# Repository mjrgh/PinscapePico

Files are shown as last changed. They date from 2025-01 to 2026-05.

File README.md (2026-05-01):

# 

Pinscape Pico is a comprehensive I/O controller for virtual pinball
cabinets, designed for the Raspberry Pi Pico RP2040.  It handles
nearly all of the common input and output functions in a virtual pin
cab: arcade-style pushbuttons and switches, accelerometer-based
nudging, mechanical plunger position sensing, and feedback effect
devices such as lights, shaker motors, fans, and solenoids.  It can be
used on a standalone Pico, and also with a wide range of peripheral
devices that expand the Pico's hardware capabilities: accelerometers,
PWM/LED driver chips, shift registers, GPIO expanders, ADCs, and
clock/calendar chips.  The project includes reference hardware designs for
several expansion boards that implement particular collections of
peripherals selected to meet the needs of most pin cab builders, and
all of the hardware interfaces are documented, so that you can design
your own custom boards if you prefer.

This project is a sequel to the original [Pinscape KL25Z controller](https://github.com/mjrgh/Pinscape_Controller),
but it's all new code, not a port of the KL25Z software.  The Pico is
a more powerful platform than the KL25Z, so I wanted to make a fresh
start to take advantage of the Pico's expanded capabilities.  Pinscape
Pico has all (I'm pretty sure) of the features of the original KL25Z
Pinscape, plus some neat new tricks.  It's a little more "technical"
than the KL25Z system, but also more powerful and flexible.

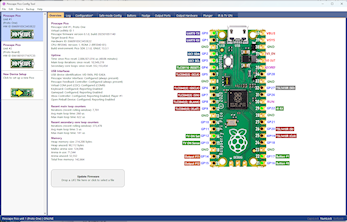
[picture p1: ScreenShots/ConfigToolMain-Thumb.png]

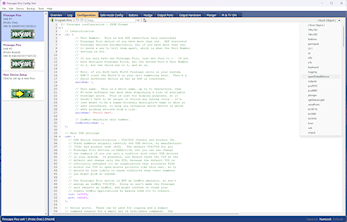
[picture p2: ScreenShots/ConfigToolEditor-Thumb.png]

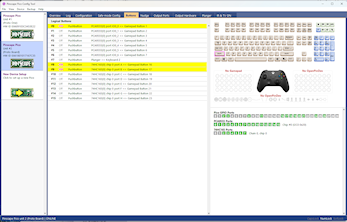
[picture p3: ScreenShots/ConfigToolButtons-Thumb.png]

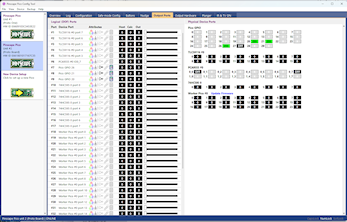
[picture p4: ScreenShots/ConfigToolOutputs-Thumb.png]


## What can you do with it?

Here are some examples of how you can set up a Pinscape Pico system.
There's a more comprehensive list of features a little later in this
article, but it might help to start with some more concrete examples
of what your overall system might look like.

* <b>Button controller:</b> A really simple way to use Pinscape is as
a button encoder, for connecting arcade pushbuttons to a PC.  The
Pico is the only piece of hardware you need for this (other than
the buttons), since you can connect the buttons directly to the Pico's
GPIO ports.  The Pico has a total of 26 external GPIO pins, so you can
connect up to 26 buttons.  Each button can be mapped to the PC as a
keyboard key, a gamepad button, or a variety of other options, and
the Pico responds to button presses within microseconds, for very small
latencies sending input to the PC.  (Pinscape can also handle many
more buttons than just 26 if you need more, but that gets a little
more complicated, because you have to add some external peripheral
chips to create more ports beyond the Pico's 26 built-in GPIO pins.)

* <b>Accelerometer-based nudge device:</b> A slightly more complex
setup adds an accelerometer, to detect when you nudge the cabinet, so
that the pinball simulator can apply the nudge force within the game.
Analog nudging adds a wonderful extra dimension to video pinball that
lets you interact with the game in a much more natural, physical way.
The Pico doesn't have a built-in accelerometer, so this setup
requires adding an external accelerometer.  But that's very easy
to do, thanks to breakout boards available from Adafruit, Sparkfun,
and others.  (A breakout board is a small circuit board with a
specific chip and all of the necessary supporting parts, fully
soldered and assembled, so all you need to do to connect it to a
Pico is run a few wires between the breakout board and the Pico
GPIO pins.)  I recommend the Adafruit MMA8451Q and LIS3DH boards
(MMA8451Q is the better choice in terms of sensor performance).
You can combine nudge input with button inputs, too, although this
will reduce the number of button ports to 24 (because the
accelerometer requires two GPIO ports for its own use).

* <b>Plunger:</b> You can also add a mechanical plunger position
sensor.  Apart from the plunger sensor itself, no other hardware
is needed.  The simplest plunger sensor type is a slide potentiometer,
which connects to the Pico with three wires.  You can combine this
with the accelerometer and button functions as well.

* <b>Feedback device controller:</b> Pinscape can act as a replacement
for the LedWiz and its competitors - devices that control a fixed set
of feedback devices, and do nothing else.  Pinscape can even emulate
the original LedWiz USB interface, if you want it to, which makes it
plug-and-play compatible with old LedWiz-based software.  To control
feedback devices, though, you need to add some custom external
hardware, because the Pico by itself can only control tiny amounts of
power, just enough for a small LED.  So you need "booster" (amplifier)
circuitry to control motors, solenoids, and bigger lights.  Pinscape
is flexible enough to work with a wide range of booster circuits, so
you can roll your own if you want, but you don't have to.  The
Pinscape Pico project includes several "reference" expansion board
designs, which are open-source circuit board layouts that anyone is
free to build on their own, or to customize to fit specific
requirements.

* <b>Comprehensive I/O controller:</b> The reference expansion boards
don't *just* control feedback devices.  They're designed as **all-in-one**
boards that handle just about everything you'd need in a full-featured pin
cab, including accelerometer, plunger, buttons, and feedback devices.
So you can combine the features of a button encoder, nudge device, and
feedback controller into a single Pico running Pinscape.

## Quick setup guide

A pre-built Windows installation is available on the github project page,
under the **Releases** section in the right panel.

The distribution is a ZIP file.  To install, just unpack the ZIP file
into a local directory on your hard disk.  Just about any folder
location will work, except that you should avoid any of the Windows
system folders and the C:\Program Files tree, since those folders
are protected.

Once you unpack the files, you can launch the Pinscape Pico GUI Config
Tool by double-clicking **GUIConfigTool.exe**.  That's designed to be
your main gateway to the system, and it'll display on-screen
instructions for setting up a new Pico with the Pinscape software.

More setup details can be found [below](#SetupDetails).

## Supported Pico versions

All of my development testing was done with a Raspberry Pi Pico RP2040
board.  There are numerous clones of the Pico available from different
vendors, but I haven't tested on any of those, so use those at your
own risk.  I don't mean to imply that other boards *won't* work, only
that I don't know one way or the other, since the only thing I've
actually tested against is the original Pico.  (There is one specific
problem that several people using unspecified clones have reported,
which is that saving configuration data to flash doesn't work on those
devices.  Since I've heard the same thing from a few people, it seems
to be a systematic problem with certain clones, but I don't know
specifically which devices are affected, since the clones are mostly
unbranded.  I don't know the cause of the problem, so if you run into
something like that with a clone, the only solution I can offer is to
switch to a genuine Raspberry Pi device.)

The release package also includes a build for the Raspberry Pi Pico2
RP2350.  The Pico 2 is a next-generation Pico with a new CPU, more
memory, and numerous upgrades to the on-board peripherals.  It looks
just like an original Pico, but it's really a whole new platform, and
it's not directly compatible - it requires a separate build.  Pinscape
support on Pico 2 is still experimental: I haven't tested it on the
Pico 2 beyond the basics, so there are probably some incompatibilities
yet to be found.  But reports so far have been that most features are
working as expected.  Note that there's no particular advantage to
running Pinscape on a Pico 2 over an original Pico, since the software
doesn't currently use any of the Pico 2's new features.

The Pico "W" variations (Pico W and Pico 2W) are **not supported** at
the moment.  The W's have somewhat different internal wiring to accommodate
the addition of the radio modules, and those wiring changes require some
corresponding software changes, which Pinscape doesn't provide.  Some
people have reported that Pinscape *mostly* works on the W; the only
problem reported so far is that the on-board LED doesn't work.  So you
can use a W if you can live with the LED not working, and with any
other problems that might still be lurking.  But I don't see any
reason you'd want to, because Pinscape can't take any advantage of
the W's wireless features.  You're better off using a regular Pico
for Pinscape, and saving the Pico W for an application that actually
uses the WiFi or Bluetooth features.

## Features

* USB keyboard emulation, for button input mapping

* USB gamepad emulation, for button inputs, accelerometer, and plunger

* XBox controller emulation ("XInput"), as an alternative to the HID gamepad
(and the controller's feedback features (LEDs and rumble motors) can be mapped to
output ports via the "computed output" feature)

* [Open Pinball Device](http://mjrnet.org/pinscape/OpenPinballDevice/OpenPinballDeviceHID.htm) support

* All input devices (keyboard, gamepad, XBox, Open Pinball Device) are optional, they can be mixed
and matched in any combination, and and all of their virtual controls (buttons,
joystick axes) can be individually mapped to whichever physical inputs you like
(physical buttons, accelerometer axes, plunger sensor)

* Support for PWM outputs directly through Pico GPIO ports, as well as
multiple external PWM output controller chips (TLC5940, TLC5947, TLC59116,
PCA9685), and even shift-register chips (74HC595)

* Gamma correction option for PWM output ports, with the gamma
calculated at the device's full resolution (e.g., 12-bit gamma scaling for
TLC5940, TLC5947, and PCA9685)

* Configurable "flipper logic" timer protection (in software) for all output ports

* Support for shift register output ports via 74HC595, which can be configured
as digital ON/OFF outputs or as PWM outputs

* Support for digital ON/OFF output ports via PCA9555 GPIO expander chips

* A companion project, "PWMWorker", turns additional Picos into 24-port
I2C PWM controllers, the equivalent of 1&half; TLC59116 or PCA9685
chips, but in the DIY-friendly Pico package, and at the DIY-friendly
Pico price point.  Add more PWM ports to your system, 24
at a time, without any SMD soldering.  
Details: [Data Sheet](http://mjrnet.org/pinscape/PWMWorker/DataSheet/PWMWorkerDataSheet.htm); [Project subtree](PWMWorker).

* Support for button inputs directly through Pico GPIO ports, as well as through
74HC165 shift registers and PCA9555 GPIO expanders

* Extremely low latency on GPIO and 74HC165 input ports (microseconds on the
device side, 1-2 milliseconds end-to-end delivery to the application through USB)

* Ports on PCA9555 chips can be individually assigned as button inputs ports and
feedback device output ports, freely mixing port types on the same chip

* An extensible design for all of the external hardware interfaces, to allow
new chips to be added in the future

* "Logical button" design that allows mapping multiple types of physical inputs to
multiple types of PC inputs and other actions, including keyboard keys, gamepad buttons,
IR remote control code transmissions, and internal actions such as engaging Night Mode
or firing an output port

* Button macros, to carry out a timed series of actions when a button (physical or logical) is pressed

* "Shift buttons", to allow mapping multiple functions to a single physical input; multiple
shift buttons can be defined, to allow for shift "chords" (analogous to PC key combinations like Shift+Ctrl+X)

* Short-press/long-press buttons, to map two functions to one button based on press time

* Native DOF support, via Pinscape Pico device recognition in DOF (present in unified R3++ DOF releases since late 2024)

* "Logical output port" design that allows mapping physical outputs to DOF ports, internal sources,
and "computed" sources that let you combine DOF ports, control multiple things with one DOF port,
control ports based on timed events or internal device events, and all sorts of other things

* Shared DOF output ports, for sharing a small number of physical feedback devices with a
larger set of virtual DOF ports, ideal for setting up a mini-cab with limited space

* Night Mode, to disable designated outputs as a group for quieter play

* Time-of-day features, and support for an external real-time clock (RTC) chip to keep time
while the power is off

* [LedWiz emulation](LedWizEmulationOptions.md), for legacy applications that access the LedWiz directly (rather than through DOF);

* IR remote control receiver/transmitter, with the full universal-learning-remote design from the KL25Z Pinscape

* The "TV ON" feature from the KL25Z Pinscape, with support for the same type of external power-sensing circuit,
and the same support for a TV Relay and IR command activation when a power-on transition occurs

* Plunger sensor support for all of the KL25Z Pinscape sensors, with the same plunger logic features

* Nudging, with support for multiple accelerometer chips (MMA8451Q, LIS3DH, LIS3DSH, MXC6655XA, MC3416),
with an extensible design to allow support for more accelerometer chips to be added in the future

* Nudge Velocity input support for the latest Visual Pinball

* Plunger and accelerometer inputs can be mapped to any suitable gamepad axes, and can also be used
as inputs to logical buttons and logical output ports; for example, you can set up a button that
triggers when the accelerometer X axis exceeds a given threshold, or set up an LED that turns on
when the plunger is pulled

* Plunger Velocity input support for the latest Visual Pinball

* Extremely flexible configuration system, with practically all of the
hardware setup under user control, using the human-friendly JSON text file format

* Detailed error/status logging, viewable on the PC via UART (physical serial port), USB CDC (virtual COM port),
and the Config Tool, for easier troubleshooting

* A simple command console, accessible through UART and USB CDC ports, with access to internal
debugging and troubleshooting commands; mostly a debugging tool for developers, but possibly useful
for troubleshooting problems that don't easily yield to other means

* GUI configuration and testing tool, with detailed visualizations of hardware
and software status for button inputs, feedback device outputs, plunger sensor, and IR features

### Non-features (things Pinscape Pico doesn't do)

Pinscape Pico is billed as a "comprehensive" I/O controller for
virtual pinball cabinets, but there are a few I/O functions that
Pinscape doesn't handle.  In each case, the decision to omit them was
based primarily on the resource limits of the Pico: there would be too
many compromises trying to make a single Pico perform all of its
Pinscape duties *plus* these other tasks.  Fortunately, all of these
functions are already covered by other open-source projects that run
on similarly inexpensive hardware, so leaving them out of Pinscape
shouldn't be an obstacle to including them in a DIY pin cab.

* **No smart light strips:** Pinscape doesn't control smart light
strips - the kind with individually addressable RGB LEDs, such as
WS2812B strips.  The resource limit that makes this impractical to
include in Pinscape is the Pico's relatively small number of GPIO
ports.  For a typical pin cab light strip setup, you'd need four to
eight GPIO ports dedicated to the light strips.  Pinscape needs almost
all of the GPIO ports to itself as it is.

* **No Dot-Matrix Displays (DMDs):** Pinscape also doesn't control the
128x32 dot-matrix display panels found in 1990s pinball machines, and
still popular in virtual pinball cabinets.  The main reason to
dedicate a separate controller to the DMD is that it requires a lot of
USB bandwidth, since the DMD is essentially a small video display.  A
separate device with its own USB port is the simplest way to ensure
plenty of bandwidth for everyone.

## Documentation

The documentation is a little thin so far, since I haven't yet updated
the [Pinscape Build Guide](http://mjrnet.org/pinscape/BuildGuideV2/BuildGuide.php)
to cover the Pico system.  A lot of the general pin cab material in the Build
Guide still applies equally well to Pinscape Pico, since most of it isn't at all
tied to the KL25Z or the original Pinscape software.  But the Build Guide also
has a lot of material that's specifically about how to build and set up the
original Pinscape KL25Z system, and so far I haven't written anything equivalent
for the new Pico software.

Here's what's I do have:

<b>[JSON Configuration Reference](http://mjrnet.org/pinscape/PinscapePico/Help/JSONConfigRef.html):</b>
This has the most comprehensive documentation on the firmware's
workings currently available.  It's in reference format, so it's
not a very good tutorial, but each of the major features has an
introductory section that explains how it works, including wiring
guides for most of the supported peripheral hardware devices.
    
When you're using the configuration editor in the Config Tool, the
editor keeps track of your editing location, and can take you straight
to the reference section on the topic you're currently editing.
At the upper right corner of the editor window, there's a link showing
the current JSON element, which automatically updates to match the
JSON at the text cursor position.  Click the link to open the
reference section for the current JSON element.

<b>[Config Tool help](http://mjrnet.org/pinscape/PinscapePico/Help/ConfigTool.htm):</b>  This documents the Config Tool in detail.
It's built into the Config Tool UI, and is also available online.

<b>[LIS3DH setup guide](Guides/LIS3DH-Setup.md):</b>  A tutorial guide
to setting up a LIS3DH accelerometer with a standalone Pico.  This will
probably be the most common initial setup for people who don't need the
Expansion Boards, so I wrote this guide to help get started.

## LED Status Codes

The Pico has a small green LED on top, which the Pinscape software uses
as a very coarse status indicator.  When everything is running properly,
the LED flashes slowly, about one second on and one second off.  When
the USB connection is interrupted, such as when the host PC is in sleep
mode, the LED shows a very short flash about every two seconds.  If the
LED isn't flashing at all (either stuck on or stuck off), the software
isn't working properly.

<b>Expansion board RGB:</b> If you're using one of the Expansion
Board designs, the board features a full-color RGB LED, which the
software uses to display a slightly more detailed status indication:

* Slow alternating Blue/Green: connected, running properly, plunger sensor calibrated (or no plunger configured)

* Slow alternating Green/Yellow: connected, running properly, plunger sensor not yet calibrated

* Two short yellow flashes every two seconds: waiting for host PC to establish the USB connection

* Two short red flashes every two seconds: USB connection interrupted (cable disconnected or data/protocol error communicating with the PC)

* One short green flash every two seconds: host PC is in sleep mode

* Blue on/off every half second: TV ON countdown in progress after system powered on

* Fast Blue flashes: TV ON feature is transmitting IR commands

* Fast alternating Red/Orange: Safe Mode is in effect

* Slow alternating Green/Dim Green: Factory Reset mode is in effect

* Solid Blue: Plunger calibration is in progress

* Fast Blue flashes: Plunger calibration button is being pressed (keep holding to activate calibration)

* Solid Violet: Nudge noise level calibration is in progress

## More details on installation

### Initial Pico firmware installation

The Pinscape Pico Config Tool guides you through the initial setup process for a new
device.  Just run the program and follow the on-screen instructions under the "New
Device Setup" section.

If you prefer to carry out the steps manually, without the Config Tool involved,
you can also use the standard, native Boot Loader procedure you'd use with any Pico
software:

* Unplug your Pico from USB (and all other power sources)

* Press **and hold** the button on top of the Pico while plugging it in, then release the button

* You should see the Pico appear on your Windows desktop as a virtual thumb drive

* Drag and drop **PinscapePico-pico.uf2** from the Pinscape folder onto the Pico virtual disk
(or use a COPY command in a DOS box)

The Pico should now automatically reboot into the Pinscape software.  If the
software is working properly, the little green LED on top of the Pico will
blink at about 1 Hz, and the device should appear as a Pinscape Pico unit
in the Config Tool.

After the initial install, you can install firmware updates directly
through the Config Tool without all of the manual steps.

### Configuration

This project's configuration setup is rather different from the KL25Z
Pinscape setup.  Instead of a graphical config tool, Pinscape Pico
uses a text file written in the widely-used JSON format.

The JSON file format and contents are documented in the Config Tool
help.  The Config Tool features an integrated text editor (based on
Scintilla) with JSON syntax-aware coloring and indenting, and
quick linking from the current editing location (based on live
syntax scanning) to the relevant documentation.

When you first fire up the GUI Config Tool and go to the Main
Configuration view, the program will offer a choice of initial
template configurations that you can use as a starting point.
The templates contain many examples of common configuration
elements, commented out, that you can un-comment and edit as
needed to add to your own configuration.

Alternatively, you can also send a config file to the Pico using the
command-line Config Tool, from a DOS box:

`ConfigTool --put-config MyConfig.json --reset`

Replace `MyConfig.json` with the actual name of your JSON file.  The
`--put-config` part installs your JSON file on the device.  The new
settings don't go into effect until you reboot the device, which is
why we also added `--reset` at the end.

### Firmware updates

You can update the firmware using the same procedure as the initial
install, by forcing the Pico into Boot Loader mode via the BOOTSEL
button and manually copying the new UF2 file.

But there's also an easier way.  Once Pinscape is installed, the
Config Tool can install firmware updates for you with a couple of
mouse clicks, with no need to physically unplug the Pico or fuss with
the BOOTSEL button.

In the GUI config tool, the main Overview window has controls for
updating the firmware.

To update the firmware from a DOS box, use the command-line config tool:

`ConfigTool --update PinscapePico-pico.uf2`

That automatically places the Pico into Boot Loader mode, copies
the specified UF2 file into its flash, and reboots the Pico to
launch the updated firmware.

## Safe Mode

Pinscape uses the Pico's hardware watchdog module to automatically
detect most software crashes.  The watchdog is essentially a hardware
timer that performs a power-cycle reboot on the Pico if the software
ever stops responding for more than a fraction of a second.  This is
an excellent way to detect software crashes, freezes, and other
problems that make the software stop functioning correctly, and in
most cases, it prevents the Pico from ever getting into a truly
unresponsive state.

When the hardware watchdog detects a crash, it reboots Pinscape into
Safe Mode.  Safe Mode runs the normal Pinscape firmware, but it
bypasses the usual JSON configuration file, and instead uses a
stripped-down configuration with a minimal number of features enabled.
The idea is that most crashes are caused by specific features in the
software, rather than by the core system software, so disabling most
of the optional features will allow the basic core software to run
without problems.

When Safe Mode is active, the Config Tool can connect to the Pico, and
you can inspect and edit the JSON configuration file.  You can also
use Safe Mode to install new firmware, if you're aware of a newer
firmware version that contains a fix for the crash.

If you suspect that the crash that led to Safe Mode activation was due
to a particular feature, you can use Safe Mode to edit the
configuration file and disable the suspect feature.  If you think it
was due to a setting, but you're not sure which one, you can
experiment with disabling features until you find the one responsible.

If you think the crash was purely random or sporadic, you can just
reboot the Pico and try again.  If the Pico keeps going back into Safe
Mode after each reboot, you probably will need to disable something in
the configuration to get back to normal operation.

By default, Safe Mode uses default "factory" settings for everything.
You can optionally create your own Safe Mode configuration file via
the Config Tool, in the Safe Mode Config window.  This works exactly
like the regular JSON configuration; it's just a separate JSON file
that's loaded instead of the regular one when Safe Mode is triggered.
The Safe Mode config file lets you enable specific features even when
in Safe Mode.  Naturally, you should minimize the features you enable
here, since the whole point is to create a minimal configuration that's
less likely to crash specifically because it doesn't enable many features.
I like to configure the ID information here to match the main configuration,
and also enable the UART ports, so that I can access the command console
for troubleshooting even when Safe Mode is active.

## Recovering a bricked Pico

First, you can't actually "brick" a Pico, in the sense of rendering it
permanently unrecoverable due to a software error.  But the Pinscape
software certainly can crash, and it can crash at startup, such that
it won't connect to the Config Tool long enough to let you perform an
update.  So the Pico might *appear* to be bricked.  Even this is
unlikely, because the Pico will automatically detect most crashes
and reboot itself into Safe Mode (see above), giving you access to
basic configuration functions.

In the event that Safe Mode doesn't kick in, it's *still* essentially
impossible to truly brick a Pico, thanks to the Pico's boot loader
being etched into inalterable hardware ROM.  No matter how badly the
software screws up, there's just no physical way that it can break
the ROM.  If the Pinscape software ever makes your Pico appear unresponsive,
you can always restore it to Boot Loader condition as follows:

* Disconnect the Pico from USB (and any other power sources)

* Press **and hold** the BOOTSEL button on top of the Pico while plugging in the USB cable

Holding the BOOTSEL button during a power cycle activates the Pico
boot loader, bypassing any software loaded in flash.  Since it's
impossible to erase the boot loader program itself (as it's stored in
unerasable ROM), and since the BOOTSEL button physically bypasses the
flash during the reset, there's nothing that a firmware program can do
to prevent this assertion of Boot Loader control, even if it were
deliberately trying to.

After you perform the BOOTSEL maneuver, the Pico should appear as a
virtual thumb drive on your Windows desktop.  You can now replace the
flash firmware by dragging the new .UF2 onto the Pico thumb drive.

For most programs, it would be enough at this point to reinstall the
firmware.  However, that's not necessarily good enough with Pinscape,
because Pinscape *also* stores your configuration file in the Pico's
flash memory, in a separate area from the program executable.  You
can fully reset the Pico to factory conditions using the Config
Tool, via the Device menu on the main Overview page, or via the
Boot Loader view, if the device is currently in Boot Loader mode.

## Expansion boards

Pinscape Pico will work on a completely stand-alone Pico, but for
a full virtual pin cab setup, you'll almost certainly want to add
some external peripherals to supplement the Pico's relatively
small complement of GPIO ports, and its lack of an on-board
accelerometer.

As part of the Pinscape Pico project, I've developed a few custom
"expansion boards" purpose-built for virtual pin cabs.  They're
all open-source designs that anyone can build; you can find the
EAGLE layouts in the [ExpansionBoards](ExpansionBoards) folder.

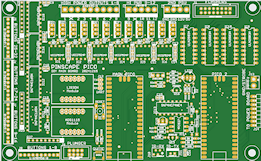
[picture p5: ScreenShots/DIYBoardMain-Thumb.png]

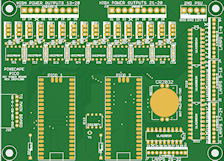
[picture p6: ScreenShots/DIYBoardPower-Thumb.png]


* **DIY-friendly expansion board set:**  A two-board set, designed
  to work together as a unit, providing a complete virtual pin cab
  I/O controller powerful enough for a high-end build with just
  about every toy known.  "DIY-friendly" means that it's designed
  entirely from parts that are easy to source and easy to solder
  by hand - it's meant to be something you can build yourself.

* **"Pro" expansion board:** An all-in-one board with a similar
  set of features to the DIY-friendly set, just with everything
  packed into a single board, thanks to the higher density made possible
  by fine-pitch SMD parts.  I call it the "Pro" board not because
  it's any better than the DIY board, but just because it's not the
  sort of thing most people would *want* to build by hand, thanks
  to the use of small SMD parts.  It's really only practical to assemble
  robotically, and that probably means that it will only be economical
  to produce in moderately large batches, like tens or hundreds or units.
  I expect that this will be an obstacle to DIYers, but one of our
  enterprising community members who's set up for retail sales might
  be able to build them and offer them for sale.  But even so, the
  "pro" isn't for "proprietary" - it's still an open-source design
  that you can build yourself, provided you have the means to work
  with the small SMD parts involved.

* **KL25Z adapter:** An adapter board that makes the Pico mimic
  a KL25Z, for use with the original Pinscape KL25Z expansion boards.
  This is designed for people that already have the KL25Z boards,
  and want to keep using them, but also want to upgrade to the new
  Pico software.  This is designed as a drop-in replacement for the
  KL25Z in your old setup.

But Pinscape Pico isn't limited to *my* expansion board designs.
The software was designed from the ground up to be fully configurable,
and has support for numerous peripheral options.  It doesn't make any
assumptions about which peripheral devices are present.  It'll work
just as well with other people's expansion board designs as with my
board designs.

## How to build the project from source code

[Build Instructions](How-to-build.md)

## Pinscape Pico API for Windows applications

Part of this project is a C++ API for accessing a Pinscape Pico
device from a Windows application.  The API is packaged as a C++
static-link library (.lib) that you can include in any C++ project.
Refer to [WinAPI/README.md](WinAPI/README.md), and the source
files in the WinAPI/ folder.

### USB protocols

The Windows C++ API is built atop a set of documented, structured, and
extensible USB protocols.  You can access the device directly through
its USB protocols in cases where the Windows API isn't suitable, such
as from a Linux host, from another microcontroller, or from a Windows
programming language that can't readily import C++ APIs.  See
[USBProtocol/README.md](USBProtocol/README.md) for details.

## Command Console

The firmware implements a very simplistic command console, which
provides access to some internal debugging and troubleshooting
information.  It was designed for use by the developers, so user
friendliness was not foremost in mind.  However, it might be useful at
times for in-depth troubleshooting, and might be of passing interest
to the curious.

The console must be enabled explicitly, since it requires a serial
connection of some kind, either UART or USB CDC.  Those consume some
resources on the Pico, so they're not enabled by default.  The console
also consumes some additional resources of its own when enabled.  See
the Config Tool help section on the JSON configuration for details on
setting up serial port access and enabling the console.

Once enabled, you can access the console via a terminal program such
as PuTTY.  Connect PuTTY (or another terminal program of your choice)
to the Pico's COM port (real or virtual).  You should be presented
with a command prompt.  Type `help` for a list of commands.  The
console provides simple tab-completion for commands and option flags.

## Background

The original Pinscape software runs on the NXP FRDM-KL25Z, a
microcontroller based on the Arm M0+.  NXP marketed the FRDM-KL25Z as
an "evaluation" board for its MKL25Z CPU, meaning that they hoped
professional engineers would use the board to create quick prototypes
based on the MKL25Z CPU, and then those engineers' employers would buy
thousands of the CPUs to build into the final products that came out
of the prototypes.  So the FRDM-KL25Z was essentially a marketing tool
for CPU chips.  But along the way, they accidentally created a great
microcontroller for virtual pinball.  The board has just about
everything you'd want in a virtual pinball controller: a generous
complement of GPIOs, an excellent MEMS accelerometer on board,
built-in USB, an integrated high-resolution ADC, and on-chip hardware
interfaces for all of the common peripheral interconnects (UART, SPI,
I2C).  And it was quite reasonably priced, at about $15.  The only big
thing it lacked for pin cab use was PWM channels; it only has 10, and a
full pin cab needs upwards of 30.  The KL25Z also can't control
high-power loads directly (solenoids, motors, etc.), but no
microcontroller can; you always need an external MOSFET or relay
circuit for that.

But alas, NXP's last production run of the original KL25Z was around
2018, and most retailers that sold them ran out of inventory around
2021.  This was a huge source of frustration for any pin cab builders
who hoped to use Pinscape in their new builds.  NXP finally produced a
new batch in 2025, but unfortunately, the accelerometer chip was long
out of production by then, and NXP didn't want to redesign the board,
so the new units ship without any accelerometer chips installed.  That
makes them much less interesting for virtual pinball users.  (The Pico
doesn't have an on-board accelerometer either, so this doesn't by
itself put the KL25Z at a disadvantage to the Pico, but it does
eliminate a major advantage the KL25Z had in the past.)

That's what motivated the new project on the Pico.  The Pico is a more
powerful device than the KL25Z, but the big reason I wanted to move to
the Pico is long-term availability.  The Pico is amply available, and
unlike NXP, where the KL25Z was just a sideline to their main business
of selling CPUs, Rasbperry Pi is entirely focused on hobbyist boards
like the Pico.  That's their whole business and primary mission.
Raspberry Pi is actively developing new Pico versions (the Pico 2 came
out in late 2024) has has publicly committed to keeping the Pico in
production for years to come.  What's more, the Pico is even more
affordable than the KL25Z ever was, at only $4 MSRP apiece.

Like the KL25Z, the Pico is based on the Arm M0+ CPU core, but that's
about the only thing that the devices have in common technologically.
Arm's CPUs are designed to be customized by the OEM, so the M0+ from
NXP and the M0+ from Raspberry Pi are quite different, sharing a common
machine code language but not much else.  The Pico's version doesn't use
any of the same on-chip peripherals as the KL25Z.  It does provide many
of the same peripheral *functions* that the KL25Z did, at a conceptual level,
including GPIOs, DMA, ADC, USB, I2C, SPI, and UART, but the concrete
implementations are very different in the details from their
KL25Z counterparts, so code written for one machine needs to be largely
rewritten to run on the other.  The Pico also lacks an accelerometer, which is a
key feature for a pin cab controller.

Because of the differences in capabilities, the Pico requires not only
a whole new software port, but also a whole new external hardware
environment, to fill in the gaps in the Pico's peripherals vs the
KL25Z.  We obviously have to add an accelerometer, but we also have to
compensate for the relatively small number of GPIOs on the Pico relative
to the KL25Z - we can't just wire 20 or 30 button inputs to GPIOs, which
we could get away with on the KL25Z with its 50+ ports.

What the Pico lacks in on-board peripherals, it more than makes up for
in I/O interface support.  The Pico has built-in hardware support for
all of the common bus protocols, plus a novel programmable hardware
subsystem designed to connect to peripherals with I/O interfaces that
are <b>un</b>common, or even unique, with minimal CPU load.  Pinscape
Pico takes much advantage of that special hardware to provide support
for a large number of external peripherals, with extremely flexible
configuration options.  Pinscape offers several different ways to
attach ample sets of button inputs and feedback device outputs, using
only a few GPIO ports; it supports multiple accelerometers, with an
open architecture designed to make it easy to add support for new
types of accelerometers in the future; it supports multiple external
ADCs, to supplement the mediocre on-board ADC; and it supports all of
the original Pinscape KL25Z plunger sensors.

## How Pinscape uses the Pico's flash memory

The standard Pico boards come with 2MB of flash memory built in.  The
flash chip is there primarily for storing the user's firmware program,
and the Pico's designers didn't really make provisions for any other
use.  In particular, they didn't bother putting a "file system" on
the flash; it's just a big unstructured byte array, like an
unformatted disk drive.

It might *look* like the Pico has a FAT file system on the flash,
because the Pico pretends that it's a FAT-formatted thumb drive when
you put the Pico in Boot Loader mode.  But it's a carefully crafted
illusion.  The thumb drive you see isn't actually a window on the
flash memory, but more like a virtual in-memory RAM disk.
Importantly, it can't actually store regular files.  The only thing it
can do is accept a UF2 file, which it parses into a Pico program image
that it installs into the flash memory space.  If you try copying a
regular text file or a Word document or anything else onto the drive,
it won't stick, since the virtual thumb drive's only job is to install
program images from UF2 files.

Even though the flash memory space is so completely raw and
unstructured, the Pico Boot Loader's usage of the space is at least
predictable.  The Boot Loader always installs the program image at the
"bottom" of flash (the lowest memory address), in a contiguous block
equal to the size of the image.  This predictability is what allows
Pinscape to share the flash space with the program image, to store its
own persistent application data.  Pinscape uses a portion of
flash at a safe distance from the bottom section where the program
image goes (all the way at the opposite end, in fact, at the "top" of
the flash space).  Pinscape uses this capability to store your
configuration file and other settings, such as plunger calibration
data.  Since it's not in the part of flash that the boot loader uses,
the configuration data survives firmware updates.

Pinscape imprints its own simple file-system-like layout on this extra
data space, and the command console has some simple tools that let you
view the layout, primarily for development and debugging purposes.
But it's not a real file system by any means; it's just a way for
Pinscape to organize its internal data structures.

## License

Copyright 2024, 2025 Michael J Roberts

Released under a BSD 3-clause license - NO WARRANTY

## Third-party software credits

CRC++, Copyright (c) 2022, Daniel Bahr.  Distributed under a BSD
3-clause license.

M0 Fault Dispatch, by Dmitry.GR \<me@dmitry.gr\>.
Distributed under a free/no-commercial-use license; see firmware/m0FaultDispatch.h
in the source tree for the license text.

Pico C++ SDK, Copyright 2020 by Raspberry Pi (Trading) ltd.
Distributed under a BSD 3-clause license.

Scintlla Edit Control, Copyright 1998-2021 by Neil Hodgson
<neilh@scintilla.org>.  Distributed under a Python-like
license; see Scintilla/License.txt in this source
tree for the full license text.

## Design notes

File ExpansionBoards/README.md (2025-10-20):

# Pinscape Pico Expansion Boards

This folder has EAGLE plans for several circuit board designs that go with
the Pinscape Pico software.  These plans are all open-source designs that
anyone is free to build.

* <b>DIY-Friendly:</b> A comprehensive I/O controller for a virtual pinball
cabinet, with enough button ports and feedback device ports to connect just
about everything in a high-end build.  It uses entirely through-hole parts
that are easy to solder by hand, which is what makes it DIY-friendly.  The
project consists of two boards that are meant to be built and deployed as
a set (since I couldn't fit everything onto a single board, given the amount
of space that the through-hole parts take up).

* <b>Pro:</b> Another comprehensive expansion board, with essentially the
same functionality as the DIY-Friendly board set, but this time using mostly
surface-mount (SMD) parts.  The SMD parts are much smaller than the through-hole
parts used on the DIY board, allowing everything to be packed into a single
board.  The tradeoff is that a lot of the SMD parts used in the design are
difficult to solder by hand, precisely because they're so small.  So this
board is really meant to be assembled by factory equipment.  That's why I
refer to it as the "Pro" board - it's probably only going to be cost-effective
to build if you're going to build at least 50 or 100 units, and if you're
making that many, it's probably because you plan to sell them at a profit.
The designs are open-source, so you're free to do that if you have a retail
shop set up and you're willing to back your sales with warranty and technical
support (since, as they're open source, the designs themselves don't come
with any warranty).

* <b>IR-RX:</b> A small satellite board for the DIY-Friendly or Pro boards
that holds an IR receiver chip, and connects back to the expansion board
with a ribbon cable.  This lets you position an IR receiver anywhere
inside or outside your cabinet, so that it can be in line-of-sight to the
remote controls you want to point at it.

* <b>KL25Z Adapter:</b> This is for people with an existing set of the
original Pinscape KL25Z expansion boards.  The board plugs into the KL25Z
expansion boards where the KL25Z would normally go, letting a Pico take the
place of the KL25Z.  This lets you use your existing expansion boards with
the new Pinscape Pico software, and without having to re-wire your cabinet
for a new expansion board set.  (It doesn't act as a true general-purpose
KL25Z emulator, though, since it's very specifically wired for the original
Pinscape boards.)

* <b>Power Distribution:</b> A simple board designed to help tidy up your
virtual pin cab power supply wiring.  It doesn't do much other than route
power from one connector to another, but the idea is that it makes your
wiring simpler and more structured.  It does have a few active features: it
has a 6.3V regulator for powering #555 lamps (the type commonly used in
arcade pushbuttons); it provides main power switching (through a relay) for
all of the secondary supplies, based on the main PC power on/off status; and
it includes wiring for a coin door safety interlock switch for a
high-voltage (48V) supply, so that the high-voltage power is automatically
cut off whenever you open the coin door to do maintenance work inside the
cabinet.  It also features connectors that match the power connectors on the
DIY-Friendly and Pro expansion boards, again just to make the wiring tidier.
<p>
This board can be used with any I/O controller, not just Pinscape
Pico.  It does include two connectors designed especially to match
the layout of the Pinscape Pico expansion board power inputs, but
other controllers are likely to have similar power input requirements,
so it should be easy to adapt in most cases.
</p>

* <b>Flasher Panel:</b> A board designed to sit behind an RGB LED flasher
panel in a standard-width pin cab, to provide all of the electronics and
wiring to the flashers, including the five high-current (350mA) RGB LEDs.
It uses a 16-wire ribbon cable connector that matches the layout of the
Flasher port on the Pinscape Pico and KL25Z expansion boards, to make the
wiring between the controller and panel very easy and neat.  Like the Power
Distribution board, this one is designed to replace ad hoc wiring to make
your build a little tidier, and it can be used with any I/O controller.

## How to fabricate the boards

See [Fabricating the Expansion Boards](http://mjrnet.org/pinscape/BuildGuideV2/BuildGuide.php?sid=expanFab)
in the [Pinscape Build Guide](http://mjrnet.org/pinscape/BuildGuideV2/BuildGuide.php).
That explains the process in terms of the original KL25Z Pinscape boards, but
it applies equally well to the Pinscape Pico boards - just substitute the EAGLE
files from this repository.

## Bills of Materials (BOMs)

Each circuit board has an accompanying BOM file, in .csv (Comma-Separated
Value) format.  To view these, open them in a spreadsheet program like
Microsoft Excel, Apple Numbers, or Google Sheets.

The reason these are in CSV format rather than plain text is that Mouser and
Digikey will accept them as uploads, to construct a shopping cart without a
lot of manual data entry.  But you should carefully review the results.  For
one thing, the sites aren't always perfect at matching the BOM line items to
their inventory, so check that everything looks plausibly correct before
ordering.  For another, items go out of stock.  Some items might even be out
of production by the time you order, especially if the BOM you're working
from is more than five minutes old, since the manufacturers constantly
change their product lineups.  For out-of-stock or obsolete items, you'll
have to select suitable substitutes.  For generic parts like resistors and
capacitors, substitutes should always be easy to find - just match the Ohms
or "uF" values, and the physical package type and size.  For more complex
parts, such as transistors and IC chips, it can be more difficult to select
substitutes; ask on the forums if you're in doubt, and hopefully someone
with an electronics background can point you in the right direction.

## Copyright and license

The expansion board material is released under the same copyright and
license terms as the rest of the Pinscape Pico project.  Copyright 2025
Michael J Roberts; released under a BSD 3-clause license with NO WARRANTY.

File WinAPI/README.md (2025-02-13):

# Pinscape Pico Windows API

This is a Windows static-link library (.lib) for accessing Pinscape
Pico devices from a Windows application.

The API is organized into two main divisions, which correspond to
the two custom USB interfaces that Pinscape Pico devices expose:

* PinscapeVendorInterface.h defines the API for the device's
  USB Vendor Interface, which provides configuration and control
  functions.  This interface is primarily for use by programs
  like the Config Tool that need to access the device's settings,
  status, and diagnostics.

* FeedbackControllerInterface.h defines the API for the feedback 
  controller interface, which is designed for use by pinball
  simulators and other applications that generate feedback
  effects by operating attached lighting devices, motors,
  solenoids, etc.

Most applications will use one or the other of those interfaces,
according to what they're trying to accomplish.  A tool that performs
configuration functions will generally need the vendor interface, and
simulation software will usually find that the feedback controller
interface has the facilities it needs.

## Documentation and examples

The API documentation, such as it is, is contained in the main
header files listed above.

The StatusLED program (in the StatusLED/ folder off the top-level
project folder) provides a simple example of using the vendor
interface API.

The Config Tool (in the GUIConfigTool/ folder off the top-level
project folder) isn't written as a simplified example, but it
exercises just about all of the vendor interface and feedback
controller API features, so it might at least be useful as a
detailed reference that you can search through for real-world
usage examples of particular API calls.

My fork of the LWCloneU2 project at [https://github.com/mjrgh/lwcloneu2](https://github.com/mjrgh/lwcloneu2)
provides another real-world example of using the feedback controller
API.  See in particular [win32/driver/src/ledwiz.cpp](https://github.com/mjrgh/lwcloneu2/blob/master/win32/driver/src/ledwiz.cpp).

## Underlying USB protocols

The C++ API is a wrapper for the Pinscape Pico's custom USB protocols,
which are documented in the USBProtocol/ folder (under the top-level
project folder).  Everything the C++ API does can also be accomplished
with direct USB operations.  The C++ API just makes things a lot easier
by managing the low-level USB details.

## Windows target SDK version

The API library is set by default to build for the Windows 10 SDK
(PinscapePicoAPI project > Properties > General > Windows SDK Version).

Compiling against the Windows 10 SDK will make the resulting program
work only on Windows 10 and later, of course.  If you need to create
an .exe that will run on older systems, you can change to an earlier
SDK.  The project compiles with the SDK set to 8.1, but I haven't
tested against anything earlier than that.  Note that changing to 8.1
or earlier disables the Pico high-precision clock synchronization
APIs, since they depend upon WinUsb functions added in Windows 10.
The only reason you'd need the clock sync functions is for a program
like Button Latency Tester 2 that measure the relative time between
events on the Pico and the PC.

## How to include in a project

The API library is designed to be linked into a C++ project as a
static-link library (.lib).  A Microsoft Visual Studio project
file (.vcxproj) is provided for building the static library, which
you can then link into your project.

You'll need the library's header files as well as the .lib, so my
recommendation is to include a copy of the whole library project in
your Visual Studio "Solution".  That lets Visual Studio build the
library from source as an automatic step in your overall project
build.  To do this, you can simply make a snapshot of the whole
Pinscape Pico source tree in a subfolder within your project's source
tree.  Or, if you want to minimize the number of files in your
snapshot, you can snapshot just the following two sub-folders (and all
of their contents):

```
PinscapePico/
  USBProtocol/
  WinAPI/
```

If it bothers you to incorporate files from another repository as a
static snapshot (for example, because you don't like the idea of
having to manually update the snapshot to keep up with changes to the
original source tree), git provides several mechanisms for including
live links to other repositories, such as subprojects, submodules,
and subtrees.  It won't matter to the build whether you use a static
snapshot or one of the git reference schemes, as long as you have
a snapshot of the library tree somewhere in your local project tree
when you run the Visual Studio build.

If your project already includes other third-party libraries, add the
PinscapePico folder as a peer of those other third-party library
folders.  Otherwise, you can add it as a subfolder of your main
source folder.

A typical project tree involving multiple third-party libraries might
look something like this:

```
project/
  src/                - contains all of my own project's C++ source files
  include/            - all of my own project's header files
  third-party/        - third-party libraries main folder
    PinscapePico/     - Pinscape Pico third-party library
```

In this case, you'd need to set your C++ compiler's include file path to 
include the third-party/ folder in every #include \<xxx\> search.

Now open your project in Visual Studio, right-click on the main Solution
item in the Solution Explorer panel, and select Add > Existing Project.
Select PinscapePico/WinAPI/PinscapePicoAPI.vcxproj.

Right click the new PinscapePicoAPI project in your Solution Explorer
panel and select Properties.  Static link libraries require a few compiler
options to be set the same way between the library and the main project
that includes it, so check the following items, and change them to match
your main project settings as needed:

* Advanced > Character Set

* C/C++ > Code Generation > Runtime Library

Close the properties dialog when done.

On the main manu, select Project > Project Dependencies.  In the dialog,
open the Projects drop list and select your main project.  Tick the 
PinscapePicoAPI box to specify that your project depends on the
PinscapePicoAPI project as a client.

In each of your project files where you'll call Pinscape Pico API
functions, add a #include for the appropriate API header:

```
#include <PinscapePico/WinAPI/PinscapeVendorInterface.h>
#include <PinscapePico/WinAPI/FeedbackControllerInterface.h>
```

Note that most projects will only use one or the other API division,
so you'll usually only need to include one of these files.

In one of your source files, also add the following #pragma:

```
#pragma comment(lib, "PinscapePicoAPI.lib")
```

That instructs the linker to include the PinscapePicoAPI.lib static
link library file.

In order to make the link work properly, you'll also have to add
the following to your project properties, in the **VC++ Directories**
page, under **General > Library Directories**:

```
$(SolutionDir)$(Platform)\$(Configuration);<existing options>
```

(The `<existing options>` part is meant to represent whatever was
already in that box.  In other words, insert the new material
before whatever's currently there.)

You should now be able to call the Pinscape Pico API functions
from your project source files.  To test it out, try adding this
snippet of code somewhere suitable:

```
std::list<PinscapePico::FeedbackControllerInterface::Desc> picos;
if (SUCCEEDED(PinscapePico::FeedbackControllerInterface::Enumerate(picos)))
   OutputDebugStringA("It worked!\n");
```

Now try building your project to make sure that the compiler and linker
options are set up to find all of the library files properly.  If that
works, you can use the Visual Studio debugger to step through the code above
to make sure that the API call works.  If you have any Pinscape Pico units 
attached to your system, the std::list should come back populated with a 
descriptor object for each connected unit.  You can look at the descriptor 
object properties in the debugger to see its various identifiers.

## License

Copyright 2024, 2025 Michael J Roberts

Released under a BSD 3-clause license - NO WARRANTY

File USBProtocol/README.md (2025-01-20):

# Pinscape Pico - USB Protocols

This folder contains C++ header files that define the Pinscape Pico's
custom USB protocols.  The headers are meant to serve both as
documentation for the wire interfaces, and as a basis for C++
implementations of the host and device sides of the protocol.  They
define structs, types, and constants useful for implementing the
protocols, and are extensively commented with narrative descriptions
of the workings of the protocols.  These serve as the specification
and "source of truth" for how the protocols are meant to work.

The headers are designed to be compatible with Microsoft Visual C++ on
the host and the ARM gcc cross-compiler for the device, so that the
same headers can be used in both sides of the implementation.

## FeedbackControllerProtocol.h

This defines the protocol used for Pinscape Pico's "Feedback
Controller" HID device.  The Feedback Controller is a special-purpose
HID device that lets the host send commands to the device to control
feedback ports (for example, activating lights or motors attached to
the device) and access other device functions useful during simulated
pinball game play.

This interface is designed especially for access from DOF, but it's
open to any other programs that want to access it directly, using the
protocol defined in this file.

The Feedback Controller is implemented as a HID device, which makes it
plug-and-play, with no device driver installation required, since it's
accessible through the built-in HID drivers on Windows and virtually
all other modern operating systems.  HID interfaces also have the
nice property that they can be accessed simultaneously from multiple
host processes, with no need for different programs to coordinate
their access with one another.

## VendorIfcProtocol.h

This is the protocol that Pinscape Pico's private "Vendor Interface"
uses.  On Windows, the vendor interface can be accessed via the
WinUsb device driver.  WinUsb is a built-in component on all Windows
versions from Vista onward, so this is a plug-and-play interface that
doesn't require any user action to install device drivers.  (The
exception is Windows XP, where WinUsb is available, but must be
manually installed.)  On Linux and MacOS, the same USB interface is
accessible via the open-source libusb system.  

The vendor interface is the primary access point for the Pinscape Pico
Config Tools.  It provides access to configuration, control, and
status functions, such as installing a configuration file, starting
plunger calibration, reading diagnostic logging information, and
running diagnostic tests.

## C++ API for client access

On Windows, we provide a separate, high-level C++ API for accessing
both of these interfaces from client programs, under the WinAPI/ folder.

The API library makes it much easier to use the protocol interfaces
than it would be to code directly to the operating system USB APIs.
The API library manages the details of the USB connections, and
exposes most of the functionality available through the protocols in
the form of C++ function calls that correspond to the high-level
operations.  The protocol definition headers defined here are mainly
for use by programs that can't use the C++ API and instead need to
access the protocols directly at the USB level.

Note that some of the functions provided in the C++ API, particularly
those related to device discovery and connection setup, are details of
the operating system's USB interface that are outside of the scope of
the protocol itself.  The header files defined here don't have any
documentation at that level.  So even if you're planning to write a
program based directly on the USB protocols, you might still find it
useful to review the C++ API code for examples of how to use the
Windows USB APIs to discover the devices and interfaces, establish
connections, and transfer data on the connections.  That might be a
useful reference even if you're working on another operating system,
since the basic structure of host-side USB access is similar across
all systems.

## License

Copyright 2024, 2025 Michael J Roberts

Released under a BSD 3-clause license - NO WARRANTY

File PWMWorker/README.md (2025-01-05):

# PWMWorker

This is a sub-project of Pinscape Pico that turns any Pico into a 24-channel
PWM controller with an I2C bus interface.  It's designed to serve as a
substitute for a dedicated PWM controller IC chip like TLC5940, TLC59116,
or PCA9685.

The main reason to use a Pico instead of one of the dedicated chips is
that the Pico is easy to work with in a DIY project, whereas all of
the dedicated PWM chips currently in production are only available in
fine-pitch SMD packages.  A Pico is as easy to solder to a circuit
board as a traditional through-hole chip, and you can even use it in a
completely solderless setup, connecting wires to its standard 0.1" pin
headers.  The Pico has a few secondary advantages over the dedicated
chips as well: it's inexpensive, readily available, and has some
high-level features that go beyond basic PWM output control, such as
integrated high-resolution gamma correction, configurable PWM
frequency over a very wide range (8 Hz to 65535 Hz), and direct
device-side support for Pinscape's "Flipper Logic" timer system (which
protects high-current devices by shutting down ports that the host
leaves stuck on for too long at a time).

Even though PWMWorker is nominally part of the Pinscape Pico project,
it's readily usable with essentially any microcontroller host, running
any software, that has support for a 3.3V I2C bus.  A Pico running
PWMWorker presents itself on the I2C bus the same way any other PWM
controller chip would, with a set of register locations that the host
can write to, to configure the output ports and set their PWM levels.
The register interface is very similar in style to that used by most
of the dedicated PWM controller chips, which was done deliberately
to make it easy to adapt existing microcontroller software that can
talk to any of those other chips to also talk to a PWMWorker.  PWMWorker
doesn't emulate any of those other chips, so it's not a drop-in replacement
for any of them, but its I2C register interface is so similar in design
that it should be light work to adapt an existing TLC59116 or PCA9685
driver to work with this device instead.

## Documentation

Documentation is provided in the form of a "data sheet", in keeping
with the conceit that this is a virtual "chip" in the PWM Controller
category.  The data sheet documents the I2C register interface and
circuit wiring details, and provides several examples of how to
connect output devices.
 
[PWMWorker Data Sheet](http://mjrnet.org/pinscape/PWMWorker/DataSheet/PWMWorkerDataSheet.htm)

## Build and install

PWMWorker is a stand-alone Pico C++ SDK project.  Refer to the main Pinscape Pico
build instructions, and do the same thing you'd do there, but working in this
directory.

The resulting .UF2 file can then be installed onto a Pico in the
standard way, by entering the Pico's Boot Loader mode (by power cycling
or resetting the Pico while holding down the BOOTSEL button on top of
the Pico) and then copying the .UF2 file onto the virtual USB thumb
drive that the Pico presents.

Once installed, the Pico acts like an I2C chip.  The physical I2C bus connection
is through the Pico's GP26 (SDA) and GP27 (SCL).  **No USB connection is required**,
since the Pico communicates with the microcontroller host purely through I2C,
but the USB port can be used to supply the Pico with power if desired.
Alternatively, the Pico can be powered by supplying 5V to the VSYS pin,
with a low-voltage-drop diode to protect against power back-flow when
the USB cable is connected.  See the Data Sheet for details.

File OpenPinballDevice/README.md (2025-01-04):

# Open Pinball Device HID

This repository contains:

* The Open Pinball Device HID specification
* C++ and C# libraries to support writing host-side applications that connect to USB devices implementing the OPD HID interface
* Example projects demonstrating how to use the libraries

## Specification

[OpenPinballDeviceHID.htm](OpenPinballDeviceHID.htm)

The Open Pinball Device HID interface defines a HID interface that
virtual pinball cabinet I/O controllers can implement to provide a
well-defined way to send sensor input to host applications.  It's
particularly designed for use by pinball simulators such as Visual
Pinball.  The interface is documented and published in the hope that
most current and future pinball simulators and pin cab I/O controllers
will adopt it, with the aim of improving compatibility between devices
and simulators and minimizing manual user configuration work.

## Libraries

OpenPinballDeviceLib/ contains a C++ statically linked library for
accessing devices that implement the Open Pinball Device HID
interface.  System-level USB access is handled through a third-party,
open-source library, [hidapi](https://github.com/libusb/hidapi), which
provides portable HID access across many platforms, including Windows,
Linux, and MacOS.  Project files are provided for Microsoft Visual
Studio on Windows.  The code is written in portable C++ with no direct
dependencies on any OS APIs, so it should be readily portable to other
platforms where hidapi is available, but build scripts are currently
only provided for Visual Studio on Windows.

OpenPinballDeviceDotNet/ is a C# version of the library, to provide
the same access to .NET applications.  The Visual Studio solution 
includes a simple C# demo program.  C# libraries can generally be
used easily in other .NET languages, such as VB.NET.

## Sample Application

OpenPinballDeviceViewer/ is a Windows GUI program that shows a list of
Open Pinball Device units currently connected, and displays live input
from a device.  It's designed to serve as the OPD equivalent of the
Windows "Set up USB Devices" control panel (joy.cpl), which lets you
view live input from a joystick or gamepad to check if it's working
properly.  The device viewer application provides a similar display
showing the accelerometer, plunger, and button inputs from an OPD
unit.

## License

Copyright 2024, 2025 Michael J Roberts

Released under a BSD-3-Clause license - NO WARRANTY

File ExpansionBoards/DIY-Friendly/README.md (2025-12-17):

# Pinscape Pico - DIY-Friendly Expansion Board

This is an EAGLE design for a two-board expansion set for the Pinscape
Pico software.  Pinscape Pico is firmware for the Raspberry Pi Pico
that turns a Pico into a highly customizable I/O controller for
virtual pinball cabinets.

## Description

This board set is my second Pinscape Pico expansion board design.  The
first is an All-In-One board that packs everything you need for a
well-equipped pin cab onto one 10x16 cm board.  To achieve that kind
of density, that design uses tiny SMD (surface-mount) parts for just
about everything, some of which are too small even to handle with
tweezers.  It's not something you want to assemble by hand, unless
your other hobby is building Swiss watches from scratch; it's really
only feasible to build in a factory with a pick-and-place machine.
That's only cost-effective if you're going to order at least 50 or 100
units, so I expect that the all-SMD board will only be of interest to
our more entrepreneurially-minded community membe who might be
willing to order up a batch and offer them for retail sale.  That's
why I've taken to referring to that design as the "Pro" expansion
board.

But Pinscape has always been for DIYers.  My mission from the start
has been to make it possible to build high-end pin cabs without
depending on commercial devices, since we're such a niche hobby that
it's hard to get most commercial vendors to take us seriously as
customers.  So I didn't like the idea of only having a "Pro" design; I
also wanted to provide a DIY-friendly design that works with the new
software.  That meant designing another board using only parts that
are easy to solder by hand.

The result is this two-board expansion set.  It outfits the Pico with
a large set of physical input and output connections that let you
connect just about everything you'd find in a top-of-the-line pin cab,
from button inputs to feedback device outputs.  It has two main
design goals:

* It's comprehensive: it provides the extra peripherals required for
all of the Pinscape features (accelerometer, plunger input, button
input, feedback device control, IR remotes, TV ON power sensing), and
has ample button and feedback device ports to wire a fully decked out
pin cab

* It's DIY-friendly: it includes only through-hole parts that can
be easily soldered by hand

A third, lesser-but-still-important priority is to use common parts
that are widely available and are likely to remain in production for
many years.  The original Pinscape KL25Z boards are difficult to build
today because they depend on a few specific parts that are no longer
in production, most especially the KL25Z itself, but also the
TLC5940NT PWM chips.  I tried to avoid those sorts of dependencies as
much as possible in this design.  The biggest unique-part dependency
is the Pico itself, which is widely available and well supported by
Raspberry Pi.

Unlike the original Pinscape KL25Z expansion boards, where you were
encouraged to mix and match the Main, Power, and Chime boards in
different combinations to come up with a bespoke port layout, this
board set is designed as a One-Size-Fits-All solution.  There's no
provision to add a second or third power board, and there aren't any
optional add-on boards comparable to the Chime board.  The goal is
that the two boards have enough general-purpose ports between them
that no one would even want to add a third board - the two boards
should cover just about everything in a full-featured pin cab.

You can, however, use the main board all by itself.  I tried to
arrange things so that almost everything is on the main board, except
for the bulk of the output ports.  And even then, the main board has a
fair number of outputs.  If you use the main board on its own, you
still get the 16 flasher/strobe ports and 12 of the high-current MOSFET
outputs, plus all of the other I/O functions (buttons, accelerometer,
plunger connections, IR remote, TV ON).  The second board just adds 16
more high-current MOSFET outputs and the 32 mid-power lamp outputs,
plus the real-time clock chip, which most people won't especially miss.
If you don't need all of the extra output ports or the RTC, the main
board makes a perfectly good stand-alone controller.

My reason for using a less "modular" design than the old boards is
that I think the modularity ended up being a net negative: it added
flexibility, but at the cost of more complexity.  And I don't think
very many people took advantage of the flexibility - I think
practically everyone built one of the "standard" configurations,
either the Main + Power board combo, or a Main + Power + Chime set.
But everyone still had to go through the process of planning their
setup and then customizing their configuration settings once it was
built.  This time around, I figured that if everyone's going to build
the standard configuration anyway, let's make the standard configuration
so comprehensive that no one would really need other options.  It
simplifies the design, and it simplifies everyone's planning and
setup process.

## Features

* 32 button inputs, using shift register chips for extremely low latency
scans (order of 10 microseconds)

* Accelerometer (LIS3DH), installed via a pre-assembled module
available from Adafruit (no need to hand-solder the tiny SMD chip),
for nudge sensing

* An optional ADC (analog-to-digital converter, ADS1115), installed
via a pre-assembled module available from Adafruit, for high-precision
analog input from a potentiometer-based plunger (improving on the Pico's
mediocre built-in ADC)

* 28 MOSFET outputs for high-current feedback devices, such as motors,
solenoids, and standard LED strips

* 16 flasher/strobe ports for high-current LEDs, up to 1A per port,
for driving the 3W RGB LEDs typically used for flasher panels plus
a strobe LED

* 32 medium-current ports, up to 500mA per port, for driving almost
any sort of lamp (small incandescent or LED bulbs like those used in
lighted pushbuttons, small LEDs, large LEDs), relays and contactors,
and anything else that runs on less than 500mA

* All output ports have full PWM control, with configurable PWM
frequencies up to 65000 Hz

* Plunger input port, pin-compatible with the original Pinscape KL25Z
plunger port; just plug in your existing Pinscape plunger

* IR transmitter and receiver, with the sensor and transmitter on
small separate boards (connected to the main board with cables), so
that can be positioned anywhere in (or outside) the cabinet, to place
them in line-of-sight with the devices they're communicating with

* Power-sensing circuit for the Pinscape TV ON function (to help you
implement seamless one-button startup of the whole pin cab, even when
using TVs that don't remember their power state)

* Real-time clock/calendar chip with battery backup, for time-keeping
across Pico resets, even when the board is unpowered

## Board Design Files

Each board set consists of two sub-boards, titled **Main** and **Power**.
These two boards are designed to work together as a set.

Each sub-board design is contained in a pair of EAGLE files: **.sch** is the schematic,
and **.brd** is the physical board layout file.

The **.sch** file is a schematic, which is a special symbolic language
that electrical engineers use to describe the connections between
components in a circuit.  The symbology is more or less standardized,
so anyone with a basic knowledge of electronics should be able to read
it.  The schematic doesn't have any details on how the parts are laid
out physically, so it can't be used by itself to manufacture a board.
It's primarily for use by humans, to understand how the board works at
the electronic level.

The **.brd** file represents the complete physical layout of the
board.  This implements the same abstract network of connections
contained in the schematic, but it adds full details on the exact
physical placement of each component, and the layout of the copper
traces between components.  The **.brd** file contains everything that
a manufacturer needs to make a physical copy of the board.

### Viewing an EAGLE file

The **.brd** and **.sch** files are EAGLE documents.  EAGLE is a
circuit designer program published by Autodesk, with a free
personal-use version available at https://www.autodesk.com/products/eagle/free-download.
The free version has restrictions on how large a board you can edit,
but it does let you **view** boards of any size, and it also lets
you run the CAM Job Processor, which is how you create Gerber files
for submission to fabricators (see below).

There are also a number of on-line EAGLE file viewers - try searching
for **on-line EAGLE file viewer**.  One of those might be more convenient
if you only want to view the files, since there's nothing to install.

### Gerber Files (what you send to the board fabricator)

Most board fabricators require you to supply them with a special file
format called **Gerber files**.  The exact format for the Gerber files
varies slightly by fabricator, so there's no practical way that we
can include pre-built Gerbers for every vendor out there.  Instead,
we provide the **.brd** files, and leave it up to you to generate
the Gerber files for your chosen fabricator.

Fortunately, the process to convert a **.brd** file to Gerber files is
essentially automatic in EAGLE.  All you need is the Pinscape **.brd** file,
and a separate that your fabricator providers, called the **.cam**
file.  The **.cam** file contains programmed instructions for the
vendor-specific Gerber rules.  EAGLE has a simple procedure you can
follow that combines the **.brd** and **.cam** files to produce the
Gerber files for your specific vendor:

* Go to your chosen PCB fabricator's Web site and find their submission instructions.
Look for the EAGLE section.  That should provide links to the vendor's **.cam** file
for EAGLE.

* Load the Pinscape .BRD file into EAGLE (https://www.autodesk.com/products/eagle/free-download)

* In the EAGLE board viewer window, select **File** &gt; **CAM Processor**

* In the CAM Processor window, select **File** &gt; **Open** &gt; **Job**

* In the file dialog, select the **.cam** file that you downloaded from your PCB vendor

* Click **Process Job**

* You should now find a collection of new files in the folder containing the
BRD file.  These typically use the following extensions (although the exact
ones might vary by vendor): .GBL .GBO .GBP .GBS .GKO .GTL .GTO .GTP .GTS .XLN.
These are the Gerber files.

* You'll have to check your vendor's instructions for the next step,
but in most cases, you simply create a ZIP file containing all of the
Gerber files created above, and upload the ZIP file to the vendor, and
they'll take it from there.

## Parts Lists - "Bill of Materials" (BOM)

In addition to the EAGLE design files (SCH and BRD), each board has a
matching BOM (Bill of Materials) file.  The BOM is provided in CSV
(Comma-Separated Values) format.  BOMs are essentially shopping lists
for the electronic components you need to populate the board.  You can
view CSV files in spreadsheet programs like Microsoft Excel, Apple
Numbers, or Google Sheets.  Mouser and Digikey accept CSV files as
direct uploads to construct shopping carts, so that you don't have to
re-type all of the part numbers.

## BOM Versions

<b>Important:</b> Always match the <b>version of the BOM</b> to the
</b>version of the circuit board</b> you're building.  The specific
components used, and their reference designator assignments ("R3",
"IC7", etc), can change across versions.

github keeps a full history of every file (that's really the whole
point of git), but you have to deliberately go look for an old version
if you need one, because github's default view simply shows you the
latest version of everything.

To see the full version history of a file, find the BOM file in
the github tree, open it, and then click the <b>History</b> button
at the top right of the page.

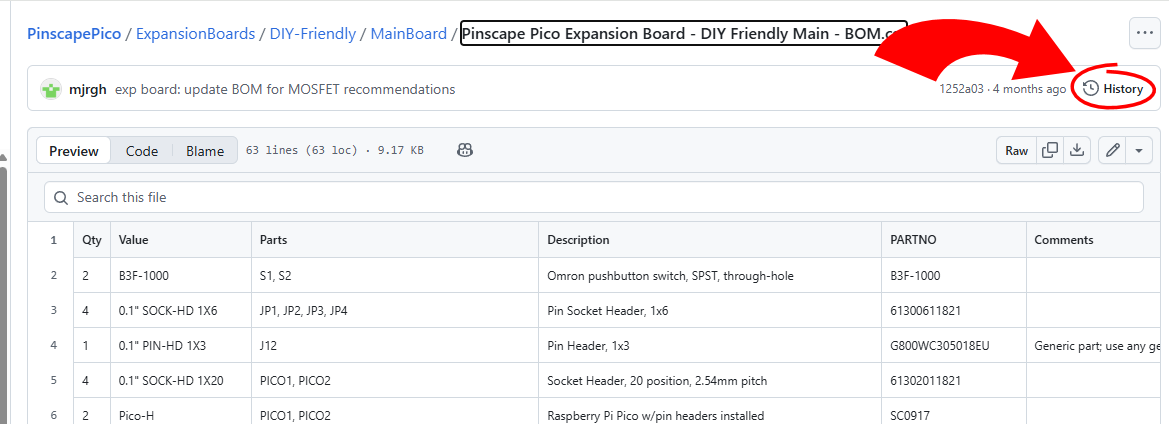
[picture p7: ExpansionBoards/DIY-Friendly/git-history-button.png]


Go down the list and find the version with the date that's closest to
the revision date printed on your physical circuit board.  You should
find the date printed on the top of the board, in the format "REV
20250603".  That's the revision date, formatted as a year, month, and
day - "20250603" means 2025 June 03.  In most cases, the file history
version that's <b>after</b> that date and closest to it will be the
one to use.

For convenience, here are links to BOM versions for a few board
revisions that I know people have manufactured so far.  This isn't
comprehensive, though, so if you have a board version not listed, just
use the procedure above to find the right version.

<ul>
    <li>Rev 20250203
    <ul>
        <li>Commit 6d375de
        <li>Main: https://github.com/mjrgh/PinscapePico/blob/6d375de3afc79e1a0121002b1ce2c9939880554a/ExpansionBoards/DIY-Friendly/MainBoard/Pinscape%20Pico%20Expansion%20Board%20-%20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
        <li>Power: https://github.com/mjrgh/PinscapePico/blob/6d375de3afc79e1a0121002b1ce2c9939880554a/ExpansionBoards/DIY-Friendly/PowerBoard/Pinscape%20Pico%20Expansion%20Board%20-%2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
    </ul>
    <li>Rev 20250603
    <ul>
        <li>Commit 1252a03
        <li>Main: https://github.com/mjrgh/PinscapePico/blob/1252a03060d82a5c3b8f7cad5739bbce4cbe7fbf/ExpansionBoards/DIY-Friendly/MainBoard/Pinscape%20Pico%20Expansion%20Board%20-%20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
        <li>Power: https://github.com/mjrgh/PinscapePico/blob/1252a03060d82a5c3b8f7cad5739bbce4cbe7fbf/ExpansionBoards/DIY-Friendly/PowerBoard/Pinscape%20Pico%20Expansion%20Board%20-%2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
    </ul>
</ul>

If you're ever unsure about a version match, you can verify it by
checking the version of the **.brd** file that's stored under the same
github commit number (the six-digit hexadecimal code listed alongside
each version in the history view).  Each commit represents a **complete snapshot of the entire repository,**
so you can be sure
that all of the files at a given commit number are in sync with each
other.  Once you find the BOM version you think is right, you can look
at the **.brd** file history, find the same commit number in the list,
and then check the REV number on that version by opening the **.brd**
file in an EAGLE viewer.

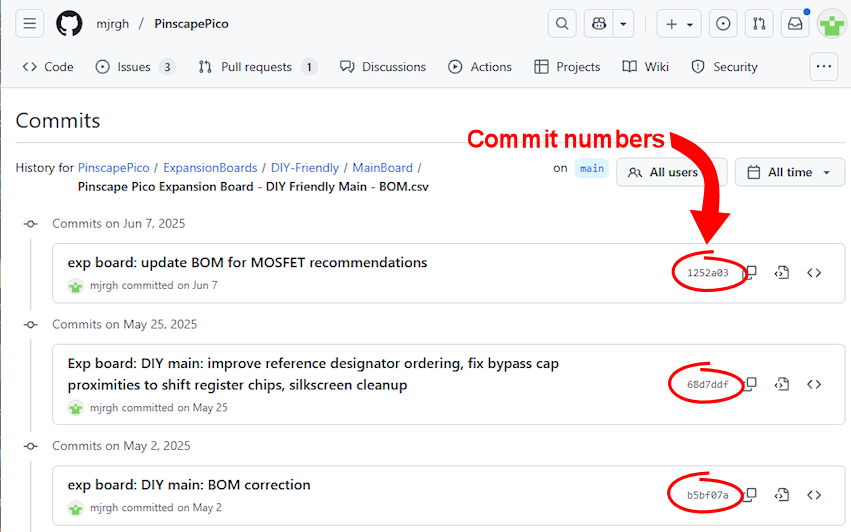
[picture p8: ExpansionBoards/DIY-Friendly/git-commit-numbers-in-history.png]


## Important Notes on the BOM

<b>Gate driver resistors (R1, R2, etc):</b> The BOM specifies three
options for these resistors.  The recommended value is 200 Ohm.  Line
items for 4.7 Ohms and 47 Ohms are also included for reference, with
zero quantity.  The tradeoff in choosing a resistor value is that
lower values yield faster MOSFET switching transitions during PWM
operation, reducing MOSFET heating, but higher values are more
protective of the UCC27524P gate driver chip.  According to the
UCC27524 data sheet, the chip should be compatible with very low gate
resistor values, as low as zero Ohms, but early testing suggested that
there's a risk of overloading the chip when a MOSFET with high gate
capacitance is combined with a small gate resistor.  The recommended
200 Ohms appears to be a good middle ground that yields cool MOSFET
operation without risk of UCC27524 damage, even for high-capacitance
MOSFETs.

<b>IR emitter:</b> Two different part numbers are listed for the IR
emitter: VSLB4940 and TSAL6400.  You only need one or the other, and
they're interchangeable as far as the expansion boards are concerned.
You can use either one without making any changes to the boards.
Both will work equally well, but VSLB4940 is a newer device with
slightly higher luminosity specs, so it will probably work over
slightly longer distances than TSAL6400.  TSAL6400 is a tried-and-true
device that I recommended for the original Pinscape KL25Z expansion
boards, so it will work well too.  Choose based on price and
availability, but other things being equal, I'd go with the slightly
brighter VSLB4940.  In my testing, I got at least 10 feet of range
with that emitter.

<b>MTA-156 and MTA-100 connectors:</b> The BOM includes the pin header
<b>and</b> matching IDC wire housing for each connector.  The wire
housings are IDC type, which is fast and easy to wire - but note that
it requires a <b>specific wire gauge</b> for each housing.  I chose a
mix of 24 AWG and 22 AWG connectors - 24 AWG for low-power wiring like
buttons and lamps, and 22 AWG for the high-power MOSFET outputs.  The
MTA-156 and MTA-100 product lines also include mating connectors for a
range of other wire gauges, so if 22 and 24 AWG aren't right for your
needs, you can substitute the corresponding MTA connectors for your
desired gauge.  The **headers** are independent of wire gauge, so you
don't need to change those - it's the **IDC housings** that go with a
specific gauge.  I chose 22 and 24 because they're perfectly adequate
for the respective jobs, and it's easy to source wire in those sizes.
From a cost perspective, it's better to minimize the number of
different wire types you use so you can buy big spools of a few types,
rather than lots of little spools.

### IR Remote

This board has support for an optional IR remote control transmitter
and receiver.  You can connect either or both as desired.  The IR
transmitter lets you send commands to your TVs and any other devices
that can receive IR signals, which you can use to send them commands
to power on, select inputs or video modes, etc.  The IR receiver lets
Pinscape receive IR remote control codes from just about any IR remote
control you have handy.  You can use IR remote inputs as though they
were physical buttons on the cabinet, to send commands to the PC host.

Both the transmitter and receiver are designed to be separated from
the main board, so that you can place them in convenient locations
where transmitters and receivers can "see" each other properly.  This
lets the signals get in and out even if the main board is buried deep
inside your pinball cabinet.  The off-board devices connect to
the main board through cables, which connect to headers on the main
board (the headers labeled IR-TX, for the transmitter, and IR-RX, for
the receiver).

<b>Transmitter:</b>  The IR transmitter is located off of the main
board, but it doesn't require its own separate circuit board, because
the whole receiver consists of just a single small LED.  You simply
solder wires directly to the LED and run them back to the main
board.  See the [IR-TX](../IR-TX/) folder for help with wiring the IR LED.
After wiring the LED, plug it into the IR-TX header on the main board.

Note that the BOM lists two options for the IR LED: VSLB4940 and
TSAL6400.  You only need one or the other, and they're
interchangeable, so you can pick whichever one is cheaper or more
readily available.  No changes are required to the expansion board.
Other things being equal, I'd go with VSLB4940, because it has
slightly better luminosity specs, which should give it slightly better
range.

<b>Receiver:</b> The receiver requires a small "satellite" circuit
board, because the sensor that does the receiving has a couple of
extra supporting parts that have to be installed alongside it.  See the
[IR-RX](../IR-RX/) folder for the receiver circuit board design.  After building the
board and wiring the cable, plug the cable into the IR-RX header on
the main board.

## Button pin labels

The button input headers on the originally published boards lacked
markings showing exactly which pin corresponds to which button, which
makes it a little puzzling to wire.  You can always refer to the
schematic, but most people don't want to figure out how to use EAGLE
just to see which buttons go where.  I left out the labels originally
because there simply wasn't much room for them, but on the whole it's
probably better to cram in some tiny markings.  For reference, here's
a diagram showing the new button labels - even if your board doesn't
have the markings, it should still match the pin layout shown below.

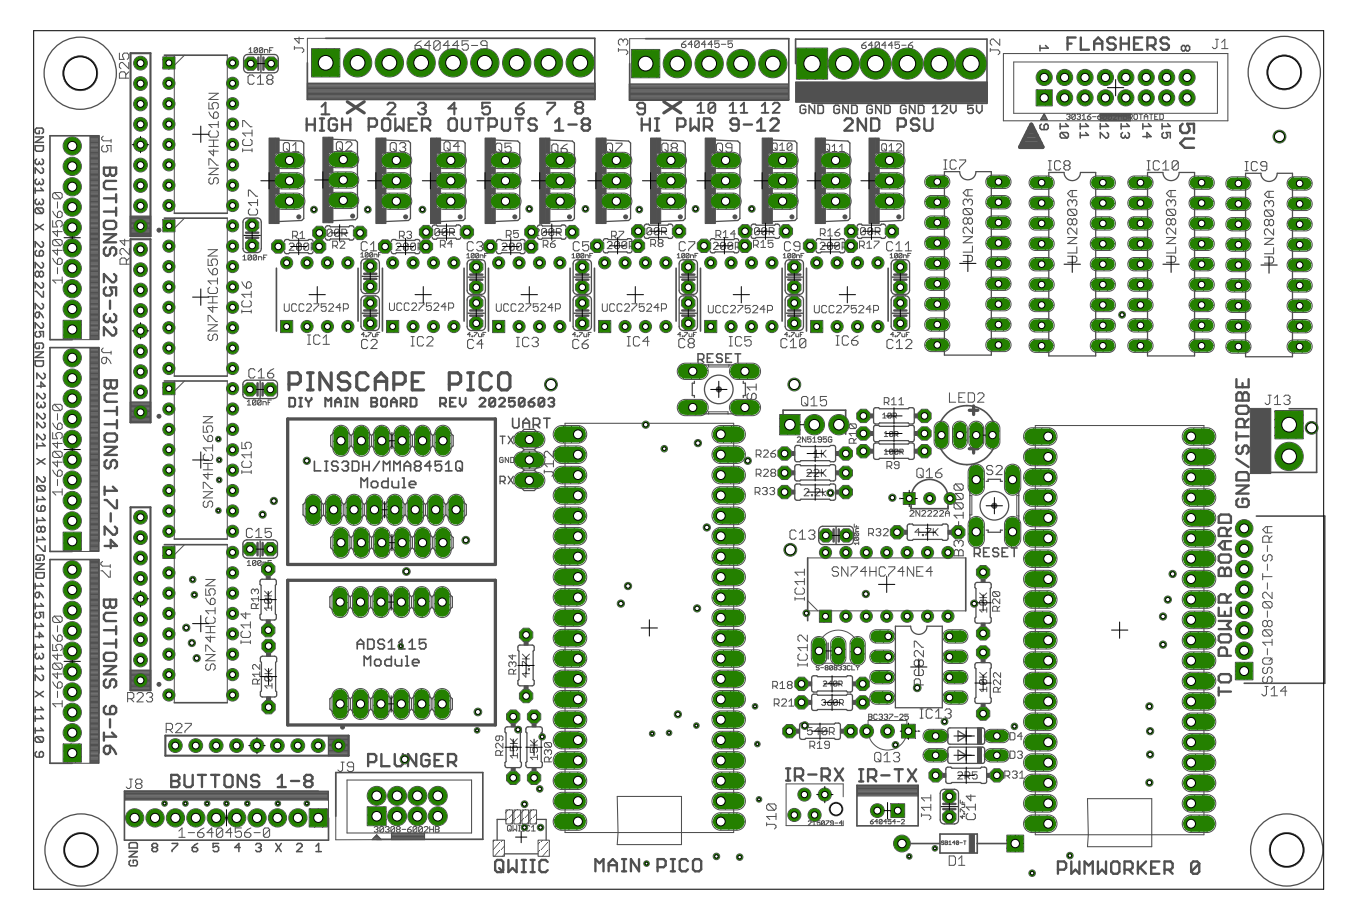
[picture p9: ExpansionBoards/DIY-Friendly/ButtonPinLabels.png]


A few notes on the markings:

* The pins marked GND (the leftmost pin on each header) are the
Ground/Common connection.  For every
switch, wire one terminal to GND, and wire the other terminal to an
individual button port.  The Ground/Common wires can all be connected
together, so it's usually easier (and saves a lot of wire) to run
a single Common/Ground wire from one button to the next in a giant
daisy chain.

* Note that the GND connections on the four button input headers are
all connected together internally, so you can use any GND pin from
any of the headers as the source of the Ground/Common connection to
any buttons.  The only reason that each header has its own separate
GND pin is convenience, so that you have several GND pins to choose
from when setting up your wiring.

* The pins marked "X" are "keying" pins.  They're not connected to
anything on the board.  The idea of a keying pin is that you can
snip off the pin on the header, and insert a "keying plug" in the
corresponding position in the wire housing, to ensure that the plug
can only fit in that one header.  You'll notice that each button
header has its "X" keying pin in a different position.  That's so
that you can't plug the cable intended for J5 into J6, J7, or J8,
because the blocked-up socket where you inserted the keying plug
will only fit into J5, where you snipped off the pin for the
blocked-up keying position.  All of the other headers will still
have a pin in that position, which will block the keying plug and
prevent you from inserting the cable into that header.  It's
intended to make it easier to avoid mistakes when connecting
or re-connecting the wires, by making it obvious when the cable
doesn't match the header you're trying to plug it into.

* The remaining pins (besides the ones marked "GND" and "X") are
the individual button ports.  Each header has 8 button inputs,
numbered in ascending order **from right to left**.  (For one
reason or another, it's a common convention for circuit boards
to number the pins on a header from right to left, even though
that seems backwards to those of us who do most of our ordinary
reading and writing using Western alphabets.)

## Errata in revisions prior to 20250326

The early versions of the board, prior to rev 20250326, had some
design errors that I discovered during practical testing.  In my
eagerness to make the plans available as soon as possible, I published
the board designs when I considered them complete, even before I did
any physical build testing.  So I missed a few details that only
became apparent in the physical build.

To determine if you're using boards affected by these errata, look for
the revision number printed on the top side of the circuit board.
It's a small legend saying something like "Rev 20250326", adjacent to
the legend showing the name of the board.  The revision identifier is
simply the date of the last significant change, as you might have
guessed from the YEAR MONTH DAY format.  If the Rev number printed on
your copy of the board is 20250326 or later, the errors below have
already been fixed, and you can ignore this section.

<b>CR2032 battery insertion/removal:</b> The coin cell battery on the
early boards is a side-entry clip type, where you have to slide the
battery in and out of the holder through an opening in the side.  I
didn't leave enough clearance next to the clip for this maneuver,
though; the Darlington chips IC10 and IC11 are in the way of the path
of the battery.  The battery clip has enough "give" that it's still
possible to coerce the battery in and out by tilting it up over the
top of the Darlington chips that get in the way, but this requires a
bit of brute force, which doesn't feel comfortable when working with
delicate electronics.  This will make it inconvenient to replace the
battery when it eventually runs out of power.  On the plus side, that
should take a few years, since the battery is only powering the clock
chip, which draws very little power.

Workarounds: No workaround is outright necessary, since you can still
get the battery in and out with a little force.  If you're not comfortable
with that, I can suggest a workaround:  don't install the clip, but instead
substitute a self-contained CR2032 battery holder that connects to the board with
a pair of wires, such as [Eagle Plastic Devices 120-0110-GR](https://www.mouser.com/ProductDetail/122-0110-GR).
Similar devices are available on Amazon.  Solder the red wire to one of
positive post pads for BATT1 on the circuit board, and solder the
black wire to BATT1's large round central ground pad.

Fix: In newer versions of the board, the clip battery holder is
replaced with a top-loading type that doesn't require any side
clearance.

<b>DS1307 power supply:</b> The VCC (power supply) pin on the DS1307
chip on the Power Board is incorrectly wired to the secondary PSU 5V
supply.  This should be wired instead to the USB 5V from the main
Pico.  The chip will technically work fine on either 5V supply, but it
should have been wired to the USB power to ensure that it powers up
simultaneously with the main Pico.  Its startup time might be delayed
when connected to the secondary PSU power, since the secondary PSU in
a pin cab is often set up so that it only switches on *after* the main
PC powers up.

The problem this causes is that the main Pico might be unable to
determine the date and time during initial startup from a cold boot,
in cases where the clock chip isn't yet powered up by the time the
Pico is going through its startup processing.  If your Pinscape
configuration depends upon time-of-day features on the Pico side
immediately after startup, those features might not work properly.  As
soon as any PC software connects to the Pico, the Pico will be able to
get the time of day from the PC side, so this will only affect
functionality right after startup, before any PC software gets
involved.

Workaround: If you don't mind doing some surgery on the board, you can
correct this by cutting the trace on the board between DS1307 pin 8
(VCC) and the secondary supply 5V line, and then soldering a jumper
wire from DS1307 pin 8 to any convenient point on the VBUS network,
such as the anode ("+" side) of D1.  You can cut the trace with a
sharp knife, such as an X-Acto knife; the copper trace layer is quite
thin, so you just have to score the board deep enough to break the
copper.  Check your work by testing continuity with a multimeter -
make absolutely sure that there's no continuity between DS1307 pin
8 and the secondary supply 5V.  If the trace is still connected,
it will short-circuit the two 5V power supplies together, which
could do damage.

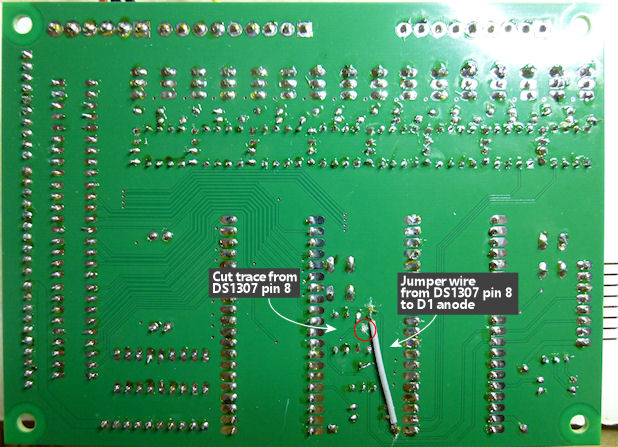
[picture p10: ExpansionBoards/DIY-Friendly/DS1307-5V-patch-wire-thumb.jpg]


Fix: In newer versions of the board, the power supply wiring to
the chip is corrected to connect to the main Pico USB power.

<b>Flasher header:</b>  The "pin 1 arrow" reference point and shroud
notch orientation marked on the silkscreen for the main board
Flashers header J1 are rotated 180 degrees from what they should
be to match the original Pinscape KL25Z expansion boards.  My intention
was to make this header exactly match the KL25Z port, so that you
could move your flasher cable over from the KL25Z boards without
rewiring anything.  I got it half right: the pin layout is the same,
so you can plug in the existing cabling as intended, but the markings
on the board are reversed from how they're marked on the KL25Z board.

Workaround: If you're installing a shrouded header, install it with
the notch facing the **inside** of the board, opposite to the markings
on the board showing the notch on the **outside edge** of the board.
Alternatively, you can use a plain header (without the shroud), which
lets you plug in the cable in either rotational orientation.
When plugging in the cable, orient the plug with the "pin 1" side
(which you might have marked with a red stripe on the cable) facing J2.

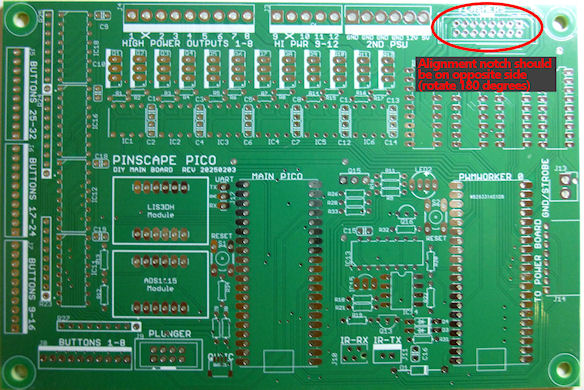
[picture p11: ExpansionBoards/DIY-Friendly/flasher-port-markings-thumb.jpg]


Fix: In newer versions of the board, the silkscreen markings are
rotated to match the KL25Z board markings.

## Design Variants

There are three variants of the basic board design available in the
repository.  The <b>Socketed Pico</b> variant is the official release
version, and the only one that I intend to continue revising.  I
consider the other two to be dead ends, but they might still be
preferable to some people for particular applications, so I'm
keeping them in the repository in case anyone finds them useful.

* <b>Socketed Pico:</b> The Pico is connected to these boards through
20-pin socket headers.  This makes it possible to remove and replace
the Picos without any de-soldering.  The sockets are generic parts
available from multiple manufacturers; one example is Wurth
61302011821, but any generic 0.1" socket header will work.  On Mouser
or Digikey, search the Headers & Wire Housings category for
2.54mm/0.1" pitch, 20 positions, 1 row, female, through-hole.

* <b>SMD Sockets:</b> This is an intermediate design, with the
original direct-soldered Pico layout changed to use Harwin M20-7862042
sockets, which are surface-mounted (SMD) 20-pin sockets.  This design
was meant to be a stopgap until I could finish converting to through-hole
sockets, which are easier to solder to the board and easier to source.

* <b>Soldered Pico:</b> The original version of the board, designed
for the Pico to be directly soldered to the board.  This takes advantage
of the "castellated" edge connectors on the Pico, which make it possible
to solder a Pico directly to another circuit board as though it were an
SMD component.  I started with this approach because it reduces the
total number of parts needed and makes the boards more compact,
but it has the disadvantage that the Pico can't be replaced (if it
ever breaks) without a lot of difficult solder removal.

I think almost everyone building the DIY boards will prefer the
through-hole-sockets version, which is why I chose that as the final
official design.  Installing the Pico in sockets is a big advantage
over soldering it directly to the board, because it lets you easily
remove and replace the Pico if it ever breaks.  The SMD-sockets
version of the board accomplishes that, too, but it violates the
"through-hole parts only" mandate of this board set, plus the
dependency on that unique Harwin part number might make it difficult
to source parts in the future.  The through-hole sockets are generic
commodity parts made by multiple manufacturers, so they should be easy
to source indefinitely.

## How to connect devices

Connecting output devices works essentially the same way as with the
original Pinscape KL25Z expansion boards, so you can refer to
[Pinscape Outputs Setup](http://mjrnet.org/pinscape/BuildGuideV2/BuildGuide.php?sid=psOutputsExp)
in my virtual pinball Build Guide for general wiring instructions,
keeping in mind that these boards look a little different, and that
the software setup procedure is different.  There's also some more specific
advice about the different port types on this board in the subsections
below.

Some additional Build Guide chapters that might be helpful:

* [LED Resistors](http://mjrnet.org/pinscape/BuildGuideV2/BuildGuide.php?sid=ledResistors)
* [Coil Diodes](http://mjrnet.org/pinscape/BuildGuideV2/BuildGuide.php?sid=diodes)
* [Button Lamps](http://mjrnet.org/pinscape/BuildGuideV2/BuildGuide.php?sid=buttonLamps)
* [Flashers and Strobes](http://mjrnet.org/pinscape/BuildGuideV2/BuildGuide.php?sid=flashers)
* [Beacons](http://mjrnet.org/pinscape/BuildGuideV2/BuildGuide.php?sid=beacons)
* [Undercab Light Strips](http://mjrnet.org/pinscape/BuildGuideV2/BuildGuide.php?sid=lightStrips)
* [Contactors for flippers and bumpers](http://mjrnet.org/pinscape/BuildGuideV2/BuildGuide.php?sid=contactors)
* [Replay knockers](http://mjrnet.org/pinscape/BuildGuideV2/BuildGuide.php?sid=knockers)
* [Shaker motor](http://mjrnet.org/pinscape/BuildGuideV2/BuildGuide.php?sid=shakers)
* [Gear motor](http://mjrnet.org/pinscape/BuildGuideV2/BuildGuide.php?sid=gearMotors)
* [Blower fan](http://mjrnet.org/pinscape/BuildGuideV2/BuildGuide.php?sid=blowers)
* [Chimes and bells](http://mjrnet.org/pinscape/BuildGuideV2/BuildGuide.php?sid=chimes)

### Buttons

The board will work with any standard arcade-style pushbutton,
leaf-switch flipper button, microswitch, or just about any other sort
of button with a mechanical "Normally Open" switch.  For a microswitch
with three terminals, connect the Normally Open ("NO") and Common
("C", "GND") terminals, and ignore the third terminal.  Connect one
terminal to a button port on the expansion board, and connect the
other terminal to ground.  You can wire all of the button grounds
together in a daisy chain to save wire.  The order of the terminals on
the buttons doesn't matter.

Each button header includes a ground terminal.  This is purely for
your convenience in finding places to connect the grounds.  All of
the grounds are wired together, so none of them are "special" and
none of them have to be connected to specific buttons.

See <a href="#ButtonPinLabels">Button Pin Labels</a> above for a
diagram of the pin layout of the button headers.  (Newer versions
of the board have these markings directly on the silkscreen, but
older versions didn't.  The diagram might be helpful if you have a
version without the markings.)

### Button lamps

For pushbuttons that have built-in lamps, you should think of the
lamp as a whole separate device from the button.  Wire the button's **switch**
to a Pinscape button port, just like any button without a lamp.
And separately, wire the button's **lamp** to a Pinscape lamp port, as
though it were just a lamp without a button attached.

### Lamps

Connect the positive terminal of the lamp or LED to its positive supply voltage.
(Incandescent lamps aren't polarized, so connect either terminal.  LEDs
have a "+" and "-" side that must be observed.)  Connect the negative
terminal to a lamp port on the board.

For LEDs, you must also connect a current-limiting resistor in series
with the LED.  Some LEDs have the necessary resistor built in.  See
[LED resistors](http://mjrnet.org/pinscape/BuildGuideV2/BuildGuide.php?sid=ledResistors).

Even though the lamp ports are called "lamp ports", they're really
not limited to lamps.  They can can handle any sort of device, as long as its
current draw is below 500mA.  The only reason we call them "lamp ports"
is that lamps are the most common devices in a pin cab that fit within
the 500mA limit, so we expect that these ports will mostly be used
with lighting devices.  But 500mA is enough for many
relays, contactors, and even smallish solenoids.  If you connect anything
mechanical, be sure to use a [flyback diode](http://mjrnet.org/pinscape/BuildGuideV2/BuildGuide.php?sid=diodes).
Diodes aren't needed for LEDs or incandescent bulbs.

Each lamp header includes one pin that's connected to 5V power.  This
is purely for wiring convenience - you can use it as the power source
for lamps and LEDs connect to the same header.  The 5V terminal just
connects straight back to the secondary power supply 5V input to the
board, so there's nothing special about it; it's just there as a
convenience, to give you another place to connect to the 5V supply.
You don't have to use this terminal for any of the lamps, and more
importantly, these ports aren't limited to 5V lamps.  Each lamp can
be connected to whatever power supply voltage it requires, up to 40V.
And you're free to connect devices with different voltage levels to the
same header - it's fine to connect a 12V LED strip alongside a 6.3V
incandescent lamp, and a 24V contactor next to that, all on the same
lamp header.

### Flashers and strobe

The flasher ports are essentially the same as the lamp ports, except
that they have double the current capacity, up to 800mA, to allow
connecting larger LEDs (or to allow connecting two or three LEDs to
each port in parallel).  The flasher port is designed to be pin-compatible
with the flasher port on the original Pinscape KL25Z expansion boards,
using a 16-pin ribbon cable connector.  Other than the connector type,
it works exactly like the lamp ports.

The Strobe port is just a 16th flasher port on a separate connector,
with the same higher 800mA capacity.  Connect it the same way as any
lamp port.

### High-power outputs

Connect the positive terminal of the device to its positive supply
voltage.  Connect the negative terminal to a high-power port on the
expansion board.  Most motors and solenoids aren't polarized, so you
can connect the terminals in either order, but check each device to
make sure.

Motors, solenoids, contactors, relays, and anything else mechanical
require [flyback diodes](http://mjrnet.org/pinscape/BuildGuideV2/BuildGuide.php?sid=diodes).
Lamps and LEDs don't need them.

## Power limits

All of the output ports have limits on how much power they can handle.
The ports are all designed to have ample limits for the typical sorts
of devices used in virtual pinball machines, with the goal that you
shouldn't have to think about it much.  But even so, you should check
the points below to make sure that the devices you plan to connect are
within the limits.

### Combined active current level - main board

The combined current level for all devices on the main board that are
active **at the same time** must not exceed 44A.

This only applies to devices that are activated simultaneously.  The
total load of all devices *connected* can be higher, as long as you
don't attempt to run them all at the same time.

It's difficult to predict how devices will be activated while playing
virtual pinball or other games, so I usually just make some
conservative guesses, such as assuming the the maximum simultaneous
load in practice will be around four or five of the highest-current
devices.

(Rationale: all of the switched feedback device current ultimately
flows through the four ground pins on the 640445-x power supply
connector, so the maximum current shouldn't exceed what those pins can
safely handle.  Too much current can overheat the pins and damage the
circuit board.  That connector type's "absolute maximum" rating is 14A
per pin, so with four pins, that gives us a maximum of 56A.  If we
apply a 20% safety margin, we get 44A.)

### Combined active current level - power board

The power board has the same combined limit as the main board for
devices activated **at the same time**, 44A, for the same reason.

### MOSFET outputs (main board and power board)

Each individual MOSFET output must not exceed 11A, **or** 80% of the
I<sub>D</sub>[Max] for the MOSFET selected, whichever is lower.

In addition, the power supply voltage for each device must be below
the MOSFET's drain-to-source voltage limit.

Refer to the data sheet for your chosen MOSFET to determine the limits,
shown in the **Maximum Ratings** (sometimes **Absolute Maximum**)
section under the symbols <b>I<sub>D</sub></b> (maximum continuous drain
current) and <b>V<sub>DS</sub></b> (maximum drain-to-source voltage).
For most large power MOSFETs in TO220 packages (as required to fit the
board), these values will be at least 10A and 50V, respectively, but
typically more like 20A and 100V.

(Rationale: The current through these ports has to flow through both
the connector pins and the MOSFET, so it can't exceed the safe limit
for either part.  The 640445-x connector is rated for 14A maximum per
pin, or 11A after a 20% safety margin.  The MOSFET limit depends on
which type of MOSFET you use, but for the reference part, it's higher
than pin limit, so the pin's maximum current is the limiting factor.)

### Flasher and strobe outputs (main board)

Each individual flasher output must not exceed 800mA.  This is enough
current to run two typical 3W RGB LED channels in parallel.

In addition, the power supply voltage for the flashers shouldn't
exceed 40V.

(Rationale: the connector is rated for 1A per pin maximum, and the
ULN2803A is rated for 500mA per channel maximum, with each pin connected
to two channels.  This yields 800mA maximum with a 20% safety margin.)

Note: There's some fine print, which you can probably ignore, but here
it is just in case you want the details.  These outputs are driven by
Darlington chips that have a hard limit of 500mA per port (400mA
after 20% safety margin; the current limit per flasher port is double
this because each flasher port is powered by two Darlington ports).
But these chips also have an **aggregate** power limit on total heat
dissipation through the whole chip at any given time, when you take
into account how many ports are activated simultaneously.  This total
power limit can work out to be less then 500mA per port in cases
when most or all of the ports are activated at the same time.
So it's not entirely accurate to say that the per-port flasher limit
is a simple 800mA (after the safety margin).  So why did we say 800mA?
Because we can't give you a simple, single number for the aggregate
limit, the way we can with the hard per-port limit.  The aggregate
limit is a limit on total power dissipation, and it's a function of
several variables that depend upon how you're using the chip in real
time.  If you want the details, refer to the ULN2803A data sheet; the
version of the data sheet from Texas Instruments has the best and most
detailed explanation I've seen on how to calculate the limit.  Each group
of four flashers is connected through one Darlington chip: flashers 1-4
are on one chip, 5-8 are on a second chip, 9-12 are on a third, and
13-16 (16 being the Strobe port) are on a fourth.  The aggregate limit
thus applies (separately) to each of these four groups.  The aggregate
limit only becomes important if you're running many ports from a group
at once, continuously, or at least at high duty cycle.  In real pin cab
situations, this rarely happens, so I'm pretty comfortable in my own
builds ignoring the combined limit and just sticking to the
800mA-per-port rule.

### Lamp outputs (power board)

Each individual lamp output must not exceed 400mA.

In addition, the supply voltage for each lamp shouldn't exceed 40V.

(Rationale: each channel is driven by a single ULN2803A channel, which
is rated at 500mA maximum, or 400mA after a 20% safety margin.)

Note: the comments in the Flasher Outputs section above about the
additional **aggregate** power limits for the Darlington chips
also apply to these ports.

## ADS1115 ADC

This should be installed if, and only if, you're using a potentiometer
as your plunger sensor.

The Pico has its own built-in ADC (analog-to-digital converter), so
you might wonder why there's a slot for another ADC chip.  The reason
is that the Pico's built-in ADC has rather poor resolution and some
known problems with linearity.  A potentiometer-based plunger benefits
from a higher-quality ADC, in that it will yield smoother on-screen
animation tracking the motion of the physical plunger.

The ADS1115 is completely optional, even if you're using a
potentiometer plunger.  You can simply omit it if you don't need it or
want it.  If you're using some other kind of plunger sensor apart from
a potentiometer, the ADS1115 won't even be used for the plunger, so
you shouldn't bother with it.  You can even omit it if you *are* using
a potentiometer plunger, since the Pico's ADC will work for that in a
pinch, but the on-screen animation it produces might be a little
coarse.  If you find it good enough with the Pico ADC, though, you can
save a few dollars by not installing the ADS1115.  And you can always
add in the ADS1115 later, since it's on a separate board that just
plugs in.

## How to install the ADS1115 and LIS3DH modules

There are two easy ways to install these boards:

1. For permanent installation: you'll need four 6-pin, single-row,
standard 0.1" pin headers.  Install these in the matching pads inside
the marked "LIS3DH Module" and "ADS1115 Module" areas on the board, with
the plastic base on the top side of the board, and the short ends of the
pins facing down, through the holes in the pads.  To make sure they're
aligned properly, fit the module board over the top - you can leave
it there while soldering to keep the alignment right.  Solder the pins
from the bottom of the board.  Now complete the job by soldering the
pins to the module board from the top side.

2. To make the modules removable: you'll need four 6-pin, single-row,
standard 0.1" pin headers, **plus** matching through-hole sockets,
in the normal vertical orientation (**not** the bent-over 90&deg; kind).
Install the sockets in the pads on the Pinscape board with the plastic
socket parts on the top side.  Solder the pins to the board on the
bottom side.  Now insert the pin headers into the module boards
on the **bottom* of side of the module board, with the plastic base
on the bottom of the board and the **long** part of the pins facing
down away.  This will let you plug the board into the sockets you
just installed on the Pinscape board, with the module board facing up.
Solder the pin headers to the module boards from the top side.  Now
just plug the module board into the sockets on the Pinscape board.

## Connectors

### Buttons, High-Power Outputs, Lamp Outputs

All of these headers are designed for TE Connectivity's
[MTA 100 and MTA 156](https://www.te.com/en/products/connectors/pcb-connectors/intersection/mta-100-mta-156-connectors.html)
series connectors.  These are all single-row pin headers with
polarizing ramps, and matching wire housings with IDC or crimp-pin
termination.

MTA 100 uses 0.1" pin pitch, for low-current connections (button
inputs, lamp outputs).  MTA 156 uses 0.156" pitch (you can probably
see the naming pattern), for the high-power outputs.

You don't have to use MTA 100/156 specifically, because connectors
in the same size are available from many vendors, and they'll fit
the pads on the circuit boards.  However, the MTA 100/156 series
has some features that I like, so I used them as the reference.

* Ramps:  Plastic tabs on the backs of the board headers that
match cutouts in the wire housing/plug.  These prevent you from
plugging in the connector in the wrong orientation (the tab has to fit
the matching cutout in the housing to plug in properly).  They also
help lock the connector to the board so that it doesn't loosen or fall
out due to mechanical vibration.

* IDC housings:  TE makes matching connectors with IDC termination.
IDC stands for Insulation Displacement Connector, and it means that
you connect a wire to the plug by pushing the wire into a slot that
contains a metal blade that pierces the insulation and grabs onto
the wire.  It's a very quick and easy way to assemble the connectors;
I find it a lot more convenient than the crimp-pin style, which is
the main alternative.  TE also makes crimp-pin housings that match
these connectors for those who prefer that style.

Molex makes equivalent connectors that will fit the slots, also with
polarizing ramps, but Molex's are only available with crimp-pin housings.
There are also generic 0.1" and 0.156" headers that are just plain rows
of pins without the ramp.  Those are a lot cheaper, and they'll work
fine, but I think the ramp is worthwhile because of the locking action
and the protection against reversed connections.

### Plunger Connector and Flasher Outputs

These are two-row, 0.1" pitch headers, designed for use with IDC
ribbon cable connectors.  The footprints on the board are sized to
make space for shrouded headers, which include a plastic shell
around the pin header.  The shroud has a keying slot that matches
a tab on the IDC connector, so that you can only plug in the cable
in the correct orientation.

If you prefer, you can skip the shroud and use ordinary two-row 0.1"
headers.  Those are compatible with the same connectors, but you
won't get the wrong-way insertion protection.

These headers are designed to match the pin layout of the
corresponding connectors on the original KL25Z Pinscape boards, so
that you can move over existing equipment if you want to migrate an
existing KL25Z setup to the new system.  When installing the shrouded
headers, please double-check before soldering that the orientation of
the slot matches your existing connectors!

### QWIIC port

This is an optional connector for external boards using the QWIIC
standard, which is a modular cabling system created by SparkFun that
makes it easy to connect breakout boards to microcontrollers.
SparkFun, Adafruit, and many other hobbyist electronics/robotics
vendors make QWIIC-compatible boards for various chips, so I thought
this would be a handy thing to include to allow for experimentation
and custom add-ons.  This port doesn't have any pre-defined use in
Pinscape Pico, so you can omit the connector if you don't think you'll
use it (and you can always add it later in any case).

There's a similar standard called STEMMA, which Adafruit uses for all
of their boards.  STEMMA boards are compatible with QWIIC hosts, so
yes, you can use Adafruit boards with this port.  The difference
between the two standards is that a STEMMA board has voltage shifters
that let it work with 3.3V and 5V hosts, whereas QWIIC boards only
work with 3.3V hosts.  That makes STEMMA boards compatible with QWIIC
hosts.

## Parts Sourcing Notes

Most of the parts were chosen to be readily available generic parts
that are made by multiple manufacturers, and that have been around for
many years, and are likely to remain in production for years to come.
Hopefully that will make it easy to source parts, even if you're
embarking on this project long after 2025.

In case you do have difficulty sourcing any parts, though, here are
some notes on selecting substitutes.

QWIIC Connector: Optional; only needed if you want
to be able to plug in additional I2C boards that use the QWIIC cabling
system.  This connector is unfortunately only available in an SMD part,
so we had to violate our own "no SMD parts" design rule, but this is
one of the easier SMD parts to solder.  This is a 4-pin JST connector
with 1.0 mm pin pitch, currently part number SM04B-SRSS-TB(LF)(SN).

RGB LED: Most RGB LEDs in this form factor have similar specs, so it
should be easy to find a suitable substitute if necessary.  The LED is
powered from the Pico 3.3V supply, so the Vf (forward voltage) spec on
each channel must not exceed 3.3V.  If you substitute a different
part, you should recalculate the resistor sizes for the series
resistors on the three channels, based on 10mA current per channel.

SB140-T Schottky Diode: This was chosen to match the properties specified
in the [Raspberry Pi Pico Data Sheet](https://datasheets.raspberrypi.com/pico/pico-datasheet.pdf),
under **Powering Pico**.  Any similar device can be substituted:
If (forward current) at least 1A, Vf (forward voltage drop) at 1A
less than 400mV.

2N5195G: PNP switching transistor.  This switches 3.3V power to the
accelerometer and ADC, allowing the Pico to fully reset those devices by
power-cycling them.  Any PNP with gain of at least 50 and maximum
collector current of at least 200mA should work.

2N2222: Small-signal NPN transistor.  Any common small-signal NPN
should work, as this is used only for logic voltage switching.

1N5711: Small-signal Schottky diode.  Any similar Schottky should
work; look for Vf (forward voltage drop) around 500mV or less.

DS1307: A real-time clock/calendar chip with battery backup.  You can
simply omit this chip (as well as the battery and crystal) if you
can't find a substitute or don't need the RTC feature.  This type of
chip is one of those de facto industry standards where many companies
have been making clones of the same design for many years, so you
might actually be able to find a suitable replacement if DS1307 is no
longer available.  The new chip must obviously have the same pin
layout (unless you're willing to modify the board footprint), and it
must have an I2C interface.  It will probably be necessary to add
device driver support for any new chip you select to the Pinscape
firmware, although most of the chips in this category use nearly
identical command sets, so you might find that a new chip just happens
to work with one of the existing Pinscape RTC drivers.

Crystal (ECS-.327-12.5-13X-C): This is the time-keeping crystal
for the DS1307, so you can omit it if you're omitting DS1307.
You can substitute any crystal with 32.768 kHz frequency, 12.5 pF load
capacitance, and equivalent series resistance (ESR) less than 45K Ohms.

ULN2803A: 8-channel Darlington transistor array, with internal
resistors for logic-level drive.  This is a common chip type; any
Darlington array with the same pinout and similar internal resistor
values should work as a substitute.  This chip will drive 500mA per
output channel; if you substitute a chip with a different limit,
just be aware of the change in limit to the flasher and lamp outputs.
The Flasher outputs on the main board are arranged in pairs so that
each output can drive 2X the per-channel Darlington limit, while the
single-channel limit applies to the Lamp outputs on the second board.

PC827: Dual optocoupler.  Any xx827 part with the same pin layout
should work as a substitute.

S-80833CLY: Voltage detector; this detects when the voltage on the
secondary PSU 5V line drops below 3.3V, for the TV ON power sensing
circuit.  This is a common device category, known as Voltage Detectors
and also as Power-On-Reset (POR) chips, but unfortunately the pin layouts
and electrical characteristics vary a lot between devices from different
manufacturers, so it's unlikely that you'll be able to find a drop-in
substitute.  The one easy substitution you can make is that
the S-808xxCLY family has many variations with different threshold
voltages - that's what's encoded in the 'xx' part of the name, as
the voltage times ten, so 33 means 3.3V, 30 means 3.0V, etc.
Any other S-808xxCLY family member with a threshold voltage between
3.0V and 4.0V should work find for this board.  If you can't find any
other S-808xxCLY and have to substitute a different family altogether,
the circuit will work as long as the new part has a PUSH-PULL ACTIVE-LOW
output.  PUSH-PULL means that the device actively drives the output HIGH
when the monitored voltage is on, and ACTIVE-LOW means that the device drives the
output LOW when the monitored voltage falls below the threshold voltage.
The big inconvenience with substituting a different family will probably
be that you'll have to modify the footprint on the board to match a
different pin layout.

SN74HC74NE4: Dual flip-flop with asynchronous preset and reset.  The
74xx74 series is one of those venerable basic logic chips that's been
around for decades, and there are many variations with different
letters mixed into the part name string.  Most chips with a 74xx74
name pattern should be compatible with this board; to evaluate a
substitute, check that the pin layout matches the TI SN74HC74NE4, and
that it's compatible with a 5V supply voltage.

SN74HC165N: 8-bit parallel-load shift register. This is another
long-running series with pin-compatible versions from multiple
manufacturers.  Any 74xx165 alphabet-soup variation should have the
same pin layout, and can probably be substituted in this board as
long as it's compatible with a 3.3V supply.

UCC27524P: Dual low-side MOSFET gate driver with positive logic (HIGH
on the input translates to HIGH on the output).  This is another
common chip type with pin-compatible chips made by several
manufacturers.  This particular chip has two Enable pins (ENA, ENB),
while many variations with the same pin layout show the corresponding
pins as Not Connected (NC).  This board doesn't use the Enable
feature, so a substitute with NC pins in those positions is acceptable.
However, UCC27524P has one important feature that's **not** common in
this type of chip, which is that the inputs (INA, INB) have internal
pull-down resistors that deterministically turn the output off (LOW) when
the input is floating or disconnected.  This is a critical feature in this
design because it guarantees that the outputs will remain off during startup,
when the Pico's GPIO ports (which control the gate driver inputs) are
in high-impedance state.  If you aren't able to find a gate driver
with internal pull-downs, it would be necessary to modify the board design
to add equivalent external pull-downs, by adding a 10K resistor to ground
on each INA/INB line.  I specified UCC27524P because it makes the
extra pull-downs unnecessary, which reduces the part count
and saves space on the board.  The board is already pretty packed,
but it might still be possible to get the extra resistors in there,
either as discrete resistors or as bussed network resistors similar
to the ones used to pull up the button inputs.

4609X-101-103F: 8-resistor network, bussed.  This is a common part
made by many manufacturers.  The size of the resistors isn't very
important, because all they do is pull up an open button circuit to
3.3V; anything from 1K to 100K should work.  "Bussed" means that all
of the resistors are connected internally so that one end of each
resistor is tied to a "common" pin.  Any substitute must have the same
configuration.

MOSFETs: These are the driver transistors for the high-power outputs.
The choice of parts here is very open, because this board is designed
to work with almost any common "power" MOSFET.  The main properties
that you should look for are:

- Pin layout: choose a device in a TO-220 package (that's just the
code name for the form factor, with the black plastic body, three
big metal pins/legs, and a heat fin on the back).  This is a very
common package type for power MOSFETs, and there are probably
thousands of different parts made in this style.  One detail,
though: the pin layout isn't always the same just because it's
in a TO-220 package. Make sure that the part you choose has the
same order of pins as the board uses: when looking at the TO-220
package from the front, the pins, left-to-right, must be ordered
G-D-S (Gate, Drain, Source).

- Id[max] (maximum continuous drain current): Choose a MOSFET with an
Id[max] rating well above the maximum current of the toys you intend
to attach to these outputs.  For virtual pin cabs, the largest toys
tend to be motors and solenoids, which might draw up to 5 or 6 Amps,
so I'd choose a MOSFET with an Id[max] of at least 10A.  That's
actually relatively low by power MOSFET standards - many parts can
easily handle 20A or 30A - so this isn't a very hard requirement
to satisfy.

- Rds[on] (on-state resistance): There's no hard rule here, but since
we're using the device for on/off switching, lower is better.   Look
for something below 25 milli-Ohms.

- Vds[max] (maximum drain-to-source voltage, also known as breakdown
voltage): This also depends on the toys you're using.  Choose a device
with a breakdown voltage well above the highest supply voltage you
intend to use for your feedback devices.  I'd use a 2X margin if possible.
If you're using a 50V pinball knocker coil, use a 100V MOSFET.  It's
fairly easy to find TO-220 MOSFETs with such high voltages.

- Vgs[max] (maximum gate-to-source voltage): The board drives the
MOSFET gates with +12V.  Choose a part with Vgs[max] of at least 20V.
Most power MOSFETs will qualify, but check carefully if you find
one that's labeled as a "logic" MOSFETs.  Those are specially designed
to be switched by lower gate voltages, and might have a Vgs limit
of 10V or below, which isn't suitable for this board.

## Missing features

I like to claim that this board set is a "comprehensive" virtual pinball
I/O controller, but that's not 100% accurate.  There are a few specialized
functions that it lacks, but for good reasons, as explained below.

### No support for smart light strips

The one big virtual pin cab feature that these boards don't support is
"smart" light strips, with individually addressable LEDs, such as
WS2812B strips.  You still need a separate controller for that.
Pinscape Pico itself doesn't have any smart light strip support at
the software level, so it didn't make any sense to include such
a thing on these boards.

### What happened to the "Chime" boards from the old KL25Z set?

The Pinscape KL25Z expansion boards included the option to add Chime
Boards.  The Chime Boards were basically MOSFET Power Board ports, with
the added feature of a **hardware time limiter** on each port that
prevented the port from being activated for more than a couple of
seconds at a time.  The point of the time limiter was to protect
pinball coils and other high-power solenoids from damage in cases
where a software fault on the PC caused the coil to be locked on.
Pinball coils typically can't tolerate continuous activation for
more than a second or two - they'll overheat and melt if you try.

This board set doesn't have any such hardware-protected ports.  To
make up for it, the Pinscape Pico software has equivalent timer
protection that can be configured on a port-by-port basis.  In
addition, the software and hardware both have fail-safe features that
are designed to protect against faults at the Pinscape Pico firmware
level, where the software timers are implemented:

* The Pinscape Pico firmware programs the Pico's hardware "watchdog"
unit to reset the Pico in the event the software ever stops functioning
for more than a few milliseconds.  The watchdog is an independent
hardware unit on the Pico that forces a hard reset if the software
stops sending it messages saying "I'm not dead yet" for more than
a programmed time limit, so it's very good at detecting software
faults and forcing the Pico into a hard reset.

* The expansion board hardware is designed so that all ports turn off
instantly and deterministically when the Pico is in a hardware reset
condition.

These features work together as a backstop against failures in the
Pinscape software that monitors the port time limiters.  As long as
the software is functioning correctly, it should take care of applying
the programmed time limits set by the flipper logic/chime logic
configuration options in the output port setup.  If the software ever
gets stuck in such a way that it can no longer apply the software time
limiters, it will also be unable to send "not dead yet" messages to
the watchdog hardware, so the watchdog will rapidly reset the Pico at
the CPU level.  And once the Pico resets, the physical output port
controllers on the board go into their default power-on condition,
which turns off all of the output ports.

The secondary "PWM Worker" Picos on these boards add yet another layer
of protection, which is that they *also* have their own software
timers that they apply to every port.  The main Pico sends the PWM
Worker Picos its settings for the flipper logic/chime logic timers,
so that the secondary Picos can apply their own time limitation to
the ports.  So even if the main Pico stops working and all of the
other fail-safe measures somehow don't kick in, the ports controlled
by the secondary Picos are still protected by their own independent
timers.

Nothing is quite as perfectly predictable as a dedicated hardware
timer like on the old Chime boards, but I've tried to carefully design
the new system to be as close as possible.  The benefit is that
omitting the hardware timers saves a lot of board space, parts cost,
and assembly work.  The timer circuits required about ten additional
components per output port, which is why I could only fit 8 output
ports on each Chime board.  I think this new design comes very close
to the same level of protection, at lower cost, and with greater
flexibility (in that each port's protection parameters can be
individually configured).

## Design notes

The material below explains some of my design decisions in creating
these boards.  This won't be of any practical interest if you're just
looking to build the boards for your pin cab, but it might be useful
as background information if you're looking to create new boards of
your own, so you can weigh what went into my decisions against your
own priorities.

### Polarized and keyed connectors

All of the connectors use polarized headers and plugs, which are
designed so that you can only insert the plug in the correct
orientation.  In addition, the connectors across the two boards are
"keyed" to make it impossible (or at least difficult) to insert a plug
into the wrong connector.  Each keyed header has a non-connected pin
marked "X" on the silkscreen.  On the pin header, this pin can be
snipped, to create a blank space in the header; then, the
corresponding position can be filled with a keying pin on the plug.
The keying pin fills the socket so that you can't plug it into a
header with a pin at that position.  Since the keying pin is in a
different position for each repeated header, this prevents you from
accidentally plugging a plug into the wrong header - it will only fit
the header with the snipped pin in the matching key-pin position.

Snipping the keying pins and filling the corresponding plug positions
is optional, but if you skip that, the keying protection obviously
doesn't work.  The polarized connectors will still prevent plugging in
a connector backwards, at least.

### I2C pull-ups

The I2C bus lines (SDA, SCL) require pull-up resistors to VCC, from
about 1K ohm minimum, to a maximum that depends on the total
capacitance of all devices on the bus (300ns/C, where C is the sum of
the bus capacitances over all attached devices).  If we assume that
the minimum bus capacitance in practice is about 20pF, the high end of
the resistance range is about 15K ohms.

In an ordinary self-contained circuit board, we'd just figure the
total bus capacitance of the design and set the resistors accordingly.
In this case, though, we have a slight complication, which is that
Adafruit boards come with their own built-in pull-ups, at 10K on each
board.  When both boards are installed, these combine in parallel for
5K effective pull-up resistance on each line.  The big complication is
that we'd like to consider the modules optional, so the user might
install both, one, or neither.  We also want to allow the user to
connect at least a few boards on the QWIIC port, and we should
probably assume that each of those will come with its own 10K
resistors.  So we should choose a pull-up size that will work in any
of these case.  The best bet seems to be to use a weak pull-up
on the board, at the high end of the valid resistance range, which
gives us 15K.  With a basic configuration with both Adafruit modules
installed, this yields a total resistance of 3.75K.  And it allows
installing seven more QWIIC modules with 10K resistance each before
the total falls below the minimum 1K.

### Peripheral device power

The 3.3V power supply to the peripheral devices (ADS1115, LIS3DH) is
provided through the Pico's 3.3V regulator, switched (high-side)
through a PNP transistor.  The PNP switch is controlled by a GPIO line
on the Pico.  On the schematic, this switched 3.3V power rail is
labeled 3V3_PERIPHERAL.

The point of powering the peripherals through a switched connection to
the main Pico 3.3V regulator is to allow the main Pico to power-cycle
all of the peripherals under software control.  This is meant to
improve overall robustness by allowing the Pico software to power
cycle everything during a Pico software reset, to ensure that all of
the external hardware is restored to initial power-on conditions.
It's not unheard of for I2C chips to get into error/fault states that
can only be cleared with a power cycle.  I haven't actually run into
any such problems with any of the chips used on this board, but the
reset capability still seems worth including as a fail-safe, since
manually power cycling the whole board could be quite inconvenient in
a pin cab setup where the board is installed inside the cabinet.

The I2C pull-ups are connected to 3V3_PERIPHERAL rather than the main
Pico 3.3V power.  This is intentional: it's to ensure that we don't
feed power into any of the peripherals through their SDA/SCL pins
while their main supply power from 3V3_PERIPHERAL is at 0V, during one
of our software-controlled power cycles.  Some chips can't tolerate
voltage on logic pins above VDD, so it's safest to turn off the
SDA/SCL pull-ups whenever the peripheral VDD is cut off.

### Pico hard resets

A RESET button is positioned adjacent to each Pico, to force the Pico
to reboot.  This doesn't power-cycle the Pico; it just grounds the RUN
pin, which initiates the equivalent of a power-on reset.

Each auxiliary Pico's RUN pin is connected in parallel to an NPN
switch that grounds RUN (resetting the Pico) when the
/PERIPHERAL_POWER_ENABLE signal is HIGH.  This allows the main Pico to
reset all of the auxiliary Picos under software control, at the same
time that it resets all of its other peripherals via the peripheral
power PNP switch.  This extends the software-controlled peripheral
reset capability to the aux Picos even when they're getting power from
their USB ports.  (It was also undesirable to power them through the
3V3_PERIPHERAL network, since they have relatively high power draw
that might have required a bigger PNP switch, and because their
regulators are more efficient with 5V supplies.)

### Pico AGND connected to GND

The Pico AGND (analog ground) pin is connected directly to the main
ground plane on the board.  The Pico data sheet allows that this is
acceptable "if the ADC is not used or ADC performance is not
critical", but it's conspicuously silent on what you should do instead
if the ADC *is* used and you *do* care about its performance.  The
authors probably felt that it's too large a subject to address
adequately within the confines of the data sheet, and left it to the
reader to do their own research as needed.  I haven't done that
research myself, so I just went with the naive approach of connecting
the AGND pin straight through to the main ground plane.

Which I think will be fine for our purposes.  Pinscape does use the
ADC - for plunger input, if the plunger sensor is one of the types
with an analog output line.  But ADC performance isn't exactly
"critical" for most of these.  The one plunger type where ADC
performance is pretty important is the potentiometer-based plunger,
but for that case, we don't have to use the Pico ADC at all since we
have the superior ADS1115 instead.  That should yield better results
than the Pico's on-board ADC can produce even under ideal conditions.

If any analog engineers are reading this and want to weigh in on a
better AGND wiring plan, I'd be interested in hearing any suggestions.

### Modules for accelerometer and ADC

It's impossible today to buy an in-production accelerometer chip in a
hand-solderable package.  All of the chips currently on the market are
in tiny SMD packages meant to be handled by pick-and-place machines,
not by human hands.  And while there are a few ADC and PWM chips still
made in through-hole packages, the available options are too limiting
for our purposes; all of the good options in those categories are
SMD-only.

My solution, to satisfy the DIY imperative for these boards, was to
use "modules" for these cases.  The design has plug-in slots for
Adafruit breakout boards for an LIS3DH accelerometer and an ADS1115
ADC.  I chose the Adafruit boards because they're reasonably priced,
well designed, and well documented, and Adafruit is a reliable company
that tends to keep their boards in production for many years.

Using breakout boards instead of the raw chips raises the build cost
slightly, but not by much when you consider that the breakout boards
also include all of the supporting components (capacitors and
resistors), and that they eliminate the extra cost you'd incur if you
had to buy the tools and supplies for doing the SMD soldering
yourself.  They also eliminate the risk that the soldering job goes
wrong, which is definitely non-zero with tiny SMD parts.  I think most
people who want to assemble these boards by hand will find the small
added cost well worth it for the savings in time and effort and
uncertainty.

### Shift register button inputs

This board uses 74HC165 shift registers for the button inputs.  The
Pico doesn't have enough native GPIO ports to allow connecting buttons
directly to GPIOs, as the original Pinscape KL25Z expansion boards
did, so we need some additional hardware to let the Pico read more
digital inputs than it has GPIO ports.  The 74HC165 is a convenient
way to do this.  Each 74HC165 has four input ports that the Pico
can read serially through GPIO ports.  What's more, multiple 74HC165
chips can be strung together in a daisy chain, without requiring any
more GPIO ports on the Pico.

There are other chips that can accomplish the same thing, including
"GPIO expander" chips like PCA9555.  What makes 74HC165 particularly
good at the job is that the Pico can read its inputs at extremely high
speeds, clocking in serial bits in the megahertz range.  This allows
the Pico to scan the full set of button ports every 10 to 20 microseconds,
for essentially zero latency sampling on all button inputs.
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

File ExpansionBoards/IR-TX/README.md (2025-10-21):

# IR Transmitter for Pinscape Pico Expansion Boards

As with the IR Receiver function, the expansion boards are designed to
use a "satellite" IR Transmitter, connected to the main expansion board
with a cable, so that you can locate the transmitter some distance
from the main expansion boards.  This lets you position the transmitter
somewhere in line-of-sight to the TV or other devices that you want to
control with it, regardless of where the expansion board itself is
located.

Unlike the IR Receiver, though, the IR Transmitter doesn't have its
own circuit board design.  This is because the transmitter only
requires a single part, an IR LED.  I figured that there wasn't any
point in making everyone go to the trouble and expense of ordering a
separate circuit board that would hold just this one part, given that
it's really just as easy to solder wires directly to the LED.

## Parts

As of this writing, the BOM (the Bill of Materials, or parts list) has
two options for the IR LED: TSAL6400, or VSLB4940.  You'll find these
listed in the BOMs for the DIY-Friendly Main board and the Pro board.
They're not assigned reference designators ("R3", "IC7", etc) because
they don't get soldered directly to the expansion boards - as mentioned above,
they're connected with cables as satellite parts.  You can use either
of the listed parts (TSAL6400, VSLB4940) interchangeably - they'll
both work the same way without making any changes to the expansion
boards.  The VSLB4940 is a newer device with slightly better specs
than the TSAL6400, so that's the one I'd go with, assuming that
price and availability are similar.
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

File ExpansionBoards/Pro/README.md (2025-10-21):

# Pinscape Pico "Pro" Expansion Board

This is a set of EAGLE plans for an all-in-one expansion board for
Pinscape Pico.  It includes all of the I/O ports and on-board
peripherals needed for a high-end virtual pinball cabinet, all in a
single board.

I refer to this as the "Pro" board, because it uses small-pitch SMD
parts that make it difficult to assemble by hand.  It's best suited
for robotic assembly, which probably puts it out of reach for DIY
builds.  Factory assembly of a large board like this is usually only
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

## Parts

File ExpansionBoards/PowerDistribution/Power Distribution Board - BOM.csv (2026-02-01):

Qty | Value | Parts | Description | PARTNO | Comments | ExtDescription
1 | LED 5mm Blue | LED1 | LED, 5mm, blue | C503B-BCN-CV0Z0462 |  | LED, 5mm, blue (LED1)
1 | 0.1uF | C2 | Capacitor, ceramic, 0.1uF, radial, 2.54mm lead pitch | K104K15X7RF5TL2 |  | Capacitor, ceramic, 0.1uF, radial, 2.54mm lead pitch (C2)
1 | 1.1K | R2 | Resistor, 1.1K, axial, 2mm x 4mm | MFR-12FTF52-1K1 |  | Resistor, 1.1K, axial, 2mm x 4mm (R2)
1 | 1uF | C1 | Capacitor, Tantalum, 1uF, radial, 5mm lead pitch | TAP105K035CRS |  | Capacitor, Tantalum, 1uF, radial, 5mm lead pitch (C1)
1 | 2.4K/1W | R1 | Resistor, 2.4K, 1W, axial, 3mm x 9mm | 279-RR02J2K4TB |  | Resistor, 2.4K, 1W, axial, 3mm x 9mm (R1)
1 | MicroFit Hdr 2P | J2 | Molex Micro-Fit+ vertical header, 2 Ckt, black | 538-216571-1002 |  | Molex Micro-Fit+ vertical header, 2 Ckt, black (J2)
1 | MicroFit Plug 2P | PLUG_J2 | Molex Micro-Fit+ wire housing, 2 Ckt, black | 538-215759-1002 |  | Molex Micro-Fit+ wire housing, 2 Ckt, black (PLUG_J2)
1 | MicroFit Hdr 4P | J7 | Molex Micro-Fit+ vertical header, 4 Ckt, black | 538-216571-1004 |  | Molex Micro-Fit+ vertical header, 4 Ckt, black (J7)
1 | MicroFit Plug 4P | PLUG_J7 | Molex Micro-Fit+ wire housing, 4 Ckt, black | 538-215759-1004 |  | Molex Micro-Fit+ wire housing, 4 Ckt, black (PLUG_J7)
1 | MicroFit Hdr 3P | J8 | Molex Micro-Fit+ vertical header, 3 Ckt, black | 538-216571-2003 |  | Molex Micro-Fit+ vertical header, 3 Ckt, black (J8)
1 | MicroFit Plug 3P | PLUG_J8 | Molex Micro-Fit+ wire housing, 3 Ckt, black | 538-215759-1003 |  | Molex Micro-Fit+ wire housing, 3 Ckt, black (PLUG_J8)
1 | MicroFit Hdr 3P | J16 | Molex Micro-Fit+ vertical header, 3 Ckt, red | 538-216571-1023 |  | Molex Micro-Fit+ vertical header, 3 Ckt, red (J16)
1 | MicroFit Plug 3P | PLUG_J16 | Molex Micro-Fit+ wire housing, 3 Ckt, red | 538-215759-1023 |  | Molex Micro-Fit+ wire housing, 3 Ckt, red (PLUG_J16)
1 | MicroFit Hdr 5P | J1 | Molex Micro-Fit+ vertical header, 5 Ckt, black | 538-216571-2005 |  | Molex Micro-Fit+ vertical header, 5 Ckt, black (J1)
1 | MicroFit Plug 5P | PLUG_J1 | Molex Micro-Fit+ wire housing, 5 Ckt, black | 538-215759-1005 |  | Molex Micro-Fit+ wire housing, 5 Ckt, black (PLUG_J1)
1 | MicroFit Hdr 5P | J3 | Molex Micro-Fit+ vertical header, 5 Ckt, red | 538-216571-1025 |  | Molex Micro-Fit+ vertical header, 5 Ckt, red (J3)
1 | MicroFit Plug 5P | PLUG_J3 | Molex Micro-Fit+ wire housing, 5 Ckt, red | 538-215759-1025 |  | Molex Micro-Fit+ wire housing, 5 Ckt, red (PLUG_J3)
1 | MicroFit Hdr 5P | J4 | Molex Micro-Fit+ vertical header, 5 Ckt, blue | 538-216571-1035 |  | Molex Micro-Fit+ vertical header, 5 Ckt, blue (J4)
1 | MicroFit Plug 5P | PLUG_J4 | Molex Micro-Fit+ vertical header, 5 Ckt, blue | 538-215759-1035 |  | Molex Micro-Fit+ vertical header, 5 Ckt, blue (PLUG_J4)
1 | MicroFit Hdr 5P | J5 | Molex Micro-Fit+ vertical header, 5 Ckt, yellow | 538-216571-1045 |  | Molex Micro-Fit+ vertical header, 5 Ckt, yellow (J5)
1 | MicroFit Plug 5P | PLUG_J5 | Molex Micro-Fit+ vertical header, 5 Ckt, yellow | 538-215759-1045 |  | Molex Micro-Fit+ vertical header, 5 Ckt, yellow (PLUG_J5)
35 | MicroFit Crimp Pin |  | Molex Micro-Fit+ crimp pins, tin plating, 24-20 AWG | 206460-0021 | Select according to desired wire gauge | Molex Micro-Fit+ crimp pins, tin plating, 24-20 AWG ()
35 | MicroFit Crimp Pin |  | Molex Micro-Fit+ crimp pins, tin plating, 18 AWG | 206460-0031 | Select according to desired wire gauge | Molex Micro-Fit+ crimp pins, tin plating, 18 AWG ()
1 | Mini-Fit Jr. Hdr 24P | J6 | Molex Mini-Fit Jr. vertical header, 24 Ckt | 44206-0007 |  | Molex Mini-Fit Jr. vertical header, 24 Ckt (J6)
1 | 1N4007 | D1 | Diode, general-purpose rectifier, through-hole DO-41 package | 1N4007 |  | Diode, general-purpose rectifier, through-hole DO-41 package (D1)
2 | 270R | R3, R4 | Resistor, 270 Ohm, axial, 2mm x 4mm | CFR25SJT-26-270R |  | Resistor, 270 Ohm, axial, 2mm x 4mm (R3, R4)
1 | 350211-1 | J9 | Mate-N-Lok PCB header, 4-pos straight (PC ATX floppy disk connector, male) | 571-3502111 |  | Mate-N-Lok PCB header, 4-pos straight (PC ATX floppy disk connector, male) (J9)
1 | 571-6404452 | J13 | MTA-156 pin header, 2 position | 571-6404452 |  | MTA-156 pin header, 2 position (J13)
1 | 571-3-643819-2 | PLUG_J13 | MTA-156 wire housing, IDC, 2 position, 22AWG | 571-3-643819-2 |  | MTA-156 wire housing, IDC, 2 position, 22AWG (PLUG_J13)
1 | 571-6404453 | J15 | MTA-156 pin header, 3 position | 571-6404453 |  | MTA-156 pin header, 3 position (J15)
1 | 571-3-643819-3 | PLUG_J15 | MTA-156 wire housing, IDC, 3 position, 22AWG | 571-3-643819-3 |  | MTA-156 wire housing, IDC, 3 position, 22AWG (PLUG_J15)
1 | 571-640445-5 | J12 | MTA-156 pin header, 5 position | 571-640445-5 |  | MTA-156 pin header, 5 position (J12)
1 | 571-3-643819-5 | PLUG_J12 | MTA-156 wire housing, IDC, 5 position, 22AWG | 571-3-643819-5 |  | MTA-156 wire housing, IDC, 5 position, 22AWG (PLUG_J12)
1 | 571-640445-4 | J14 | MTA-156 pin header, 4 position | 571-640445-4 |  | MTA-156 pin header, 4 position (J14)
1 | 571-3-643819-4 | PLUG_J14 | MTA-156 wire housing, IDC, 4 position, 22AWG | 571-3-643819-4 |  | MTA-156 wire housing, IDC, 4 position, 22AWG (PLUG_J14)
2 | 571-640445-6 | J10, J11 | MTA-156 pin header, 6 position | 571-640445-6 |  | MTA-156 pin header, 6 position (J10, J11)
2 | 571-3-643819-6 | PLUG_J10, PLUG_J11 | MTA-156 wire housing, IDC, 6 position, 22 AWG | 571-3-643819-6 |  | MTA-156 wire housing, IDC, 6 position, 22 AWG (PLUG_J10, PLUG_J11)
1 | 571-640445-8 | J17 | MTA-156 pin header, 8 position | 571-640445-8 |  | MTA-156 pin header, 8 position (J17)
1 | 571-3-643819-8 | PLUG_J17 | MTA-156 wire housing, IDC, 8 position, 22 AWG | 571-3-643819-8 |  | MTA-156 wire housing, IDC, 8 position, 22 AWG (PLUG_J17)
1 | 206832-0601 | J18 | Molex Micro-Fit+ vertical header, 6-position, dual row, black | 206832-0601 |  | Molex Micro-Fit+ vertical header, 6-position, dual row, black (J18)
1 | 206461-0600 | PLUG_J18 | Molex Micro-Fit+ receptacle housing, 6-position, dual-row, black | 206461-0600 |  | Molex Micro-Fit+ receptacle housing, 6-position, dual-row, black (PLUG_J18)
1 | 224246-0620 | J19 | Molex Micro-Fit+ versa color vertical header, 6-position, dual row, red | 224246-0620 |  | Molex Micro-Fit+ versa color vertical header, 6-position, dual row, red (J19)
1 | 206461-0602 | PLUG_J19 | Molex Micro-Fit+ versa color receptacle housing, 6-position, dual row, red | 206461-0602 |  | Molex Micro-Fit+ versa color receptacle housing, 6-position, dual row, red (PLUG_J19)
1 | AHQSS105DM2FA0G | K1 | Relay, 5V coil, 16A switch contacts, contact form A | 523-AHQSS105DM2FA0G |  | Relay, 5V coil, 16A switch contacts, contact form A (K1)
1 | LM338T/NOPB | U3 | Voltage regulator, LM338T/NOPB | LM338T/NOPB |  | Voltage regulator, LM338T/NOPB (U3)
1 | SL22_7R010 | RT1 | Inrush Current Limiter, 22mm, 7 ohms, 10A | 995-SL22-7R010 |  | Inrush Current Limiter, 22mm, 7 ohms, 10A (RT1)
3 | B41231B8828M000 | C3, C4, C5 | Aluminum Electrolytic Capacitor, 8200uf, 63, Snap-in, 10mm lead spacing | B41231B8828M000 |  | Aluminum Electrolytic Capacitor, 8200uf, 63, Snap-in, 10mm lead spacing (C3, C4, C5)
1 | 2N2222A | Q1 | NPN Transistor, TO-92, 40V, 600mA, 2N2222A | 637-2N2222A |  | NPN Transistor, TO-92, 40V, 600mA, 2N2222A (Q1)
1 | IRF9530 | Q2 | MOSFET, P-Channel, TO-220, 100V, 14A, IRF9530 | 942-IRF9530NPBF |  | MOSFET, P-Channel, TO-220, 100V, 14A, IRF9530 (Q2)
1 | 470R | R5 | Resistor, 470 Ohm, axial, 2mm x 4mm | CFR25SJT-52-470R |  | Resistor, 470 Ohm, axial, 2mm x 4mm (R5)
1 | 8.2K 1W | R6 | Resistor, 8.2K, 1/4W, axial, 2mm x 7mm | CFR-25JT-52-8K2 |  | Resistor, 8.2K, 1/4W, axial, 2mm x 7mm (R6)
1 | 2.2K | R7 | Resistor, 2.2K, axial, 2mm x 4mm | CFR25SJT-26-2K2 |  | Resistor, 2.2K, axial, 2mm x 4mm (R7)
1 | LTV-817 | OK1 | Transistor Output Optocoupler | LTV-817-A |  | Transistor Output Optocoupler (OK1)
1 | LED 5mm Red | LED2 | LED, 5mm, red | C503B-RAN-CZ0C0AA2 |  | LED, 5mm, red (LED2)
1 | 150R | R8 | Resistor, 150 Ohm, axial, 2mm x 7mm | MFR-25FTF52-150R |  | Resistor, 150 Ohm, axial, 2mm x 7mm (R8)
1 | LED 5mm Yellow | LED3 | LED, 5mm, yellow | 151034YS03000 |  | LED, 5mm, yellow (LED3)
1 | 510R3 1/4W | R9 | Resistor, 510 Ohm, 1/4W, axial, 2mm x 7mm | MFR-25FRF52-510R |  | Resistor, 510 Ohm, 1/4W, axial, 2mm x 7mm (R9)
1 | LED 5mm Green | LED4 | LED, 5mm, green | LTL-4234 |  | LED, 5mm, green (LED4)
1 | 1.1K 1/2W | R10 | Resistor, 1.1K, 1/2W, axial, 2mm x 7mm | MF0207FTE52-1K1 |  | Resistor, 1.1K, 1/2W, axial, 2mm x 7mm (R10)
1 | LED 5mm Orange | LED5 | LED, 5mm, orange | WP7113ED |  | LED, 5mm, orange (LED5)
1 | 220R | R11 | Resistor, 220 Ohm, axial, 2mm x 7mm3 | MFR50SFTE52-220R |  | Resistor, 220 Ohm, axial, 2mm x 7mm3 (R11)

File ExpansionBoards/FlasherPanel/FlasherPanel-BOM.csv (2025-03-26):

Qty | Value | Parts | Description | PARTNO | Notes | ExtDescription
1 | 0.1" PIN-HD 2X8 | J1 | Shrouded pin header 0.1" 2x8 | 737-BHR-16-VUA |  | Shrouded pin header 0.1" 2x8 (J1)
1 | 0.1" IDC 2X8 | PLUG_J1 | IDC housing, 0.1", 2x8 | 737-FCS-16-SG |  | IDC housing, 0.1", 2x8 (PLUG_J1)
5 | RGB-LED | U1, U2, U3, U4, U5 | LED, RGB, 350 mA, 6070 case, 6 pin, Xinglight | XL-HD6070RGBC-A46L-BD | Substitutes: Amazon ASIN B0CXF5YTQ7, B01DBZIW8W | LED, RGB, 350 mA, 6070 case, 6 pin, Xinglight (U1, U2, U3, U4, U5)
5 | 5.6Ohm/1W | R1, R4, R7, R10, R13 | Resistor, 5.6 Ohm, 1W, SMD 2512 | 603-AC2512FK-075R6L |  | Resistor, 5.6 Ohm, 1W, SMD 2512 (R1, R4, R7, R10, R13)
5 | 5.1Ohm/1W | R2, R5, R8, R11, R14 | Resistor, 5.1 Ohm, 1W, SMD 2512 | 603-RC2512FK-075R1L |  | Resistor, 5.1 Ohm, 1W, SMD 2512 (R2, R5, R8, R11, R14)
5 | 9.1Ohm/1W | R3, R6, R9, R12, R15 | Resistor, 9.1 Ohm, 2W, SMD 2512 | CRM2512-JW-9R1ELF |  | Resistor, 9.1 Ohm, 2W, SMD 2512 (R3, R6, R9, R12, R15)

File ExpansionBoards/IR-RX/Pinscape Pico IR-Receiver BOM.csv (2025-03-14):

Qty | Value | Parts | Description | PARTNO | Comments | ExtDescription
1 | 150nF | C1 | Capacitor, ceramic, 150nF, radial, 2.5mm lead pitch | K154K20X7RF53H5 |  | Capacitor, ceramic, 150nF, radial, 2.5mm lead pitch (C1)
1 | 220R | R1 | Resistor, 220 Ohm, axial, 2mm 4 xmm | MFR25SFTF52-220R |  | Resistor, 220 Ohm, axial, 2mm 4 xmm (R1)
1 | TSOP38438 | U1 | IR receiver/demodulator, Vishay TSOP38438 | TSOP38438 |  | IR receiver/demodulator, Vishay TSOP38438 (U1)
1 | MICROMATCH-4PIN | J1 | Connector, Micro-MaTch female-on-board, 4 pin, top entry | 215079-4 |  | Connector, Micro-MaTch female-on-board, 4 pin, top entry (J1)
1 | MICROMATCH-4PIN | PLUG_J1 | Plug for J1, Micro-MaTch male-on-wire, 4 pin, IDC | 215083-4 |  | Plug for J1, Micro-MaTch male-on-wire, 4 pin, IDC (PLUG_J1)

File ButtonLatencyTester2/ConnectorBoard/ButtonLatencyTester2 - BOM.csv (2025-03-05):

Qty | Value | Parts | Description | MOUSER_PART_NUMBER | ExtDescription
4 | 130R | R1, R2, R3, R4 | Resistor, 130 Ohm, axial, 2mm x 4mm | MF0204FTE52-130R | Resistor, 130 Ohm, axial, 2mm x 4mm (R1, R2, R3, R4)
4 | 1725672 | J1, J2, J3, J4 | Phoenix Contact PCB terminal block, 4 way, 26-20 AWG, 2.54mm pitch | 651-1725672 | Phoenix Contact PCB terminal block, 4 way, 26-20 AWG, 2.54mm pitch (J1, J2, J3, J4)
1 | 61302011821 | J5 | Socket Header, 20 position, 2.54mm pitch | 710-61302011821 | Socket Header, 20 position, 2.54mm pitch (J5)
8 | PC817 | OK1, OK2, OK3, OK4, OK5, OK6, OK7, OK8 | Optocoupler PC817 / LTV-817, DIP | PC817X2NSZ9F | Optocoupler PC817 / LTV-817, DIP (OK1, OK2, OK3, OK4, OK5, OK6, OK7, OK8)

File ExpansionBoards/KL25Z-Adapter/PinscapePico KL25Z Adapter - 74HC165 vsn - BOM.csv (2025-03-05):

Qty | Value | Parts | Description | PARTNO | Comments | ExtDescription
1 | Pico-H | RASPBERRY_PI_PICO | Raspberry Pi Pico w/pin headers installed | SC0917 |  | Raspberry Pi Pico w/pin headers installed (RASPBERRY_PI_PICO)
2 | 0.1" SOCK-HD 1X20 | RASPBERRY_PI_PICO | Socket Header, 20 position, 2.54mm pitch | 61302011821 |  | Socket Header, 20 position, 2.54mm pitch (RASPBERRY_PI_PICO)
6 | 0.1uF | C1, C2, C3, C4, C5, C6 | Capacitor, 0.1uF, ceramic, SMD 1206 | 1206B104K500CT |  | Capacitor, 0.1uF, ceramic, SMD 1206 (C1, C2, C3, C4, C5, C6)
1 | 30R | R1 | Resistor, 30 Ohm, SMD 1206 | CR1206-FX-30R0ELF |  | Resistor, 30 Ohm, SMD 1206 (R1)
1 | 39R | R2 | Resistor, 39 Ohm, SMD 1206 | CR1206-FX-39R0ELF |  | Resistor, 39 Ohm, SMD 1206 (R2)
1 | 130R | R3 | Resistor, 130 Ohm, SMD 1206 | CR1206-FX-1300ELF |  | Resistor, 130 Ohm, SMD 1206 (R3)
2 | 10K | R4, R5 | Resistor, 10K, SMD 1206 | CR1206-JW-103ELF |  | Resistor, 10K, SMD 1206 (R4, R5)
2 | 4k | R6, R7 | Resistor, 4K, SMD 1206 | RN73R2BTTD4001B25 |  | Resistor, 4K, SMD 1206 (R6, R7)
1 | ADS1115IDGSR | IC5 | 16-Bit 860SPS 4-Ch Delta-Sigma ADC With PGA, Oscillator, Vref, Comparator, and I2C | 595-ADS1115IDGSR |  | 16-Bit 860SPS 4-Ch Delta-Sigma ADC With PGA, Oscillator, Vref, Comparator, and I2C (IC5)
6 | 10K 4POS | RN1, RN2, RN3, RN4, RN6, RN8 | Chip Resistor Array 4 Single Resistor, 10K, SMD 0603 x 4 | WA06X103JTL | Substitute: 742C083103JP | Chip Resistor Array 4 Single Resistor, 10K, SMD 0603 x 4 (RN1, RN2, RN3, RN4, RN6, RN8)
1 | RGB-LED-CA | LED1 | RGB LED, 5mA, common anode, SMD 3528 package | 150141M173100 |  | RGB LED, 5mA, common anode, SMD 3528 package (LED1)
1 | 0.1" SOCK-HD 2x6 | FRDM1 | Socket header, 0.1" pitch, 2x6 position | 61301221821 | FRDM-KL25Z header socket | Socket header, 0.1" pitch, 2x6 position (FRDM1)
2 | 0.1" SOCK-HD 2x8 | FRDM1 | Socket header, 0.1" pitch, 2x8 position | 61301621821 | FRDM-KL25Z header socket | Socket header, 0.1" pitch, 2x8 position (FRDM1)
1 | 0.1" SOCK-HD 2x10 | FRDM1 | Socket header, 0.1" pitch, 2x10 position | 61302021821 | FRDM-KL25Z header socket | Socket header, 0.1" pitch, 2x10 position (FRDM1)
1 | LIS3DHTR | IC4 | Accelerometer 3-Axis 2g/16g 1.8V LGA16 STMicroelectronics LIS3DHTR Accelerometer IC, 3-axis, I2C, SPI 1.71 3.6 V, 16-Pin LGA | 511-LIS3DHTR |  | Accelerometer 3-Axis 2g/16g 1.8V LGA16 STMicroelectronics LIS3DHTR Accelerometer IC, 3-axis, I2C, SPI 1.71 3.6 V, 16-Pin LGA (IC4)
1 | PCA9555APW,118 | IC6 | NXP - PCA9555APW,118 - I/O EXPANDER, 16BIT, 400KHZ, TSSOP-24 | 771-PCA9555APW118 |  | NXP - PCA9555APW,118 - I/O EXPANDER, 16BIT, 400KHZ, TSSOP-24 (IC6)
3 | SN74HC165DR | IC1, IC2, IC3 | 8-Bit Parallel-Load Shift Registers | 595-SN74HC165DR |  | 8-Bit Parallel-Load Shift Registers (IC1, IC2, IC3)
1 | TS-1187A-B-A-B | SW1 | Pushbutton switch, SPST, SMD | TS18-5-25-SL-260-SMT-TR |  | Pushbutton switch, SPST, SMD (SW1)

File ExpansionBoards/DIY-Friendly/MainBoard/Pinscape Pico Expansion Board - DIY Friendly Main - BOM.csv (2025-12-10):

Qty | Value | Parts | Description | PARTNO | Comments | ExtDescription
2 | B3F-1000 | S1, S2 | Omron pushbutton switch, SPST, through-hole | B3F-1000 |  | Omron pushbutton switch, SPST, through-hole (S1, S2)
4 | 0.1" SOCK-HD 1X6 | JP1, JP2, JP3, JP4 | Pin Socket Header, 1x6 | 61300611821 |  | Pin Socket Header, 1x6 (JP1, JP2, JP3, JP4)
1 | 0.1" PIN-HD 1X3 | J12 | Pin Header, 1x3 | G800WC305018EU | Generic part; use any generic 0.1" pin strip, 3-position or breakaway/cut-to-length type | Pin Header, 1x3 (J12)
4 | 0.1" SOCK-HD 1X20 | PICO1, PICO2 | Socket Header, 20 position, 2.54mm pitch | 61302011821 |  | Socket Header, 20 position, 2.54mm pitch (PICO1, PICO2)
2 | Pico-H | PICO1, PICO2 | Raspberry Pi Pico w/pin headers installed | SC0917 |  | Raspberry Pi Pico w/pin headers installed (PICO1, PICO2)
4 | MTA100-10PIN | J5, J6, J7, J8 | 10 way MTA100 straight friction lock header | 1-640456-0 |  | 10 way MTA100 straight friction lock header (J5, J6, J7, J8)
4 | MTA100-10PIN-24AWG | PLUG_J5, PLUG_J6, PLUG_J7, PLUG_J8 | Plug for J5 J6 J7 J8, 10p IDC housing 24 AWG | 4-644563-0 |  | Plug for J5 J6 J7 J8, 10p IDC housing 24 AWG (PLUG_J5, PLUG_J6, PLUG_J7, PLUG_J8)
1 | 100R | R9 | Resistor, 100 Ohm, axial, 2mm 4 xmm | MFR-12FTE52-100R |  | Resistor, 100 Ohm, axial, 2mm 4 xmm (R9)
11 | 100nF | C1, C3, C5, C7, C9, C11, C13, C15, C16, C17, C18 | Capacitor, ceramic, 0.1uF, radial, 2.5mm lead pitch | K104K15X7RF5TL2 |  | Capacitor, ceramic, 0.1uF, radial, 2.5mm lead pitch (C1, C3, C5, C7, C9, C11, C13, C15, C16, C17, C18)
4 | 10K | R12, R13, R20, R22 | Resistor, 10K, axial, 2mm x 4mm | MFR-12FRF52-10K |  | Resistor, 10K, axial, 2mm x 4mm (R12, R13, R20, R22)
2 | 10R | R10, R11 | Resistor, 10 Ohm, axial, 2mm 4 xmm | MFR25SFTE52-10R |  | Resistor, 10 Ohm, axial, 2mm 4 xmm (R10, R11)
2 | 15K | R29, R30 | Resistor, 15K, axial, 2mm x 4mm | MFR25SFRF52-15K |  | Resistor, 15K, axial, 2mm x 4mm (R29, R30)
1 | 1K | R26 | Resistor, 1K, axial, 2mm x 4mm | MF0204FTE52-1K |  | Resistor, 1K, axial, 2mm x 4mm (R26)
2 | 1N4148 | D3, D4 | Diode, 1N4148, axial | 1N4148-T50A |  | Diode, 1N4148, axial (D3, D4)
1 | 2.2k | R33 | Resistor, 2.2K, axial, 2mm x 4mm | MF0204FTE52-2K2 |  | Resistor, 2.2K, axial, 2mm x 4mm (R33)
1 | MICROMATCH-4PIN | J10 | Connector, Micro-MaTch female-on-board, 4 pin, top entry | 215079-4 |  | Connector, Micro-MaTch female-on-board, 4 pin, top entry (J10)
1 | MICROMATCH-4PIN | PLUG_J10 | Plug for J10, Micro-MaTch male-on-wire, 4 pin, IDC | 215083-4 |  | Plug for J10, Micro-MaTch male-on-wire, 4 pin, IDC (PLUG_J10)
1 | 22K | R28 | Resistor, 22K, axial, 2mm 4 xmm | MFR-12FTF52-22K |  | Resistor, 22K, axial, 2mm 4 xmm (R28)
1 | 240R | R18 | Resistor, 240 Ohm, axial, 2mm 4 4mm | MFR25SFTF52-240R |  | Resistor, 240 Ohm, axial, 2mm 4 4mm (R18)
1 | 2N2222A | Q16 | NPN transistor, 2N2222A, TO-92, 40V, 600mA | 637-2N2222A |  | NPN transistor, 2N2222A, TO-92, 40V, 600mA (Q16)
1 | 2N5195G | Q15 | PNP transistor, 2N5195G, TO-225-3, 80V, 4A | 2N5195G |  | PNP transistor, 2N5195G, TO-225-3, 80V, 4A (Q15)
1 | 2R5 | R31 | Resistor, 2.5 Ohm, 1%, axial, 2mm x 4mm | MFR-25FTE52-2R49 |  | Resistor, 2.5 Ohm, 1%, axial, 2mm x 4mm (R31)
1 | 0.1" PIN-HD 2X4 | J9 | Shrouded pin header 0.1" 2x4 | BHR-08-VUA |  | Shrouded pin header 0.1" 2x4 (J9)
1 | 0.1" IDC 2X4 | PLUG_J9 | IDC housing, 0.1", 2x4 | FCS-16-SG |  | IDC housing, 0.1", 2x4 (PLUG_J9)
1 | 0.1" PIN-HD 2X8 | J1 | Shrouded pin header 0.1" 2x8 | BHR-16-VUA |  | Shrouded pin header 0.1" 2x8 (J1)
1 | 0.1" IDC 2X8 | PLUG_J1 | IDC housing, 0.1", 2x8 | FCS-08-SG |  | IDC housing, 0.1", 2x8 (PLUG_J1)
1 | 360R | R21 | Resistor, 360 Ohm, axial, 2mm x 4mm | MFR-12FTF52-360R |  | Resistor, 360 Ohm, axial, 2mm x 4mm (R21)
2 | 4.7K | R32, R34 | Resistor, 4.7K, axial, 2mm x 4mm | MFR25SFRF52-4K7 |  | Resistor, 4.7K, axial, 2mm x 4mm (R32, R34)
7 | 4.7uF | C2, C4, C6, C8, C10, C12, C14 | Capacitor, ceramic, 4.7uF, radial, 2.5mm lead pitch | FG14X7R1E475KRT06 |  | Capacitor, ceramic, 4.7uF, radial, 2.5mm lead pitch (C2, C4, C6, C8, C10, C12, C14)
4 | 10K X 8 | R23, R24, R25, R27 | Resistor network, bussed, 10K, 9 pin, through-hole 0.1" pitch | 4609X-101-103LF |  | Resistor network, bussed, 10K, 9 pin, through-hole 0.1" pitch (R23, R24, R25, R27)
12 | 200R | R1, R2, R3, R4, R5, R6, R7, R8, R14, R15, R16, R17 | Resistor, 200 Ohm, axial, 2 mm x 4mm | MFR25SFRF52-200R | MOSFET gate driver resistor; gate drive current limit 60mA | Resistor, 200 Ohm, axial, 2 mm x 4mm (R1, R2, R3, R4, R5, R6, R7, R8, R14, R15, R16, R17)
0 | 4R7 | R1, R2, R3, R4, R5, R6, R7, R8, R14, R15, R16, R17 | Resistor, 4.7 Ohm, axial, 2 mm x 4mm | MF0204FTE52-4R7 | Alternate gate driver resistor; current limit 255mA, faster MOSFET switching, UCC27524 overload risk with high-capacitance MOSFET | Resistor, 4.7 Ohm, axial, 2 mm x 4mm (R1, R2, R3, R4, R5, R6, R7, R8, R14, R15, R16, R17)
0 | 47R | R1, R2, R3, R4, R5, R6, R7, R8, R14, R15, R16, R17 | Resistor, 47 Ohm, axial, 2 mm x 4mm | MFR25SFRF52-47R | Alternate gate driver resistor; current limit 2.5A, fastest MOSFET switching, UCC27524 overload risk with high-capacitance MOSFET | Resistor, 47 Ohm, axial, 2 mm x 4mm (R1, R2, R3, R4, R5, R6, R7, R8, R14, R15, R16, R17)
1 | RGB-LED-CA | LED2 | RGB LED, Through Hole 5mm, 4 leads, common anode | 521-8559F |  | RGB LED, Through Hole 5mm, 4 leads, common anode (LED2)
1 | 540R | R19 | Resistor, 540 Ohm, axial, 2 mm x 4mm | CFR-12JT-52-540R |  | Resistor, 540 Ohm, axial, 2 mm x 4mm (R19)
1 | MTA156-2PIN | J13 | MTA156 friction lock header, 3.96mm pitch, 2 position | 640445-2 |  | MTA156 friction lock header, 3.96mm pitch, 2 position (J13)
1 | MTA156-2PIN-22AWG | PLUG_J13 | MTA156 IDC housing, 2 pin, 22 AWG | 3-643819-2 |  | MTA156 IDC housing, 2 pin, 22 AWG (PLUG_J13)
1 | MTA156-5PIN | J3 | MTA156 friction lock header, 3.96mm pitch, 5 position | 640445-5 |  | MTA156 friction lock header, 3.96mm pitch, 5 position (J3)
1 | MTA156-5PIN-22AWG | PLUG_J3 | MTA156 IDC housing, 5 pin, 22 AWG | 3-643819-5 |  | MTA156 IDC housing, 5 pin, 22 AWG (PLUG_J3)
1 | MTA156-6PIN | J2 | MTA156 friction lock header, 3.96mm pitch, 6 position | 640445-6 |  | MTA156 friction lock header, 3.96mm pitch, 6 position (J2)
1 | MTA156-6PIN-22AWG | PLUG_J2 | MTA156 IDC housing, 6 pin, 22 AWG | 3-643819-6 |  | MTA156 IDC housing, 6 pin, 22 AWG (PLUG_J2)
1 | MTA156-9PIN | J4 | MTA156 friction lock header, 3.96mm pitch, 9 position | 640445-9 |  | MTA156 friction lock header, 3.96mm pitch, 9 position (J4)
1 | MTA156-9PIN-22AWG | PLUG_J4 | MTA156 IDC housing, 9 pin, 22 AWG | 3-640428-9 |  | MTA156 IDC housing, 9 pin, 22 AWG (PLUG_J4)
1 | MTA100-2PIN | J11 | MTA100 friction lock header, 2.54mm pitch, 2 position | 640454-2 |  | MTA100 friction lock header, 2.54mm pitch, 2 position (J11)
1 | MTA100-2PIN-24AWG | PLUG_J11 | MTA100 housing, 2 pin, 24 AWG | 3-643814-2 |  | MTA100 housing, 2 pin, 24 AWG (PLUG_J11)
1 | BC337-25 | Q13 | NPN transistor, BC337-25, TO-92, 45V, 800mA | BC337-25 |  | NPN transistor, BC337-25, TO-92, 45V, 800mA (Q13)
12 | IPP180N10N3GXKSA1 | Q1, Q2, Q3, Q4, Q5, Q6, Q7, Q8, Q9, Q10, Q11, Q12 | Power MOSFET, TO-220-3 (G-D-S pin ordering) | IPP180N10N3GXKSA1 | N-channel, TO-220-3, G-D-S pin ordering, min +/-20V V[gs][max]; example substitutes: FDPF08N10A, IRF540N | Power MOSFET, TO-220-3 (G-D-S pin ordering) (Q1, Q2, Q3, Q4, Q5, Q6, Q7, Q8, Q9, Q10, Q11, Q12)
1 | PC827 | IC13 | Sharp 2-channel optocoupler LTV-827 | LTV-827 |  | Sharp 2-channel optocoupler LTV-827 (IC13)
1 | JST-SR/SZ-4PIN | QWIIC1 | JST SR/SZ 4-position side entry header, SMD | SM04B-SRSS-TB(LF)(SN) | Old part number: SM04B-SRSS-TB(LF)(SN)(P) | JST SR/SZ 4-position side entry header, SMD (QWIIC1)
1 | S-80834CLY-B2-U | IC12 | Voltage detector, TO-92-3, active low CMOS out, 3.4V | S-80834CLY-B2-U | Substitute any S-808xxCLY-x2-U with 3.0 to 4.0 threshold voltage ('xx' in product code) | Voltage detector, TO-92-3, active low CMOS out, 3.4V (IC12)
1 | SB140-T | D1 | Schottky Diodes & Rectifiers 1.0A 40V, SB140-T, through-hole | SB140-T |  | Schottky Diodes & Rectifiers 1.0A 40V, SB140-T, through-hole (D1)
4 | SN74HC165N | IC14, IC15, IC16, IC17 | SN74HC165N 8-bit input shift register, through-hole | SN74HC165N |  | SN74HC165N 8-bit input shift register, through-hole (IC14, IC15, IC16, IC17)
1 | SN74HC74N | IC11 | SN74HC74NE4 dual flip-flop, through-hole | SN74HC74N | SN74HC74NE4 is equivalent | SN74HC74NE4 dual flip-flop, through-hole (IC11)
1 | 0.1" SOCK-HD 1X8 | J14 | Socket header, 8 position, 0.1" pitch, right-angle | SSQ-108-02-T-S-RA |  | Socket header, 8 position, 0.1" pitch, right-angle (J14)
6 | UCC27524P | IC1, IC2, IC3, IC4, IC5, IC6 | Dual 5A High-Speed Low-Side Power MOSFET Driver | UCC27524P |  | Dual 5A High-Speed Low-Side Power MOSFET Driver (IC1, IC2, IC3, IC4, IC5, IC6)
4 | ULN2803A | IC7, IC8, IC9, IC10 | Darlington NPN transistor array, 500mA/ch | ULN2803A |  | Darlington NPN transistor array, 500mA/ch (IC7, IC8, IC9, IC10)
1 | ADS1115 |  | Adafruit ADS1115 STEMMA module | 485-1085 |  | Adafruit ADS1115 STEMMA module ()
1 | LIS3DH |  | Adafruit LIS3DH STEMMA module | 485-2809 |  | Adafruit LIS3DH STEMMA module ()
1 | VSLB4940 |  | Vishay IR emitter, 940nm, T-1, VSLB4940 | VSLB4940 | IR emitter LED, connects to J11 for off-board placement | Vishay IR emitter, 940nm, T-1, VSLB4940 ()
0 | TSAL6400 |  | Vishay IR emitter, 940nm, T-1.75, TSAL6400 | TSAL6400 | IR emitter LED, connects to J11 for off-board placement (alternate, if VSLB4940 isn't available) | Vishay IR emitter, 940nm, T-1.75, TSAL6400 ()
1 | 641994-1 |  | MTA-100 keying plugs, 10-pack | 641994-1 | Optional, for connector keying, to prevent inserting a plug into the wrong header; part number shown is for a package of 10 plugs | MTA-100 keying plugs, 10-pack ()
1 | 641623-1 |  | MTA-156 keying plugs, 10-pack | 641623-1 | Optional, for connector keying, to prevent inserting a plug into the wrong header; part number shown is for a package of 10 plugs | MTA-156 keying plugs, 10-pack ()

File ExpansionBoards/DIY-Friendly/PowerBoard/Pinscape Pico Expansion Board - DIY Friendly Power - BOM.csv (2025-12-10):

Qty | Value | Parts | Description | PARTNO | Comments | ExtDescription
2 | B3F-1000 | S1, S2 | Omron pushbutton switch, SPST, through-hole | B3F-1000 |  | Omron pushbutton switch, SPST, through-hole (S1, S2)
1 | 0.1" PIN-HD 1X8-90 | J8 | Pin header, 0.1" pitch, 1x8, right angle | 10129379-908001BLF |  | Pin header, 0.1" pitch, 1x8, right angle (J8)
4 | 0.1" SOCK-HD 1X20 | PICO1, PICO2 | Socket Header, 20 position, 2.54mm pitch | 61302011821 |  | Socket Header, 20 position, 2.54mm pitch (PICO1, PICO2)
2 | Pico-H | PICO1, PICO2 | Raspberry Pi Pico w/pin headers installed | SC0917 |  | Raspberry Pi Pico w/pin headers installed (PICO1, PICO2)
4 | MTA100-10PIN | J4, J5, J6, J7 | MTA100 friction lock header, 2.54mm pitch, 10 position | 1-640456-0 |  | MTA100 friction lock header, 2.54mm pitch, 10 position (J4, J5, J6, J7)
4 | MTA100-10PIN-24AWG | PLUG_J4, PLUG_J4, PLUG_J6, PLUG_J7 | MTA100 housing, 10 pin, 24 AWG | 4-643814-0 |  | MTA100 housing, 10 pin, 24 AWG (PLUG_J4, PLUG_J4, PLUG_J6, PLUG_J7)
8 | 100nF | C1, C3, C5, C7, C9, C11, C13, C15 | Capacitor, ceramic, 100nF, radial, 2.5mm lead pitch | K104K15X7RF5TL2 |  | Capacitor, ceramic, 100nF, radial, 2.5mm lead pitch (C1, C3, C5, C7, C9, C11, C13, C15)
2 | 2.2k | R13, R33 | Resistor, 2.2K, axial, 2mm x 4mm | MFR25SFTE26-2K2 |  | Resistor, 2.2K, axial, 2mm x 4mm (R13, R33)
2 | 2N2222A | Q17, Q18 | NPN transistor, TO-92, 40V, 600mA | 2N2222A |  | NPN transistor, TO-92, 40V, 600mA (Q17, Q18)
2 | 4.7K | R18, R32 | Resistor, 4.7K, axial, 2mm x 4mm | MFR25SFRF52-4K7 |  | Resistor, 4.7K, axial, 2mm x 4mm (R18, R32)
8 | 4.7uF | C2, C4, C6, C8, C10, C12, C14, C16 | Capacitor, ceramic, 4.7uF, radial, 2.5mm lead pitch | FG14X7R1E475KRT06 |  | Capacitor, ceramic, 4.7uF, radial, 2.5mm lead pitch (C2, C4, C6, C8, C10, C12, C14, C16)
16 | 200R | R1, R2, R3, R4, R5, R6, R7, R8, R9, R10, R11, R12, R14, R15, R16, R17 | Resistor, 200 Ohm, axial, 2 mm x 4mm | MFR25SFRF52-200R | MOSFET gate driver resistor; gate drive current limit 60mA | Resistor, 200 Ohm, axial, 2 mm x 4mm (R1, R2, R3, R4, R5, R6, R7, R8, R9, R10, R11, R12, R14, R15, R16, R17)
0 | 47R | R1, R2, R3, R4, R5, R6, R7, R8, R9, R10, R11, R12, R14, R15, R16, R17 | Resistor, 47 Ohm, axial, 2 mm x 4mm | MFR25SFRF52-47R | Alternate gate driver resistor; current limit 255mA, faster MOSFET switching, UCC27524 overload risk with high-capacitance MOSFET | Resistor, 47 Ohm, axial, 2 mm x 4mm (R1, R2, R3, R4, R5, R6, R7, R8, R9, R10, R11, R12, R14, R15, R16, R17)
0 | 4R7 | R1, R2, R3, R4, R5, R6, R7, R8, R9, R10, R11, R12, R14, R15, R16, R17 | Resistor, 4.7 Ohm, axial, 2 mm x 4mm | MF0204FTE52-4R7 | Alternate gate driver resistor; current limit 2.5A, fastest MOSFET switching, UCC27524 overload risk with high-capacitance MOSFET | Resistor, 4.7 Ohm, axial, 2 mm x 4mm (R1, R2, R3, R4, R5, R6, R7, R8, R9, R10, R11, R12, R14, R15, R16, R17)
1 | MTA156-6PIN | J3 | Header,MTA156,6 way friction lock header,3.96mm pitch | 640445-6 |  | Header,MTA156,6 way friction lock header,3.96mm pitch (J3)
1 | MTA156-6PIN-22AWG | PLUG_J3 | MTA156 IDC housing, 6 pin, 22 AWG | 3-643819-6 |  | MTA156 IDC housing, 6 pin, 22 AWG (PLUG_J3)
2 | MTA156-9PIN | J1, J2 | Header,MTA156,straight,3.96mm,9way | 640445-9 |  | Header,MTA156,straight,3.96mm,9way (J1, J2)
2 | MTA156-9PIN-24AWG | PLUG_J1, PLUG_J2 | MTA156 IDC housing, 9 pin, 24 AWG | 3-640429-9 |  | MTA156 IDC housing, 9 pin, 24 AWG (PLUG_J1, PLUG_J2)
1 | BH-123A-1 | BATT1 | Adam Tech coin cell battery holder, 20mm, PC Pin | BH-123A-1 | Updated board design (Rev 20250312) | Adam Tech coin cell battery holder, 20mm, PC Pin (BATT1)
0 | BAT-HLD-001-THM | BATT1 | Coin cell battery holder, 20mm, clip type, through-hole | BAT-HLD-001-THM | Original board design (before rev 20250312) | Coin cell battery holder, 20mm, clip type, through-hole (BATT1)
1 | DS1307 | IC13 | Real-time clock IC, DS1307, 8-Pin PDIP | DS1307 |  | Real-time clock IC, DS1307, 8-Pin PDIP (IC13)
1 | 32.768kHz/12.5pF/35K | Y1 | Crystal, 32.768 kHZ, 12.5 PF, ESR 35K, through hole radial 2.8mm pitch | ECS-.327-12.5-13XC |  | Crystal, 32.768 kHZ, 12.5 PF, ESR 35K, through hole radial 2.8mm pitch (Y1)
16 | IPP180N10N3GXKSA1 | Q1, Q2, Q3, Q4, Q5, Q6, Q7, Q8, Q9, Q10, Q11, Q12, Q13, Q14, Q15, Q16 | Power MOSFET, TO-220-3 (G-D-S pin ordering) | IPP180N10N3GXKSA1 | N-channel, TO-220-3, G-D-S pin ordering, min +/-20V V[gs][max]; example substitutes: FDPF08N10A, IRF540N | Power MOSFET, TO-220-3 (G-D-S pin ordering) (Q1, Q2, Q3, Q4, Q5, Q6, Q7, Q8, Q9, Q10, Q11, Q12, Q13, Q14, Q15, Q16)
2 | SB140-T | D1, D2 | Schottky Diodes & Rectifiers 1.0A 40V, SB140-T, through-hole | SB140-T |  | Schottky Diodes & Rectifiers 1.0A 40V, SB140-T, through-hole (D1, D2)
8 | UCC27524P | IC1, IC2, IC3, IC4, IC5, IC6, IC7, IC8 | Dual 5A High-Speed Low-Side Power MOSFET Driver | UCC27524P |  | Dual 5A High-Speed Low-Side Power MOSFET Driver (IC1, IC2, IC3, IC4, IC5, IC6, IC7, IC8)
4 | ULN2803A | IC9, IC10, IC11, IC12 | Darlington NPN transistor array, 500mA/ch | ULN2803A |  | Darlington NPN transistor array, 500mA/ch (IC9, IC10, IC11, IC12)

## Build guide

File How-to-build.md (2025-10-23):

# Building the project from source

If you wish to build the project from source, clone the github
repository to your PC.  (You can also download a snapshot of the
github code as a ZIP file and unpack it into a local directory on your
PC.)  The firmware and Windows tools use completely separate build
systems; see below for instructions for each.

## Pico SDK setup

Building the firmware requires the Pico C++ SDK from Raspberry Pi.
For the project's initial development phase, I was using SDK 1.5.1;
shortly before the first release, I migrated to the latest SDK version
at the time, 2.1.0.  In October 2025, for the version 1.0.0 release,
I migrated the release build to SDK 2.2.0.

The full project will currently build against any of those SDK
versions (1.5.1, 2.1.0, or 2.2.0).  Since I'm currently using 2.2.0
for my official release builds, I recommend using that, so that your
environment matches mine - that tends to save a lot of time if you
need to contact me with any questions about the build.

### How to install SDK 2.2.0

For people who want to do command-line builds on Windows (which is how
I build the project), I created a ready-to-install snapshot of my Pico
SDK 2.2.0 build environment for Windows x64, complete with pre-built
binaries of all of the required gcc toolchain and SDK SDK build tools
executables:

* Download it from https://github.com/mjrgh/pico-sdk-2.2.0

* In that repo, open README.MD file, and follow the instructions under **How to Install**

The Pico SDK is also available for Linux and Mac.  Refer to the official
Raspberry Pi SDK release for those platforms.

### How to install SDK 2.1.0

Raspberry Pi moved to a Visual Studio Code (VS Code) extension for the 2.1.0 SDK,
replacing the Windows command-line build environment used in 1.5.1.
In principle, that should be just as easy to set up, but it still
seems to be a work in progress, so much so that I can't get it to
install on my machine.  In addition, the official 2.1.0 library has a
couple of serious errors, one that will cause an obvious compiler
error when you try to build, and a second, more insidious regression
that will make the USB connection unstable when you deploy the
firmware.

To address the install glitches and library errors, I've create my
own unofficial release bundle of the 2.1.0 SDK for x64 Windows.  My
version is for command-line builds, same as the official 1.5.1 SDK,
and comes with pre-built Windows x64 binaries for all of the required
tools, and **corrected** versions of the library files.  To install:

* Download it from https://github.com/mjrgh/pico-sdk-2.1.0

* Follow the instructions in the README.MD file under **How To Install**

For the download, you can either `git clone` it or download it as a ZIP file.

This is just a snapshot of my own copy of the 2.1.0 SDK, and it's for
x64 Windows only.  If you want to build on Linux or MacOS, go directly
to the Raspberry Pi site and follow their instructions.  However,
<b>you'll still need my corrected library files,</b> because the official
ones contain the errors I mentioned.  You should set up the official
SDK environment per Raspberry Pi's instructions, then replace the
pico-sdk/ subtree with my corrected version from https://github.com/mjrgh/pico-sdk-2.1.0.

### How to install SDK 1.5.1

If you want to go with the tried-and-true 1.5.1, that's easy.
Raspberry Pi provides an official one-click Windows installer, at
https://github.com/raspberrypi/pico-setup-windows/.  Download
and run the installer, and follow the on-screen prompts.

### NMAKE

For any version of the SDK on Windows, you'll also need to install
Microsoft's NMAKE build tool.  That's not included in any of the
pre-built snapshots (mine or the official Raspberry Pi releases)
because it's proprietary Microsoft software.  The easiest way to get
NMAKE is to install Visual Studio, which you'll need to do anyway,
since you'll need it to build the Windows portion of the Pinscape
project (the Config Tool and related software).  The free Community
Edition of Visual Studio is available at https://visualstudio.microsoft.com/vs/community/.

### Pico SDK documentation 

For tons of documentation about how to use the Pico SDK, see
[Getting started with Raspberry Pi Pico](https://datasheets.raspberrypi.com/pico/getting-started-with-pico.pdf).
That has instructions for setting up the build environment on other
platforms (Linux, MacOS) if you prefer to work on one of those.
But you won't need to read all of that if you just want to build the
Pinscape firmware, as the instructions below should cover it.

## Building the main Pinscape Pico firmware program

The steps below assume that you've already set up the SDK tools
on Windows as explained above, and assumes that you're using the
command-line build process (as opposed to VS Code or some other IDE).
These steps are only required for the **first build** on a new machine.

* Open a Windows Terminal window (i.e., a CMD prompt/DOS box)

* Set the working directory (`CD`) to your PinscapePico\firmware folder

* Type `c:\pico-sdk-2.1.0\pico-env.cmd` (replacing the path with the actual
location where you installed the Pico SDK files, if it's different)

* `del CMakeCache.txt` and `rmdir /s CMakeFiles` (only needed if those exist from previous builds)

* Type `cmake -S . -G "NMake Makefiles"` (**exactly** as shown, including capitalization and quotes)

* Type `nmake`

That should produce a long series of progress messages from the compiler, hopefully
all bearing good news (no warnings or errors), and ultimately finishing with:

`[100%] Built target PinscapePico`

You should now see a file in the working folder called `PinscapePico.uf2`.  That's
the compiled firmware program, ready for installation onto your Pico.  Install
it on the Pico using the standard procedure for all Pico firmware installs:

* Unplug the Pico from USB (and all other power sources)

* Press **and hold** the button on top of the Pico while plugging in the Pico's USB cable, then release the button

* Copy the UF2 file onto the Pico's Boot Loader virtual thumb drive

If you're already installed Pinscape on the Pico in question, you can
alternatively install the UF2 file through the GUI Config Tool, via
the Update Firmware button on the Device Overview page.  That lets
you skip the BOOTSEL/USB cable maneuvering.

### Re-building

The lengthy procedure above is only required for the first build on a
new machine, to generate the build scripts.  After you go through
those steps once, you can repeat the build simply by typing `nmake`.
That will recompile all source files modified since the last build,
and generate a new .uf2 file.

NMAKE automatically detects which source files are affected by edits
made since the last build, and selectively rebuilds only the affected
parts of the program, so rebuilds tend to be much faster than the
first build.

## Building the PWM Worker firmware

There's a separate firmware program, called PWMWorker, in another folder
(of that name) alongside `firmware`.  This program is designed for use with
the DIY-friendly expansion boards, which use auxiliary Picos to perform the
job of controlling PWM outputs, which we might otherwise do with a dedicated
PWM chip like a TLC59116 if any such chips were available in a DIY-friendly
package.  But all of the PWM chips on the market today are fine-pitch SMD
chips that are difficult to solder by hand, so we use Picos instead.  To
make the auxiliary Picos act like PWM controller chips, we install this
special firmware.

You can build this firmware using the same procedure outlined above
for the main Pinscape firmware.

## Building the Windows programs (GUI Config Tool, Command Line Config Tool, API libraries)

All of the Windows programs can be built through a single Visual Studio "solution" (.sln)
file.  The process is fully automatic once you load the .sln into Visual Studio.

* Install Visual Studio 2022 or later.  Community Edition is free;
download it from the official Microsoft site at https://visualstudio.microsoft.com/vs/community/.

* Launch Visual Studio

* Click **Open a project or solution**

* In the file selector, navigate  to your PinscapePico folder, and select **PinscapePico.sln**

* Select **Build** > **Build Solution** on the main menu

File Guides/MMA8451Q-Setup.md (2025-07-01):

# MMA8451Q Setup Guide

This is a quick guide to setting up an MMA8451Q accelerometer with a
standalone Pico.  MMA8451Q is the accelerometer chip that was
built into the venerable FRDM-KL25Z microcontroller board, which
was the platform that the original Pinscape Controller software
ran on.

MMA8451Q is no longer in production, but you can still buy them as of
this writing (mid 2025), because Adafruit still has an inventory of
their MMA8451Q breakout boards in stock.  The MMA8451Q is the best
current option for Pinscape Pico accelerometers in terms of
measurement accuracy, so if you're thinking about building a nudge
device into your pin cab, you should go out and buy the Adafruit
board now, while they're still available.

If you're using a newer version of my DIY Expansion Board design, you
won't need to go through the extra steps here, because the DIY board
has a slot pre-wired for the Adafruit MMA8451Q breakout board.  Just
build the expansion board, and plug the Adafruit board into the
special slot.  Note that the slot is specifically designed for the **Adafruit**
MMA8451Q breakout board, so you must use that specific product.  Generic
MMA8451Q boards from Amazon or eBay or AliExpress probably won't have
the same pin layout and so won't work.

If you're reading this material some years after I wrote, and you find
that the MMA8451Q is no longer available, the next best device to look for is
probably LIS3DH, which is (as of 2025) in production and widely available.
See [LIS3DH Setup](LIS3DH-Setup.md).

## Pico pin-out diagram

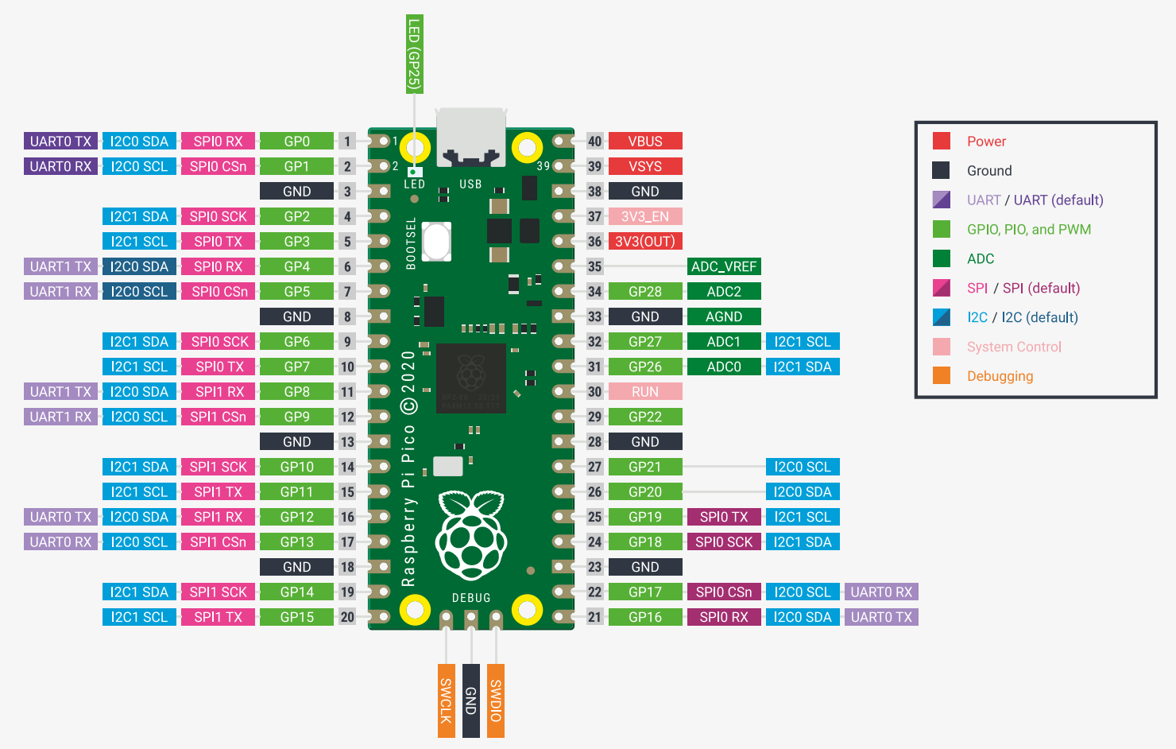
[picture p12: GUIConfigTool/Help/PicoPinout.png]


## Adafruit MMA8451Q board diagram

If you're using an MMA8451Q board from some other vendor, it might not
have exactly the same pin layout, but all of the same pins should still
be there, possibly in a different order and with different labels.  There's
no way I can show you a diagram of every other board that might be out
there, so I'll have to leave it up to you to make the translation from
the Adafruit layout shown above.

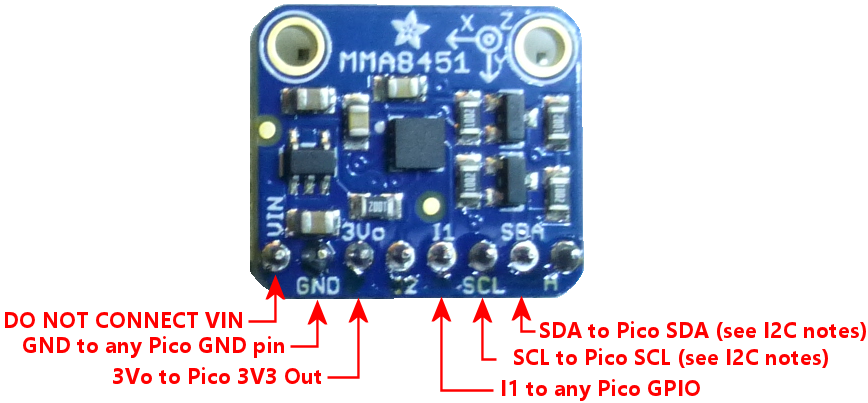
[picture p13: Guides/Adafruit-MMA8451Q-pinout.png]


## Wiring the chip

All MMA8451Q breakout boards should have the following external pins, which
should be connected as follows:

* 5V input, labeled **5V** on the Adafruit board.  **DO NOT CONNECT this pin.**
The Pico is a 3.3V platform, so you **must not** connect this pin when using the chip with a Pico.
(Non-Adafruit boards might not have a 5V input.)

* 3.3V power input, labeled **3VO** on the Adafruit board (it might be **3.3V** or **3V3** on other boards).
Connect to the Pico 3.3V power output pin (3V3 OUT, pin 36).

* GND (ground).  Connect to any GND pin on the Pico.

* SCL.  See the I2C connection notes below.

* SDA.  See the I2C connection notes below.

* Interrupt 1, labeled **I1** on the Adafruit board (it might be **INT1** on other boards)
Connect to any free GPIO pin on the Pico.  You can optionally leave this disconnected, but
it improves overall Pico software performance if you connect it.

* SA0 (labeled **A** on the Adafruit board).  Connect to GND to select I2C address
0x1C.  Connect to 3.3V (same as VIN) or simply leave unconnected to select address 0x1D.

Some boards have other pins as well, and in most cases, you can leave these disconnected.
But if your board came with instructions or a wiring diagram, pay attention to what they
say instead of my one-size-fits-all advice here.

### Sample breadboard wiring

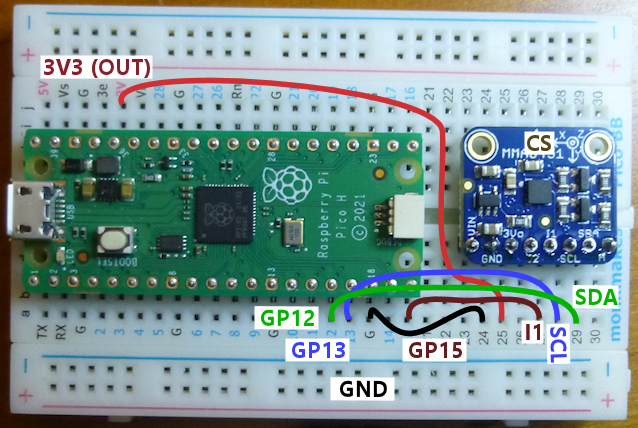
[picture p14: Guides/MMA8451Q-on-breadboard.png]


### I2C connections

This chip communicates with the Pico via a bus protocol known as I2C.  This requires two
connections to the Pico, labeled **SDA** and **SCL** on the chip.

I2C on the Pico only works on **certain combinations of GPIO pins**.  In particular, the SDA and SCL
pins that you choose must be paired to the same I2C unit on the Pico.  The Pico has two
I2C units, called I2C0 and I2C1.  The pins you choose for SDA and SCL must come from
the **same unit**.  So if you pick an I2C0 SDA pin, you must also choose an I2C0 SCL pin.
Likewise, an I2C1 SDA pin must be paired with an I2C1 SCL pin.

How can you tell which pin goes with which I2C unit?  Just look at a Pico pin-out diagram.
Each pin is labeled with a legend like **I2C0 SDA** or **I2C1 SCL**.  Just pick a pair of
pins, SDA and SCL, that are attached to the same I2Cx unit.

For example, GP0 and GP1 are attached to I2C0 SDA and I2C0 SCL respectively, so you can
use these as your I2C pins.

Once you choose, just wire the SDA pin from the MMA8451Q board to the chosen SDA GPIO pin
the Pico, and likewise, wire SCL from the MMA8451Q to the chosen SCL GPIO on the Pico.

## Pinscape configuration setup

There are two sections in the JSON configuration that you have to set up to use
this chip: `i2c0` or `i2c1`, and `mma8451q`.

The first section configures the I2C unit.  An I2C bus can have
several devices attached, so Pinscape separates the I2C configuration
from the device configuration - you need a whole section in the config
just for the I2C unit setup.  The same I2C section can then be shared
by multiple devices, if you have more than one I2C device connected to
the same bus.

The I2C section looks like this:

```
i2c0: {
   sda: 0,          // the GPIO port number where you connected the chip's SDA pin
   scl: 1,          // GPIO port connected to the chip's SCL pin
   speed: 400000,   // bus speed - most chips operate at 400000
   pullup: true,    // enable the Pico's internal pull-up resistors on SDA and SCL
},
```

The "0" in `i2c0` is the unit number, which must match the pins you selected in
the wiring.  If you used pins that are labeled as I2C1 pins in the Pico diagram,
change this to `i2c1` instead.

If your MMA8451Q board has its own pull-up resistors built-in, which many of these boards do,
you can omit the `pullup: true` part.  But it doesn't usually do any harm to include it
one way or the other.  An I2C bus *always* requires pull-up resistors on those lines, so
most boards include them, but some leave it up to you to provide them to give you more
flexibility in choosing the resistor size (which matters more when you have several
devices attached to the bus).

The second section sets up the MMA8451Q unit itself.

```
mma8451q: {
   i2c: 0,        // which I2C unit you're using - 0 if you connected the device to I2C0 pins, 1 for I2C1 pins
   addr: 0x1D,    // the chip's I2C address - 0x1C if you connected "A" (SA0) to GND, 0x1D if you connected it to 3V3 OUT or left it unconnected
   interrupt: 22, // the GPIO port number where you connected the INTERRUPT (INT or INT1) pin - OMIT IF NOT CONNECTED
   gRange: 2,     // the "g" range to select - 2 selects +/- 2g, which is the most sensitive setting, and usually the best for virtual pinball
},
```

## Nudge setup

The JSON configuration has one more section required to set up nudging: the "nudge device".
This is a Pinscape Pico abstraction that processes the accelerometer input and turns it
into "nudge" data for the pinball simulator programs.  It has its own settings, which
go under the `nudge` section in the configuration.

```
nudge: {
   x: "+X",        // map the chip's physical X axis to Pinscape's X axis (left/right)
   y: "+Y",        // map the chip's physical Y axis to Pinscape's Y axis (front-to-back)
   z: "+Z",        // map the chip's physical Z axis to Pinscape's Z axis (vertical up/down)
},
```

The axis mapping lets you compensate for the orientation of the MMA8451Q chip in the cabinet.
If you look very closely at the Adafruit board, it has a very small arrow with a "Y" printed
on top, showing the direction of the physical chip's Y axis relative to the carrier board.
In the virtual pinball world, the "X" axis represents left/right motion across the width
of the cabinet, and the "Y" axis represents the front-to-back motion along the length
of the cabinet.  Pinscape also has a "Z" axis, which represents the vertical up/down
direction.  The vertical axis isn't used in most virtual pinball programs, but it's a
feature of most of the accelerometer chips, so Pinscape takes it into account just in
case a future simulator ever makes use of it.

You can start with the mappings shown above, but you can map any physical chip axis
to any abstract nudge device axis.  And if an axis is backwards in the pinball simulation,
you can fix that by changing "+X" to "-X", for example.

## Gamepad setup

Believe it or not, we're still not quite done with the JSON setup.  We now have the
physical chip's data input handled, and the logical "nudge device" inputs mapped, but
we still have to tell Pinscape how to send the nudge data to the PC.

The standard way to do this in almost all current pinball simulators is via a
virtual gamepad (also known as a joystick).  Almost all of the simulators are able
to accept nudge input on the X and Y gamepad axes.  So, we have to first **enable**
the gamepad, so that Pinscape presents the PC with an imaginary gamepad device,
and then we have to **map the gamepad axes** to the nudge device.

```
gamepad: {
   enable: true,       // enable the simulated gamepad device on the USB interface
   x: "nudge.x",       // map the gamepad's X axis to the nudge device's X axis
   y: "nudge.y",       // map the gamepad's Y axis to the nudge device's Y axis
   z: "plunger.z",     // if you also have a plunger, this maps the Z axis to report the plunger position
},
```

### Sample JSON file

Here's a complete but very stripped-down configuration file showing the
settings described above.  The GPIO ports are set to match the breadboard
wiring shown earlier.

```
{
   i2c0: {
      sda: 12,
      scl: 13,
      speed: 400000,
   },

   mma8451q: {
      i2c: 0,
      addr: 0x1D,
      interrupt: 15,
      gRange: 2,  
   },
  
   nudge: {
      source: "mma8451q",
      x: "+X",
      y: "+Y",
      z: "+Z",  
   },
      
   gamepad: {
      enable: true,
      x: "nudge.x",
      y: "nudge.y",
   },
}
```

## Testing

The first step to testing the setup is to look at the Nudge window in the Pinscape
Config Tool.  Launch the config tool, click on the device in the list on the left,
and then click on the Nudge tab to bring up the Nudge Tester window.

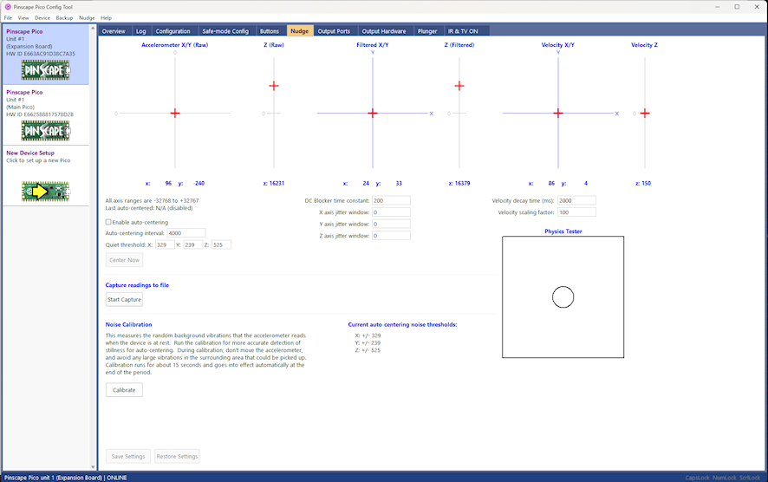
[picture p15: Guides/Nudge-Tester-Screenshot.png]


The simple test to perform here is to observe the **Accelerometer X/Y
(Raw)** graph, and make sure the red crosshairs moves when you nudge
the MMA8451Q board.  When you apply side-to-side accelerations to the
board, you should see the crosshairs move left and right.  When you
apply front/back accelerations to the board, you should see the
crosshairs move up and down.

If the crosshairs are moving, but in the wrong directions, you just
need to adjust the axis mappings in the `nudge` section in the configuration.

### Gamepad input testing

A second test you can perform is to run the Windows gamepad viewer
control panel.  Press Windows+R to bring up the Run box, type **JOY.CPL**,
and press Enter.  This will bring up a list of gamepad devices; find
the Pinscape Pico entry, and double-click it.

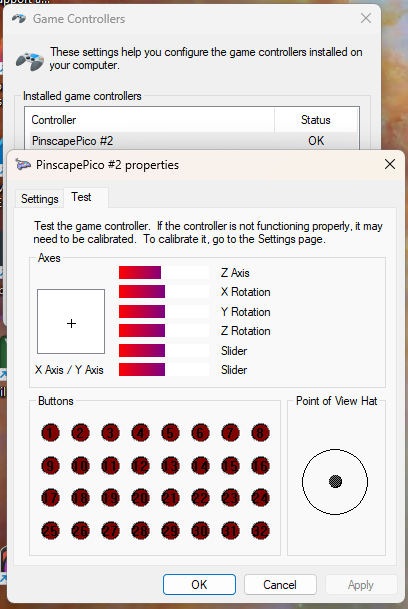
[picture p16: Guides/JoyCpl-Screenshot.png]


You can now repeat the physical "nudge" tests, this time observing
the **X Axis / Y Axis** crosshairs in the joystick viewer.  You should
see the crosshairs move side-to-side when you move the MMA8451Q board
side-to-side, and up/down when you move the MMA8451Q board front-to-back.

Again, if the directions are wrong, you can fix it easily by changing
the axis mappings in the `nudge` settings in the configuration.

### DO NOT USE WINDOWS CALIBRATION

There's a super important warning I have to give you here: **NEVER EVER EVER**
click the "Calibrate" button in the Windows joystick viewer.  If you do that, it
will make the nudge behave erratically in the pinball simulators.  Joystick
calibration is only designed for **real joysticks**, and it wreaks havoc with
our fake nudge joysticks, making their readings all screwy in the pinball games.

#### "Oops, what if I already clicked Calibrate?"

If you accidentally clicked the Calibrate button at some point (or suspect you
might have), you can easily undo it.  Go back to JOY.CPL, click the Settings
tab, and then click **Reset to default**.  That deletes the calibration data
collected when you clicked the Calibrate button.

## Cabinet installation

The MMA8451Q board should be installed flat on the floor of your cabinet, square
with the cabinet walls.  The rotation doesn't matter, since you can always remap
the axis assignments to match the orientation, but it's important to have the
sides of the board parallel to the walls of the cabinet, so that one MMA8451Q
horizontal axis is aligned with the side-to-side motion of the cabinet, and
the other is aligned with front-to-back motion.  If you install the board
at an angle, front-to-back and side-to-side motion will both be mixed into
the readings on both MMA8451Q horizontal axes, which will make the nudge response
muddy at best.

The board should be attached securely to the cabinet floor, so that the device
moves in lock step with the cabinet.  The whole point is to track the motion
of the cabinet itself, so the accelerometer has to essentially be part of the
cabinet.  Make that so by attaching it firmly to the cabinet floor.  You can
just screw the board down directly, or you can install it on standoffs.

As for positioning within the cabinet, the best place is somewhere towards the
front of the cabinet, roughly centered side-to-side.  If you have a coin box,
directly behind the coin box is a good place.  Exact placement really isn't
critical, but installing the device towards the front of the cabinet is best,
because the side-to-side nudges you apply during the game will have the biggest
effect on the front part of the cabinet.

## Visual Pinball setup

In Visual Pinball, nudge input is mapped in the **Keys, Nudge and DOF** dialog.
In the menu, select **Preferences** > **Configure Keys, Nudge and DOF...**

For standard joystick mappings, select:

* X Axis (L/R) = X Axis, X-Gain = 1000
* Y Axis (U/D) = Y Axis, Y-Gain = 1000
* Dead Zone = 0%
* Enable Analog Nudge = Checked
* Normal Board Mounting Orientation = Checked

You'll have to experiment with the X-Gain and Y-Gain settings to get the proper
nudge strength.  The Gain settings are arbitrary scaling factors that control
how strong the effect on the simulation is, and there really isn't a one-size-fits-all
setting.  VP provides a Nudge Test Table that you can use to judge the effect, so
you should find that (it should come with your VP installation) and run it to
dial in settings that you like.

This is another place where you can adjust for orientation differences.  When
you run the Nudge Test Table, you can make sure that the motion is as expected,
and rotate or reverse axes in the VP mappings if things go the wrong direction.

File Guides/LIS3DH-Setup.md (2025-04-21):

# LIS3DH Setup Guide

This is a quick guide to setting up a LIS3DH accelerometer with a standalone
Pico.

If you're using one of my reference Expansion Board designs, the LIS3DH is
essentially built into the board, so you won't need to go through the extra
steps here - just build the expansion board, and plug the Adafruit LIS3DH
breakout board into the special slot for it on the board.

Pinscape Pico has support for several accelerometer chips, so LIS3DH
isn't your only option, but it's probably the easiest and best choice
at the moment.  LIS3DH is really popular among robotics hobbyists,
which creates enough demand that companies like Adafruit and Sparkfun
sell the chip on little "breakout" boards that are easy for hobbyists
to work with.  That's important for an accelerometer chip, because all
of the accelerometers currently in production come in extremely tiny
surface-mount packages that are quite challenging to solder by hand.
The breakout boards solve that problem by providing the chip on a
pre-soldered carrier board with 0.1" pin headers that you can easily
connect to a microcontroller like a Pico.

LIS3DH breakout boards are available from several sources, including
Adafruit, Sparkfun, and no-name sellers on Amazon and eBay.  I use the
one from Adafruit, but any of the others should work equally well.
They're all equivalent as far as the Pinscape software is concerned,
because they all have the same IC chip at their core, the LIS3DH.

Note that there's an older variation on the LIS3DH called the LIS3DSH
(that's just one letter difference, hidden in the middle of the
name - the added **S**).  LIS3DH and LIS3DSH are different chips
with different software interfaces, so you can't use them
interchangeably.  However, Pinscape Pico has support for both, so
you can use either one - you just have to be sure to tell the software
which type you're using when you set up the configuration. Otherwise,
setting up the two chips is identical, so you can use this guide with
either type, as long as you set the correct type when you get to the
JSON configuration steps.

## Pico pin-out diagram



## Adafruit LIS3DH board diagram

You don't have to use the Adafruit board specifically, but there's no way I
can show you diagrams of every single LIS3DH board out there, so I'll use
this as the reference point.  The other LIS3DH boards might have different
labels for some of the pins, but they should have all of the same actual
pins - hopefully it won't be too hard to figure out the correspondences for
any pins with different labels.

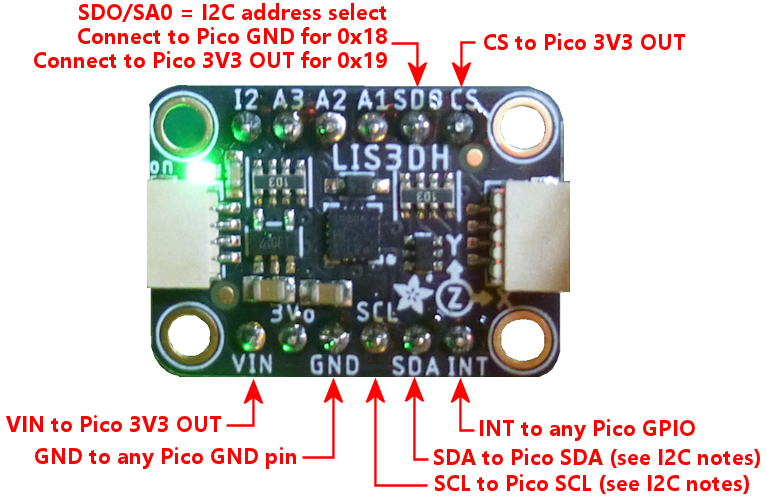
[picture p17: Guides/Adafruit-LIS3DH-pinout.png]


## Wiring the chip

All LIS3DH breakout boards should have the following external pins, which
should be connected as follows:

* 3.3V power input, labeled **VIN** on the Adafruit board (it might be **3.3V** or **3V3** on other boards).
Connect to the Pico 3.3V power output pin (3V3 OUT, pin 36).

* GND (ground).  Connect to any GND pin on the Pico.

* SCL.  See the I2C connection notes below.

* SDA.  See the I2C connection notes below.

* Interrupt, labeled **INT** on the Adafruit board (it might be **INT1** on other boards)
Connect to any free GPIO pin on the Pico.  You can optionally leave this disconnected, but
it improves overall Pico software performance if you connect it.

* CS.  Connect to 3.3V (same as VIN).

* SDO/SA0 (labeled **SDO** on the Adafruit board).  Connect to GND to select I2C address
0x18, or 3.3V (same as VIN) to select address 0x19.

Note that some boards also have a POWER OUT pin.  This is true of the Adafruit
board (the pin labeled **3Vo**).  You can leave this disconnected.

Some boards have other pins as well, and in most cases, you can leave these disconnected.
But if your board came with instructions or a wiring diagram, pay attention to what they
say instead of my one-size-fits-all advice here.

### Sample breadboard wiring

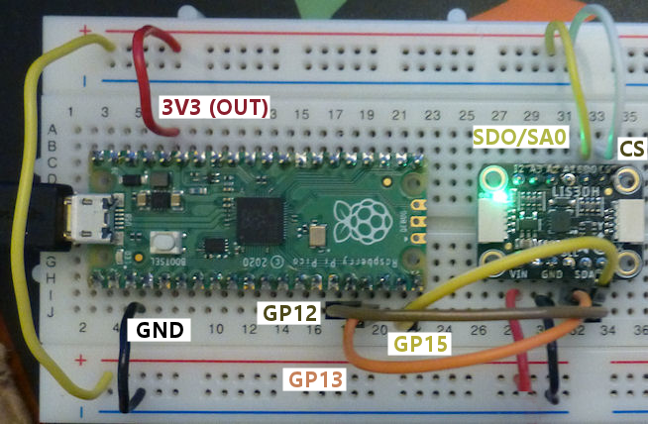
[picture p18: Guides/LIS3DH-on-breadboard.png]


### I2C connections

This chip communicates with the Pico via a bus protocol known as I2C.  This requires two
connections to the Pico, labeled **SDA** and **SCL** on the chip.

I2C on the Pico only works on **certain combinations of GPIO pins**.  In particular, the SDA and SCL
pins that you choose must be paired to the same I2C unit on the Pico.  The Pico has two
I2C units, called I2C0 and I2C1.  The pins you choose for SDA and SCL must come from
the **same unit**.  So if you pick an I2C0 SDA pin, you must also choose an I2C0 SCL pin.
Likewise, an I2C1 SDA pin must be paired with an I2C1 SCL pin.

How can you tell which pin goes with which I2C unit?  Just look at a Pico pin-out diagram.
Each pin is labeled with a legend like **I2C0 SDA** or **I2C1 SCL**.  Just pick a pair of
pins, SDA and SCL, that are attached to the same I2Cx unit.

For example, GP0 and GP1 are attached to I2C0 SDA and I2C0 SCL respectively, so you can
use these as your I2C pins.

Once you choose, just wire the SDA pin from the LIS3DH board to the chosen SDA GPIO pin
the Pico, and likewise, wire SCL from the LIS3DH to the chosen SCL GPIO on the Pico.

## Pinscape configuration setup

There are two sections in the JSON configuration that you have to set up to use
this chip: `i2c0` or `i2c1`, and `lis3dh`.

The first section configures the I2C unit.  An I2C bus can have
several devices attached, so Pinscape separates the I2C configuration
from the device configuration - you need a whole section in the config
just for the I2C unit setup.  The same I2C section can then be shared
by multiple devices, if you have more than one I2C device connected to
the same bus.

The I2C section looks like this:

```
i2c0: {
   sda: 0,          // the GPIO port number where you connected the chip's SDA pin
   scl: 1,          // GPIO port connected to the chip's SCL pin
   speed: 400000,   // bus speed - most chips operate at 400000
   pullup: true,    // enable the Pico's internal pull-up resistors on SDA and SCL
},
```

The "0" in `i2c0` is the unit number, which must match the pins you selected in
the wiring.  If you used pins that are labeled as I2C1 pins in the Pico diagram,
change this to `i2c1` instead.

If your LIS3DH board has its own pull-up resistors built-in, which many of these boards do,
you can omit the `pullup: true` part.  But it doesn't usually do any harm to include it
one way or the other.  An I2C bus *always* requires pull-up resistors on those lines, so
most boards include them, but some leave it up to you to provide them to give you more
flexibility in choosing the resistor size (which matters more when you have several
devices attached to the bus).

The second section sets up the LIS3DH unit itself.

```
lis3dh: {
   i2c: 0,        // which I2C unit you're using - 0 if you connected the device to I2C0 pins, 1 for I2C1 pins
   addr: 0x18,    // the chip's I2C address - 0x18 if you connected SDO/SA0 to GND, 0x19 if you connected it to 3V3 OUT
   interrupt: 22, // the GPIO port number where you connected the INTERRUPT (INT or INT1) pin - OMIT IF NOT CONNECTED
   gRange: 2,     // the "g" range to select - 2 selects +/- 2g, which is the most sensitive setting, and usually the best for virtual pinball
},
```

## Nudge setup

The JSON configuration has one more section required to set up nudging: the "nudge device".
This is a Pinscape Pico abstraction that processes the accelerometer input and turns it
into "nudge" data for the pinball simulator programs.  It has its own settings, which
go under the `nudge` section in the configuration.

```
nudge: {
   x: "+X",        // map the chip's physical X axis to Pinscape's X axis (left/right)
   y: "+Y",        // map the chip's physical Y axis to Pinscape's Y axis (front-to-back)
   z: "+Z",        // map the chip's physical Z axis to Pinscape's Z axis (vertical up/down)
},
```

The axis mapping lets you compensate for the orientation of the LIS3DH chip in the cabinet.
If you look very closely at the Adafruit board, it has a very small arrow with a "Y" printed
on top, showing the direction of the physical chip's Y axis relative to the carrier board.
In the virtual pinball world, the "X" axis represents left/right motion across the width
of the cabinet, and the "Y" axis represents the front-to-back motion along the length
of the cabinet.  Pinscape also has a "Z" axis, which represents the vertical up/down
direction.  The vertical axis isn't used in most virtual pinball programs, but it's a
feature of most of the accelerometer chips, so Pinscape takes it into account just in
case a future simulator ever makes use of it.

You can start with the mappings shown above, but you can map any physical chip axis
to any abstract nudge device axis.  And if an axis is backwards in the pinball simulation,
you can fix that by changing "+X" to "-X", for example.

## Gamepad setup

Believe it or not, we're still not quite done with the JSON setup.  We now have the
physical chip's data input handled, and the logical "nudge device" inputs mapped, but
we still have to tell Pinscape how to send the nudge data to the PC.

The standard way to do this in almost all current pinball simulators is via a
virtual gamepad (also known as a joystick).  Almost all of the simulators are able
to accept nudge input on the X and Y gamepad axes.  So, we have to first **enable**
the gamepad, so that Pinscape presents the PC with an imaginary gamepad device,
and then we have to **map the gamepad axes** to the nudge device.

```
gamepad: {
   enable: true,       // enable the simulated gamepad device on the USB interface
   x: "nudge.x",       // map the gamepad's X axis to the nudge device's X axis
   y: "nudge.y",       // map the gamepad's Y axis to the nudge device's Y axis
   z: "plunger.z",     // if you also have a plunger, this maps the Z axis to report the plunger position
},
```

### Sample JSON file

Here's a complete but very stripped-down configuration file showing the
settings described above.  The GPIO ports are set to match the breadboard
wiring shown earlier.

```
{
   i2c0: {
      sda: 12,
      scl: 13,
      speed: 400000,
   },

   lis3dh: {
      i2c: 0,
      addr: 0x19,
      interrupt: 15,
      gRange: 2,  
   },
  
   nudge: {
      source: "lis3dh",
      x: "+X",
      y: "+Y",
      z: "+Z",  
   },
      
   gamepad: {
      enable: true,
      x: "nudge.x",
      y: "nudge.y",
   },
}
```

## Testing

The first step to testing the setup is to look at the Nudge window in the Pinscape
Config Tool.  Launch the config tool, click on the device in the list on the left,
and then click on the Nudge tab to bring up the Nudge Tester window.



The simple test to perform here is to observe the **Accelerometer X/Y
(Raw)** graph, and make sure the red crosshairs moves when you nudge
the LIS3DH board.  When you apply side-to-side accelerations to the
board, you should see the crosshairs move left and right.  When you
apply front/back accelerations to the board, you should see the
crosshairs move up and down.

If the crosshairs are moving, but in the wrong directions, you just
need to adjust the axis mappings in the `nudge` section in the configuration.

### Gamepad input testing

A second test you can perform is to run the Windows gamepad viewer
control panel.  Press Windows+R to bring up the Run box, type **JOY.CPL**,
and press Enter.  This will bring up a list of gamepad devices; find
the Pinscape Pico entry, and double-click it.



You can now repeat the physical "nudge" tests, this time observing
the **X Axis / Y Axis** crosshairs in the joystick viewer.  You should
see the crosshairs move side-to-side when you move the LIS3DH board
side-to-side, and up/down when you move the LIS3DH board front-to-back.

Again, if the directions are wrong, you can fix it easily by changing
the axis mappings in the `nudge` settings in the configuration.

### DO NOT USE WINDOWS CALIBRATION

There's a super important warning I have to give you here: **NEVER EVER EVER**
click the "Calibrate" button in the Windows joystick viewer.  If you do that, it
will make the nudge behave erratically in the pinball simulators.  Joystick
calibration is only designed for **real joysticks**, and it wreaks havoc with
our fake nudge joysticks, making their readings all screwy in the pinball games.

#### "Oops, what if I already clicked Calibrate?"

If you accidentally clicked the Calibrate button at some point (or suspect you
might have), you can easily undo it.  Go back to JOY.CPL, click the Settings
tab, and then click **Reset to default**.  That deletes the calibration data
collected when you clicked the Calibrate button.

## Cabinet installation

The LIS3DH board should be installed flat on the floor of your cabinet, square
with the cabinet walls.  The rotation doesn't matter, since you can always remap
the axis assignments to match the orientation, but it's important to have the
sides of the board parallel to the walls of the cabinet, so that one LIS3DH
horizontal axis is aligned with the side-to-side motion of the cabinet, and
the other is aligned with front-to-back motion.  If you install the board
at an angle, front-to-back and side-to-side motion will both be mixed into
the readings on both LIS3DH horizontal axes, which will make the nudge response
muddy at best.

The board should be attached securely to the cabinet floor, so that the device
moves in lock step with the cabinet.  The whole point is to track the motion
of the cabinet itself, so the accelerometer has to essentially be part of the
cabinet.  Make that so by attaching it firmly to the cabinet floor.  You can
just screw the board down directly, or you can install it on standoffs.

As for positioning within the cabinet, the best place is somewhere towards the
front of the cabinet, roughly centered side-to-side.  If you have a coin box,
directly behind the coin box is a good place.  Exact placement really isn't
critical, but installing the device towards the front of the cabinet is best,
because the side-to-side nudges you apply during the game will have the biggest
effect on the front part of the cabinet.

## Visual Pinball setup

In Visual Pinball, nudge input is mapped in the **Keys, Nudge and DOF** dialog.
In the menu, select **Preferences** > **Configure Keys, Nudge and DOF...**

For standard joystick mappings, select:

* X Axis (L/R) = X Axis, X-Gain = 1000
* Y Axis (U/D) = Y Axis, Y-Gain = 1000
* Dead Zone = 0%
* Enable Analog Nudge = Checked
* Normal Board Mounting Orientation = Checked

You'll have to experiment with the X-Gain and Y-Gain settings to get the proper
nudge strength.  The Gain settings are arbitrary scaling factors that control
how strong the effect on the simulation is, and there really isn't a one-size-fits-all
setting.  VP provides a Nudge Test Table that you can use to judge the effect, so
you should find that (it should come with your VP installation) and run it to
dial in settings that you like.

This is another place where you can adjust for orientation differences.  When
you run the Nudge Test Table, you can make sure that the motion is as expected,
and rotate or reverse axes in the VP mappings if things go the wrong direction.

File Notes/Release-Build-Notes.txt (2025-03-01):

Release build procedure
-----------------------

- Update the main version number in PinscapeVersion.h (in the root project folder)

- Run the build script in the root project folder - builds all binaries and
  creates the ZIP files:

   build-and-release.bat --version vX.Y.Z

- Tag the release

   git tag vX.Y.Z
   git push --tags

- Create the release on github.com

   - Follow the github.com workflow to create a new release from the new tag
   - Fill in the description text
   - Upload files:
      - Upload releases/PinscapePico-vX.Y.Z-YYYYMMDD.zip
      - Upload releases/ButtonLatencyTester2-vX.Y.Z-YYYYMMDD.zip
   - Upload GUIConfigTool/Help/JSONConfigRef.html to mjrnet.org/pinscape/PinscapePico/Help

Manual build procedure
----------------------

- Build PinscapePico/Firmware

   cd Firmware
   ..\..\update-cmake
   mk clean
   mk

- Build PinscapePico/PWMWorker

   cd PWMWorker
   ..\..\update-cmake
   mk clean
   mk

- Build ButtonLatencyTester2/Firwmare

   cd ButtonLatencyTester2\Firmware
  ..\..\..\update-cmake
  mk clean
  mk

- Build Windows programs

   Launch Visual Studio, open PinscapePico.sln
   Select Release/x64 configuration
   Build > Clean Solution
   Build > Build Solution

- Build a zip bundle

   build-release-zip vX.Y.Z

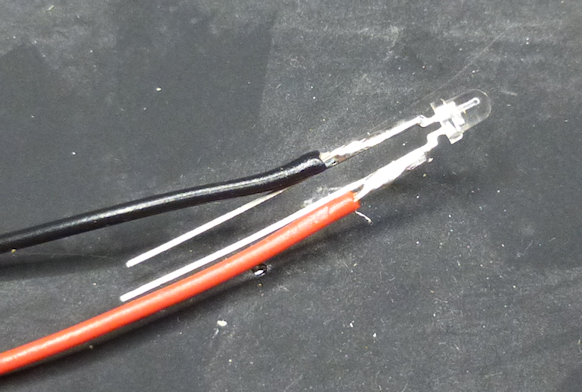
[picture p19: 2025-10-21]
ExpansionBoards/IR-TX/IRTX-assembly-2.png

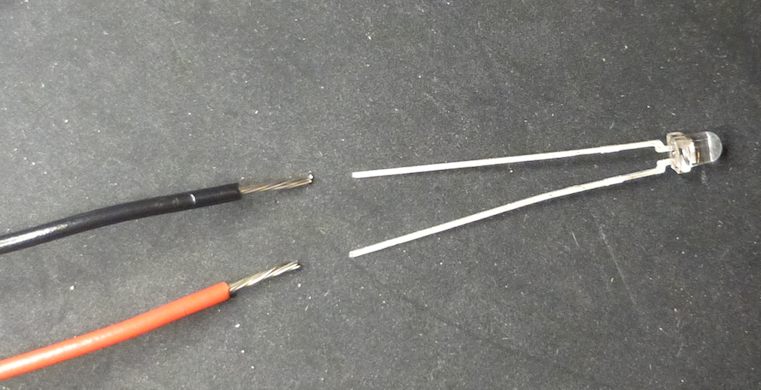
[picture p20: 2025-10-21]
ExpansionBoards/IR-TX/IRTX-assembly-1.png

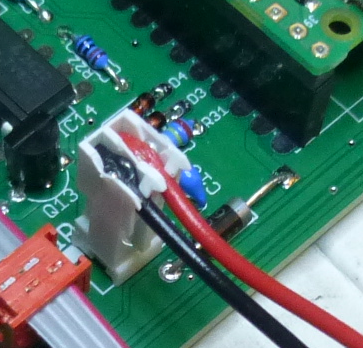
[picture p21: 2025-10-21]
ExpansionBoards/IR-TX/IRTX-assembly-4.png

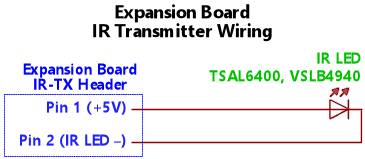
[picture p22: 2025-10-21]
ExpansionBoards/IR-TX/IRTX-expan-wiring.png

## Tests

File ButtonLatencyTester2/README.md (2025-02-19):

# Button Latency Tester II

This is a Pinscape Pico sub-project that turns a Raspberry Pi Pico into
a piece of test equipment for measuring button input latency on **another**
device.  The other device, which we'll refer to as the "subject" device
because it's the subject of the measurements, can be **any type of device**,
Pico or otherwise, that takes physical button inputs and turns them into
some kind of input to a Windows PC.  The subject device could be:

* Another Pico running the Pico Pinscape firmware

* Another Pico running some <i>non-</i>Pinscape firmware, such as Dude's Cab Controller or RickH's Little Bang controller

* A KL25Z running the original Pinscape firmware

* A proprietary key encoder, such as an Ultimarc I-PAC or a Zero Delay encoder

* A USB or PS/2-port keyboard

* A serial-port joystick

The last two (a physical keyboard or joystick) are less practical than
the others, because the testing setup requires physical access to the
switch wiring in the subject device, thus you'd have to do some
invasive surgery if you wanted to test a real keyboard or joystick.
It's much easier to work with button encoder devices that are designed
from the ground up to be connected to external button switches.  But I
wanted to make the point that you *could*, at least in principle, use
BLT-II to measure just about anything with buttons that sends input to
a PC.

This project is nominally part of Pinscape Pico, but you can also use
it as a standalone measurement tool for other types of devices.  You
don't need to install the main Pinscape firmware onto any devices to
use it.  You only need to install the much simpler Button Latency
Tester II firmware, which doesn't require any configuration.

## API selection

The Windows host program can read input through four different Windows
APIs:

* Raw Input

* DirectInput 8

* XInput (Microsoft's special API for XBox controller devices)

* [Open Pinball Device](http://mjrnet.org/pinscape/OpenPinballDevice/OpenPinballDeviceHID.htm)

When you map a physical button on the subject device to XInput or Open
Pinball Device buttons, the host program automatically uses those
respective APIs, because they go hand-in-hand with the sources.

For keyboard and gamepad button inputs, you get your pick of Raw Input or
DirectInput.  Raw Input is the default, because it's much faster than
DirectInput, and also because it's the "modern" API that Microsoft
recommends.  Microsoft deprecated DirectInput many years ago (way back in
the Windows 7 timeframe), because Microsoft likes to invent new APIs every
few years that do exactly the same thing as the old APIs they replace.  But
in this case, they had the right idea, because DirectInput is objectively
horrible, as you will see when you run tests with this program.  DirectInput's
median latency for joystick and keyboard events is about 5x greater than Raw
Input's when reading exactly the same devices, and at its worst, DirectInput
reaches the human-perceptible latency range of around 30ms.

To select DirectInput, add `--api directinput` to the command line when
running the host program.

### Initial findings about the APIs

My own ad hoc testing indicates that applications should use Raw Input
and Open Pinball Device whenever possible.  With Pinscape Pico devices
(which are designed to yield the minimum possible HID-level latency),
Raw Input and Open Pinball Device provide a median latency slightly under 2ms,
with excellent consistency (standard deviation in the 0.3ms range, and
maximum latencies around 3ms).  That's nearly as fast as HID can deliver
input directly at the hardware level, which means that Raw Input is adding
practically no overhead of its own, as Microsoft claims.

DirectInput 8 is by far the worst API, with median latency around 9ms,
and extremely wide variation, up to 30ms latency for some inputs.
Much to my surprise, XInput is almost as bad as DirectInput, with
median latency around 8ms and maximum latency around 25ms.  I would
have expected XInput to use the same low-level approach as Raw Input,
given that XInput is all about gaming, but empirically this doesn't
seem to be the case.

All of my testing was on Windows 11, so it's quite possible that the
numbers will vary somewhat on other versions, although I expect that
the hierarchy will be the same everywhere.  Note that my API
comparisons are very apples-to-apples, since they used the same
physical source for all of the input types, just with different
logical mappings for the buttons.

## Firmware installation

Install the Button Latency Tester II firmware using the standard Pico
boot loader procedure:

* Unplug the Pico from USB and all power sources

* Press **and hold** the BOOTSEL button (the small white button on top of
the Pico, labeled BOOTSEL)

* While still holding BOOTSEL, plug in the USB cable

* Release the BOOTSEL button

* The Pico should now appear on the Windows desktop as a virtual
USB thumb drive

* Copy ButtonLatencyTester2.uf2 onto the virtual thumb drive
representing the Pico

* The Pico will automatically reboot and start running the firmware

* From a Windows command prompt, run `ButtonLatencyTester2 --list` to
verify that the device appears in the list of recognized devices

* No configuration is required on the device side, and no device
drivers are required on the Windows side

## Companion Circuit Board

The project includes a [circuit board design](ConnectorBoard) that
implements the test bench setup described below on a small board that
you can plug a Pico into.  The circuit board includes inputs for four
buttons, and uses screw terminals for all external connections, to
make it easy to temporarily patch into an existing pin cab's button
encoder wiring.  The circuitry needed is also easy to set up on a
breadboard, so the PCB isn't a must.  But it might be worthwhile to
build if you plan to use it for more than one or two ad hoc test runs.

## Recommended Test Bench Setup - description

A crucial step in accurately measuring button latency is to capture
the exact moment when you press the button.  The whole point of the
exercise is to measure the time between the button press and the
arrival of the corresponding input event on the PC, so we need to know
the time of each of those endpoints, as precisely as possible.

To measure the time of the button press, we set up the button so that
it's physically connected to **both** the subject device and the
BLT-II Pico.  This ensures that the BLT-II Pico sees the physical
button press at exactly the same time as the subject device, giving us
an accurate reading on the beginning endpoint of the time interval
we're trying to measure.

The best way to connect a single button to both devices without any
risk of electrical interference between the two devices is to use an
optocoupler to isolate the button from each device.  In the
reference setup, the button is wired to **two** optocouplers: one
for the subject device, one for the BLT-II Pico.  When you press the
button, it activates both optocouplers simultaneously.  This sends the
button press signal to the subject device and the BLT-II Pico at the
same moment.  The subject device uses the input to initiate its input
event to the host, and the BLT-II Pico uses the signal to record the
time of the physical button press.

An optocoupler's transistor (Collector/Emitter) side acts roughly like
an ordinary switch, so in most encoder setups, it can physically take
the place of an ordinary pushbutton switch in a button input port's
wiring.  This works as long as the subject device's button input ports
are voltage-sensitive and high-impedance (very low current).  This is
true of the Pico, and also holds for most other microcontrollers.

## Recommended Test Bench Setup - how to

You'll need the following parts:

* A Raspberry Pi Pico, with the Button Latency Tester II firmware installed
(see above)

* The Subject Device (the device whose button latency you wish to measure),
with its firmware installed and configured for the scenario you wish to test

* A Windows PC, with the ButtonLatencyTester2.exe host program installed

* Two (2) PC817 optocouplers, or any equivalent optocouplers

* One 130 Ohm resistor

* One pushbutton

<b>IMPORTANT:</b> The diagram below assumes that the subject device uses **active-low**
button inputs.  This means that the subject device registers the button as ON when the
button terminal is connected to GND (ground), and registers the button as OFF when
the terminal is left floating (not connected to anything external).  For an active-low
controller, the **normal** wiring plan you'd use, in the absence of the test setup, is
as follows:

* Connect one terminal of the button to a button port on the subject device

* Connect the other terminal of the button to GND (ground)

If the subject device **doesn't** follow this wiring plan, you'll have to adjust
the test setup accordingly.  In *most* cases, the PC817 optocoupler in the test setup
simply takes the place of the button switch in the subject device's normal wiring
plan, but this isn't always possible.  This works as long as the device's button
input ports are voltage-sensitive and high-impedance (low current), which is true
for most microcontrollers.  If your subject device doesn't use active-low wiring, or
you're not sure that an optocoupler is a valid substitution for a physical switch for
its button wiring, check with the device's manufacturer or designer.  (Please also
let me know about it, so that I can list the specific cases people have come across
that don't fit the basic "active low" pattern.)

<b>REGARDLESS</b> of the subject device's wiring configuration, the BLT-II Pico portion
is **always** connected as shown in the diagram.  That's another reason to use the
optocoupler isolation setup: it makes the Pico wiring a constant, no matter how
the subject device is wired.

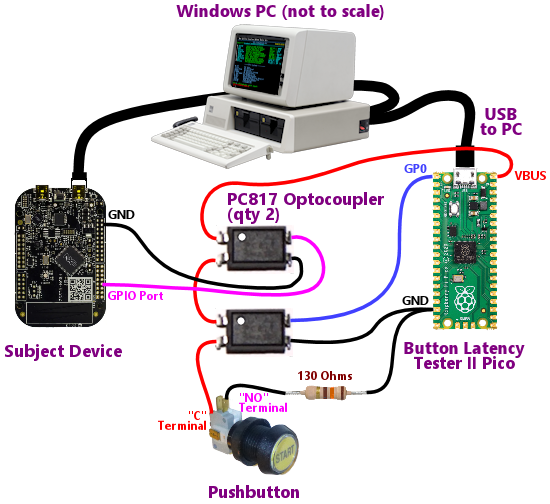
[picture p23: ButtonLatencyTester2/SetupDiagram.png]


Wire the devices as shown in the diagram:

* Connect the first optocoupler pin 1 (LED +) to the Pico's VBUS port

* Connect the first optocoupler's pin2 (LED -) to the second optocoupler's pin1 (LED +)

* Connect the second optocoupler's pin2 (LED -) to the common ("C") terminal of the pushbutton switch

* Connect the Normally Open ("NO") terminal of the pushbutton to the 130 Ohm resistor

* Connect the other end of the resistor to any available GND (Ground) port on the Pico

* Connect the first optocoupler's pins 3 and 4 (Collector and Emitter) to the
button input GPIO port and GND terminals, respectively, on the Subject Device

* Connect the second optocoupler's pins 3 and 4 to GP0 and GND on the BLT-II Pico

You can test multiple buttons by wiring them just like the first
button, choosing a new GPIO port on the BLT-II Pico for each
additional button.  You'll need another full set of components (two
optocouplers and a resistor) for each additional button.  All 26 of
the Pico's GPIO ports are available as button inputs.  Note that you
can connect any GPIO set of ports you wish - there's no need to start
at GP0.  Our choice of GP0 as the first port in the diagram is
arbitrary.

## Run the program

Once your test bench is set up as shown, run the ButtonLatencyTester2.exe program
on the Windows PC host.  On the command line, you must specify the button
configuration, mapping the following elements:

* Windows event input button name

* BLT-II Pico GPIO port number

* BLT-II Pico device ID (only required if you have more than one BLT-II Pico connected)

The full structure of the button mapping looks like this:

<tt><i>button-name</i><b>:</b><i>gpio-number</i></tt>

For example, if the button is mapped on the subject device to generate
virtual "Escape" key presses on the keyboard, and the Pico connection
is to GP0, you'd enter a command line like this:

`esc:0`

If the button on the subject is mapped to joystick button #3, and it's
connected to GPIO 12 on the BLT-II Pico:

`js3:12`

For a full list of accepted button names, run the program with the `--buttons` option.

### Raw Input vs DirectInput

The Windows host program gives you the option to measure keyboard
and joystick/gamepad input through two APIs: Raw Input and DirectInput.
This is purely a choice on the Windows side, and has nothing at all to
do with the subject device, which only thinks in terms of keyboard
or joystick/gamepad input at the USB level.  If the device provides
keyboard input, you can use Raw Input or DirectInput interchangeably.

Raw Input is always selected by default.  To use DirectInput instead,
specify `--api directinput` on the command line.

The reason that the host program offers both options is that *applications*
can use either API.  Choosing the same API that your target application
uses will most accurately re-create the conditions in effect during
real sessions with the application, for accurate measurement of the
latency that you'll see in practice using that application.

The choice of APIs is also meant to be useful to application
developers to compare the latency impact of different API choices.

## End-to-end latency measurement

Other people have devised ways to measure latency in gaming devices,
so this isn't exactly a new science.  But Button Latency Tester II
brings something to the table that I think is unique among testing
methods: **end-to-end** testing.  That means that the tool measures
the latency across the complete input path, from the moment of the
physical switch contact that signifies the button press, to the moment
where the application receives the corresponding Windows input event.

Most other latency measuring methods read USB input directly from the
subject device.  That's good for comparing *relative* latencies
between devices, but it doesn't tell you the true latency, taking into
account the transit through the Windows software layers.  This is
important because Windows has a very complex input processing model
with many redundant APIs.  The overall latency is not only a function
of the latency as far as the physical input port to the PC, but also
of the class of input event (keyboard, joystick, XInput, Open Pinball
Device) *and* the specific API that the application uses to read its
input.  BLT-II lets you see the full picture, measuring the full time
from physical button press to final application input ingestion point.
This lets you optimize not just the choice of device, but also which
type of input it's sending and which APIs the application uses to
process the input.

Another capability that I think is unique is that BLT-II can be used
to measure latency with <b>non</b>-USB devices, such as devices that
connect to an RS-232 serial port input or a PS/2 keyboard.  The BLT-II
Pico doesn't have to connect directly to the subject device, so it
doesn't matter how the subject device connects to the PC.  Everything
is mediated through the host PC.  As long as an **application** can
receive input from the subject device, we're in business; it doesn't
matter what physical path through which physical ports the input took
along the way.

## Instrumenting an application

One more interesting thing you can do with BLT-II is use it to
instrument an application, to see what latencies look like in that
specific application.

BLT-II comes with its own Windows host application that's designed to
measure the input latency all the way through the Windows input API
layers.  That's an excellent basis for comparing latencies among
devices *and* among different Windows APIs, but it doesn't tell you
how any given application will experience latency.  Applications add
their own input processing layers that can add latency beyond the
point of event ingestion from the Windows APIs.

For example, if an application uses a polling model to read input, and
it only polls for input once per video refresh cycle, its mean latency
will be at least half of the video refresh cycle time, which is about
8 ms for a 60 Hz display, and its worst-case latency will be at least
one full refresh cycle, 16 ms.  In can be difficult to understand
these effects purely from analysis of an application's architecture or
inspection of its source code, because any "real" application is a
complex system, and it can exhibit behaviors that arise from
interactions among its parts that aren't obvious on inspection.  The
best way to truly understand these effects is to measure them.

BLT-II includes a C++ "library" module that's relatively easy to embed
in a C++ application.  (It could also be worked into a .Net application,
but that would take a little more work, since the interfaces for
importing native code aren't the friendliest part of .Net.  It might
be easier to "port" the library module to C#, which would let you
use it directly in any .Net language.)

The only bit of "design" work that you'll have to do to add BLT-II
instrumentation to an existing program is to decide how you're going
to map input events to BLT-II GPIO ports.  The BLT-II host program is
a bad example, because it's trying to achieve maximum generality, by
allowing the user to map essentially any type of HID input, through
multiple APIs.  That's why it has that horrendous command-line syntax
where you have to specify the API, button name, and GPIO port for
every input you want to monitor.  You *could* add the same sort of
thing in an existing program, but I don't recommend it.  Instead, I'd
recommend using a simple "fixed" mapping, where you **pre-define** the
inputs you want to monitor and how they're assigned to BLT-II Pico
GPIO ports.  You then leave it up to the user to wire the BLT-II Pico
to the ports as you specify.  This means that the user doesn't have to
provide any new configuration input to your program, and your program
doesn't have to parse any new input.

For a pinball program, for example, you could decide that you only
care about testing latency for the flipper button inputs, and that
these must be wired on the BLT-II to ports GP0 and GP1, respectively,
for the left and right flipper buttons.  You instruct the user to wire
things so that the flipper buttons are connected to the BLT-II Pico on
GP0 and GP1.  There's nothing extra the user has to specify when
running your program, and no extra code in your program to parse new
configuration files or command line options.

Once you've decided on an input mapping strategy, the rest is pretty
straightforward.  The BLT-II add-in module is self-contained, and
you only have to add a few function calls to your program to make
it work.  Here's the procedure:

* Add the files `BLTVendorInterface.h` and `BLTVendorInterface.cpp` to your project

* In your program's startup code, call `ButtonLatencyTester2::VendorInterface::EnumerateDevices()`
to get a list of "descriptors" that represent the connected BLT-II Picos.  If you want to keep
things simple, you can assume that only BLT-II Pico is ever attached at once, and fail with an error if
the list is empty or has more than one entry.

* Open live connections to the BLT-II device or devices, by calling `Open()` on the descriptors
returned from `EnumerateDevices()`.  This hands you back a "device interface" object that represents
a live USB connection to the Pico.  This is what you use to communicate with the Pico later on
to notify it when you receive input events that it's monitoring.

* At the point in your application where you read input events from the Windows API, mark the
microsecond-clock time of each event by calling `ButtonLatencyTester2::VendorInterface::GetMicrosecondTime()`.
You should record this time for each event as soon as possible after calling the input API, since
this defines the "receive" end of the latency calculation.  If your application has its own
input processing layers that must be traversed before the application will be able to interpret
and respond to the event, you should take the time reading **after** traversing those layers,
since what you're really trying to measure here is how quickly the application can **react**
to an event.  For example, if you have a low-level routine that reads input from a Windows
API, but it then places the event in an internal queue that will be processed on another
thread, you should take the time measurement when the other thread receives the event.
The time that the event spends sitting in the queue contributes to the user's perception
of the latency, so it should be included in the time calculation.

* Once you have the timestamp, inspect the input event to see if it corresponds to one
of the events you're monitoring with the BLT-II.  If it does, call `HostInputEvent()` on
the device interface object you got back from the device descriptor `Open()` call earlier.
This call closes the loop on the event.

After a session, you can use a terminal program (e.g., PuTTY) to
connect to the Pico's virtual USB COM port to view the statistics
gathered during the session.  It's also possible to retrieve the
statistics within your program, but you probably won't want to bother
with that, since whatever program you're instrumenting probably
doesn't have a natural place in its user interface to display a screen
full of statistics.  It's probably not worth adding one, either, when
you can just use the built-in analysis tools in the BLT-II firmware.
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

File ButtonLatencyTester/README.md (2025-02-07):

# Button Latency Tester

This Pinscape Pico sub-project is a Windows program that
measures the latency of button presses on the Pico.  It's not part of
the official distribution, since I only developed it for my own
testing purposes: hence it's not documented, and it only covers the
narrow use cases I wanted to test.  But the source is here in case
anyone wants to attempt running their own tests with it, or wants to
use it as a starting point for similar tooling.

This program has been largely superseded by **Button Latency Tester
II**, which you can find in its own subfolder under the main project
folder.  BLT-II has many improvements on this one, including the
ability to measure latency to any sort of device (Pinscape or
otherwise, Pico or otherwise), and better precision at making the
measurements.  The BLT-II project has its own Pico firmware component
that turns a spare Pico into a testing tool, plus a Windows host
program works in conjunction with a BLT-II Pico to perform the tests.

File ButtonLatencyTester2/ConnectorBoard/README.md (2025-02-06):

# Button Latency Tester II Connector Board

This is an EAGLE design for a simple connector board for the Button
Latency Tester II software.  It implements the sample circuit plan
shown in the project page for connecting buttons to the BLT-II Pico
and the subject device (the button encoder device you're testing for
latency timing), using optocouplers for simultaneous triggering on
both devices.  The board provides wiring for up to four physical
buttons.

Each button has a four-pin connector, designed to accommodate a
Phoenix Contact MPT 0,5 screw terminal (MPT 0,5/4-2,54, part number 1725672).
I chose screw terminals because they're the easiest type of connector
to wire for temporary connections (fitting this board's mission as
a testing tool).  Plus, many of popular key/button encoder boards use
these same screw terminals, or something very much like them, so this
should make it easy to move your existing wiring over from an encoder
that's already installed in a pin cab (and then just as easily move
it back when you're done with the testing).

## Connection diagram

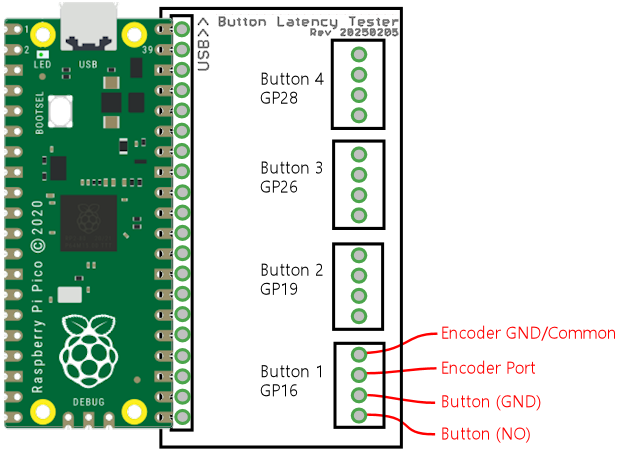
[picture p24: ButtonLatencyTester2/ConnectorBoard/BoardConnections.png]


## Pico installation

The Pico should be installed face-up as shown in the diagram.  The
board is designed to hold a 20-pin, 0.1" socket connector, such as
Wurth 61302011821.  (But it doesn't require that exact part - that's
a generic part with equivalents from other manufacturers.  You just
need a 20-position, 1-row, 0.1" pitch, female, through-hole header,
which you can find under the Headers & Wire Housings category at
Mouser or Digikey.)

Install a mating set of 0.1" pin headers on the **bottom** of the
Pico, so that you can install the Pico in the sockets face-up as
shown.  Installing pins on the bottom of the Pico is what most
people usually do anyway, for use in a breadboard.

Be sure that the Pico is installed in the correction orientation, with
the USB port at the "top" of the board as shown.  To save space on the
board (for lower cost), only one row of Pico pins connects to the
board.  The other row can just be left unconnected.

## Button wiring

Each button terminal has four pins:

* <b>Button (NO):</b> Connect the Normally Open (NO) terminal of the physical button

* <b>Button (GND):</b> Connect the Common (C or CMN) terminal of the physical button

* <b>Encoder Port:</b> Connect this to the button's input port on the subject device

* <b>Encoder GND/Common:</b> Connect this to the subject device's Common or Ground/GND terminal

You should only connect a normal mechanical switch, such as a
microswitch or a flipper button leaf switch, to a button terminal.
Standard Suzo-Happ arcade pushbuttons use microswitches, so they're
fine.  The only kind of "buttons" commonly found in a pin cab that
don't fit this description are the electronic 12V pulse switches
found in some fancy multi-currency coin acceptors - don't connect
those.  (But I doubt anyone is too interested in measuring latency
for coin acceptor switches anyway.)

The order of the terminals on button switch connections doesn't
matter, unless you're planning to daisy-chain the Ground/Common
connection on the buttons.  In that case, connect the daisy-chained
side to the "Button (GND)" terminals on the board.  All of the "Button
(GND)" terminals are wired together internally on the board, all
connecting to the Pico ground, so if your buttons also have their
grounds all connected together in a daisy chain, it's not necessary to
separately connect each button's ground wire to the board.  You just
have to connect any one of the button ground wires to any one "Button
(GND)" terminal on the board, and the others will all be connected
automatically through the daisy chain.  You can leave the rest of the
"Button (GND)" terminals unconnected.

When configuring the Windows-side button latency tester program, refer
to the diagram for the Pico GPIO port assignments corresponding to the
buttons.

## Encoder compatibility

This tester board is specifically designed to work with the wiring
conventions that almost all of the commercial and open-source button
encoder boards use: one button terminal connects to a common Ground
port on the encoder, the other connects to an button input port that's
"pulled up" to a positive logic voltage, usually 3.3V or 5V.  Pressing
the button closes the circuit by grounding the input port, which the
encoder reads as "button pressed".

Practically every button encoder I've encountered works that way, but
if you're not sure yours does, you should test it before connecting it
to this board.  This board will only work properly with encoders that
work as described, and it might be damaged by other arrangements.  To
test that your board works this way, try measuring the voltage between
the encoder's "common" or "ground" terminal and a free input port
that's not connected to anything.  It should read about 3.3V to 5V on
a voltmeter, with the positive voltage on the free button port and the
negative side on the common/ground port.  If that matches what you see
with a voltmeter, it should be safe to use the encoder with this
board.

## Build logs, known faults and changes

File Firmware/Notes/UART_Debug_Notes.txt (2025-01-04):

To debug USB connection issues at startup, the best approach is to
attach the Pico to a host COM port via a UART adapter.  UART to USB
adapters are available from Amazon and other sources.  You'll need a
terminal program like PuTTY to connect to the virtual COM port.

SOFTWARE SETUP

In tusb_config.h, uncomment the following two lines to enable full
logging in the Tinyusb library:

//#define CFG_TUSB_DEBUG 2
//#define CFG_TUSB_DEBUG_PRINTF tusbLogPrintf

HARDWARE SETUP

Plug the UART-to-USB adapter into the PC.  The UART should have three
or four wires, usually color coded as:

TX = Green
RX = White
GND = Black
5V = Red (not present on all adapters, DO NOT CONNECT TO PICO if present)

Check your device's documentation to ensure it uses the standard color scheme.

Connect TX, RX, GND to the Pico as follows:

RX (White) -> pin 1 = GP0 
TX (Green) -> pin 2 = GP1
GND (Black) -> pin 3

Pin 1 is the pin at "northwest" (top left) if you hold the Pico with
the USB connector face up and facing north.

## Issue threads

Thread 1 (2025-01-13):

Can you create a Github Discussions sections for Q&A

michaelkay, 2025-01-13:
This project is amazing. I started to implement PinScape using an Arduino but this is a much more complete implementation. Well done. Would you mind creating a Discussions section for Q&A? I have some specific questions about supporting additional accelerometers.

Thanks

mjrgh, 2025-01-14:
Great idea - done.

michaelkay, 2025-01-14:
Perfect. Thanks

Closed 2025-01-14.

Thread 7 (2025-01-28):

[bug] Pico Worker[0] not booting into Bootloader mode when attached to board (Mainboard DIY-friendly)

Rappelbox, 2025-01-28:
As the title already describes, I am not possible to force the pico (Worker[0] on DIY-friendly mainbaord) into bootloader mode by pressing the bootsel button when attaching the usb cable.
Thankfully i flashed the firmware before i soldered it to the board. For this reason i know it is functional as it is detected by the GUI.
The other 2 worker picos on the power board can be programmed without issues.

mjrgh, 2025-01-28:
Wow, I'm glad it worked out that you were able to program it before the bug kicked in.

Do you have any idea what the underlying cause is?  Is it that the aux Pico is getting powered from the main Pico, so it's not in RESET at the time you're plugging it in?  If that's it, can you get it into Boot Loader mode by this sequence?:

- Press and hold BOOTSEL on the Worker Pico
- Press and release the RESET button on the main board
- Release BOOTSEL

The RESET button SHOULD do a hard reset (via the RUN pin) on all four Picos, so that was intended to be the way to get any of the Picos into Boot Loader mode if you couldn't do it via software commands.  Once the firmware is loaded onto any of them, you can get them into Boot Loader mode by software command (assuming the software is working properly), but I'd definitely like to be sure you can do a hard Boot Loader reset on any of them as a failsafe against software failures.

mjrgh, 2025-01-28:
By the way, if the RESET button doesn't work, you should hopefully still be able to get any of the Worker Picos into hard reset by manually jumpering the RUN pin to ground.  But I don't want anyone to have to do that - I want to make sure the RESET button works as intended, so if that's not doing it we should definitely track down what's going wrong.

Rappelbox, 2025-01-29:
interesting find for the worker[0]:
bootsel + usb[0]  = no bootloader mode possible
usb[0] + bootsel + RESET button = no bootloader possible
usb[Main] + bootsel + usb[worker] = no bootloader possible, Worker is still powered by main, so this is as expected.
usb[all] + bootsel + RESET button = success!

This only applies to worker[0], worker[1,2] can be programmed if bootsel + usb[1,2] is plugged directly and main is unplugged

mjrgh, 2025-01-29:
Thanks for trying the various combinations.

Tell me if you disagree, but it looks to me like everything is working as expected.  Just to make sure we agree on the parameters, let's spell out how BOOTSEL works: BOOTSEL determines what the Pico does **during a power-on reset**, selecting between normal flash startup (BOOTSEL not pressed) and boot loader ROM startup (BOOTSEL pressed).  BOOTSEL has essentially no effect **except** when a power-on reset is in progress.  There are two ways to trigger a power-on reset cycle: (a) power-cycle the Pico; (b) ground the RUN pin. Crucially - this is where the various test cases you've been doing come in - unplugging and plugging the USB cable **doesn't** initiate a power-on reset by itself.  Cycling the USB cable is often listed as shorthand method for getting into BOOTSEL mode, but whenever I mention this, I always try to be careful to qualify it by saying "unplug the USB cable **and all other power sources**", because it's not the USB cable that gets you into BOOTSEL mode, it's the power cycle.  If the Pico is powered by some source other than the USB cable, cycling the USB cable doesn't interrupt system power, therefore doesn't initiate a power-on reset, and therefore can't enter boot loader mode, no matter what's going on with the BOOTSEL button at the time.  By design, the auxiliary (Worker) Picos on these boards are powered from the primary Pico's USB connection, so as long as the primary Pico is plugged into power, the aux Picos are also powered, so their USB connections can come and go without triggering resets.  So the only way to get one of these to reset is via the Reset button, which is wired to ground the RUN pin on each Pico.

Does that make sense?  Are there any cases you've observed that don't agree with this, where something needs to be fixed on the board?

Rappelbox, 2025-01-29:
I agree with you completely on all terms.

I tried those combinations exactly how i described them, maybe i did not explain detailed enough.
As a startup routine exactly and ONLY the mentioned parts are powered, meaning that in case 1 the worker[0] should boot into bootloader mode as there are no other power sources be it pico[main] or secondary power.

mjrgh, 2025-01-29:
Okay, so you're saying there is one case here where we do have an anomaly?  Namely **bootsel + usb[0]**?  I.e., nothing is connected to USB, you press and hold BOOTSEL, plug in Worker 0 USB, release BOOTSEL, it doesn't enter boot loader mode.  Very strange if so... I can't think of anything the board could be doing that's preventing boot loader mode in this case.  I mean, I don't even know how I could deliberately contrive to prevent boot loader mode in that case, since BOOTSEL is so hard-wired internally to the Pico itself.  It seems like the only way that it wouldn't go into boot loader mode is if a POR isn't occurring, and I don't know how you prevent a POR when power is first applied, so this seems to suggest that the Pico is getting power from somewhere.  I don't think there's nearly enough capacitance on the board to be powering it from capacitors.  I'll have to think about it, but I sure don't see any explanation off-hand.

Rappelbox, 2025-01-29:
Correct, for case 1 and 2 bootloader mode is not possible.
I don't know the exact reason. I'll inspect the board tomorrow to check if there is a hardware fault somewhere or a short.

mjrgh, 2025-01-29:
It would definitely be good to figure out what's going on.  Maybe check with a voltmeter when everything is unplugged to see if there's somehow a voltage at the VSYS on the Worker 0 Pico (which is connected to the cathode on D1).

I guess the only other possibility is that the BOOTSEL button signal is getting lost in this case, but I can't see how that's even possible, since that's completely internal to the Pico - it's not exposed on any external pins.  Even if something were shorted externally, it still shouldn't be able to touch the BOOTSEL wiring.

mjrgh, 2025-01-29:
One other possibility comes to mind: maybe the problem is that the Worker Pico isn't powering up at all from its USB cable.  So it's not that it isn't going into boot loader mode, but rather that it's just not in ANY mode, because it's not working on USB power.

I think we could test for this case as follows: unplug all cables from the board.  Plug in just the Worker Pico USB, **without** pressing BOOTSEL, to let it boot normally under USB power. Check the on-board Pico LED to see if it's blinking briefly every couple of seconds - that's the PWMWorker firmware diagnostic display for "standby mode" before it starts getting I2C instructions from the main Pico.  If the light is blinking, the Pico has power and the PWMWorker firmware is running.  If the light isn't blinking, I think the whole problem is that the Pico just isn't powering up from the USB cable at all, so it can't enter boot loader mode OR normal mode since it's simply not powered.

Rappelbox, 2025-01-29:
Good catch!
I just did a quick test before bedtime. Worker[0] doesn't boot at all when powered alone through usb. Reason needs to be determined.

mjrgh, 2025-01-29:
Great, that should narrow it down a lot.  Makes much more sense than a mysterious power source or something blocking the BOOTSEL wiring.

It seems like the main possibilities are (1) the USB port or USB cable aren't providing power, (2) the main board wiring is shorting the USB power supply to ground so that the Pico isn't getting power, or (3) the RUN pin is being pulled low when main power is off.

(1) should be easy enough to check by swapping cables and ports with the one you've been using for the main USB in, since that one seems to be working reliably.

(2) is probably worth checking with a voltmeter - test the Pico's 3V3 pin to see if it's at 3.3V when the USB is plugged in.  If it's not, there's probably something going on with the VSYS wiring.  I just double-checked the Powering Pico section in the Pico Datasheet to see if I screwed up the VSYS power input in the design, but it looks right as far as I can see.  So I guess you should check if D1 to make sure it's not installed backwards - if it were, I think it would be shunting VSYS to ground when no power is applied at the primary Pico VBUS, which would prevent the aux Pico from getting power.   The stripe side should be pointing towards the square pad, which is the USB-cable side of the board.
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
Rappelbox, 2025-01-30:
Removing R32 did the trick.

Before testing your suggestions i redid my tests and noticed that not only worker[0] can't be forced into bootloader mode, but instead none of the worker picos can be programmed.
In my initial programming i did it without the mainboard being attached so it worked back then.
USB cable was good as it was the same that i used as connection to the PC.

Conclusion: remove R32 from the layout

mjrgh, 2025-01-30:
Great, glad we have an explanation.  I'll delete the resistor from the layout.

mjrgh, 2025-01-31:
Some additional follow-up:  I just checked in a new rev of the boards that reworks the Reset scheme a bit.  The errant pull-up resistor in the old design was there because the RP2040 data sheet recommends an external pull-up on the RUN pin, to reduce the chances of electrical noise on the pin triggering a reset.  I haven't ever noticed that happening with my testing Picos (which don't have external pull-ups), but it seems like a good idea to follow their recommendations.  The problem with the old board was that I was pulling up all of the SEDONARY Pico RUN pins to the PRIMARY Pico's 3V3, which is fine as long as they're all powered, but triggered this bug when the primary Pico was unpowered (hence its 3V3 was at GND, driving the secondary Pico's RUN pin low and forcing it into reset).  So the new design adds back the pull-ups, but it gives each Pico its own isolated pull-up to its own 3V3.  That should accomplish the data sheet recommendation of providing a strong external pull-up, but still work properly regardless of the power status of the other Picos.

The initial simple solution of just removing the problem resistor works because the RP2040 has an internal pull-up on RUN, so you don't absolutely need an external one.  The data sheet wants you to add an external one because the internal one is weak, and they're worried that it's too weak to overcome 100% of noise on the pad.  If it's such a worry, I have to wonder why they didn't just make it strong enough to satisfy themselves, but here we are.  I think I got a little lucky that the design has exactly three aux Picos, because if there were four, I think the bug would manifest again even without the external pull-up.  The original design has all of the RUN pins on the three secondary Picos wired together in parallel, which means that the internal pull-ups are going to form a voltage divider when some of the Picos are powered and some aren't.  If we have two powered and one unpowered, the voltage divider puts the RUN pin at 1.1V, which is just a little above the 3.3V logic-low cutoff level of around 0.7V - not a big margin of safety, but probably enough for reliable operation when you're updating firmware.  It's NOT a problem in normal operation when all of the Picos are powered, since they're all going to be pulling to 3.3V.  But it still made me want to rethink the RESET network.  The simplest thing seemed to be to give each Pico a separate hard Reset switch and a separate NPN switch for the /PERIPHERAL_POWER_ENABLE control, since that isolates the RUN pins and lets each one have its own pull-up to its own 3V3 supply.

Closed 2025-01-30.

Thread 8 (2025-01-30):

Wrong SetPWMWorkerAddr output response

Rappelbox, 2025-01-30:
SetPWMWorkerAddr always responds with:
"Successfully updated device I2C address on D:\ to 0x10" no matter what address is passed.
Also happens when invalid address is passed.

Worker[1,2] not getting detected at 0x31 and 0x32 in log

mjrgh, 2025-01-30:
[SetPWMWorkerAddr-patch.zip](https://github.com/user-attachments/files/18606945/SetPWMWorkerAddr-patch.zip)

D'oh! I somehow deleted a key word in the line that parses the address, in such a way that the code still compiled (but got the address all wrong).   Should be fixed now - patch attached.

Rappelbox, 2025-01-30:
thanks! it works with the new file now as intended.

Important: defender detects a trojan, imo a false positive

mjrgh, 2025-01-31:
> Important: defender detects a trojan, imo a false positive

I assume so - there are no third-party libraries involved, just the Microsoft C++ native libraries.  According to the Web, this is a common false positive with .exe's built with the Microsoft compiler.  If you want to be sure, you can build the program yourself - it shouldn't require the Pico SDK, just Visual Studio with C++, and shouldn't have any outside dependencies outside of the git repos.

Closed 2025-01-30.

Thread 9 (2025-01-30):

ads1115 not being detected/configured

Rappelbox, 2025-01-30:
log: 2025/01/30 21:52:26 Error:   Plunger: no plunger sensor is available; at least one sensor type must be configured

this is the config for plunger and ads1115 sensor:

```
 plunger: {
         source: "ads1115",  // source sensor type; can be omitted if only one plunger sensor is configured
         autoZero: true,          // enable auto-zeroing; only applies to quadrature sensors, ignored otherwise
         autoZeroTime: 5000,      // time in milliseconds for auto-zeroing; plunger must be stationary this long to auto-zero
         powerLaw: 2,             // power-law exponent in brightness-to-distance calculation, only for VCNL4010
	// cannel: 0,
    },

    ads1115: {
        i2c: 1,                 // I2C bus 1
        addr: 0x48,             // I2C address, set on the chip via pin inputs, 0x48 to 0x4B
        ready: 11,              // READY pin GPIO
        channel: "AIN0/AIN3",   // plunger input = differential signal AIN0-AIN3
        voltageRange: 2.048,    // voltage range +/- 2.048V from the +1.65V AIN3 reference
    },
```

mjrgh, 2025-01-30:
Are you seeing any errors about the ADS1115 configuration?

Rappelbox, 2025-01-30:
No, this is the only error that shows up in the log but also no further information about the ads1115 being initialized so something like that.

mjrgh, 2025-01-30:
Hmm... hopefully that just means there aren't any errors, but let's make sure that it actually IS getting configured.  Make sure "config" is included in the logging.filter:

```
logging: {
    filter: "debug error warning info config",
}
```

With that, you should see some success messages for the ADS1115 in the startup reports.

If you have a CDC or UART serial port configured, you can also open a PuTTY window on the device and see if the ads1115 command is enabled - `ads1115 -s` should show the configuration and sampling statistics.

Rappelbox, 2025-01-30:
I noticed the configuration is different in the starter.json config file, maybe the difference calculation -2/2v and and configuration is not incorporated in the firmware? Just a guess.

mjrgh, 2025-01-30:
The firmware lets you tell it how the inputs are physically configured, either single-ended or differential.  Starter.json is just one possibility, showing the simpler single-ended setup.  The expansion board has a voltage splitter going to AIN3 that provides a 1.65V reference voltage, so that you can configure it with the AIN0/AIN3 differential setup and use the smaller amplifier setting - you basically get an extra bit of resolution by doing that, by cutting the voltage range from +/- 4V (relative to 0V GND reference) to +/- 2V (relative to the 1.65V reference on AIN3).  So the way you've got it in the snippet above is the right way for the expansion board.

Rappelbox, 2025-01-31:
putty result:
```
> ads1115 -s
ads1115: no such command (type 'help' for a list of available commands)
```

typing help doens't show any sign of ads1115 sensor

```
Command summary:

   74hc165           74HC165 input shift register chip diagnostics
   devtest           special development testing functions
   flash             display the byte contents of flash pages
   fsck              show flash data storage area status
   gamepad           HID gamepad emulation options
   help              list all commands, or show a command's usage details ("help <command>")
   hidstats          show HID status and statistics
   i2c0              I2C bus interface test functions
   i2c1              I2C bus interface test functions
   kb                HID keyboard emulation options
   lis3dh            show LIS3DH accelerometer status
   logger            set and view logger options
   loopstats         show main loop timing statistics
   ls                list files in the flash data storage area
   mem               show memory usage statistics
   nudge             Nudge device information
   out               set output port levels (simulate DOF commands)
   pindev            Open Pinball Controller HID device options
   reboot            hardware-reset the Pico
   rm                delete files from the flash storage area
   statusled         Status LED testing functions
   tvon              test TV ON functions
   version           show firmware and hardware information
   worker            Worker Pico control options
   xinput            XBox controller emulation options
```
looks to me like the ads1115 sensor is not being initialized by any routine so it can be configured but never gets called

Rappelbox, 2025-01-31:
bus scan on i2c1 shows that the address is correct

```
> i2c1 --bus-scan
Starting bus scan on I2C1
2025/01/31 11:30:44 Info:    I2C1 bus scan: found device at 0x18
2025/01/31 11:30:44 Info:    I2C1 bus scan: found device at 0x30
2025/01/31 11:30:44 Info:    I2C1 bus scan: found device at 0x31
2025/01/31 11:30:44 Info:    I2C1 bus scan: found device at 0x32
2025/01/31 11:30:44 Info:    I2C1 bus scan: found device at 0x48
2025/01/31 11:30:45 Info:    I2C1 bus scan completed

> i2c1 -s
Current device: 0
State:          Ready

Device 0: DS1307, addr 0x68
  TX/RX started: 1
  TX completed:  113
  RX completed:  0
  TX timed out:  0
  TX aborted:    1

Device 1: WorkerPico, addr 0x30
  TX/RX started: 1
  TX completed:  1
  RX completed:  0
  TX timed out:  0
  TX aborted:    0

Device 2: WorkerPico, addr 0x31
  TX/RX started: 1
  TX completed:  1
  RX completed:  0
  TX timed out:  0
  TX aborted:    0

Device 3: WorkerPico, addr 0x32
  TX/RX started: 1
  TX completed:  1
  RX completed:  0
  TX timed out:  0
  TX aborted:    0

Device 4: LIS3DH, addr 0x18
  TX/RX started: 66924
  TX completed:  0
  RX completed:  66924
  TX timed out:  0
  TX aborted:    0
>

```

mjrgh, 2025-01-31:
Yeah, it looks like the device is responding to I2C pings, so if you're not seeing any mention of it whatsoever in the log, I'd say the ads1115 config section just isn't getting scanned.

Did you run an error check in the config editor?  My first guess would be that there's just some JSON problem where the ads1115 block isn't in the right place or something, given that there are no errors.  If the ads1115 configurator were seeing the JSON section at all, it should acknowledge that in the log - and given that the device isn't getting configured, there should be logged error messages explaining why.  The complete absence of any sign of ads1115 in the log suggests that the section isn't getting scanned at all.  If you don't have any luck spotting the problem, post the full file and I'll see if I can spot it.

Rappelbox, 2025-01-31:
For testing purpose I used your original file and made only 2 changes:

1. corrected address for lis3dh to "0x18" instead of "0x4c"
2. removed commentation for plunger and ads1115

```
// Pinscape Pico - sample configuration for the Pinscape Pico DIY-Friendly Expansion Board
// Copyright 2024, 2025 Michael J Roberts / BSD-3-Clause license / NO WARRANTY
//
// This is an example of the typical hardware configuration for the
// Pinscape Pico DIY-Friendly Expansion Board.  This reflects the fixed
// wiring between the Pico and the peripherals built into the board.

{
    // Unit identification
    id:
    {
        // Every configuration should have a unit number, to identify the
        // device to DOF.  Assign unit #1 to the first Pinscape Pico in your
        // system, 2 to the second, and so on.  (Don't count KL25Z Pinscape
        // units here.  DOF treats the KL25Z and Pico versions as separate
        // devices, so the Picos get their own numbering starting at 1.)
        // The numbering should always start at 1 and go up sequentially
        // from there, because it'll make things easier to set up with DOF.
        unitNum: 1,

        // The unit name is just for display purposes, to help you tell
        // your Pinscape Pico units apart if you have more than one.  The
        // name will be displayed when the Config Tool or other tools list
        // the available devices on-screen.  The name can be whatever you
        // want, but it's best to keep it fairly short, since it's used to
        // label small UI elements, such as buttons.
        unitName: "Expansion Board",

        // Emulated LedWiz ID.  This is for use by an LedWiz API emulator
        // on the PC host, which provides a virtual LedWiz interface for
        // legacy LedWiz-aware applications that can't access the Pinscape
        // Pico through either DOF or the Pinscape native interfaces.  An
        // LedWiz emulator on the PC can make the Pico appear as an LedWiz
        // to such older applications, allowing those apps to program
        // feedback effects through the Pinscape output ports.  This sets
        // the LedWiz ID, 1 to 16, for the virtual LedWiz.  An LedWiz unit
        // only has 32 ports, so if the Pico is configured with more than
        // 32 logical outputs, the LedWiz emulator will create multiple
        // virtual LedWiz units, one for each group of 32 Pico ports.
        // The additional units will be numbered sequentially starting
        // with the ID assigned here.
        //
        // Note that the Pico doesn't directly emulate the LedWiz USB
        // protocol.  Instead, the emulation is done on the host side.
        // On Windows, this is implemented through an open-source
        // replacement for the LEDWIZ.DLL that comes with the genuine
        // LedWiz.  The replacement DLL is available here:
        //
        //   http://mjrnet.org/pinscape/dll-updates.html#LedWiz.dll
        //
        // If you also have a real LedWiz device in your system, or any
        // other device that emulates an LedWiz, you can change this
        // setting as needed to avoid conflicts with the other devices.
        // Each LedWiz in your system (real or emulated) must be given
        // a unique unit number.  Most real LedWiz units are hard-coded
        // to use unit #1, so you can avoid conflicts with those by
        // changing the Pinscape Pico to use unit #2.  If you don't
        // have any conflicting devices, though, it's better to leave
        // this at the default setting of unit #1, because some of the
        // older LedWiz-aware software doesn't know how to access any
        // units except #1.
        //
        // To disable LedWiz emulation entirely for this Pico, set
        // ledWizUnitNum to 0.
        //
        ledWizUnitNum: 1,
    },

    // USB settings, setting the USB device identifiers that Windows
    // uses to identify the device.  The only reason to change these
    // from the defaults is that you have another unrelated device in
    // your system that's using the same numbers.  That should never
    // happen, because the default VID/PID were carefully chosen and
    // registered to avoid conflicts with other devices that follow the
    // USB registration rules.  But some devices don't follow the rules,
    // so conflicts are possible.
    //
    // usb: {
    //   vid: 0xFAFA,
    //   pid: 0xEAEB,
    // },
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

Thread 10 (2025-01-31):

Very first I2C communication fails

michaelkay, 2025-01-31:
I have set up different Pico configurations and I2C interfaces. I have found that the first I2C transaction always fails with a PICO_ERROR_GENERIC. It doesn't affect the steady state run but initialization can show false error messages. Test setup: LIS3DH setup as the only I2C device (nudge device). Buttons and LED definitions don't matter. Log will show
_Error:   LIS3DH device initialization failed; interrupt GP18, dynamic range +/- 2g_

I tested and confirmed by adding the following to LIS3DH.cpp around line 165.

		Log(LOG_DEBUG, "LIS3DH: Read WHO_AM_I (reg 0x0F)=0x%02x 0x%02x\n",
			i2c_write_timeout_us(i2c, i2cAddr, buf, _countof(buf), true, 4000),
			i2c_read_timeout_us(i2c, i2cAddr, &whoAmI, 1, false, 1000));

This may be a SDK error. I am using the 2.1SDK setup from the PinScape documentation. The other accelerometers don't seem to be affected because there is a read loop in the init routines that can get past this error case. But, this may affect other I2C startup routines from the other interface devices.

Also it may be the cause of
[https://github.com/mjrgh/PinscapePico/issues/9](https://github.com/mjrgh/PinscapePico/issues/9)

Rappelbox, 2025-01-31:
What i2c-address did you use?
I have the lis3dh working here in combination with the diy-expansion boards.

mjrgh, 2025-01-31:
I haven't seen any I2C-related problems in the 2.1 SDK, so I doubt that's it, especially if other I2C devices are working for you.  So I'd probably take the error at face value and assume that the hardware isn't responding.

If you've enabled the CDC or UART terminal, you can open a terminal session and do a full scan of what's on the bus via `i2c0 --bus-scan` (or `i2c1` as needed).  That should tell you if you've got the wrong address or the device just isn't responding at all.

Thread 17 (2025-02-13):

Invalid attribute in PCA9555 config section

jueank, 2025-02-13:
The ConfigTemplate file 'PinscapePico KL25Z Adapter - 74HC165 vsn.json' contains initialOut in the pca9555 section. This is marked as an error when trying to save to the Pico. Not usre if this is really an issue. I'm using the current configTemplate with the GUIConfigTool from v0.12 release.

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

mjrgh, 2025-02-13:
Looks like it's missing from the doc/schema file.  I'll add it.  (You can just ignore the error message from the editor in the meantime - the software will parse it correctly, or hopefully will anyway!)

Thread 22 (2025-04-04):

Request: Gamepad Hat Support

richt314, 2025-04-04:
I have a (somewhat unique, admittedly) application that would benefit from having a d-pad / POV Hat handled by the virtual gamepad device rather than cursor keys in the keyboard emulation, generic gamepad buttons, or d-pad in xinput.  Any thoughts about adding Hat support?

I could probably hack at the source to implement this as a one-off for myself, but figured I'd check and see if there were any plans or interest in bringing it to the wider audience.

mjrgh, 2025-04-04:
I could add that to the base gamepad object pretty easily.  I'd want to think about it a little first to make sure there wouldn't be a downside, but off-hand I can't see any obvious problem with it.  I think the ideal would be to make the gamepad usage list itself configurable, rather than using the current fixed layout, but there are some definite downsides to that, mostly that some of the PC-side software (like DirectInput) is coded to assume that a given device always has the same HID report layout (a safe assumption for a physical gamepad where the button layout is fixed in its physical form).

You'd just want a hat control that's essentially a set of four additional on/off buttons, I assume?  )As opposed to another set of analog X/Y axes.)

richt314, 2025-04-05:
Yes, I'm looking for a digital hat, four directional on/off buttons.

I'm using my Pinscape Pico with an embedded Linux machine, which can only see the first 16 buttons of the HID gamepad (plus the analog axes). These are mapped to gamepad buttons (shoulder buttons, start, select, A/B/X/Y, etc) by the Linux input driver. So by tweaking the Pinscape Pico configuration, I can tweak my buttons to match the gamepad buttons I want, but I can't map anything to directional controls since the Input driver is looking for an HID hat control which doesn't exist.

If Pinscape Pico had a hat control, I wouldn't need to go out of my way to remap extra gamepad "buttons" to directional controls, leaving all the mapping on the Pinscape side, and I would avoid spending four of the 16 buttons the system could see on my cabinet's d-pad.

mjrgh, 2025-04-05:
I took a quick look at the HID usage tables, and they're pretty vague about how hat switches are supposed to be mapped.  Actually, they're COMPLETELY vague; they just assign Hat Switch a usage code (Generic Desktop Page, usage 0x39) and apparently leave it up to applications to define it.

A little more web searching says that the common practice is to map the hat switch to a field with 9 values, so a 4-bit field with logical min/max 0/8 or 1/9, with the integer values representing the compass points counterclockwise, starting at north, with the minimum value being neutral.  So with a logical range 0..8, it would be 0=neutral, 1=N, 2=NW, 3=W, 4=SW, 5=S, 6=SE, 7=E, 8=NE.

To map this to four physical button inputs on the Pinscape side, the gamepad layer would take the four button states and generate the corresponding compass point value.  Note that this means that you don't actually have four buttons per se in the final HID input to the PC, since almost half of the 16 possible button states can't be represented in the 9-state HID input.  For example, pressing the N and S button simultaneously can't be represented as a value state.

This would all be pretty straightforward to implement, but given how specific your use case is, AND given that none of the Windows pinball programs even know what a hat switch is, I'm thinking that I should probably let you implement a custom test run first, if you're up for that, to make sure that this proposed mapping actually works for you.  It sounds from your description that what you really want is a set of four additional buttons, and the hat switch doesn't really accomplish that fully, given the limitation that it can't represent all 16 states of four orthogonal buttons.  So I'm a little hesitant to implement it because I'm worried that you'll try it out and find that it doesn't do what you wanted after all - if it doesn't, I think it'll end up being dead code, since I don't think anyone on Windows will have any use for it either given the limitations of the PC pinball programs.

richt314, 2025-04-05:
I see what you mean, the implementation of a hat switch in the HID descriptor from four directional buttons is interesting:
https://pit.uriba.org/uriba/road-to-fcc-part-ii-hid-shenanigans-a-tale-of-a-hat-switch/

A four-way (or 8 way with two buttons at once) directional pad (where pressing opposing up/down or left/right switches at the same time is physically impossible) is exactly what I'm trying to accomplish, for reasons of navigating menus and other normal d-pad tasks. So I see that I would have to map a set of four gpio inputs to a 0-7 range (plus 8 for the no-input case), assuming that page is correct.

I'm happy to try to hack something together. I can almost guarantee it won't be pretty, but maybe enough of a proof-of-concept to show that it's useful.

mjrgh, 2025-04-05:
Yeah, that looks like yet another set of conventions - this one is 0-7 with 8 as the Null.  I'm curious how flexible the host-side drivers are about interpreting all of these different conventions.

I think I can put together an initial rough implementation pretty quickly.  That should give you a framework to start with, and you can modify it as needed to get it working with your host.  I suspect your host is going to be less flexible than Windows about the report format, but I should be able to at least verify that it works with the Windows joystick clients, so hopefully it won't need more than some small adjustments.

richt314, 2025-04-05:
If you're willing to do that, that would be great. I can play around with a couple different configurations to see how Windows and this particular embedded Linux system respond to them. I can try out the gamepads and joysticks that I have with hat controls as well, try to figure out what the prevailing convention is among them and how the different operating systems respond.

I appreciate all the help and insight. This started with just interfacing an analog plunger (where my cabinet used to have a digital button instead). Out of curiosity I tried running a flipper button through my Pico as well, and noticed that I could squeeze out 1-2 frames of latency (at 60 Hz) compared to the original interface. Now I'm trying to get everything switched over. Not that I need super fast latency on a d-pad, but it would be nice to have everything unified on a single controller.

mjrgh, 2025-04-05:
I put together a test version for you to try - it's on branch [hat-switch](/mjrgh/PinscapePico/tree/hat-switch).  I figured I'd provide it in source form so you could tinker with the details of the HID mapping if that turns out to be necessary.  That's in firmware/gamepad.cpp, search for "hat" to find the affected code sections.  I did a little quick test with the Windows joy.cpl tester, and it seems good there, but we'll have to see if your Linux setup accepts it.

I'm glad to hear you've had good results with respect to latency so far.  I tried to make sure button latencies were as low as possible, but it's always good to find out it's working in the real world as well!

richt314, 2025-04-06:
Great, thank you!  I'll give it a try when I have a chance and will let you know how it goes.

richt314, 2025-04-08:
Still a little testing to do, but after I got the project to build, the hat switch is showing in Windows and Linux!

Only one big issue with functionality, the rotation "around the axis" was inverted in both the Windows "Game Controllers" dialog and in the embedded Linux system (essentially, left and right were swapped).  I did a little more looking, and the sources I see online seem to suggest a clockwise rotation from "North".  So I inverted the mapping in the firmware source, and all seems to be well.

In Gamepad.cpp, starting at line 305:
`        static const uint8_t hatSwitchMap[] {
            // HID    Angle  Dir   R L D U   Hex
            0,     // NULL   NULL  0 0 0 0   0x00
            1,     // 0      N     0 0 0 1   0x01
            5,     // 180    S     0 0 1 0   0x02
            0,     // NULL   NULL  0 0 1 1   0x03
            7,     // 90     W     0 1 0 0   0x04
            8,     // 45     NW    0 1 0 1   0x05
            6,     // 135    SW    0 1 1 0   0x06
            0,     // NULL   NULL  0 1 1 1   0x07
            3,     // 270    E     1 0 0 0   0x08
            2,     // 315    NE    1 0 0 1   0x09
            4,     // 225    SE    1 0 1 0   0x0A
            0,     // NULL   NULL  1 0 1 1   0x0B
            0,     // NULL   NULL  1 1 0 0   0x0C
            0,     // NULL   NULL  1 1 0 1   0x0D
            0,     // NULL   NULL  1 1 1 0   0x0E
            0,     // NULL   NULL  1 1 1 1   0x0F
        };`

Interesting that it seemed to be working when you tested - did you test "left" and "right" directions?  I am fairly certain this isn't a case of me mapping my buttons backwards, the correct buttons were showing in the "Buttons" tab of the config tool.

Other than that, the GUIConfigTool complains about the hatSwitch property in the config (though ignoring the error works fine).

A few notes about the build process, not sure if these are expected issues or not, but they tripped me up when following the "How-to-build" document:

- I used your pico-sdk-2.1.0.  I had to edit PICO_INSTALL_PATH in version.ini to match where I had unzipped the SDK before pico-env.cmd would work.  Took me a bit to figure out since it wasn't in "How-to-build", but I guess if I had looked in README.md of the SDK I would have figured that out sooner.
- I had to copy "pick_sdk_import.cmake" from pico-sdk to the Firmware folder before cmake would work.  I see a recommended procedure elsewhere of creating a symlink to the file within the SDK.
- Visual Studio kept failing to build the rest of the project, particularly GUIConfigTool.  It came down to ConfigDocParser failing to create GUIConfigTool\Generated\ConfigSchema.h.  After some playing, I figured out that I had to create the (empty) "Generated" folder first, then the build process worked fine.

Like I said, I'll do some more playing around, but initial indications are this seems to be a worthwhile feature to me, and working well.  I'll let you know how it works out for my use case as I have more time to play around.

mjrgh, 2025-04-08:
Glad to hear it's (mostly) working so far!

> (essentially, left and right were swapped)

I just double-checked it, and it is indeed reversed on my system as well.  I must have just seen what I was looking for, that the left and right buttons were activating the horizontal axis, and ignored that they were backwards.  I'm glad you found that Windows and Linux were consistent on how the coordinate system is interpreted.

Thanks for the notes on the build hurdles - I'll fix/document those...

> I had to edit PICO_INSTALL_PATH

Yeah, that's mentioned in the README.md in the SDK download itself.  I'll add a note to How-to-build that there are some extra steps required, with a pointer there.

> I had to copy "pick_sdk_import.cmake" from pico-sdk to the Firmware folder

I guess I did that so long ago that I forgot it was a required step.  I think I'll just add that to the source tree since it seems like Raspberry Pi intends for it to be used that way.

> I figured out that I had to create the (empty) "Generated" folder

I'll add that to the source tree as well.

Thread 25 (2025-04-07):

Key Chords in new Version

StifflersM0M, 2025-04-07:
Hi!

I just tried the new Key CHords instead of a Macro, but it seems it is not working.
i added

> 	 {
             source: { type: "gpio", gp: 13 },        	  // button is wired to GPIO port GP13
             action: { type: "key", key: "Ctrl+X" },
         },

But within the buttons view the GPIO is marked as "none". Also when pushing the button the key are not displayed.
I tried to cut a text in Notepad, but does not worked.

mjrgh, 2025-04-07:
What does the log say about it?

StifflersM0M, 2025-04-07:
Sorry. After looking into the log, i saw, that i was still on the old firmware. I just copied the FIles into my folder and forgot to flash the Firmware onto the board.

Thanks!

Closed 2025-04-07.

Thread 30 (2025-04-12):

Nudge section: vertical scrollbar missing

winxi01, 2025-04-12:
At my 1920 x 1080 display I've to hide the taskbar to be able to hit the "Calibrate" button in the Nudge section of the Config Tool (v0.1.11). A vertical scrollbar in the Nudge section would solve this.

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

mjrgh, 2025-04-21:
Good point - added in v0.1.12.

Closed 2025-05-03.

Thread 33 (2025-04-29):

Minor typo in the DIY-friendly Main Board BOM

winxi01, 2025-04-29:
In row 27, column "Parts",
`PLUG_J9`
should be
`PLUG_J1`
and in column "ExtDescription",
`IDC housing, 0.1", 2x8 (PLUG_J9)`
should be
`IDC housing, 0.1", 2x8 (PLUG_J1)`.

mjrgh, 2025-05-02:
Thanks for catching that!  Should be fixed now.

Closed 2025-05-03.

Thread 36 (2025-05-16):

Error opening file "config.json" for reading: CRC failure (stored 2144df1c, computed a67fc7e9)

mkotek, 2025-05-16:
Given the situation with new KL25Z Rev. I being useless, I have tried to switch to Pico. The only thing I had on hand is RPi [RP2040-Zero (Pico clone)](https://pl.aliexpress.com/item/1005003823256706.html), which was recognized fine and firmware upload has been successful. When trying to update the configuration, it seems to run fine, but then the log file shows error: Error opening file "config.json" for reading: CRC failure (stored 2144df1c, computed a67fc7e9) and the configuration is not stored.
I have tried to use the command line tool and all seems to go fine, yet the moment I try to reload the configuration using GUI, the error shows again.

First of all, is Zero even supported? If so, why am I getting file system corrupted information?

mjrgh, 2025-05-16:
I haven't tried it on that clone.  The AliExpress page you linked to isn't working, so I can't tell if you have a genuine clone or a clone of a clone (Waveshare seems to claim credit as the "original" RP2040-Zero clone, with their warning about counterfeits of their clones).  From the CRC error, it sounds like the flash-erase-write that the firmware has to do to store the config data isn't working properly, either not storing anything or storing garbled data.  If you want to do some debugging, you can connect a PuTTY terminal to the Pinscape command console (see **Serial Ports** in the JSON config reference), and take a look at what's in flash.  Use **ls** to get the file list; that'll tell you the starting location (StrmAddr) for the config file (config.json).  Than you can use **flash _addr_** to display portions of the data stored there.  The config file is stored contiguously starting at the stream address, so you can look through it to see if it looks the data is stored at all, and if so, if it looks corrupted.  **ls** will also check the CRC and report on validity.

mkotek, 2025-05-16:
Thank you for the immediate response. How do I define the virtual COM port? I have this in the definition:
        usb: {
            logging: true,       // enable logging on this port
            console: {
                enable: true,    // enable the interactive command line on this port
                bufSize: 2048,   // buffer size for console output
            },
        },
    },

mjrgh, 2025-05-16:
> How do I define the virtual COM port?

See **Serial Ports** in the doc.

mjrgh, 2025-05-16:
I should add: if the JSON isn't getting stored, you probably won't be able to get the serial port working, since the firmware won't be able to load the JSON that isn't getting stored.  I don't think you'll be able to use that board if that's the case - either it's a broken specimen, or that particular clone is just incompatible after all.

mkotek, 2025-05-16:
The latter might be the case, the AliExpress link should work (it works for me, but it was just an example, not the actual seller I got the board from).

mjrgh, 2025-05-16:
If you want to get really into debugging it, you can create a custom firmware build that enables the serial ports without a config file. You'll have to install the Pico SDK and build environment and build the firmware from source, but that shouldn't be too difficult if you use my build environment setup guide (see **How-to-build.md** on the main github page).  With a custom build, you can set the "factory" settings to anything you like by populating the **factoryConfig[]** string defined at the top of **Config::Load()** in firmware/config.cpp.  Just put in the same serialPort section that you'd normally put in the JSON file to enable the ports.

mjrgh, 2025-05-16:
One more data point you can look at is the boot log. When you boot the device, the first couple of lines in the log should have info on the flash chip detected, including ID and size. Do you see anything there?

mkotek, 2025-05-16:
Do you mean this:
Info:    Flash JEDEC ID: Mfg ID 68, Dev ID 10, Capacity ID 15

mjrgh, 2025-05-16:
Exactly - that's part of it, at least. There might also be an "SFDP basic parameters table" line, if the flash chip provides that (it's a quasi industry standard that some but not all chips implement).  At any rate, capacity ID 15 is the code for 2MB (1 << 0x15), so that much at least is fine. The manufacturer/device ID indicate that it's a different chip from the one that Raspberry Pi uses, so maybe that's the issue. But that shouldn't be a problem in principle, since the flash chip obviously has to be compatible enough that the boot ROM can successfully transfer firmware into it.  The Pinscape software invokes the same ROM code to transfer config data, so at that level it seems like it ought to be working.  I think the you'll probably have to get the console working so you can look at the flash contents if you want to investigate further.

mkotek, 2025-05-16:
Not sure it is worth continuing. I just had to try having useless KL25Z now. I am going to get the supported Pico to continue the tests and possibly an old working KL25Z to finish my cab, but thank you for the support.

mjrgh, 2025-05-16:
Yeah, I agree - I'm curious what the problem is, since it might be something simple to fix once diagnosed, but it'll be a lot less work to just get a regular Pico, and hopefully that'll just work well out of the box for you.

mkotek, 2025-05-17:
Is there any difference between getting Pico with micro USB port or USB C?

pt., 16 maj 2025, 20:11 użytkownik mjrgh ***@***.***> napisał:

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

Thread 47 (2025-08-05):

Pinscape PICO DIY Main/Power odd output results

BrainstormStudios, 2025-08-05:
HI all. I have built many projects in my time as well as arcade repair. I opted to do the DIY Friendly board set Main and Power. I did 2 sets and have sunk a good bit into them so I REALLY want to make this work. With my main board alone, I have good button input and results using the configuration template that appeared to be for this boards. For reference these are from the 20250203 revision. All appears to be good from the assembly standpoint but looking for some direction to getting the output side working as intended in case I may have missed something. What would cause some outputs to trigger when testing via the config tool and the rest no response. Note on each set of boards that were built, each pair has a different set of outputs that work and don't work. Any guidance is welcome as I REALLY want to make this work before saying it's a bad design and moving to a resiny made finished product. I design boards and write software so I understand things can go wrong on these types of projects.

BrainstormStudios, 2025-08-05:
I have made a new post. Thanks for the advisement. Haven't used GitHub for support before.

mjrgh, 2025-08-05:
Great, thanks.

Closed 2025-08-05.

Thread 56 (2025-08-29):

Support for MMA845X

Bandicoot37, 2025-08-29:
Hello
First Thanks a lot for this PinscapePico
My KLZ25 dead after my PSU burnt ^^
I've build a setup with a veroboard and all I need for me ( Plunger , IRremote and Nudge ) work like a charm , so many thanks ;)
But for nudge  i've make a mistake when i bought my accelerometer , i've bought a MMA845X insteed of MMA8451Q
Do you think in future you'll add this or not?

mjrgh, 2025-08-29:
From what I can tell, there's no such thing as a "MMA845X" chip as such; it's just a generic term for the MMA854* family of chips (the "X" means "wildcard").  Do you know the specific version of the chip you have?  There might be markings on the chip that you can use to figure out which it is.  The Pinscape code is specifically for the MMA8541Q, but it might work on the other chips in the series, since the manufacturers often reuse the same register in related chips.  So you might give it a try and see if you can it working as is.  If that doesn't work, see if you can identify the specific chip you have and see if there's a data sheet available.  We can see what kind of changes would be required.  If the differences are minor enough it might be something I could add.

Bandicoot37, 2025-08-29:
yes mine is MMA8542

Bandicoot37, 2025-08-29:
OK go it work ^^
i use @shermand100  config and change
 mma8451q: {
        i2c: 0,
        addr: 0x1D,
	interrupt: 3,
        gRange: 2,
     },
to
 mma8451q: {
        i2c: 0,
        addr: 0x1C,
	interrupt: 3,
        gRange: 2,
     },

^^

So just change addr: 0x1D to 0x1C and now it's working , thanks

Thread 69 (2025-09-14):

output stops working with pulseMode feature

winxi01, 2025-09-14:
Hi, I'm now setting up the contactor outputs using sharegroups and I would like to make use of the pulseMode feature for the flipper outputs. It works quite well and it seems to be possible to replicate the on- and off-clonks quite well by adjusting tOn and tOff accordingly.
However, it happens that the output doesn't work anymore after the flipper buttons are pressed in quick succession. The ouput then stays on and the Pico has to be resetted to make it work again.
I could reproduce this with two simple outputs:
```
{
   device: { type: "workerPico", unit: 0, port: 22 },
   shareGroup: "test",
   noisy: true,
   name: "cbr",
},
{
   device: { type: "shareGroup", group: "test", pulseMode: {tOn: 30, tOff: 22, }, },
   name: "test",
},
```

mjrgh, 2025-09-14:
I gave it a quick try, and I couldn't trigger the problem, so there must be something more to it.  Are you able to reproduce it without DOF Involved, just firing the ports from the config tool?  How about if you change the physical output to a GPIO instead of a Worker Pico?  And how fast exactly is "quick succession"?

winxi01, 2025-09-14:
> Are you able to reproduce it without DOF Involved, just firing the ports from the config tool?

Couldn't reproduce it with the config tool. It's difficult to test with the config tool, because with the sliders it's not possible to go directly from 0 to 255 and I don't know how Pinscape handles the values in between with shared groups and when pulseMode is active. For this and other test scenarios it would be helpful to have an additional button in the config tool for each output which allows to toggle the corresponding output between 0 and 255.

However, I defined a button as source and with this I was able to reproduce it without DOF being involved. For the test, I had three ouputs defined:
```
outputs: [
   // Output #1
   {
      device: { type: "workerPico", unit: 0, port: 10 },
      shareGroup: "cbl",
   },

   // Output #2
   {
      device: { type: "workerPico", unit: 0, port: 9 },
      source: "port('Flipper Left')"
   },

   // Output #3
   {
      device: { type: "shareGroup", group: "cbl", pulseMode: {tOn: 30, tOff: 22, }, },
      name: "Flipper Left",
      source: "button('left flipper', 255, 0)",
   },
],
```
I've done a [short video](https://drive.google.com/file/d/17wXj5n2q0RT6F2hSSglZCrvhjZkbFzeb/view?usp=drive_link) where you can see the results of the test. In the DOF Config Tool, I've assigned just `P:003` to "Flipper Left". The yellow lamp on the left is wired to `device: { type: "workerPico", unit: 0, port: 9 }` (`Output #2`) and shows directly the value of `Output #3` and the green lamp is wired to `device: { type: "workerPico", unit: 0, port: 10 }` (`Output #1`) and shows the pulses processed by `pulseMode`. The triggered button is the button with name `'left flipper'`.
In the end, it can be seen that `Output #1` (green lamp) continues to stay on.

> How about if you change the physical output to a GPIO instead of a Worker Pico?

That's a good hint. However, in my device with the DIY-friendly main board, all devices and LEDs are driven by the Worker Pico. This means, that I've to re-wire things. Will be able to test this in the nex days.

> And how fast exactly is "quick succession"?

Unfortunately, I'm not sure how to measure and quantify this. But maybe you get an idea with the video above.

> Also, when it stops working, are there any other symptoms? For example, does the whole Pico crash and become unresponsive, or is just the one port that stops working?

The Pico is still working and responsive, just the one port stops working (can also be seen in the video).

winxi01, 2025-09-15:
Did a bit more testing and I think I found a reliable way to reproduce:

- The output window tester shows the port being stuck.
- It can also be reproduced with a regular gpio (monitored in the config tool, as you suggested).
- The port seems to get stuck when an on-puls is triggered before an off-puls has been finished. For testing this, you can set `pulseMode.tOff` to a high value, e.g. 1000. This way, I could reproduce it even with the slider in the config tool.

mjrgh, 2025-09-16:
Reproduced, and I think I found the problem and fixed it.  Test build attached.  Try it out when you get a chance and let me know if this fixes it for you.

[PulseSharedOutputFix.zip](https://github.com/user-attachments/files/22372904/PulseSharedOutputFix.zip)

winxi01, 2025-09-17:
> Try it out when you get a chance and let me know if this fixes it for you.

It works as expected now, couldn't reproduce a port being stuck with the patched version. Thank you very much for the quick fix!

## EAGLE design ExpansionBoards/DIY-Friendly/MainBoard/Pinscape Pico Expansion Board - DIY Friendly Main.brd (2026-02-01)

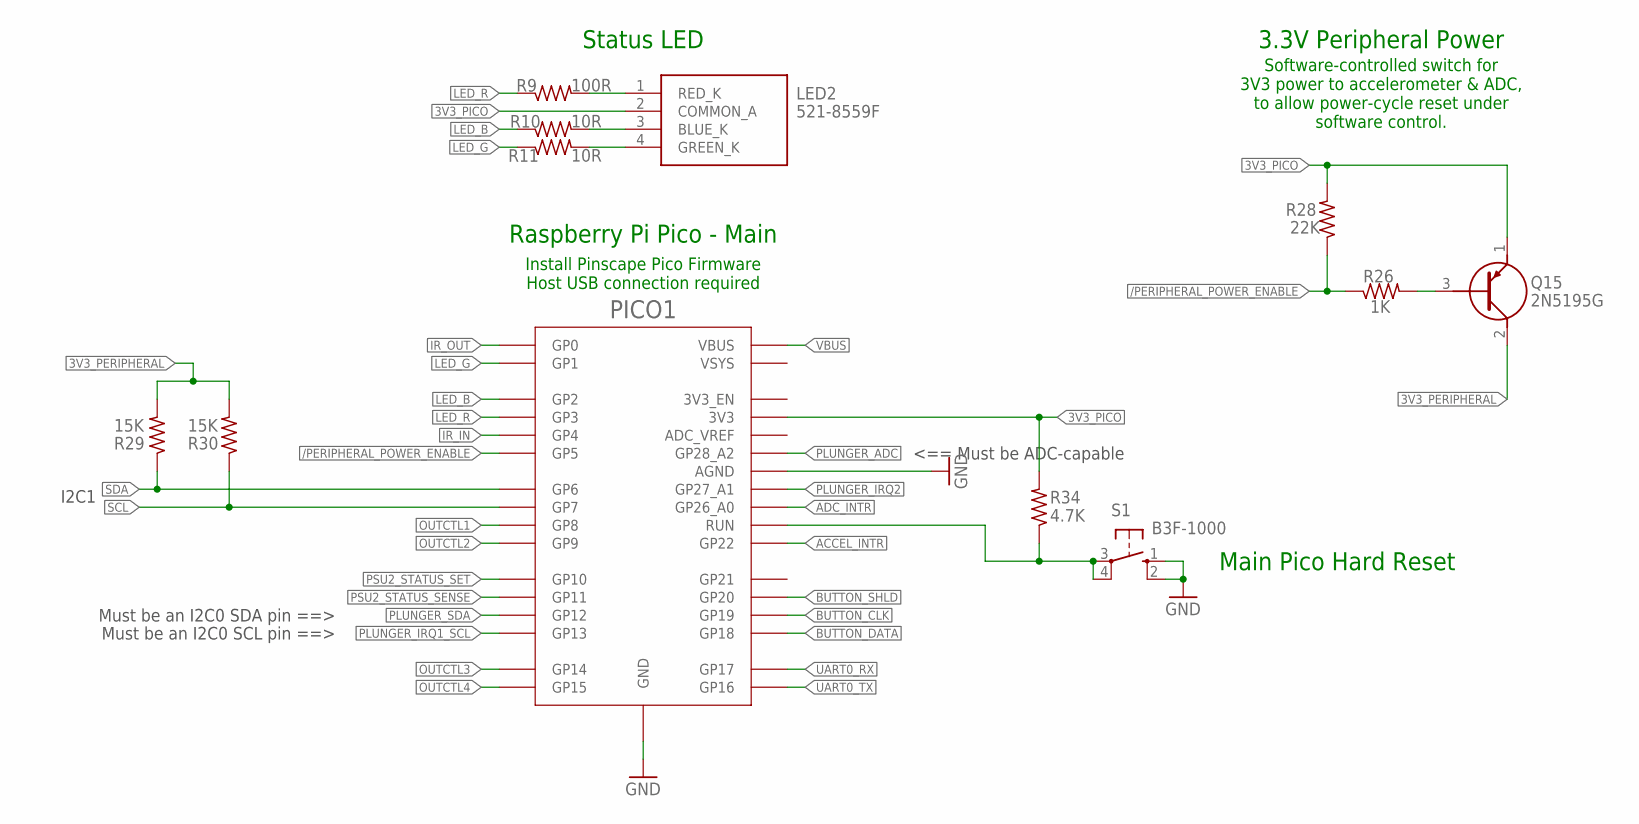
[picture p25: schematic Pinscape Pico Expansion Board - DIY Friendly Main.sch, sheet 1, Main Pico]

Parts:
LED2: 521-8559F; 5218559F
PICO1: RPI_PICO_NO_DEBUG; RPI_PICO_TH_NO_DEBUG
Q15: 2N5195G; TO229P300X760X1364-3P
R9: 100R; 0204/7; PARTNO MFR-12FTE52-100R
R10, R11: 10R; 0204/7; PARTNO MFR25SFTE52-10R
R26: 1K; 0204/7; PARTNO MF0204FTE52-1K
R28: 22K; 0204/7; PARTNO 660-MFS1/4DCT52R47R0
R29, R30: 15K; 0204/7; PARTNO MFR25SFRF52-15K
R34: 4.7K; 0204/7; PARTNO 660-MFS1/4DCT52R47R0
S1: B3F-1000; B3F-10XX

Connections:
3V3_PERIPHERAL: Q15.2 (C), R29.2, R30.2; also elsewhere on the board
3V3_PICO: LED2.2 (COMMON_A), PICO1.3V3, Q15.1 (E), R28.2, R34.2; also elsewhere on the board
/PERIPHERAL_POWER_ENABLE: PICO1.GP5, R26.1, R28.1; also elsewhere on the board
ACCEL_INTR: PICO1.GP22; also elsewhere on the board
ADC_INTR: PICO1.GP26_A0; also elsewhere on the board
BUTTON_CLK: PICO1.GP19; also elsewhere on the board
BUTTON_DATA: PICO1.GP18; also elsewhere on the board
BUTTON_SHLD: PICO1.GP20; also elsewhere on the board
GND: PICO1.AGND, PICO1.GND@1 (GND), PICO1.GND@2 (GND), PICO1.GND@3 (GND), PICO1.GND@4 (GND), PICO1.GND@6 (GND), PICO1.GND@7 (GND), PICO1.GND@8 (GND), S1.1 (S), S1.2 (S1); also elsewhere on the board
IR_IN: PICO1.GP4; also elsewhere on the board
IR_OUT: PICO1.GP0; also elsewhere on the board
LED_B: PICO1.GP2, R10.1
LED_G: PICO1.GP1, R11.1
LED_R: PICO1.GP3, R9.1
unnamed: LED2.1 (RED_K), R9.2
unnamed: Q15.3 (B), R26.2
unnamed: PICO1.RUN, R34.1, S1.3, S1.4 (P1)
unnamed: LED2.3 (BLUE_K), R10.2
unnamed: LED2.4 (GREEN_K), R11.2
OUTCTL1: PICO1.GP8; also elsewhere on the board
OUTCTL2: PICO1.GP9; also elsewhere on the board
OUTCTL3: PICO1.GP14; also elsewhere on the board
OUTCTL4: PICO1.GP15; also elsewhere on the board
PLUNGER_ADC: PICO1.GP28_A2; also elsewhere on the board
PLUNGER_IRQ1_SCL: PICO1.GP13; also elsewhere on the board
PLUNGER_IRQ2: PICO1.GP27_A1; also elsewhere on the board
PLUNGER_SDA: PICO1.GP12; also elsewhere on the board
PSU2_STATUS_SENSE: PICO1.GP11; also elsewhere on the board
PSU2_STATUS_SET: PICO1.GP10; also elsewhere on the board
SCL: PICO1.GP7, R30.1; also elsewhere on the board
SDA: PICO1.GP6, R29.1; also elsewhere on the board
UART0_RX: PICO1.GP17; also elsewhere on the board
UART0_TX: PICO1.GP16; also elsewhere on the board
VBUS: PICO1.VBUS; also elsewhere on the board

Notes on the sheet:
Raspberry Pi Pico - Main
Must be an I2C0 SCL pin ==>
<== Must be ADC-capable
Must be an I2C0 SDA pin ==>
Main Pico Hard Reset
Status LED
3.3V Peripheral Power
Install Pinscape Pico Firmware Host USB connection required
I2C1
Software-controlled switch for 3V3 power to accelerometer & ADC, to allow power-cycle reset under software control.

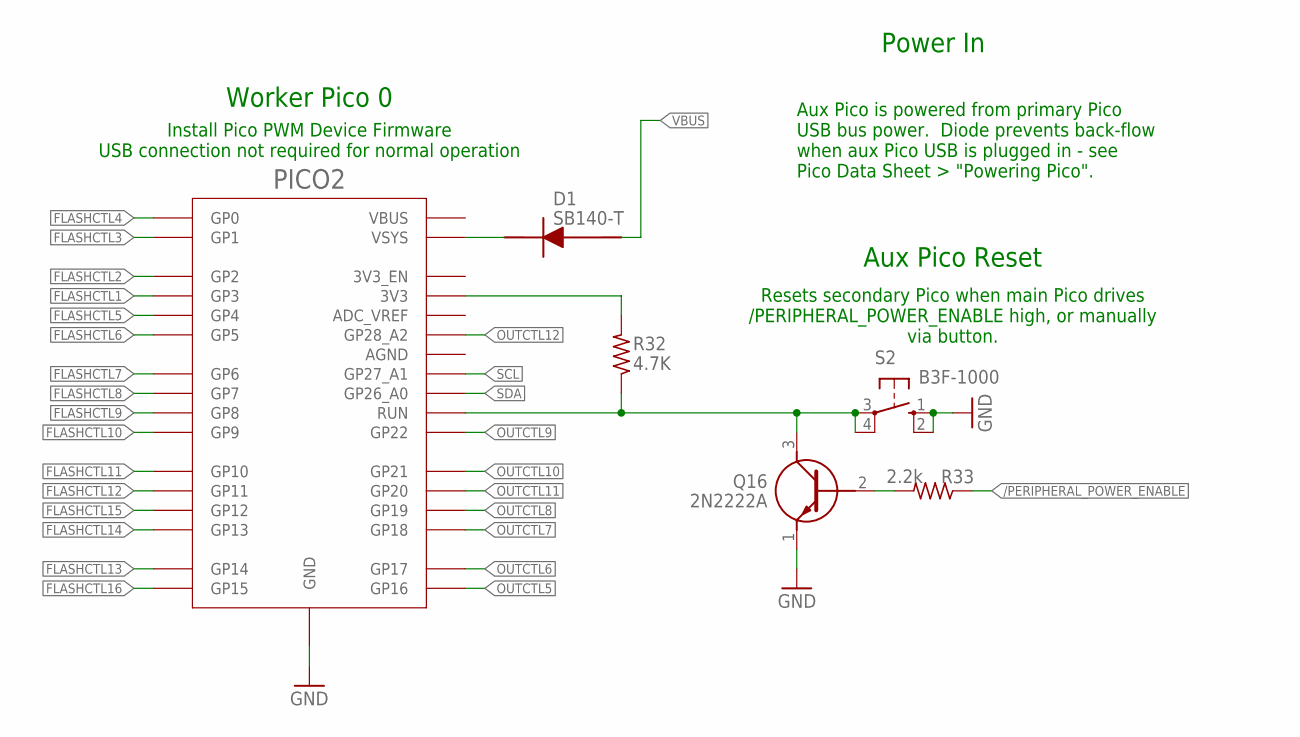
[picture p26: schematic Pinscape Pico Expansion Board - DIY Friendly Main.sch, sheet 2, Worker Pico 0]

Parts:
D1: SB140-T; DIOAD1408W86L464D236
PICO2: RPI_PICO_NO_DEBUG; RPI_PICO_TH_NO_DEBUG
Q16: 2N2222A
R32: 4.7K; 0204/7; PARTNO 660-MFS1/4DCT52R47R0
R33: 2.2k; 0204/7; PARTNO 660-MFS1/4DCT52R47R0
S2: B3F-1000; B3F-10XX

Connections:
/PERIPHERAL_POWER_ENABLE: R33.1; also elsewhere on the board
FLASHCTL1: PICO2.GP3; also elsewhere on the board
FLASHCTL2: PICO2.GP2; also elsewhere on the board
FLASHCTL3: PICO2.GP1; also elsewhere on the board
FLASHCTL4: PICO2.GP0; also elsewhere on the board
FLASHCTL5: PICO2.GP4; also elsewhere on the board
FLASHCTL6: PICO2.GP5; also elsewhere on the board
FLASHCTL7: PICO2.GP6; also elsewhere on the board
FLASHCTL8: PICO2.GP7; also elsewhere on the board
FLASHCTL9: PICO2.GP8; also elsewhere on the board
FLASHCTL10: PICO2.GP9; also elsewhere on the board
FLASHCTL11: PICO2.GP10; also elsewhere on the board
FLASHCTL12: PICO2.GP11; also elsewhere on the board
FLASHCTL13: PICO2.GP14; also elsewhere on the board
FLASHCTL14: PICO2.GP13; also elsewhere on the board
FLASHCTL15: PICO2.GP12; also elsewhere on the board
FLASHCTL16: PICO2.GP15; also elsewhere on the board
GND: PICO2.GND@1 (GND), PICO2.GND@2 (GND), PICO2.GND@3 (GND), PICO2.GND@4 (GND), PICO2.GND@6 (GND), PICO2.GND@7 (GND), PICO2.GND@8 (GND), Q16.1 (E), S2.1 (S), S2.2 (S1); also elsewhere on the board
unnamed: D1.1 (K), PICO2.VSYS
unnamed: Q16.2 (B), R33.2
unnamed: PICO2.3V3, R32.2
unnamed: PICO2.RUN, Q16.3 (C), R32.1, S2.3, S2.4 (P1)
OUTCTL5: PICO2.GP16; also elsewhere on the board
OUTCTL6: PICO2.GP17; also elsewhere on the board
OUTCTL7: PICO2.GP18; also elsewhere on the board
OUTCTL8: PICO2.GP19; also elsewhere on the board
OUTCTL9: PICO2.GP22; also elsewhere on the board
OUTCTL10: PICO2.GP21; also elsewhere on the board
OUTCTL11: PICO2.GP20; also elsewhere on the board
OUTCTL12: PICO2.GP28_A2; also elsewhere on the board
SCL: PICO2.GP27_A1; also elsewhere on the board
SDA: PICO2.GP26_A0; also elsewhere on the board
VBUS: D1.2 (A); also elsewhere on the board

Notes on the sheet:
Install Pico PWM Device Firmware USB connection not required for normal operation
Worker Pico 0
Aux Pico Reset
Resets secondary Pico when main Pico drives /PERIPHERAL_POWER_ENABLE high, or manually via button.
Aux Pico is powered from primary Pico USB bus power. Diode prevents back-flow when aux Pico USB is plugged in - see Pico Data Sheet > "Powering Pico".
Power In

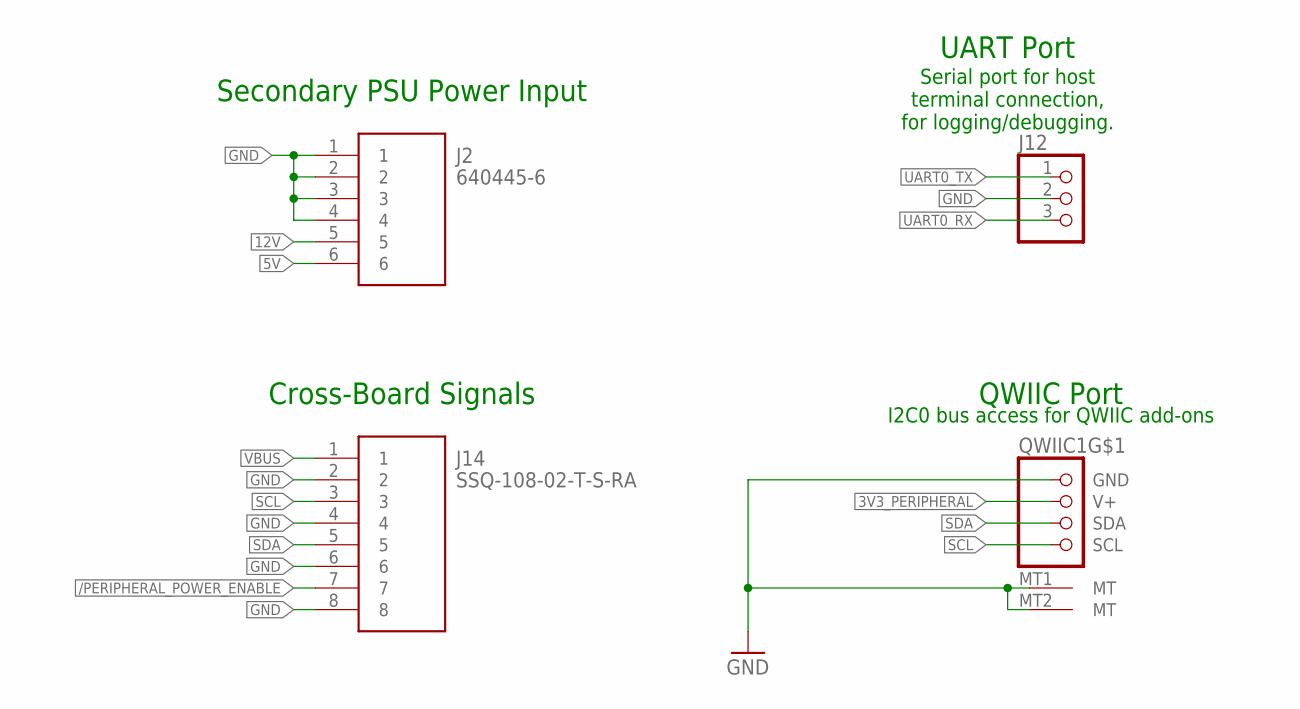
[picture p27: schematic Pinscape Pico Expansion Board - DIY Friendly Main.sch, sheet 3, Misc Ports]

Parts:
J2: 640445-6; SHDR6W183P0X396_1X6_2377X762X1
J12: PINHD-1X3; 1X03
J14: SSQ-108-02-T-S-RA; RHDRRA8W64P254_1X8_2083X851X24
QWIIC1: QWIIC; JST_SH4

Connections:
3V3_PERIPHERAL: QWIIC1.2 (V+); also elsewhere on the board
5V: J2.6; also elsewhere on the board
12V: J2.5; also elsewhere on the board
/PERIPHERAL_POWER_ENABLE: J14.7; also elsewhere on the board
GND: J2.1, J2.2, J2.3, J2.4, J12.2, J14.2, J14.4, J14.6, J14.8, QWIIC1.1 (GND), QWIIC1.MT1 (MT), QWIIC1.MT2 (MT); also elsewhere on the board
SCL: J14.3, QWIIC1.4 (SCL); also elsewhere on the board
SDA: J14.5, QWIIC1.3 (SDA); also elsewhere on the board
UART0_RX: J12.3; also elsewhere on the board
UART0_TX: J12.1; also elsewhere on the board
VBUS: J14.1; also elsewhere on the board

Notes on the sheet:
UART Port
Serial port for host terminal connection, for logging/debugging.
Secondary PSU Power Input
Cross-Board Signals
QWIIC Port
I2C0 bus access for QWIIC add-ons

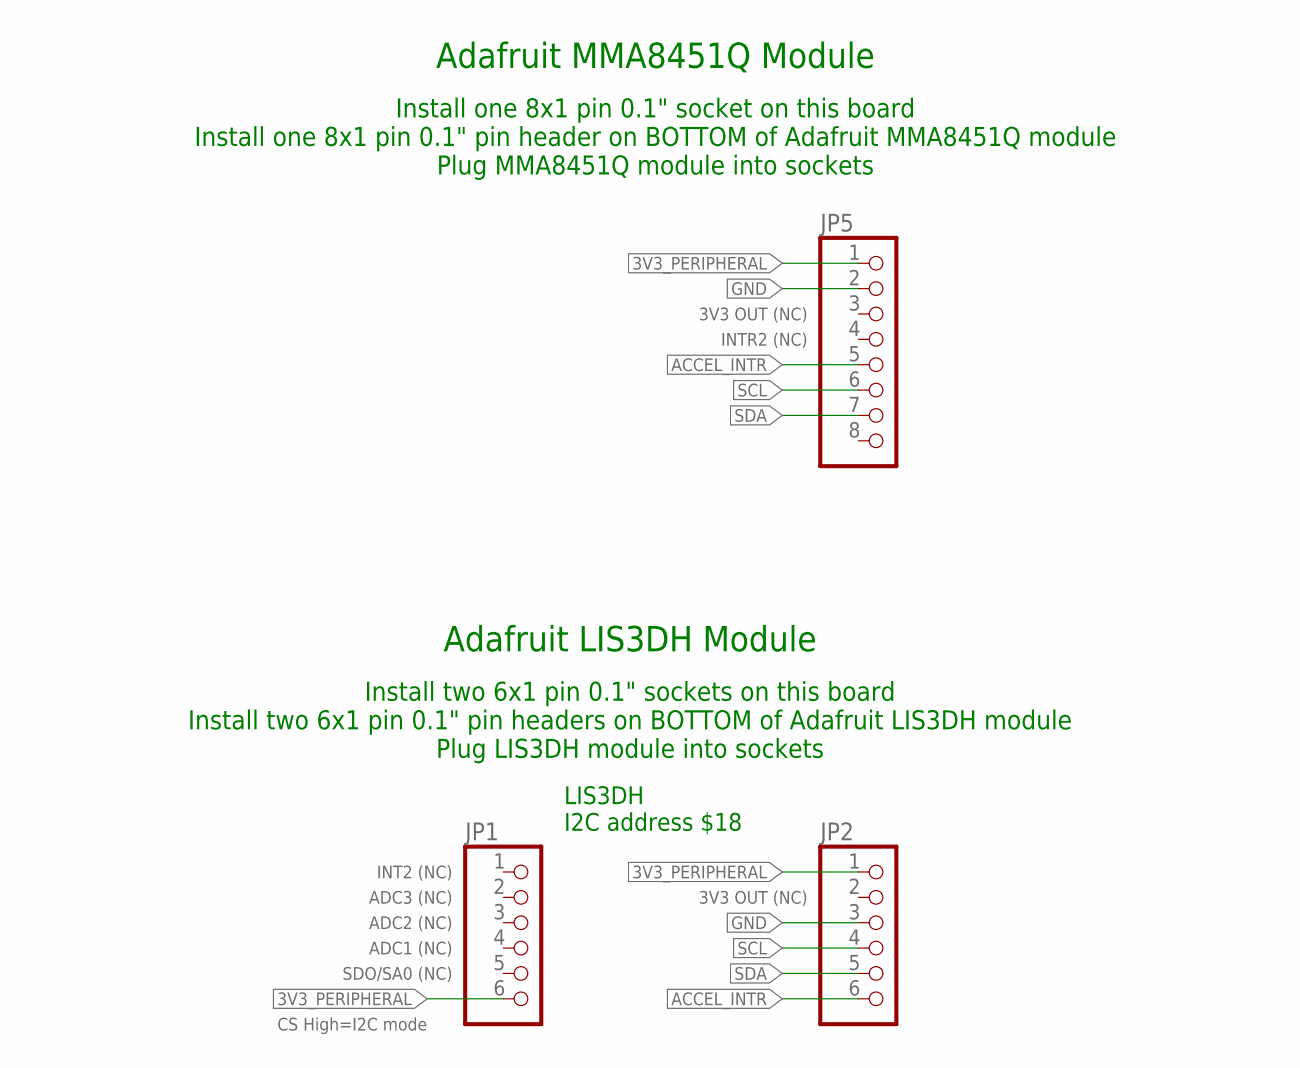
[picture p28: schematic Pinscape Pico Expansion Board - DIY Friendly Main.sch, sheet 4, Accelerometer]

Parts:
JP1, JP2: PINHD-1X6; 1X06
JP5: PINHD-1X8; 1X08

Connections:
3V3_PERIPHERAL: JP1.6, JP2.1, JP5.1; also elsewhere on the board
ACCEL_INTR: JP2.6, JP5.5; also elsewhere on the board
GND: JP2.3, JP5.2; also elsewhere on the board
SCL: JP2.4, JP5.6; also elsewhere on the board
SDA: JP2.5, JP5.7; also elsewhere on the board

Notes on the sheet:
Adafruit LIS3DH Module
Install two 6x1 pin 0.1" sockets on this board Install two 6x1 pin 0.1" pin headers on BOTTOM of Adafruit LIS3DH module Plug LIS3DH module into sockets
INT2 (NC)
ADC3 (NC)
ADC2 (NC)
ADC1 (NC)
SDO/SA0 (NC)
3V3 OUT (NC)
LIS3DH I2C address $18
CS High=I2C mode
Adafruit MMA8451Q Module
Install one 8x1 pin 0.1" socket on this board Install one 8x1 pin 0.1" pin header on BOTTOM of Adafruit MMA8451Q module Plug MMA8451Q module into sockets
INTR2 (NC)

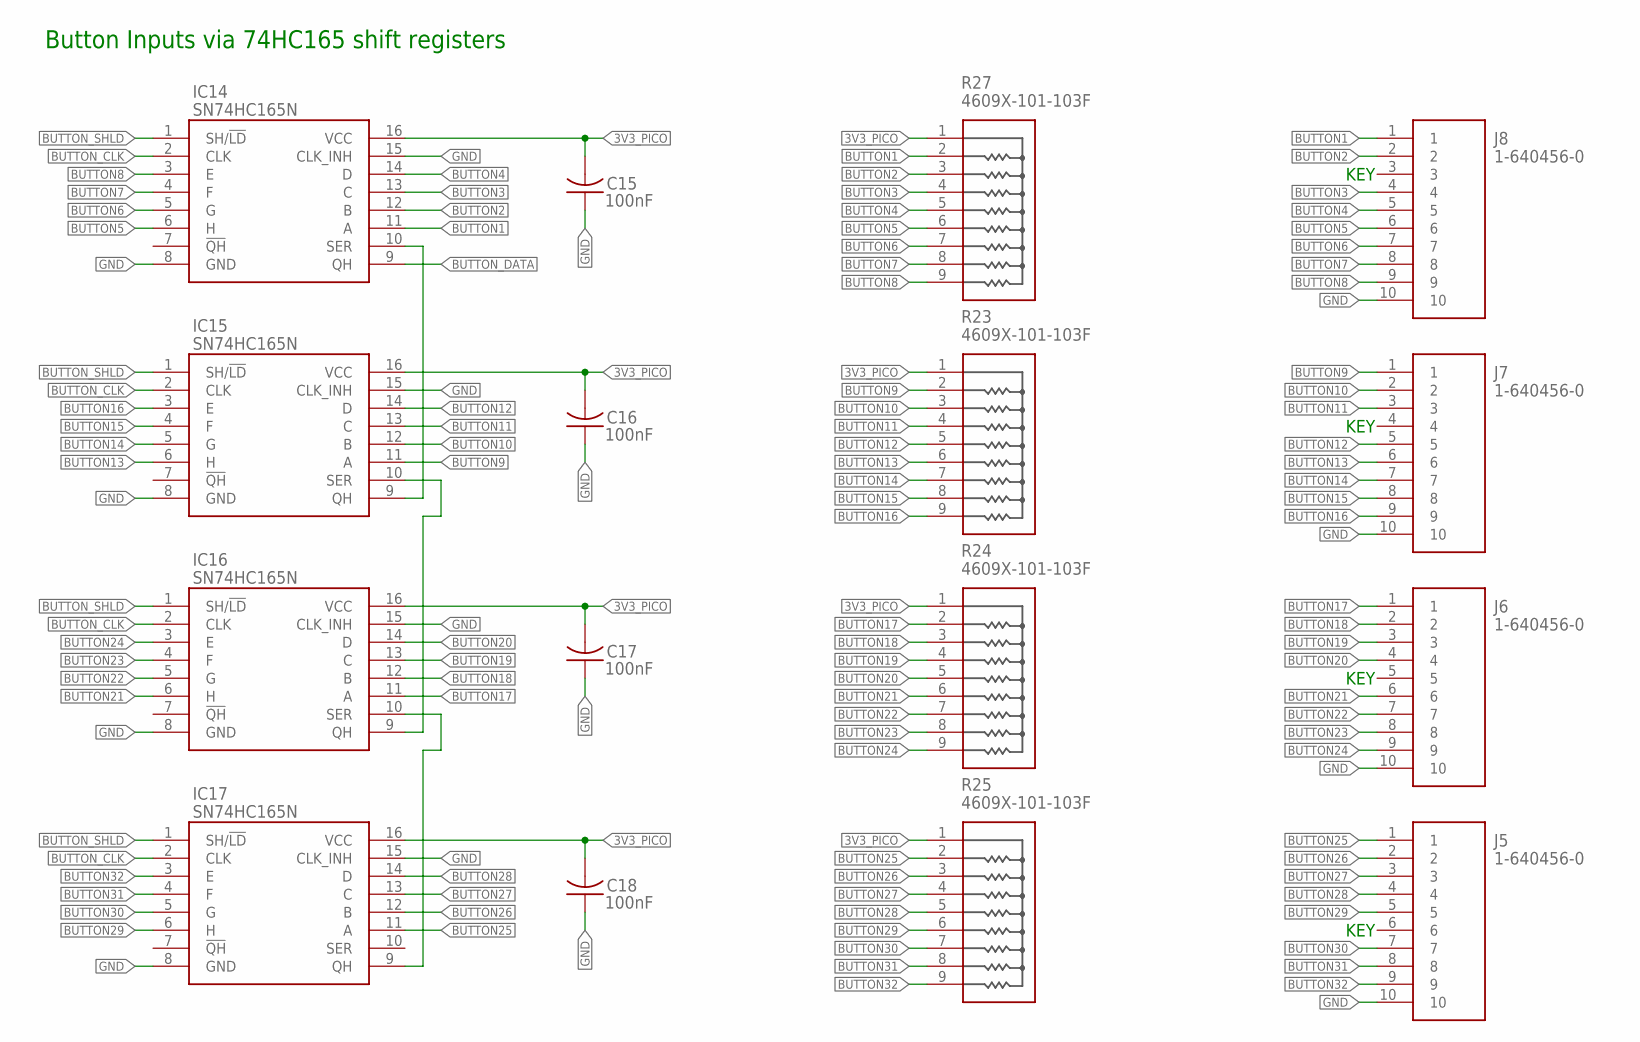
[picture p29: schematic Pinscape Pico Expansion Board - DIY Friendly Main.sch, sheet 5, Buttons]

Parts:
C15, C16, C17, C18: 100nF; C025-024X044; PARTNO K104K15X7RF5TL2
IC14, IC15, IC16, IC17: SN74HC165N; DIP794W53P254L1930H508Q16N
J5, J6, J7, J8: 1-640456-0; SHDR10W66P0X254_1X10_2540X572X
R23, R24, R25, R27: 4609X-101-103F; 4609X

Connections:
3V3_PICO: C15.2, C16.2, C17.2, C18.2, IC14.16 (VCC), IC15.16 (VCC), IC16.16 (VCC), IC17.16 (VCC), R23.1, R24.1, R25.1, R27.1; also elsewhere on the board
BUTTON1: IC14.11 (A), J8.1, R27.2
BUTTON2: IC14.12 (B), J8.2, R27.3
BUTTON3: IC14.13 (C), J8.4, R27.4
BUTTON4: IC14.14 (D), J8.5, R27.5
BUTTON5: IC14.6 (H), J8.6, R27.6
BUTTON6: IC14.5 (G), J8.7, R27.7
BUTTON7: IC14.4 (F), J8.8, R27.8
BUTTON8: IC14.3 (E), J8.9, R27.9
BUTTON9: IC15.11 (A), J7.1, R23.2
BUTTON10: IC15.12 (B), J7.2, R23.3
BUTTON11: IC15.13 (C), J7.3, R23.4
BUTTON12: IC15.14 (D), J7.5, R23.5
BUTTON13: IC15.6 (H), J7.6, R23.6
BUTTON14: IC15.5 (G), J7.7, R23.7
BUTTON15: IC15.4 (F), J7.8, R23.8
BUTTON16: IC15.3 (E), J7.9, R23.9
BUTTON17: IC16.11 (A), J6.1, R24.2
BUTTON18: IC16.12 (B), J6.2, R24.3
BUTTON19: IC16.13 (C), J6.3, R24.4
BUTTON20: IC16.14 (D), J6.4, R24.5
BUTTON21: IC16.6 (H), J6.6, R24.6
BUTTON22: IC16.5 (G), J6.7, R24.7
BUTTON23: IC16.4 (F), J6.8, R24.8
BUTTON24: IC16.3 (E), J6.9, R24.9
BUTTON25: IC17.11 (A), J5.1, R25.2
BUTTON26: IC17.12 (B), J5.2, R25.3
BUTTON27: IC17.13 (C), J5.3, R25.4
BUTTON28: IC17.14 (D), J5.4, R25.5
BUTTON29: IC17.6 (H), J5.5, R25.6
BUTTON30: IC17.5 (G), J5.7, R25.7
BUTTON31: IC17.4 (F), J5.8, R25.8
BUTTON32: IC17.3 (E), J5.9, R25.9
BUTTON_CLK: IC14.2 (CLK), IC15.2 (CLK), IC16.2 (CLK), IC17.2 (CLK); also elsewhere on the board
BUTTON_DATA: IC14.9 (QH); also elsewhere on the board
BUTTON_SHLD: IC14.1 (SH/!LD), IC15.1 (SH/!LD), IC16.1 (SH/!LD), IC17.1 (SH/!LD); also elsewhere on the board
GND: C15.1, C16.1, C17.1, C18.1, IC14.8 (GND), IC14.15 (CLK_INH), IC15.8 (GND), IC15.15 (CLK_INH), IC16.8 (GND), IC16.15 (CLK_INH), IC17.8 (GND), IC17.15 (CLK_INH), J5.10, J6.10, J7.10, J8.10; also elsewhere on the board
unnamed: IC14.10 (SER), IC15.9 (QH)
unnamed: IC15.10 (SER), IC16.9 (QH)
unnamed: IC16.10 (SER), IC17.9 (QH)

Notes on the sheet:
KEY
Button Inputs via 74HC165 shift registers

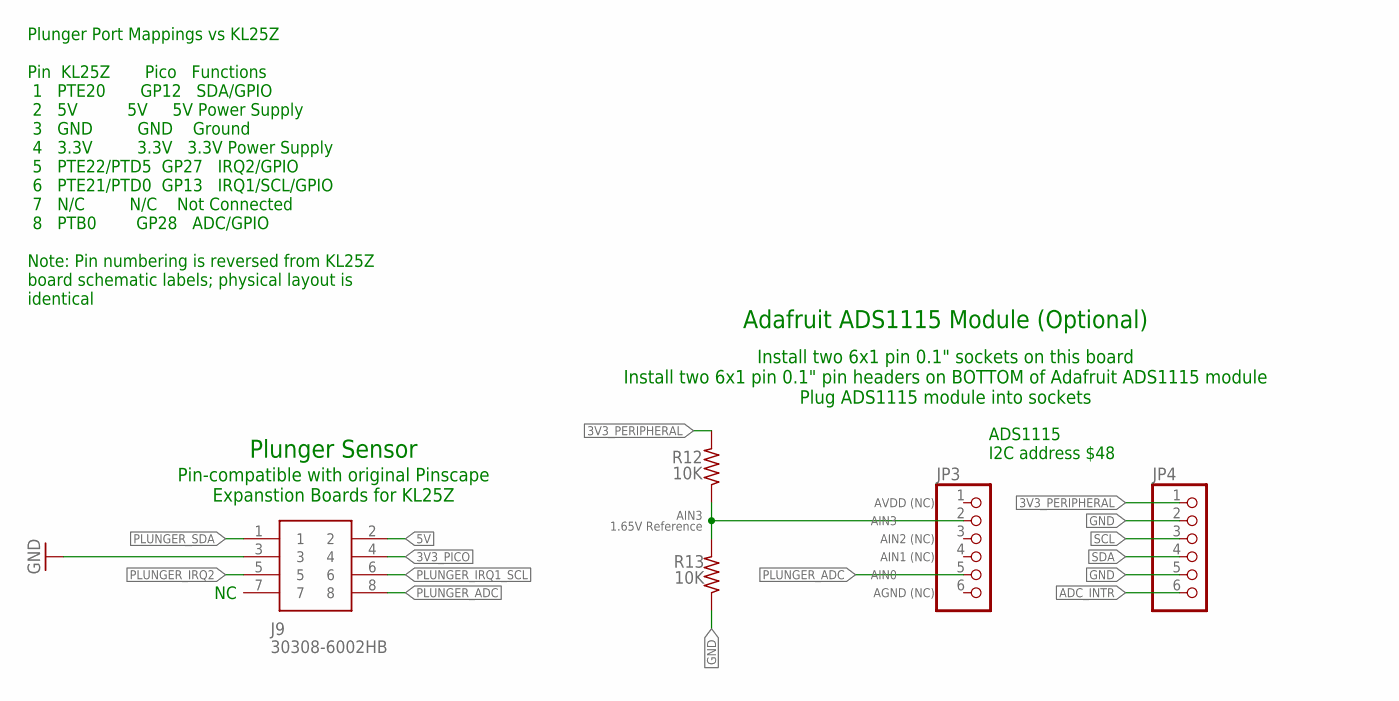
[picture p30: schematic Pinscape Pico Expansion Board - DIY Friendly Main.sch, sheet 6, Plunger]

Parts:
J9: 30308-6002HB; SHDR8W69P254_2X4_1780X878X955P
JP3, JP4: PINHD-1X6; 1X06
R12, R13: 10K; 0204/7; PARTNO mfr-12frrf52-10k

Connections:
3V3_PERIPHERAL: JP4.1, R12.2; also elsewhere on the board
3V3_PICO: J9.4; also elsewhere on the board
5V: J9.2; also elsewhere on the board
ADC_INTR: JP4.6; also elsewhere on the board
GND: J9.3, JP4.2, JP4.5, R13.1; also elsewhere on the board
unnamed: JP3.2, R12.1, R13.2
PLUNGER_ADC: J9.8, JP3.5; also elsewhere on the board
PLUNGER_IRQ1_SCL: J9.6; also elsewhere on the board
PLUNGER_IRQ2: J9.5; also elsewhere on the board
PLUNGER_SDA: J9.1; also elsewhere on the board
SCL: JP4.3; also elsewhere on the board
SDA: JP4.4; also elsewhere on the board

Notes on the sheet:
Plunger Sensor
Adafruit ADS1115 Module (Optional)
Install two 6x1 pin 0.1" sockets on this board Install two 6x1 pin 0.1" pin headers on BOTTOM of Adafruit ADS1115 module Plug ADS1115 module into sockets
AVDD (NC)
AGND (NC)
AIN3 1.65V Reference
AIN2 (NC)
AIN1 (NC)
Pin-compatible with original Pinscape Expanstion Boards for KL25Z
ADS1115 I2C address $48
Plunger Port Mappings vs KL25Z Pin KL25Z Pico Functions 1 PTE20 GP12 SDA/GPIO 2 5V 5V 5V Power Supply 3 GND GND Ground 4 3.3V 3.3V 3.3V Power Supply 5 PTE22/PTD5 GP27 IRQ2/GPIO 6 PTE21/PTD0 GP13 IRQ1/SCL/GPIO 7 N/C N/C Not Connected 8 PTB0 GP28 ADC/GPIO Note: Pin numbering is reversed from KL25Z bo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
AIN0
AIN3

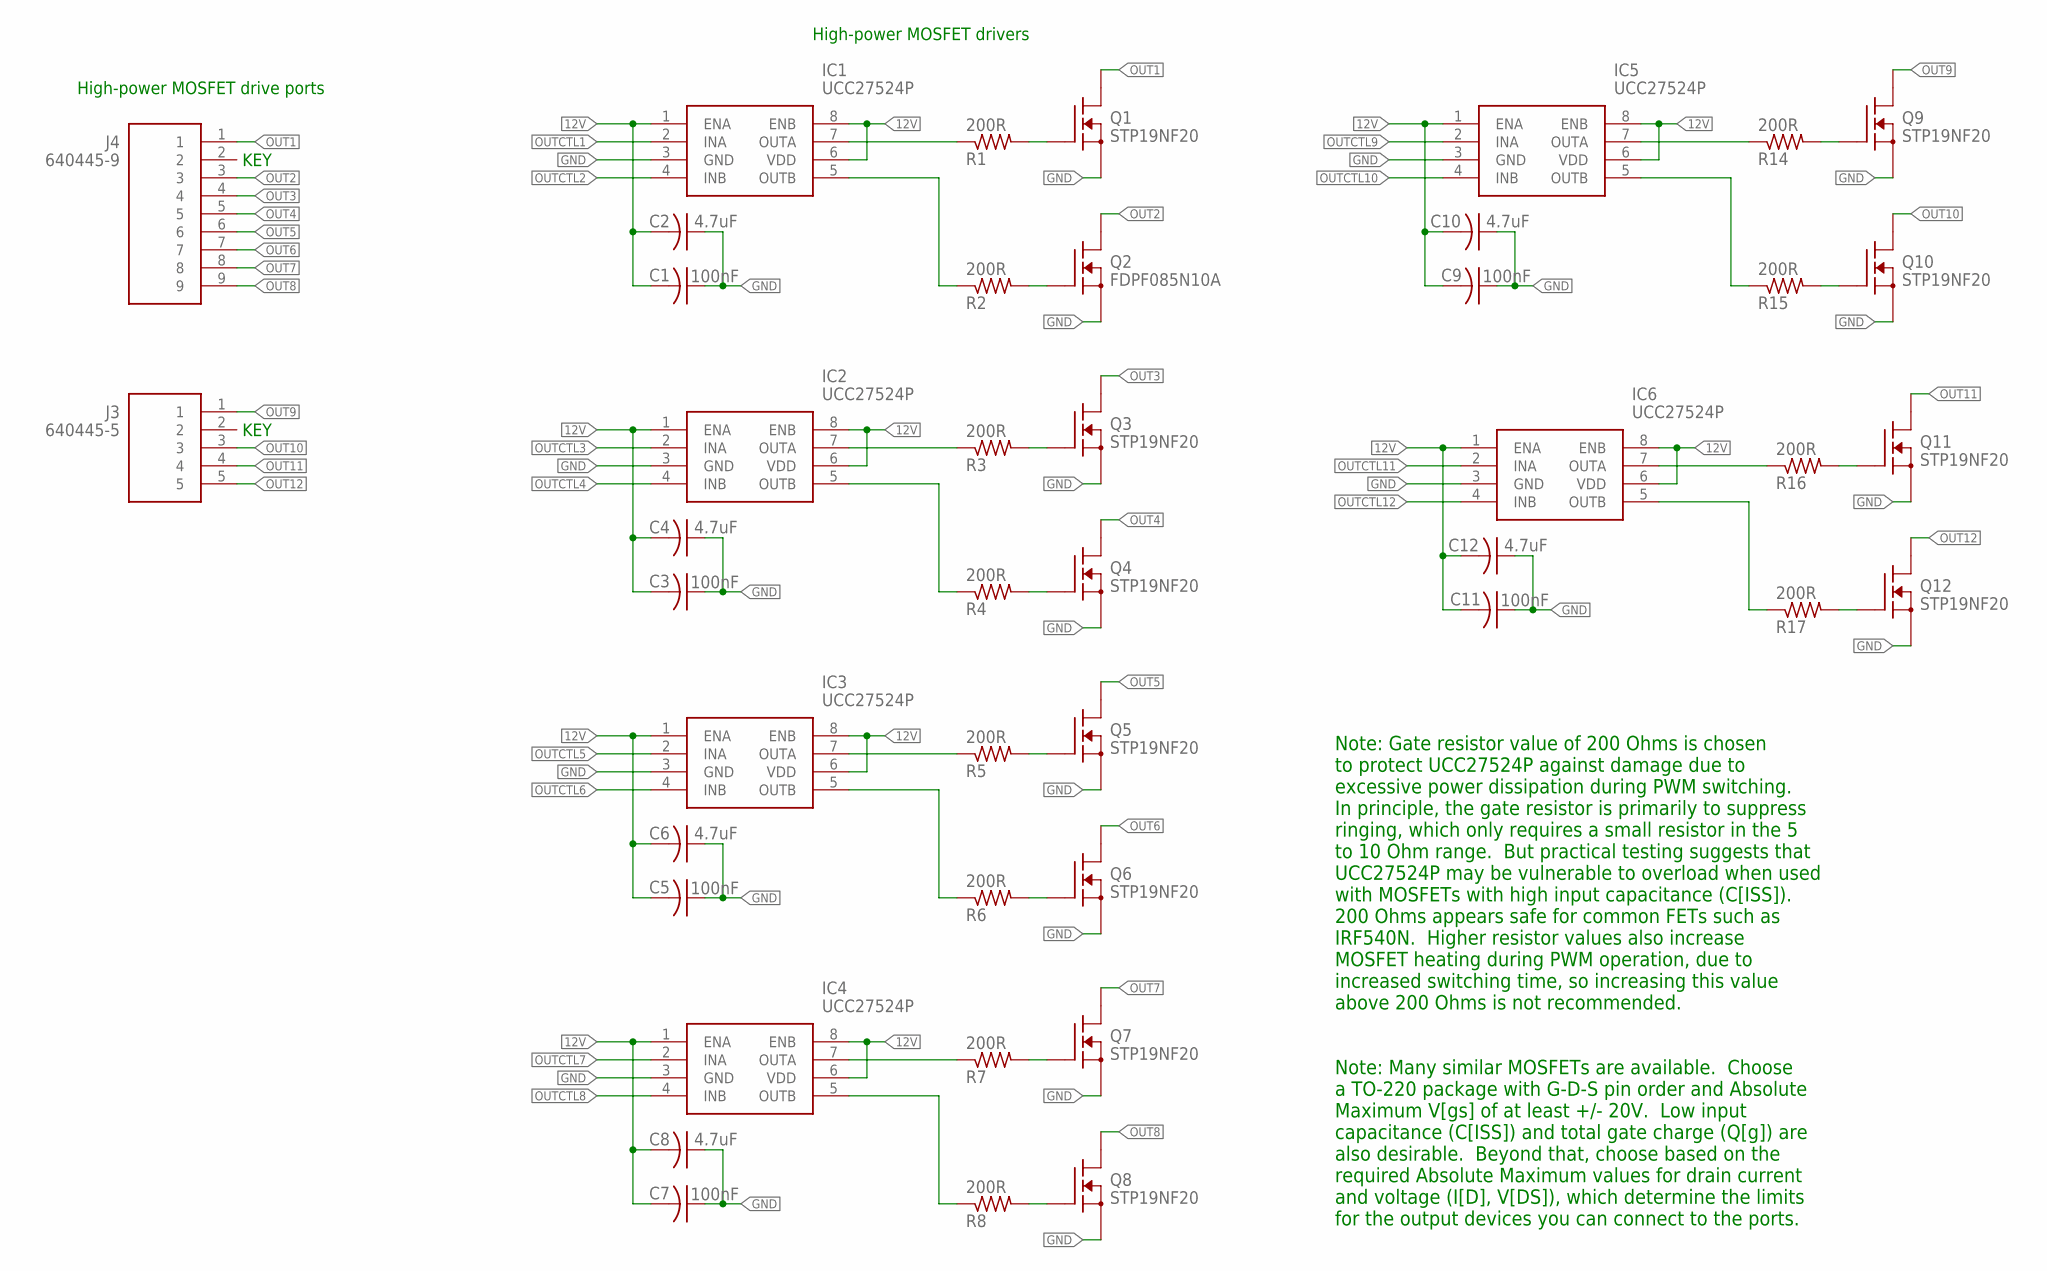
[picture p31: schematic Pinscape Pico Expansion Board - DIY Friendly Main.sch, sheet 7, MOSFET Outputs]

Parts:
C1, C3, C5, C7, C9, C11: 100nF; C025-024X044; PARTNO K104K15X7RF5TL2
C2, C4, C6, C8, C10, C12: 4.7uF; C025-024X044; PARTNO 810-FG14X5R1H475KRT0
IC1, IC2, IC3, IC4, IC5, IC6: UCC27524P; DIP794W53P254L959H508Q8N
J3: 640445-5; HDRV5W117P0X396_1X5_1981X762X1
J4: 640445-9; SHDR9W117P0X396_1X9_3566X762X1
Q1, Q3, Q4, Q5, Q6, Q7, Q8, Q9, Q10, Q11, Q12: STP19NF20; TO220BV; PARTNO FDPF085N10A
Q2: FDPF085N10A; TO220BV; PARTNO FDPF085N10A
R1, R2, R3, R4, R5, R6, R7, R8, R14, R15, R16, R17: 200R; 0204/5; PARTNO 660-MFS1/4DCT52R47R0

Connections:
12V: C1.2, C2.2, C3.2, C4.2, C5.2, C6.2, C7.2, C8.2, C9.2, C10.2, C11.2, C12.2, IC1.1 (ENA), IC1.6 (VDD), IC1.8 (ENB), IC2.1 (ENA), IC2.6 (VDD), IC2.8 (ENB), IC3.1 (ENA), IC3.6 (VDD), IC3.8 (ENB), IC4.1 (ENA), IC4.6 (VDD), IC4.8 (ENB), IC5.1 (ENA), IC5.6 (VDD), IC5.8 (ENB), IC6.1 (ENA), IC6.6 (VDD), IC6.8 (ENB); also elsewhere on the board
GND: C1.1, C2.1, C3.1, C4.1, C5.1, C6.1, C7.1, C8.1, C9.1, C10.1, C11.1, C12.1, IC1.3 (GND), IC2.3 (GND), IC3.3 (GND), IC4.3 (GND), IC5.3 (GND), IC6.3 (GND), Q1.3 (S), Q2.3 (S), Q3.3 (S), Q4.3 (S), Q5.3 (S), Q6.3 (S), Q7.3 (S), Q8.3 (S), Q9.3 (S), Q10.3 (S), Q11.3 (S), Q12.3 (S); also elsewhere on the board
unnamed: IC1.7 (OUTA), R1.1
unnamed: IC1.5 (OUTB), R2.1
unnamed: Q1.1 (G), R1.2
unnamed: Q2.1 (G), R2.2
unnamed: IC2.7 (OUTA), R3.1
unnamed: IC2.5 (OUTB), R4.1
unnamed: Q3.1 (G), R3.2
unnamed: Q4.1 (G), R4.2
unnamed: IC3.7 (OUTA), R5.1
unnamed: IC3.5 (OUTB), R6.1
unnamed: Q5.1 (G), R5.2
unnamed: Q6.1 (G), R6.2
unnamed: IC4.7 (OUTA), R7.1
unnamed: IC4.5 (OUTB), R8.1
unnamed: Q7.1 (G), R7.2
unnamed: Q8.1 (G), R8.2
unnamed: IC5.7 (OUTA), R14.1
unnamed: IC5.5 (OUTB), R15.1
unnamed: Q9.1 (G), R14.2
unnamed: Q10.1 (G), R15.2
unnamed: IC6.7 (OUTA), R16.1
unnamed: IC6.5 (OUTB), R17.1
unnamed: Q11.1 (G), R16.2
unnamed: Q12.1 (G), R17.2
OUT1: J4.1, Q1.2 (D)
OUT2: J4.3, Q2.2 (D)
OUT3: J4.4, Q3.2 (D)
OUT4: J4.5, Q4.2 (D)
OUT5: J4.6, Q5.2 (D)
OUT6: J4.7, Q6.2 (D)
OUT7: J4.8, Q7.2 (D)
OUT8: J4.9, Q8.2 (D)
OUT9: J3.1, Q9.2 (D)
OUT10: J3.3, Q10.2 (D)
OUT11: J3.4, Q11.2 (D)
OUT12: J3.5, Q12.2 (D)
OUTCTL1: IC1.2 (INA); also elsewhere on the board
OUTCTL2: IC1.4 (INB); also elsewhere on the board
OUTCTL3: IC2.2 (INA); also elsewhere on the board
OUTCTL4: IC2.4 (INB); also elsewhere on the board
OUTCTL5: IC3.2 (INA); also elsewhere on the board
OUTCTL6: IC3.4 (INB); also elsewhere on the board
OUTCTL7: IC4.2 (INA); also elsewhere on the board
OUTCTL8: IC4.4 (INB); also elsewhere on the board
OUTCTL9: IC5.2 (INA); also elsewhere on the board
OUTCTL10: IC5.4 (INB); also elsewhere on the board
OUTCTL11: IC6.2 (INA); also elsewhere on the board
OUTCTL12: IC6.4 (INB); also elsewhere on the board

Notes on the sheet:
High-power MOSFET drive ports
KEY
High-power MOSFET drivers
Note: Gate resistor value of 200 Ohms is chosen to protect UCC27524P against damage due to excessive power dissipation during PWM switching. In principle, the gate resistor is primarily to suppress ringing, which only requires a small resistor in the 5 to 10 Ohm range. But practical testing suggest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
Note: Many similar MOSFETs are available. Choose a TO-220 package with G-D-S pin order and Absolute Maximum V[gs] of at least +/- 20V. Low input capacitance (C[ISS]) and total gate charge (Q[g]) are also desirable. Beyond that, choose based on the required Absolute Maximum values for drain current 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

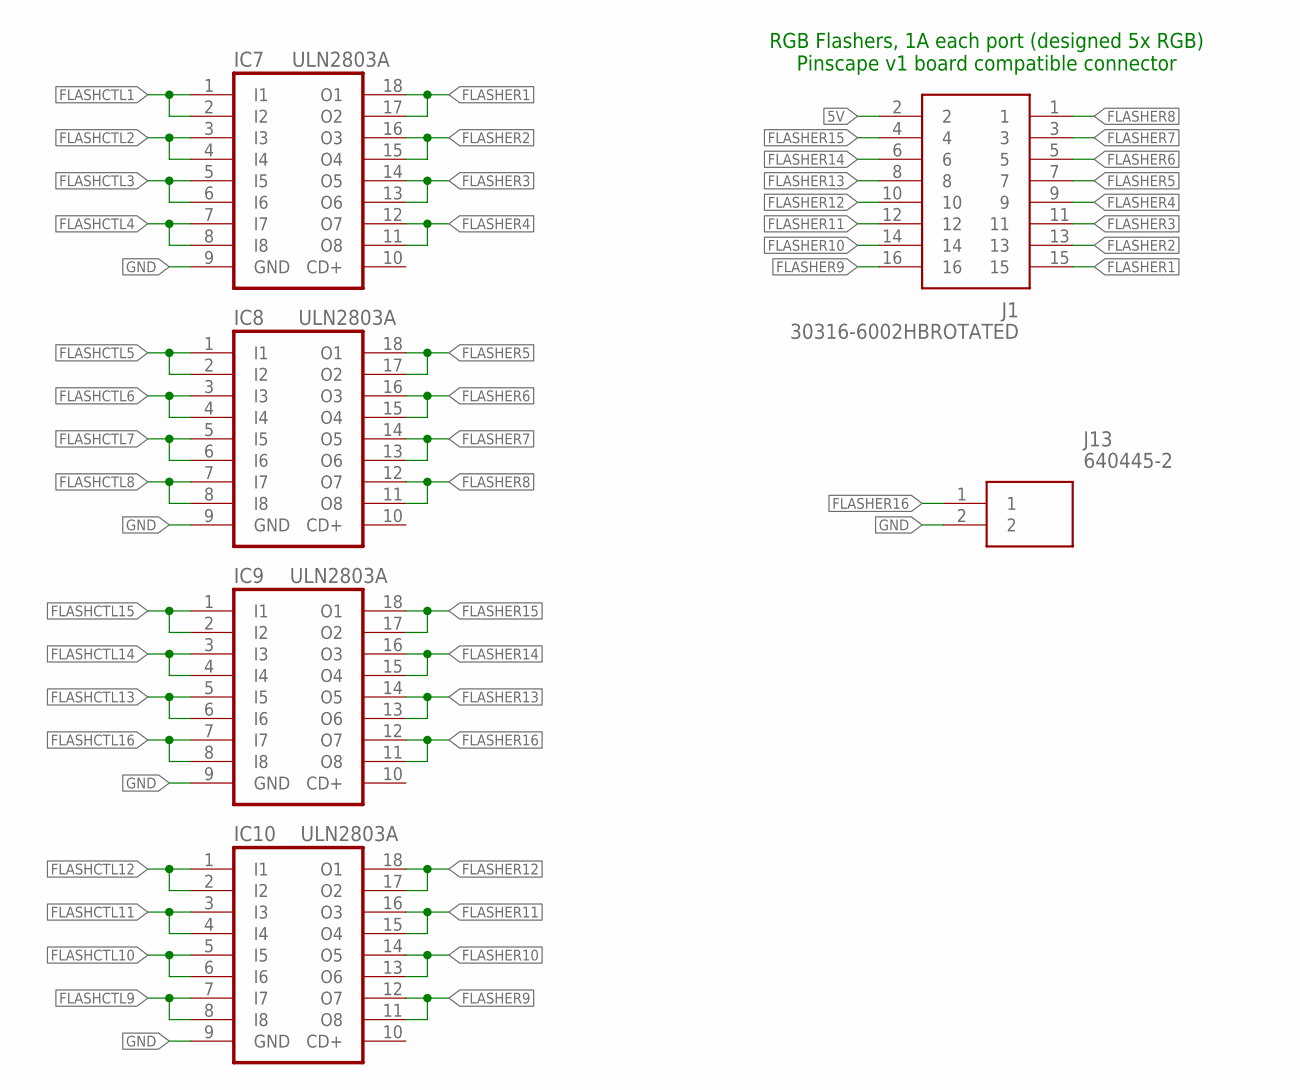
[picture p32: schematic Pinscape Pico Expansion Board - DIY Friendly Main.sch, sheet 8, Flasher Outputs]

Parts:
IC7, IC8, IC9, IC10: ULN2803A; DIL18
J1: 30316-6002HBROTATED; 3M-30316-6002HB-ROTATED
J13: 640445-2; SHDR2W117P0X396_1X2_792X762X11

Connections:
5V: J1.2; also elsewhere on the board
FLASHCTL1: IC7.1 (I1), IC7.2 (I2); also elsewhere on the board
FLASHCTL2: IC7.3 (I3), IC7.4 (I4); also elsewhere on the board
FLASHCTL3: IC7.5 (I5), IC7.6 (I6); also elsewhere on the board
FLASHCTL4: IC7.7 (I7), IC7.8 (I8); also elsewhere on the board
FLASHCTL5: IC8.1 (I1), IC8.2 (I2); also elsewhere on the board
FLASHCTL6: IC8.3 (I3), IC8.4 (I4); also elsewhere on the board
FLASHCTL7: IC8.5 (I5), IC8.6 (I6); also elsewhere on the board
FLASHCTL8: IC8.7 (I7), IC8.8 (I8); also elsewhere on the board
FLASHCTL9: IC10.7 (I7), IC10.8 (I8); also elsewhere on the board
FLASHCTL10: IC10.5 (I5), IC10.6 (I6); also elsewhere on the board
FLASHCTL11: IC10.3 (I3), IC10.4 (I4); also elsewhere on the board
FLASHCTL12: IC10.1 (I1), IC10.2 (I2); also elsewhere on the board
FLASHCTL13: IC9.5 (I5), IC9.6 (I6); also elsewhere on the board
FLASHCTL14: IC9.3 (I3), IC9.4 (I4); also elsewhere on the board
FLASHCTL15: IC9.1 (I1), IC9.2 (I2); also elsewhere on the board
FLASHCTL16: IC9.7 (I7), IC9.8 (I8); also elsewhere on the board
FLASHER1: IC7.17 (O2), IC7.18 (O1), J1.15
FLASHER2: IC7.15 (O4), IC7.16 (O3), J1.13
FLASHER3: IC7.13 (O6), IC7.14 (O5), J1.11
FLASHER4: IC7.11 (O8), IC7.12 (O7), J1.9
FLASHER5: IC8.17 (O2), IC8.18 (O1), J1.7
FLASHER6: IC8.15 (O4), IC8.16 (O3), J1.5
FLASHER7: IC8.13 (O6), IC8.14 (O5), J1.3
FLASHER8: IC8.11 (O8), IC8.12 (O7), J1.1
FLASHER9: IC10.11 (O8), IC10.12 (O7), J1.16
FLASHER10: IC10.13 (O6), IC10.14 (O5), J1.14
FLASHER11: IC10.15 (O4), IC10.16 (O3), J1.12
FLASHER12: IC10.17 (O2), IC10.18 (O1), J1.10
FLASHER13: IC9.13 (O6), IC9.14 (O5), J1.8
FLASHER14: IC9.15 (O4), IC9.16 (O3), J1.6
FLASHER15: IC9.17 (O2), IC9.18 (O1), J1.4
FLASHER16: IC9.11 (O8), IC9.12 (O7), J13.1
GND: IC7.9 (GND), IC8.9 (GND), IC9.9 (GND), IC10.9 (GND), J13.2; also elsewhere on the board

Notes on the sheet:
RGB Flashers, 1A each port (designed 5x RGB) Pinscape v1 board compatible connector

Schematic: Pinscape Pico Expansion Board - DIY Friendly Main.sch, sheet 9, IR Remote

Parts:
C14: 4.7uF; C025-024X044; PARTNO 810-FG14X5R1H475KRT0
D3, D4: 1N4148; DO35-7
J10: 215079-4; 2150794
J11: 640454-2; HDRV2W66P0X254_1X2_762X572X100
Q13: BC337-25; BC33725
R19: 540R; 0204/7; PARTNO 660-MFS1/4DCT52R47R0
R31: 2R5; 0204/7; PARTNO 660-MFS1/4DCT52R47R0

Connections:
3V3_PICO: J10.1; also elsewhere on the board
5V: C14.1, J11.1; also elsewhere on the board
$N377: D3.A, Q13.2 (B), R19.2
GND: C14.2, D4.C, J10.2, J10.4, R31.1; also elsewhere on the board
IR_IN: J10.3; also elsewhere on the board
IR_LED_CATHODE: J11.2, Q13.1 (C)
IR_OUT: R19.1; also elsewhere on the board
unnamed: D3.C, D4.A
unnamed: Q13.3 (E), R31.2

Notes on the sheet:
IR REMOTE CONTROL TRANSMITTER Use with VSLB4940, TSAL6400, or a similar IR LED with a peak wavelength around 940nm. Set the current-sense resistor according to the desired forward current on the IR LED. Set to 200 mA for VSLB4940 or TSAL6400; for others, use a current between the "continuous" and "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
IR REMOTE RECEIVER CONNECTOR This header allows connecting an IR receiver (TSOP38438) on a separate circuit board, connected to the main board with a 4-conductor ribbon cable. The board should include the VCC supply filter circuit (220R + 150nF) shown in the data sheet.
===> IRED Cathode (-)
===> IRED Anode (+)
Note: TE Connectivity Micro-Match 215079-4 base pairs with 215083-4 on-cable IDC connector.
CURRENT-SENSE RESISTOR Resistor sets current to I(LED) = 0.5V/R R=2.5 ohms -> 200mA current
NPN substitutes: choose any medium-power NPN with Hfe around 100
IR EMITTER / IR RECEIVER The emitter and receiver are designed to be installed remotely to allow placing them in suitable line-of-sight locations.

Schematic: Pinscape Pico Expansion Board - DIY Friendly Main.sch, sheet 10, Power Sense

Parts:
C13: 100nF; C025-024X044; PARTNO K104K15X7RF5TL2
IC11: SN74HC74NE4; DIP794W53P254L1930H508Q14N
IC12: S-80833CLY; TO-92_(TO-226)
IC13: PC827; DIL08
R18: 240R; 0204/7; PARTNO 660-MFS1/4DCT52R47R0
R20, R22: 10K; 0204/7; PARTNO mfr-12frrf52-10k
R21: 360R; 0204/7; PARTNO 660-MFS1/4DCT52R47R0

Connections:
3V3_PICO: IC13.6 (COL); also elsewhere on the board
5V: C13.1, IC11.2 (1D), IC11.4 (1!PRE), IC11.14 (VCC), IC12.2 (VDD), IC13.8 (COL); also elsewhere on the board
GND: C13.2, IC11.7 (GND), IC12.3 (GND), R18.1, R20.2, R21.1, R22.1; also elsewhere on the board
unnamed: IC11.3 (1CLK), IC13.7 (EMIT), R20.1
unnamed: IC13.2 (C), R18.2
unnamed: IC11.1 (!1CLR), IC12.1 (OUT)
unnamed: IC13.4 (C), R21.2
unnamed: IC11.5 (1Q), IC13.3 (A)
PSU2_STATUS_SENSE: IC13.5 (EMIT), R22.2; also elsewhere on the board
PSU2_STATUS_SET: IC13.1 (A); also elsewhere on the board

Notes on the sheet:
PSU2 Power Sensing This circuit monitors the status of a secondary power supply (PSU2) that's hard-switched on and off with the overall pinball cabinet power. The status circuit maintains its own memory of the power state, independently of the Pico's power state, which satisfies two important condi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
POR part selection: The POR is triggered by the voltage on the 5V supply crossing a threshold voltage, so we must choose a POR whose threshold voltage slightly below the MINIMUM voltage that the 5V supply maintains when powered on and operating stably. Nominally, this would be 4.75V for an ATX supp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
Note: RESET signal must be ACTIVE LOW

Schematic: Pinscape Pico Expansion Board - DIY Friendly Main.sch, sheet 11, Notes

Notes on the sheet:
I2C Address Map (7-bit notation) $18 LIS3DH (Accelerometer) $30 Pico PWM Helper (main board) $31 Pico PWM Helper #1 (power board) $32 Pico PWM Helper #2 (power board) $48 ADS1115 (ADC) $68 DS1307 (RTC clock/calendar chip) [On Power board]
Copyright and License Info Pinscape Pico DIY Friendly Expansion Board Copyright 2024, 2025 Michael J Roberts BSD 3-clause license

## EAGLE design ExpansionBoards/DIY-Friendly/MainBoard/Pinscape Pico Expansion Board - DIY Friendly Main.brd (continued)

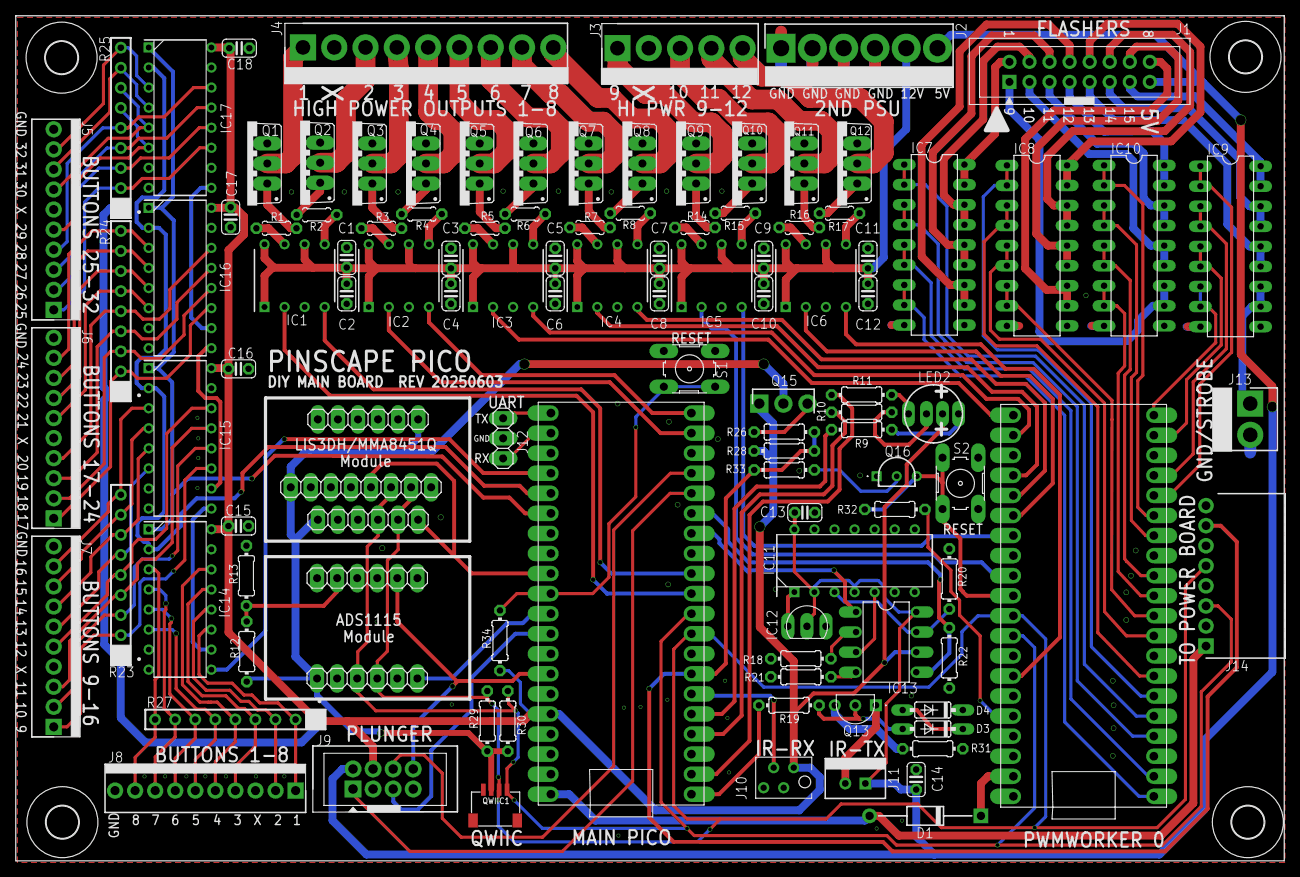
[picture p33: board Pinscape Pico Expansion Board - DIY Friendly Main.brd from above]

Board: 2 copper layers, 160.6 x 107.0 mm, 116 parts (0 on the bottom side), 161 nets.

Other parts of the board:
U$1, U$2, U$3, U$4: 4,1

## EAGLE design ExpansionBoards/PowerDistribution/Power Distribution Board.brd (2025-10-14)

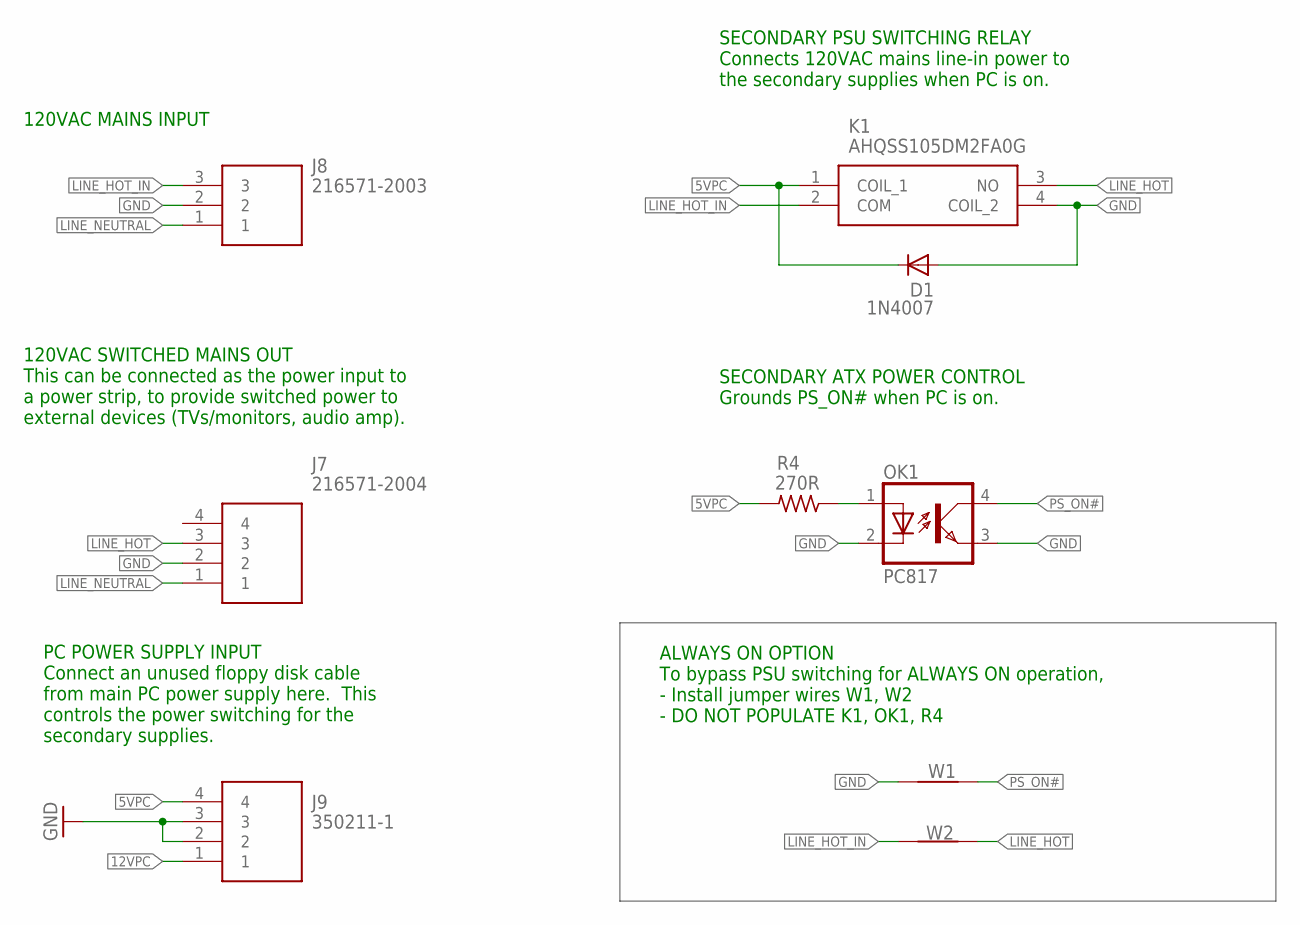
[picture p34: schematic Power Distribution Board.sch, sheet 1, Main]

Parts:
D1: 1N4007; DO41-10
J7: 216571-2004; 216571-YY04_1
J8: 216571-2003; 216571-YY03_1
J9: 350211-1; 3502111
K1: AHQSS105DM2FA0G
OK1: PC817; DIL04
R4: 270R; 0204/7
W1, W2: JUMPER-WIRE

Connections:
5VPC: D1.C, J9.4, K1.1 (COIL_1), R4.2
12VPC: J9.1
GND: D1.A, J7.2, J8.2, J9.2, J9.3, K1.4 (COIL_2), OK1.2 (C), OK1.3 (EMIT), W1.P$1; also elsewhere on the board
LINE_HOT: J7.3, K1.3 (NO), W2.P$2; also elsewhere on the board
LINE_HOT_IN: J8.3, K1.2 (COM), W2.P$1
LINE_NEUTRAL: J7.1, J8.1; also elsewhere on the board
unnamed: OK1.1 (A), R4.1
PS_ON#: OK1.4 (COL), W1.P$2; also elsewhere on the board

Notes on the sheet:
PC POWER SUPPLY INPUT Connect an unused floppy disk cable from main PC power supply here. This controls the power switching for the secondary supplies.
SECONDARY PSU SWITCHING RELAY Connects 120VAC mains line-in power to the secondary supplies when PC is on.
120VAC MAINS INPUT
SECONDARY ATX POWER CONTROL Grounds PS_ON# when PC is on.
120VAC SWITCHED MAINS OUT This can be connected as the power input to a power strip, to provide switched power to external devices (TVs/monitors, audio amp).
ALWAYS ON OPTION To bypass PSU switching for ALWAYS ON operation, - Install jumper wires W1, W2 - DO NOT POPULATE K1, OK1, R4

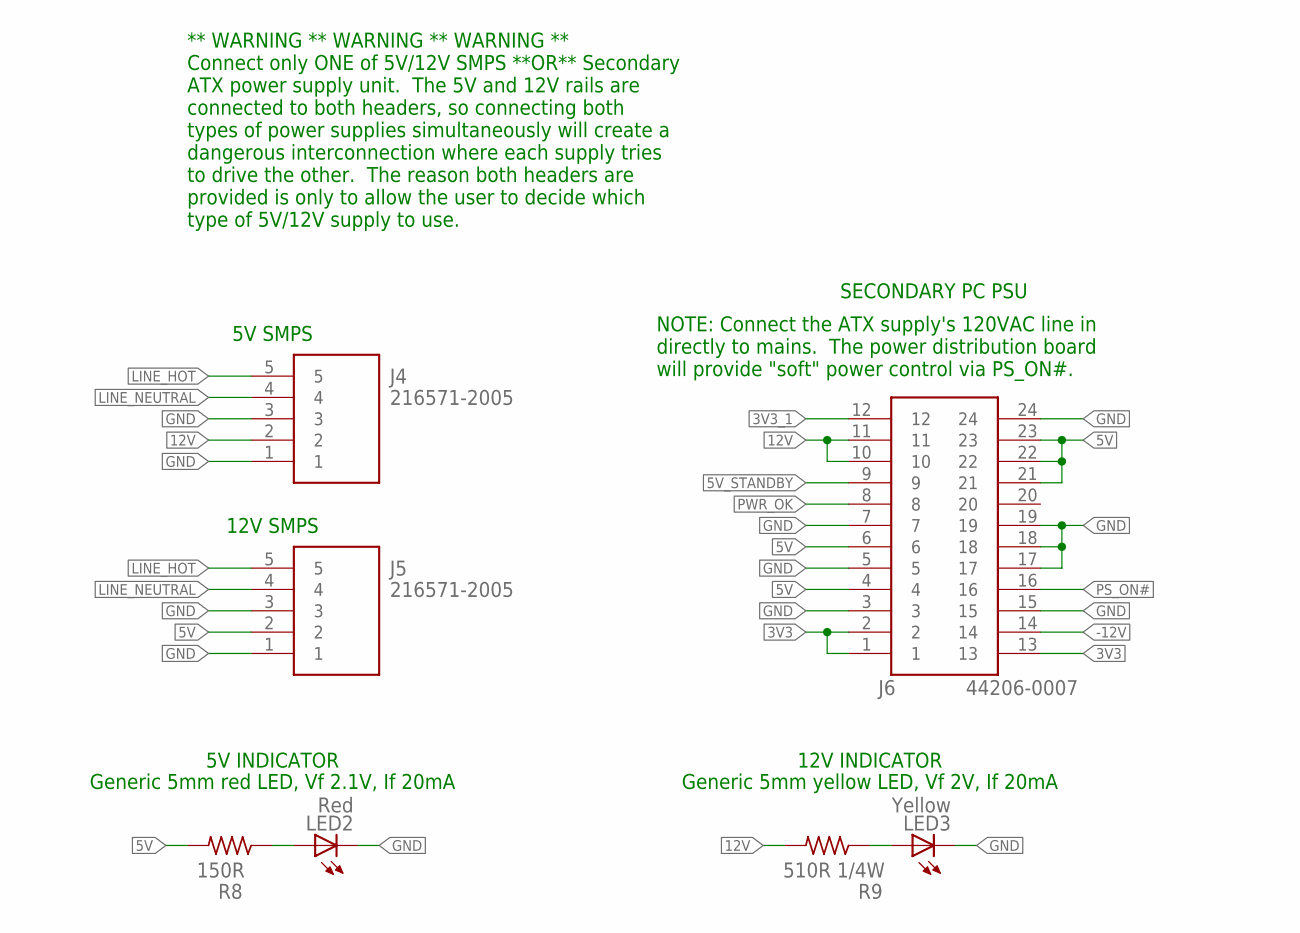
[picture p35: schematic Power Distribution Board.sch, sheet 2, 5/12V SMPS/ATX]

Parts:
J4, J5: 216571-2005; 216571-YY05_1
J6: 44206-0007; 44206-0007_1
LED2: Red; LED5MM
LED3: Yellow; LED5MM
R8: 150R; 0309/12
R9: 510R 1/4W; 0309/12

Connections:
3V3: J6.1, J6.2, J6.13
3V3_1: J6.12
5V: J5.2, J6.4, J6.6, J6.21, J6.22, J6.23, R8.2; also elsewhere on the board
5V_STANDBY: J6.9
12V: J4.2, J6.10, J6.11, R9.2; also elsewhere on the board
-12V: J6.14
GND: J4.1, J4.3, J5.1, J5.3, J6.3, J6.5, J6.7, J6.15, J6.17, J6.18, J6.19, J6.24, LED2.K (C), LED3.K (C); also elsewhere on the board
LINE_HOT: J4.5, J5.5; also elsewhere on the board
LINE_NEUTRAL: J4.4, J5.4; also elsewhere on the board
unnamed: LED2.A, R8.1
unnamed: LED3.A, R9.1
PS_ON#: J6.16; also elsewhere on the board
PWR_OK: J6.8

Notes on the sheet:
SECONDARY PC PSU
** WARNING ** WARNING ** WARNING ** Connect only ONE of 5V/12V SMPS **OR** Secondary ATX power supply unit. The 5V and 12V rails are connected to both headers, so connecting both types of power supplies simultaneously will create a dangerous interconnection where each supply tries to drive the othe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
NOTE: Connect the ATX supply's 120VAC line in directly to mains. The power distribution board will provide "soft" power control via PS_ON#.
5V INDICATOR
12V INDICATOR
Generic 5mm red LED, Vf 2.1V, If 20mA
Generic 5mm yellow LED, Vf 2V, If 20mA
5V SMPS
12V SMPS

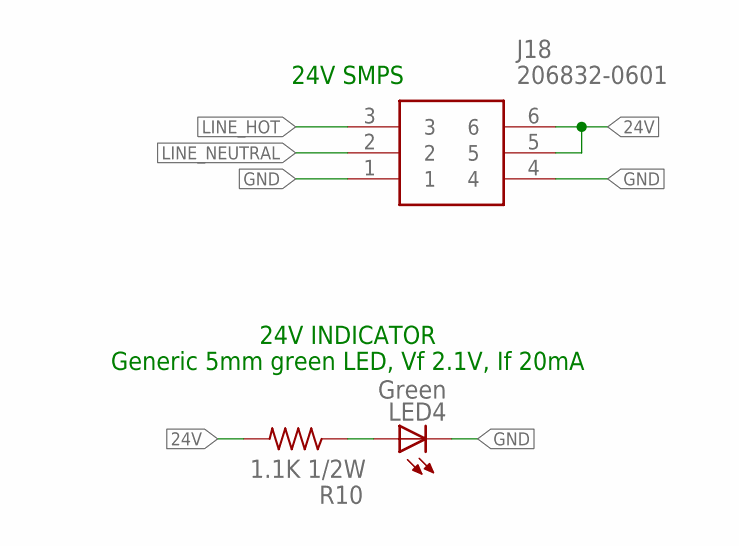
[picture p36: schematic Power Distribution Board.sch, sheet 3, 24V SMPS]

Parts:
J18: 206832-0601; 2068320601
LED4: Green; LED5MM
R10: 1.1K 1/2W; 0309/12

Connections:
24V: J18.5, J18.6, R10.2; also elsewhere on the board
GND: J18.1, J18.4, LED4.K (C); also elsewhere on the board
LINE_HOT: J18.3; also elsewhere on the board
LINE_NEUTRAL: J18.2; also elsewhere on the board
unnamed: LED4.A, R10.1

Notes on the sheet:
24V SMPS
24V INDICATOR
Generic 5mm green LED, Vf 2.1V, If 20mA


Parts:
C3, C4, C5: SLPX682M080H7P3; CAPPRD1000W100D3550H4200
J2: 216571-2002; 216571-YY02_1
J19: 206832-0601; 2068320601
LED1: Blue; LED5MM
Q1: 2N2222A
Q2: IRF9530; TO220BV
R1: 2.4K 1W; 0309/12
R5: 470R; 0204/7
R6: 8.2K; 0207/10
R7: 2.2K; 0207/10
RT1: SL22_7R010; SL227R010

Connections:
5V: J2.1; also elsewhere on the board
48V: C3.1 (+), C4.1 (+), C5.1 (+), R1.2, RT1.2; also elsewhere on the board
GND: C3.2 (-), C4.2 (-), C5.2 (-), J19.1, J19.4, LED1.K (C), Q1.1 (E); also elsewhere on the board
LINE_HOT: J19.3; also elsewhere on the board
LINE_NEUTRAL: J19.2; also elsewhere on the board
unnamed: J19.5, J19.6, Q2.S, R7.1
unnamed: Q2.D, RT1.1
unnamed: LED1.A, R1.1
unnamed: Q2.G, R6.1, R7.2
unnamed: Q1.3 (C), R6.2
unnamed: Q1.2 (B), R5.1
unnamed: J2.2, R5.2

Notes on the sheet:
48V SMPS
COIN DOOR INTERLOCK 5V control signal to coin door switch activates 2N2222 when switch is closed, which in turn activates P-MOSFET to control 48VDC power.
Power reserve for 48V supply, for fast response time and brownout mitigation for high-current coils
Inrush limiter (NTC varistor) 7 ohm, >7A steady state
Generic 5mm Blue LED Vf approx 3.2V, If 20mA Serves as indicator, and drains caps when power is off.
+48V DC


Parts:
J10, J11: 640445-6; SHDR6W183P0X396_1X6_2377X762X1
J12: 640445-5; HDRV5W117P0X396_1X5_1981X762X1
J13: 640445-2; SHDR2W117P0X396_1X2_792X762X11
J14: 640445-4; SHDR4W117P0X396_1X4_1585X762X1
J15: 640445-3; HDRV3W140P0X396_1X3_1189X762X1
J16: 216571-2003; 216571-YY03_1
J17: 640445-8; SHDR8W117P0X396_1X8_3170X762X1

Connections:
5V: J10.6, J11.6, J12.1, J12.2, J12.3, J12.4, J12.5; also elsewhere on the board
6V3: J13.1, J13.2; also elsewhere on the board
12V: J10.5, J11.5, J14.1, J14.2, J14.3, J14.4; also elsewhere on the board
24V: J15.1, J15.2, J15.3; also elsewhere on the board
48V: J16.1, J16.2, J16.3; also elsewhere on the board
GND: J10.1, J10.2, J10.3, J10.4, J11.1, J11.2, J11.3, J11.4, J17.1, J17.2, J17.3, J17.4, J17.5, J17.6, J17.7, J17.8; also elsewhere on the board

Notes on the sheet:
GROUND
48V To pinball coils
POWER OUTPUTS
Note: 48V uses a female header to protect against accidental shorts to the headers pins when the mating connector is unplugged.
To Pinscape Pico Main Board Secondary PSU Power Input
6.3VDC (Button Lamps)
24VDC (Contactors)
12VDC (Motors, LED strips, coils)
5VDC (LEDs)
To Pinscape Pico Power Board Secondary PSU Power Input


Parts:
C1: 1uF; B45181B
C2: 0.1uF; C025-030X050
LED5: Orange; LED5MM
R2: 1.1K; 0204/7
R3: 270R; 0204/7
R11: 220R; 0309/12
U3: LM338T/NOPB; T03B_TEX

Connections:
6V3: C1.+, R3.2, R11.2, U3.2 (OUT); also elsewhere on the board
12V: C2.1, U3.3 (IN); also elsewhere on the board
GND: C1.-, C2.2, LED5.K (C), R2.1; also elsewhere on the board
unnamed: LED5.A, R11.1
unnamed: R2.2, R3.1, U3.1 (ADJ)

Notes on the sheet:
6.3V Lamp Power Supply
This section provides a regulated 6.3VDC power supply, which is the voltage used by the small light bulbs (such as type #44 and #555) used in most pinball machine pushbuttons and coin door slots. Incandescent and LED replacement bulbs of these types are both designed to run on 6.3V. They'll also ru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
Tantalum
6.3V INDICATOR
Generic 5mm orange LED, Vf 2V, If 20mA


Board: 2 copper layers, 160.0 x 79.2 mm, 51 parts (0 on the bottom side), 25 nets.

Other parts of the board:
U$1, U$2, U$3, U$4: 4,1

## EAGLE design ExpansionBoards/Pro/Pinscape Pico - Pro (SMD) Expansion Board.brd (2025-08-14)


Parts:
C38, C39: 1uF X7R; C1206
IC33: TLV75733PDBVR; SOT95P280X145-5N
J1: 640445-6; SHDR6W183P0X396_1X6_2377X762X1
J17: PINHD-1X3; 1X03
J19: PINHD-1X6; 1X06
LED1: EC3528ARGB
LED2: LT_Q39G-Q1OO-25-1; LEDC1608X40N
PICO1: PICO; RPI_PICO_TH_NO_DEBUG
R36, R37, R47: 100R; R0402
R38: 300R; R0402
R40, R41: 3.9K; R0603
SW1: TS-1187A-B-A-B

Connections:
3V3_PERIPHERAL: C39.1, IC33.5 (OUT), J19.5, LED2.2 (A), R40.2, R41.2; also elsewhere on the board
3V3_PERIPHERAL_ENABLE: IC33.3 (EN), PICO1.GP7
3V3_PICO: LED1.1, PICO1.3V3; also elsewhere on the board
5V: J1.6; also elsewhere on the board
12V: J1.5; also elsewhere on the board
/MOTORCTL1: PICO1.GP8; also elsewhere on the board
/MOTORCTL2: PICO1.GP9; also elsewhere on the board
/MOTORCTL3: PICO1.GP14; also elsewhere on the board
/MOTORCTL4: PICO1.GP15; also elsewhere on the board
ACCEL_INTR: PICO1.GP18; also elsewhere on the board
ADC_INTR: PICO1.GP12; also elsewhere on the board
BUTTON_CLK: PICO1.GP21; also elsewhere on the board
BUTTON_DATA: PICO1.GP26_A0; also elsewhere on the board
BUTTON_SHLD: PICO1.GP22; also elsewhere on the board
GND: C38.2, C39.2, IC33.2 (GND), J1.1, J1.2, J1.3, J1.4, J17.2, J19.6, PICO1.AGND, PICO1.GND@1 (GND), PICO1.GND@2 (GND), PICO1.GND@3 (GND), PICO1.GND@4 (GND), PICO1.GND@6 (GND), PICO1.GND@7 (GND), PICO1.GND@8 (GND), R47.1, SW1.C, SW1.D; also elsewhere on the board
IR_IN: PICO1.GP6; also elsewhere on the board
IR_OUT: PICO1.GP0; also elsewhere on the board
JOYSTICK_BUTTON: J19.1, PICO1.GP27_A1
JOYSTICK_X: J19.3; also elsewhere on the board
JOYSTICK_Y: J19.2; also elsewhere on the board
LED_B: PICO1.GP3, R36.1
LED_G: PICO1.GP2, R37.1
LED_R: PICO1.GP1, R38.1
unnamed: LED1.3, R38.2
unnamed: LED1.2, R36.2
unnamed: LED1.4, R37.2
unnamed: PICO1.RUN, SW1.A, SW1.B
unnamed: LED2.1 (K), R47.2
PLUNGER_ADC: PICO1.GP28_A2; also elsewhere on the board
PLUNGER_IRQ1_SCL: PICO1.GP11; also elsewhere on the board
PLUNGER_IRQ2: PICO1.GP13; also elsewhere on the board
PLUNGER_SDA: PICO1.GP10; also elsewhere on the board
PSU2_STATUS_SENSE: PICO1.GP19; also elsewhere on the board
PSU2_STATUS_SET: PICO1.GP20; also elsewhere on the board
SCL: PICO1.GP5, R40.1; also elsewhere on the board
SDA: PICO1.GP4, R41.1; also elsewhere on the board
UART0_RX: J17.3, PICO1.GP17
UART0_TX: J17.1, PICO1.GP16
VBUS: C38.1, IC33.1 (IN), PICO1.VBUS

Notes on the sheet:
Secondary Power Supply Input
I2C0 Bus Pull-ups
Status LED
Raspberry Pi Pico
Use castellated pad version of Pico. Solder Pico directly to main board.
Must be an I2C1 SCL pin ==>
<== Must be an ADC pin (GPxx_Ax)
Must be an I2C1 SDA pin ==>
Pico Hard Reset
UART Port
Serial port for host terminal connection, for logging/debugging.
Joystick Port
Access to extra outboard ADC inputs.
KEY
Peripheral Power
Sourced from VBUS, regulated to 3.3V. Pico has ENABLE control through GPIO to allow hard reset of peripherals under software control
(Peripheral Power indicator)


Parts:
C35: 0.1uF; C0402
IC28: LIS3DHTR

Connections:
3V3_PERIPHERAL: C35.1, IC28.1 (VDDIO), IC28.8 (CS), IC28.14 (VDD); also elsewhere on the board
ACCEL_INTR: IC28.11 (INT1); also elsewhere on the board
GND: C35.2, IC28.5 (GND_1), IC28.7 (SDO/SA0), IC28.10 (RES), IC28.12 (GND_2), IC28.13 (ADC3), IC28.15 (ADC2), IC28.16 (ADC1); also elsewhere on the board
SCL: IC28.4 (SCL/SPC); also elsewhere on the board
SDA: IC28.6 (SDA/SDI/SDO); also elsewhere on the board

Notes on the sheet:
Accelerometer - LIS3DH I2C Address 0x18 (001 1000)
SDO/SA0 sets I2C address: GND = 0x18, VDD = 0x19
CS = VDD -> I2C mode
Also pin-compatible with LIS3DSH (address 0x1E, 001 1110)


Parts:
C42, C43, C44, C45: 0.1uF; C0402
IC24, IC25, IC26, IC27: SN74HC165PWR; SOP65P640X120-16N
J9, J10, J11, J12: 1-640456-0; SHDR10W66P0X254_1X10_2540X572X
R51, R52, R53, R54, R55, R56, R57, R58, R59, R60, R61, R62, R63, R64, R65, R66, R67, R68, R69, R70, R71, R72, R73, R74, R75, R76, R77, R78, R79, R80, R81, R82: 10k; R0402

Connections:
3V3_PICO: C42.1, C43.1, C44.1, C45.1, IC24.16 (VCC), IC25.16 (VCC), IC26.16 (VCC), IC27.16 (VCC), R51.1, R52.1, R53.1, R54.1, R55.1, R56.1, R57.1, R58.1, R59.1, R60.1, R61.1, R62.1, R63.1, R64.1, R65.1, R66.1, R67.1, R68.1, R69.1, R70.1, R71.1, R72.1, R73.1, R74.1, R75.1, R76.1, R77.1, R78.1, R79.1, R80.1, R81.1, R82.1; also elsewhere on the board
BUTTON1: IC24.14 (D), J9.1, R74.2
BUTTON2: IC24.13 (C), J9.2, R73.2
BUTTON3: IC24.12 (B), J9.4, R72.2
BUTTON4: IC24.11 (A), J9.5, R71.2
BUTTON5: IC24.6 (H), J9.6, R70.2
BUTTON6: IC24.5 (G), J9.7, R69.2
BUTTON7: IC24.4 (F), J9.8, R68.2
BUTTON8: IC24.3 (E), J9.9, R67.2
BUTTON9: IC25.14 (D), J10.1, R66.2
BUTTON10: IC25.13 (C), J10.2, R65.2
BUTTON11: IC25.12 (B), J10.3, R64.2
BUTTON12: IC25.11 (A), J10.5, R63.2
BUTTON13: IC25.3 (E), J10.6, R62.2
BUTTON14: IC25.4 (F), J10.7, R61.2
BUTTON15: IC25.5 (G), J10.8, R60.2
BUTTON16: IC25.6 (H), J10.9, R59.2
BUTTON17: IC26.14 (D), J11.1, R58.2
BUTTON18: IC26.13 (C), J11.2, R57.2
BUTTON19: IC26.12 (B), J11.3, R56.2
BUTTON20: IC26.11 (A), J11.4, R55.2
BUTTON21: IC26.3 (E), J11.6, R54.2
BUTTON22: IC26.4 (F), J11.7, R53.2
BUTTON23: IC26.5 (G), J11.8, R52.2
BUTTON24: IC26.6 (H), J11.9, R51.2
BUTTON25: IC27.11 (A), J12.1, R82.2
BUTTON26: IC27.12 (B), J12.2, R81.2
BUTTON27: IC27.13 (C), J12.3, R80.2
BUTTON28: IC27.14 (D), J12.4, R79.2
BUTTON29: IC27.6 (H), J12.5, R78.2
BUTTON30: IC27.5 (G), J12.7, R77.2
BUTTON31: IC27.4 (F), J12.8, R76.2
BUTTON32: IC27.3 (E), J12.9, R75.2
BUTTON_CLK: IC24.2 (CLK), IC25.2 (CLK), IC26.2 (CLK), IC27.2 (CLK); also elsewhere on the board
BUTTON_DATA: IC24.9 (QH); also elsewhere on the board
BUTTON_SHLD: IC24.1 (SH/!LD), IC25.1 (SH/!LD), IC26.1 (SH/!LD), IC27.1 (SH/!LD); also elsewhere on the board
GND: C42.2, C43.2, C44.2, C45.2, IC24.8 (GND), IC24.15 (CLK_INH), IC25.8 (GND), IC25.15 (CLK_INH), IC26.8 (GND), IC26.15 (CLK_INH), IC27.8 (GND), IC27.15 (CLK_INH), J9.10, J10.10, J11.10, J12.10; also elsewhere on the board
unnamed: IC25.10 (SER), IC26.9 (QH)
unnamed: IC24.10 (SER), IC25.9 (QH)
unnamed: IC26.10 (SER), IC27.9 (QH)

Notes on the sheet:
Buttons are independent grounded inputs Not pressed = open, pressed = GND
KEY
Button Port Pull-ups


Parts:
C1, C3: 0.1uF; C0402
C2, C4: 4.7uF; C1206
IC1, IC2: UCC27523D; SOIC127P600X175-8N
J13: 640445-5; HDRV5W117P0X396_1X5_1981X762X1
Q1, Q2: BUK7K89-100EX; BUK7K89100EX
R1, R2, R3, R4: 4R7; R0603

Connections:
12V: C1.1, C2.1, C3.1, C4.1, IC1.1 (ENA), IC1.6 (VDD), IC1.8 (ENB), IC2.1 (ENA), IC2.6 (VDD), IC2.8 (ENB); also elsewhere on the board
/MOTORCTL1: IC1.2 (INA); also elsewhere on the board
/MOTORCTL2: IC1.4 (INB); also elsewhere on the board
/MOTORCTL3: IC2.2 (INA); also elsewhere on the board
/MOTORCTL4: IC2.4 (INB); also elsewhere on the board
GND: C1.2, C2.2, C3.2, C4.2, IC1.3 (GND), IC2.3 (GND), Q1.1 (S1), Q1.3 (S2), Q2.1 (S1), Q2.3 (S2); also elsewhere on the board
MOTOR1: J13.1, Q1.7 (D1_1), Q1.8 (D1_2), Q1.9 (D1_3)
MOTOR2: J13.3, Q1.5 (D2_1), Q1.6 (D2_2), Q1.10 (D2_3)
MOTOR3: J13.4, Q2.7 (D1_1), Q2.8 (D1_2), Q2.9 (D1_3)
MOTOR4: J13.5, Q2.5 (D2_1), Q2.6 (D2_2), Q2.10 (D2_3)
unnamed: IC1.5 (OUTB), R2.2
unnamed: IC2.5 (OUTB), R4.2
unnamed: IC2.7 (OUTA), R3.2
unnamed: IC1.7 (OUTA), R1.2
unnamed: Q1.2 (G1), R1.1
unnamed: Q1.4 (G2), R2.1
unnamed: Q2.2 (G1), R3.1
unnamed: Q2.4 (G2), R4.1

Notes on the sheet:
Decoupling/power reserve for 12V gate driver supply
Motor Outputs - High power MOSFET drive from GPIO PWM x4 These outputs are equivalent to the main set of high-power MOSFET outputs, EXCEPT that they're controlled directly by Pico GPIO PWM channels. This allows the PWM frequency to be controlled by the software, which can be helpful with motors (an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
Note: possible UCC27623 substitutions in case of supply issues: NCP81071A.
Motor Outputs
KEY

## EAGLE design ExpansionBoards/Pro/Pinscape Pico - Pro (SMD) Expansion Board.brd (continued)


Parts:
C5, C7, C9, C11, C13, C15, C17, C19, C21, C23, C25, C27: 0.1uF; C0402
C6, C8, C10, C12, C14, C16, C18, C20, C22, C24, C26, C28: 4.7uF; C1206
C29, C30: 1uF; C0402
IC3, IC4, IC5, IC6, IC7, IC8, IC9, IC10, IC11, IC12, IC13, IC14: UCC27523D; SOIC127P600X175-8N
IC15, IC16: TLC59116FIRHBR; QFN50P500X500X100-33N
J14, J15, J16: 640445-9; SHDR9W117P0X396_1X9_3566X762X1
Q3, Q4, Q5, Q6, Q7, Q8, Q9, Q10, Q11, Q12, Q13, Q14: BUK7K89-100EX; BUK7K89100EX
R5, R6, R7, R8, R9, R10, R11, R12, R13, R14, R15, R16, R17, R18, R19, R20, R21, R22, R23, R24, R25, R26, R27, R28: 200R; R0603
R39, R42: 10K; R0402

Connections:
3V3_PERIPHERAL: C29.1, C30.1, IC15.27 (VCC), IC16.27 (VCC), IC16.31 (A0), R39.2, R42.2; also elsewhere on the board
12V: C5.1, C6.1, C7.1, C8.1, C9.1, C10.1, C11.1, C12.1, C13.1, C14.1, C15.1, C16.1, C17.1, C18.1, C19.1, C20.1, C21.1, C22.1, C23.1, C24.1, C25.1, C26.1, C27.1, C28.1, IC3.1 (ENA), IC3.6 (VDD), IC3.8 (ENB), IC4.1 (ENA), IC4.6 (VDD), IC4.8 (ENB), IC5.1 (ENA), IC5.6 (VDD), IC5.8 (ENB), IC6.1 (ENA), IC6.6 (VDD), IC6.8 (ENB), IC7.1 (ENA), IC7.6 (VDD), IC7.8 (ENB), IC8.1 (ENA), IC8.6 (VDD), IC8.8 (ENB), IC9.1 (ENA), IC9.6 (VDD), IC9.8 (ENB), IC10.1 (ENA), IC10.6 (VDD), IC10.8 (ENB), IC11.1 (ENA), IC11.6 (VDD), IC11.8 (ENB), IC12.1 (ENA), IC12.6 (VDD), IC12.8 (ENB), IC13.1 (ENA), IC13.6 (VDD), IC13.8 (ENB), IC14.1 (ENA), IC14.6 (VDD), IC14.8 (ENB); also elsewhere on the board
/OUTCTL1: IC3.2 (INA), IC15.22 (!OUT15)
/OUTCTL2: IC3.4 (INB), IC15.21 (!OUT14)
/OUTCTL3: IC4.2 (INA), IC15.20 (!OUT13)
/OUTCTL4: IC4.4 (INB), IC15.19 (!OUT12)
/OUTCTL5: IC5.2 (INA), IC15.17 (!OUT11)
/OUTCTL6: IC5.4 (INB), IC15.16 (!OUT10)
/OUTCTL7: IC6.2 (INA), IC15.15 (!OUT9)
/OUTCTL8: IC6.4 (INB), IC15.14 (!OUT8)
/OUTCTL9: IC7.2 (INA), IC15.11 (!OUT7)
/OUTCTL10: IC7.4 (INB), IC15.10 (!OUT6)
/OUTCTL11: IC8.2 (INA), IC15.9 (!OUT5)
/OUTCTL12: IC8.4 (INB), IC15.8 (!OUT4)
/OUTCTL13: IC9.2 (INA), IC15.6 (!OUT3)
/OUTCTL14: IC9.4 (INB), IC15.5 (!OUT2)
/OUTCTL15: IC10.2 (INA), IC15.4 (!OUT1)
/OUTCTL16: IC10.4 (INB), IC15.3 (!OUT0)
/OUTCTL17: IC11.2 (INA), IC16.22 (!OUT15)
/OUTCTL18: IC11.4 (INB), IC16.21 (!OUT14)
/OUTCTL19: IC12.2 (INA), IC16.20 (!OUT13)
/OUTCTL20: IC12.4 (INB), IC16.19 (!OUT12)
/OUTCTL21: IC13.2 (INA), IC16.17 (!OUT11)
/OUTCTL22: IC13.4 (INB), IC16.16 (!OUT10)
/OUTCTL23: IC14.2 (INA), IC16.15 (!OUT9)
/OUTCTL24: IC14.4 (INB), IC16.14 (!OUT8)
/OUTCTL25: IC16.3 (!OUT0); also elsewhere on the board
/OUTCTL26: IC16.4 (!OUT1); also elsewhere on the board
/OUTCTL27: IC16.5 (!OUT2); also elsewhere on the board
/OUTCTL28: IC16.6 (!OUT3); also elsewhere on the board
/OUTCTL29: IC16.8 (!OUT4); also elsewhere on the board
/OUTCTL30: IC16.9 (!OUT5); also elsewhere on the board
/OUTCTL31: IC16.10 (!OUT6); also elsewhere on the board
/OUTCTL32: IC16.11 (!OUT7); also elsewhere on the board
GND: C5.2, C6.2, C7.2, C8.2, C9.2, C10.2, C11.2, C12.2, C13.2, C14.2, C15.2, C16.2, C17.2, C18.2, C19.2, C20.2, C21.2, C22.2, C23.2, C24.2, C25.2, C26.2, C27.2, C28.2, C29.2, C30.2, IC3.3 (GND), IC4.3 (GND), IC5.3 (GND), IC6.3 (GND), IC7.3 (GND), IC8.3 (GND), IC9.3 (GND), IC10.3 (GND), IC11.3 (GND), IC12.3 (GND), IC13.3 (GND), IC14.3 (GND), IC15.1 (A2), IC15.2 (A3), IC15.7 (GND_1), IC15.18 (GND_2), IC15.23 (GND_3), IC15.31 (A0), IC15.32 (A1), IC15.33 (EP), IC16.1 (A2), IC16.2 (A3), IC16.7 (GND_1), IC16.18 (GND_2), IC16.23 (GND_3), IC16.32 (A1), IC16.33 (EP), Q3.1 (S1), Q3.3 (S2), Q4.1 (S1), Q4.3 (S2), Q5.1 (S1), Q5.3 (S2), Q6.1 (S1), Q6.3 (S2), Q7.1 (S1), Q7.3 (S2), Q8.1 (S1), Q8.3 (S2), Q9.1 (S1), Q9.3 (S2), Q10.1 (S1), Q10.3 (S2), Q11.1 (S1), Q11.3 (S2), Q12.1 (S1), Q12.3 (S2), Q13.1 (S1), Q13.3 (S2), Q14.1 (S1), Q14.3 (S2); also elsewhere on the board
unnamed: IC15.24 (!RESET), R39.1
unnamed: IC3.5 (OUTB), R6.2
unnamed: IC4.7 (OUTA), R7.2
unnamed: IC7.7 (OUTA), R13.2
unnamed: IC5.5 (OUTB), R10.2
unnamed: IC6.7 (OUTA), R11.2
unnamed: IC6.5 (OUTB), R12.2
unnamed: IC9.7 (OUTA), R17.2
unnamed: IC8.7 (OUTA), R15.2
unnamed: IC8.5 (OUTB), R16.2
unnamed: IC9.5 (OUTB), R18.2
unnamed: IC10.7 (OUTA), R19.2
unnamed: IC10.5 (OUTB), R20.2
unnamed: IC12.7 (OUTA), R23.2
unnamed: IC11.7 (OUTA), R21.2
unnamed: IC11.5 (OUTB), R22.2
unnamed: IC14.7 (OUTA), R27.2
unnamed: IC12.5 (OUTB), R24.2
unnamed: IC13.5 (OUTB), R26.2
unnamed: IC13.7 (OUTA), R25.2
unnamed: IC14.5 (OUTB), R28.2
unnamed: Q11.2 (G1), R21.1
unnamed: IC5.7 (OUTA), R9.2
unnamed: IC7.5 (OUTB), R14.2
unnamed: Q11.4 (G2), R22.1
unnamed: IC4.5 (OUTB), R8.2
unnamed: IC3.7 (OUTA), R5.2
unnamed: Q12.2 (G1), R23.1
unnamed: Q12.4 (G2), R24.1
unnamed: Q13.2 (G1), R25.1
unnamed: Q13.4 (G2), R26.1
unnamed: Q14.2 (G1), R27.1
unnamed: Q14.4 (G2), R28.1
unnamed: Q7.2 (G1), R13.1
unnamed: Q7.4 (G2), R14.1
unnamed: Q8.2 (G1), R15.1
unnamed: Q10.4 (G2), R20.1
unnamed: Q10.2 (G1), R19.1
unnamed: Q9.4 (G2), R18.1
unnamed: Q9.2 (G1), R17.1
unnamed: Q8.4 (G2), R16.1
unnamed: Q6.4 (G2), R12.1
unnamed: Q6.2 (G1), R11.1
unnamed: Q5.4 (G2), R10.1
unnamed: Q5.2 (G1), R9.1
unnamed: Q4.4 (G2), R8.1
unnamed: Q4.2 (G1), R7.1
unnamed: Q3.4 (G2), R6.1
unnamed: Q3.2 (G1), R5.1
unnamed: IC16.24 (!RESET), R42.1
OUT1: J14.1, Q3.7 (D1_1), Q3.8 (D1_2), Q3.9 (D1_3)
OUT2: J14.3, Q3.5 (D2_1), Q3.6 (D2_2), Q3.10 (D2_3)
OUT3: J14.4, Q4.7 (D1_1), Q4.8 (D1_2), Q4.9 (D1_3)
OUT4: J14.5, Q4.5 (D2_1), Q4.6 (D2_2), Q4.10 (D2_3)
OUT5: J14.6, Q5.7 (D1_1), Q5.8 (D1_2), Q5.9 (D1_3)
OUT6: J14.7, Q5.5 (D2_1), Q5.6 (D2_2), Q5.10 (D2_3)
OUT7: J14.8, Q6.7 (D1_1), Q6.8 (D1_2), Q6.9 (D1_3)
OUT8: J14.9, Q6.5 (D2_1), Q6.6 (D2_2), Q6.10 (D2_3)
OUT9: J15.1, Q7.7 (D1_1), Q7.8 (D1_2), Q7.9 (D1_3)
OUT10: J15.2, Q7.5 (D2_1), Q7.6 (D2_2), Q7.10 (D2_3)
OUT11: J15.4, Q8.7 (D1_1), Q8.8 (D1_2), Q8.9 (D1_3)
OUT12: J15.5, Q8.5 (D2_1), Q8.6 (D2_2), Q8.10 (D2_3)
OUT13: J15.6, Q9.7 (D1_1), Q9.8 (D1_2), Q9.9 (D1_3)
OUT14: J15.7, Q9.5 (D2_1), Q9.6 (D2_2), Q9.10 (D2_3)
OUT15: J15.8, Q10.7 (D1_1), Q10.8 (D1_2), Q10.9 (D1_3)
OUT16: J15.9, Q10.5 (D2_1), Q10.6 (D2_2), Q10.10 (D2_3)
OUT17: J16.1, Q11.7 (D1_1), Q11.8 (D1_2), Q11.9 (D1_3)
OUT18: J16.2, Q11.5 (D2_1), Q11.6 (D2_2), Q11.10 (D2_3)
OUT19: J16.3, Q12.7 (D1_1), Q12.8 (D1_2), Q12.9 (D1_3)
OUT20: J16.5, Q12.5 (D2_1), Q12.6 (D2_2), Q12.10 (D2_3)
OUT21: J16.6, Q13.7 (D1_1), Q13.8 (D1_2), Q13.9 (D1_3)
OUT22: J16.7, Q13.5 (D2_1), Q13.6 (D2_2), Q13.10 (D2_3)
OUT23: J16.8, Q14.7 (D1_1), Q14.8 (D1_2), Q14.9 (D1_3)
OUT24: J16.9, Q14.5 (D2_1), Q14.6 (D2_2), Q14.10 (D2_3)
SCL: IC15.25 (SCL), IC16.25 (SCL); also elsewhere on the board
SDA: IC15.26 (SDA), IC16.26 (SDA); also elsewhere on the board

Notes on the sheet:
High power MOSFET drive from TLC59116F PWM x24 Current limit is LOWER OF connector limit (TE MTA = 7A per pin) OR MOSFET drain current limit (BUK7K89-100EX = 100V/13A)
Decoupling/power reserve for 12V gate driver supply
Bus Address 1100000x ($60)
Bus Address 1100001x ($61)
PWM control for MOSFET ports 1-16
PWM control for MOSFET ports 17-24 plus flasher ports 1-8
Note: possible UCC27623 substitutions in case of supply issues: NCP81071A. Substitute must have inverting inputs with internal pull-up resistors (so that open-drain inputs translate to OFF output).
High-power MOSFET drive ports
KEY
Note: Gate resistor value of 200 Ohms is chosen to protect UCC27523D against damage due to excessive power dissipation during PWM switching. In principle, the gate resistor is primarily to suppress ringing, which only requires a small resistor in the 5 to 10 Ohm range. But practical testing suggest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


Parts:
C31: 1uF; C0402
IC17: TLC59116FIRHBR; QFN50P500X500X100-33N
IC19, IC20, IC21, IC22, IC23: ULN2803CDWR; SOIC127P1030X265-20N
J2: 30316-6002HB; 3M-30316-6002HB
J3: 1-640456-0; SHDR10W66P0X254_1X10_2540X572X
Q15, Q16, Q17, Q18, Q19, Q20, Q21, Q22, Q23, Q24, Q25, Q26: UMA5NTR; SOT65P210X100-5N
R43: 10K; R0402

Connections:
3V3_PERIPHERAL: C31.1, IC17.27 (VCC), IC17.32 (A1), R43.2; also elsewhere on the board
5V: J2.2, Q15.2 (E), Q16.2 (E), Q17.2 (E), Q18.2 (E), Q19.2 (E), Q20.2 (E), Q21.2 (E), Q22.2 (E), Q23.2 (E), Q24.2 (E), Q25.2 (E), Q26.2 (E); also elsewhere on the board
/OUTCTL25: Q18.3 (B2); also elsewhere on the board
/OUTCTL26: Q18.1 (B1); also elsewhere on the board
/OUTCTL27: Q17.3 (B2); also elsewhere on the board
/OUTCTL28: Q17.1 (B1); also elsewhere on the board
/OUTCTL29: Q16.3 (B2); also elsewhere on the board
/OUTCTL30: Q16.1 (B1); also elsewhere on the board
/OUTCTL31: Q15.3 (B2); also elsewhere on the board
/OUTCTL32: Q15.1 (B1); also elsewhere on the board
/OUTCTL33: IC17.14 (!OUT8), Q22.3 (B2)
/OUTCTL34: IC17.15 (!OUT9), Q22.1 (B1)
/OUTCTL35: IC17.16 (!OUT10), Q21.3 (B2)
/OUTCTL36: IC17.17 (!OUT11), Q21.1 (B1)
/OUTCTL37: IC17.19 (!OUT12), Q20.3 (B2)
/OUTCTL38: IC17.20 (!OUT13), Q20.1 (B1)
/OUTCTL39: IC17.21 (!OUT14), Q19.3 (B2)
/OUTCTL40: IC17.22 (!OUT15), Q19.1 (B1)
/OUTCTL41: IC17.3 (!OUT0), Q26.3 (B2)
/OUTCTL42: IC17.4 (!OUT1), Q26.1 (B1)
/OUTCTL43: IC17.5 (!OUT2), Q25.3 (B2)
/OUTCTL44: IC17.6 (!OUT3), Q25.1 (B1)
/OUTCTL45: IC17.8 (!OUT4), Q24.3 (B2)
/OUTCTL46: IC17.9 (!OUT5), Q24.1 (B1)
/OUTCTL47: IC17.10 (!OUT6), Q23.3 (B2)
/OUTCTL48: IC17.11 (!OUT7), Q23.1 (B1)
FLASHER1: IC19.19 (2C), IC19.20 (1C), J2.15
FLASHER2: IC19.17 (4C), IC19.18 (3C), J2.13
FLASHER3: IC19.15 (6C), IC19.16 (5C), J2.11
FLASHER4: IC19.13 (8C), IC19.14 (7C), J2.9
FLASHER5: IC20.19 (2C), IC20.20 (1C), J2.7
FLASHER6: IC20.17 (4C), IC20.18 (3C), J2.5
FLASHER7: IC20.15 (6C), IC20.16 (5C), J2.3
FLASHER8: IC20.13 (8C), IC20.14 (7C), J2.1
FLASHER9: IC21.19 (2C), IC21.20 (1C), J2.16
FLASHER10: IC21.17 (4C), IC21.18 (3C), J2.14
FLASHER11: IC21.15 (6C), IC21.16 (5C), J2.12
FLASHER12: IC21.13 (8C), IC21.14 (7C), J2.10
FLASHER13: IC22.19 (2C), IC22.20 (1C), J2.8
FLASHER14: IC22.17 (4C), IC22.18 (3C), J2.6
FLASHER15: IC22.15 (6C), IC22.16 (5C), J2.4
FLASHER16: IC22.13 (8C), IC22.14 (7C), J3.1
GND: C31.2, IC17.1 (A2), IC17.2 (A3), IC17.7 (GND_1), IC17.18 (GND_2), IC17.23 (GND_3), IC17.31 (A0), IC17.33 (EP), IC19.9 (GND), IC20.9 (GND), IC21.9 (GND), IC22.9 (GND), IC23.9 (GND); also elsewhere on the board
LAMP1: IC23.20 (1C), J3.3
LAMP2: IC23.19 (2C), J3.4
LAMP3: IC23.18 (3C), J3.5
LAMP4: IC23.17 (4C), J3.6
LAMP5: IC23.16 (5C), J3.7
LAMP6: IC23.15 (6C), J3.8
LAMP7: IC23.14 (7C), J3.9
LAMP8: IC23.13 (8C), J3.10
unnamed: IC17.24 (!RESET), R43.1
OUTCTL25: IC20.7 (7B), IC20.8 (8B), Q18.4 (C2)
OUTCTL26: IC20.5 (5B), IC20.6 (6B), Q18.5 (C1)
OUTCTL27: IC20.3 (3B), IC20.4 (4B), Q17.4 (C2)
OUTCTL28: IC20.1 (1B), IC20.2 (2B), Q17.5 (C1)
OUTCTL29: IC19.7 (7B), IC19.8 (8B), Q16.4 (C2)
OUTCTL30: IC19.5 (5B), IC19.6 (6B), Q16.5 (C1)
OUTCTL31: IC19.3 (3B), IC19.4 (4B), Q15.4 (C2)
OUTCTL32: IC19.1 (1B), IC19.2 (2B), Q15.5 (C1)
OUTCTL33: IC22.7 (7B), IC22.8 (8B), Q22.4 (C2)
OUTCTL34: IC22.5 (5B), IC22.6 (6B), Q22.5 (C1)
OUTCTL35: IC22.3 (3B), IC22.4 (4B), Q21.4 (C2)
OUTCTL36: IC22.1 (1B), IC22.2 (2B), Q21.5 (C1)
OUTCTL37: IC21.7 (7B), IC21.8 (8B), Q20.4 (C2)
OUTCTL38: IC21.5 (5B), IC21.6 (6B), Q20.5 (C1)
OUTCTL39: IC21.3 (3B), IC21.4 (4B), Q19.4 (C2)
OUTCTL40: IC21.1 (1B), IC21.2 (2B), Q19.5 (C1)
OUTCTL41: IC23.8 (8B), Q26.4 (C2)
OUTCTL42: IC23.7 (7B), Q26.5 (C1)
OUTCTL43: IC23.6 (6B), Q25.4 (C2)
OUTCTL44: IC23.5 (5B), Q25.5 (C1)
OUTCTL45: IC23.4 (4B), Q24.4 (C2)
OUTCTL46: IC23.3 (3B), Q24.5 (C1)
OUTCTL47: IC23.2 (2B), Q23.4 (C2)
OUTCTL48: IC23.1 (1B), Q23.5 (C1)
SCL: IC17.25 (SCL); also elsewhere on the board
SDA: IC17.26 (SDA); also elsewhere on the board

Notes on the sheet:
1A Flasher + Strobe LED Drivers Use 2 Darlingtons in parallel per output for 1A capacity
500mA Lamp Drivers
RGB Flashers, 1A each port (designed 5x RGB) Pinscape v1 board compatible connector
Lamp/Misc, 500mA each port Pin 1 = 1A capable
Pin 1 can sink up to 1A Pins 2-9 can sink up to 500mA
Bus Address 1100010x ($62)
Note: RN2706,LF can be substituted for UMA5NTR; or any similar pre-biased PNP pair with a series base resistor around 1K to 4.7K; if possible, the device should also include a pull-up resistor between emitter and base with resistance at least 10x the base resistor's.
PWM control for flashers and lamps
KEY


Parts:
C32: 1uF; C0402
IC18: TLC59116FIRHBR; QFN50P500X500X100-33N
J4, J5: 640456-9; SHDR9W66P0X254_1X9_2286X572X10
R44: 10K; R0402

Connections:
3V3_PERIPHERAL: C32.1, IC18.27 (VCC), IC18.31 (A0), IC18.32 (A1), R44.2; also elsewhere on the board
GND: C32.2, IC18.1 (A2), IC18.2 (A3), IC18.7 (GND_1), IC18.18 (GND_2), IC18.23 (GND_3), IC18.33 (EP); also elsewhere on the board
LED1: IC18.22 (!OUT15), J4.1
LED2: IC18.21 (!OUT14), J4.2
LED3: IC18.20 (!OUT13), J4.4
LED4: IC18.19 (!OUT12), J4.5
LED5: IC18.17 (!OUT11), J4.6
LED6: IC18.16 (!OUT10), J4.7
LED7: IC18.15 (!OUT9), J4.8
LED8: IC18.14 (!OUT8), J4.9
LED9: IC18.11 (!OUT7), J5.1
LED10: IC18.10 (!OUT6), J5.3
LED11: IC18.9 (!OUT5), J5.4
LED12: IC18.8 (!OUT4), J5.5
LED13: IC18.6 (!OUT3), J5.6
LED14: IC18.5 (!OUT2), J5.7
LED15: IC18.4 (!OUT1), J5.8
LED16: IC18.3 (!OUT0), J5.9
unnamed: IC18.24 (!RESET), R44.1
SCL: IC18.25 (SCL); also elsewhere on the board
SDA: IC18.26 (SDA); also elsewhere on the board

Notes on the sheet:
Small LEDs, 120mA/17V max each port
Small LED Drivers Direct drive through TLC59116F Each port is an open-drain current sink, 120mA/17V max
Bus Address 1100011x ($63)
KEY


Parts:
C37: 0.1uF; C0402
IC32: ADS1115IDGSR; SOP50P490X110-10N
J8: 30308-6002HB; SHDR8W69P254_2X4_1780X878X955P
R29, R45: 10K; R0603

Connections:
3V3_PERIPHERAL: C37.1, IC32.8 (VDD), J8.4, R45.1; also elsewhere on the board
5V: J8.2; also elsewhere on the board
ADC_INTR: IC32.2 (ALERT/RDY); also elsewhere on the board
GND: C37.2, IC32.1 (ADDR), IC32.3 (GND), J8.3, R29.1; also elsewhere on the board
JOYSTICK_X: IC32.6 (AIN2); also elsewhere on the board
JOYSTICK_Y: IC32.5 (AIN1); also elsewhere on the board
unnamed: IC32.7 (AIN3), R29.2, R45.2
PLUNGER_ADC: IC32.4 (AIN0), J8.8; also elsewhere on the board
PLUNGER_IRQ1_SCL: J8.6; also elsewhere on the board
PLUNGER_IRQ2: J8.5; also elsewhere on the board
PLUNGER_SDA: J8.1; also elsewhere on the board
SCL: IC32.10 (SCL); also elsewhere on the board
SDA: IC32.9 (SDA); also elsewhere on the board

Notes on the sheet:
Plunger Sensor
Plunger Connections This header is laid out the same way as the corresponding header on the original Pinscape KL25Z Expansion Boards, for plug-and-play migration. Plunger Port Mappings vs KL25Z Pin KL25Z Pico Functions 1 PTE20 GP10 SDA/GPIO (CCD SI, I2C data) 2 5V 5V 5V Power Supply 3 GND GND Groun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
Plunger ADC The Pico has an on-board ADC, but its resolution is fairly coarse (effectively 8 bits), and it has some well-known defects that were only discovered after production started. Potentiometer plungers in particular can benefit from a better ADC, and are probably the most popular plunger se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
I2C Bus Address $48 (1001000x)

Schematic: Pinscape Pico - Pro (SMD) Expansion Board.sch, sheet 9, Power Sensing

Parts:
C36: 0.1uF; C0402
IC29: SN74LVC1G175DCKR; SOP65P210X110-6N
IC30: APX809S-29SA-7; SOT23_DIO; MANUFACTURER_PART_NUMBER APX809S-40SA-7
IC31: LTV-827S; SOP254P1016X460-8N
R32, R33: 10K; R0402; PARTNO 660-MS1/4DCT52R1002
R34: 360R; R0402; PARTNO 660-MS1/4DCT52R1002
R35: 240R; R0402; PARTNO 594-SFR16S0005600FR5

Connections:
3V3_PERIPHERAL: IC31.6 (C_1); also elsewhere on the board
5V: C36.1, IC29.3 (D), IC29.5 (VCC), IC30.3 (VCC), IC31.8 (C_2); also elsewhere on the board
GND: C36.2, IC29.2 (GND), IC30.1 (GND), R32.1, R33.1, R34.2, R35.2; also elsewhere on the board
unnamed: IC29.1 (CLK), IC31.7 (E_2), R32.2
unnamed: IC31.2 (K_1), R35.1
unnamed: IC29.6 (!CLR), IC30.2 (!RESET)
unnamed: IC31.4 (K_2), R34.1
unnamed: IC29.4 (Q), IC31.3 (A_2)
PSU2_STATUS_SENSE: IC31.5 (E_1), R33.2; also elsewhere on the board
PSU2_STATUS_SET: IC31.1 (A_1); also elsewhere on the board

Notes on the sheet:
PSU2 Power Sensing This circuit monitors the status of a secondary power supply (PSU2) that's hard-switched on and off with the overall pinball cabinet power. The status circuit maintains its own memory of the power state, independently of the Pico's power state, which satisfies two important condi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
POR part selection: The POR is triggered by the voltage on the 5V supply crossing a threshold voltage, so we must choose a POR whose threshold voltage slightly below the MINIMUM voltage that the 5V supply maintains when powered on and operating stably. Nominally, this would be 4.75V for an ATX supp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
Note: RESET signal must be ACTIVE LOW

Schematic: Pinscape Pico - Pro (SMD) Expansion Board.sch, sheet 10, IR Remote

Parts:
D1, D2: 1N4148WT-7; 1N4148WT7
J6: 640454-2; HDRV2W66P0X254_1X2_762X572X100
J7: 215079-4; 2150794
Q27: DSS8110Y-7; SOT65P210X110-6N
R30: 540R; R0402
R31: 2R5; R0603

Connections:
3V3_PERIPHERAL: J7.1; also elsewhere on the board
5V: J6.1; also elsewhere on the board
GND: D2.1 (K), J7.2, J7.4, R31.1; also elsewhere on the board
IR_IN: J7.3; also elsewhere on the board
IR_LED_CATHODE: J6.2, Q27.1 (C_1), Q27.2 (C_2), Q27.5 (C_3), Q27.6 (C_4)
IR_OUT: R30.2; also elsewhere on the board
unnamed: Q27.4 (E), R31.2
unnamed: D1.2 (A), Q27.3 (B), R30.1
unnamed: D1.1 (K), D2.2 (A)

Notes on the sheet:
IR REMOTE RECEIVER CONNECTOR This header allows connecting an IR receiver (TSOP38438) on a separate circuit board, connected to the main board with a 4-conductor ribbon cable. (Ribbon cable was chosen for the sake of signal integrity.) The reason for placing the receiver off-board is so that it can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
===> IRED Cathode (-)
===> IRED Anode (+)
Note: TE Connectivity Micro-Match 215079-4 base pairs with 215083-4 on-cable IDC connector.
CURRENT-SENSE RESISTOR Resistor sets current to I(LED) = 0.5V/R R=2.5 ohms -> 200mA current
IR REMOTE CONTROL TRANSMITTER Use with TSAL6400 IRED or equivalent, with a peak wavelength around 940nm. Set the current-sense resistor according to the desired forward current on the IR LED. No external current-limiting resistor is needed. Two IR LEDs can be connected in series provided that Vf is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

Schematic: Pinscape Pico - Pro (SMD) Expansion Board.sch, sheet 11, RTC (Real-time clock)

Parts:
BATT1: BH-123A-1
C40, C41: 100nF; C0402
IC34: RV-3032-C7; RV3032C7
R46: 10K; R0402
R49: 100R; R0402

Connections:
3V3_PERIPHERAL: C40.1, IC34.6 (VDD); also elsewhere on the board
GND: BATT1.-, C40.2, C41.2, IC34.5 (VSS), R46.1; also elsewhere on the board
unnamed: BATT1.+, R49.2
unnamed: IC34.4 (EVI), R46.2
unnamed: C41.1, IC34.1 (VBACKUP), R49.1
SCL: IC34.8 (SCL); also elsewhere on the board
SDA: IC34.2 (SDA); also elsewhere on the board

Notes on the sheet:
3V CR2032
I2C Addr 1101000x (68)
Real-Time Clock/Calendar with battery backup (optional)
These parts provide timekeeping for the Pico across CPU resets, and with the backup battery installed, keeps time even when the main USB power is off or the board is disconnected from the host. These parts are optional; if the RTC feature isn't needed, simply leave the RTC chip and battery holder u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

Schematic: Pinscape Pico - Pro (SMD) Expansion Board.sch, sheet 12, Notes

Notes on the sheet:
I2C Addresses Use 7-bit address notation, per Pico SDK conventions $18 LIS3DHTR (accelerometer) $48 IC29 ADS1115 (ADC) $51 IC32 RV-3032-C7 (RTC) $60 IC15 TLC59116F (PWM) $61 IC16 TLC59116F (PWM) $62 IC17 TLC59116F (PWM) $63 IC18 TLC59116F (PWM) Note: TLC59116F addresses $68 and $6B are reserved; do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
Reserved Pico PWM Channels Note: PWM channels associated with the pins assigned to the plunger sensor interface are marked as reserved because some sensors require one or more PWM inputs (e.g., for clock signals). Whether or not these channels are actually used as PWM in a deployment depends on whi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
General Notes: 1. Avoid routing signals under the I2C (SDA/SCL) traces. When unavoidable, route underlying signal traces at right angles to the I2C traces to minimize coupling.
Copyright and License Info Pinscape Pico "Pro" Expansion Board Copyright 2024, 2025 Michael J Roberts BSD 3-clause license


Board: 2 copper layers, 170.6 x 108.0 mm, 213 parts (0 on the bottom side), 287 nets.

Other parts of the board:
U$1, U$2, U$3, U$4: 4,1

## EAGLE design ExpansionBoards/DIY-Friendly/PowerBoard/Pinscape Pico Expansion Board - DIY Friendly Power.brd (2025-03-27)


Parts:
D1, D2: SB140-T; DIOAD1408W86L464D236
PICO1, PICO2: RPI_PICO_NO_DEBUG; RPI_PICO_TH_NO_DEBUG
Q17, Q18: 2N2222A
R13, R33: 2.2k; 0204/7; PARTNO 660-MFS1/4DCT52R47R0
R18, R32: 4.7K; 0204/7; PARTNO 660-MFS1/4DCT52R47R0
S1, S2: 10-XX; B3F-10XX

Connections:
/PERIPHERAL_POWER_ENABLE: R13.1, R33.1; also elsewhere on the board
GND: PICO1.AGND, PICO1.GND@1 (GND), PICO1.GND@2 (GND), PICO1.GND@3 (GND), PICO1.GND@4 (GND), PICO1.GND@6 (GND), PICO1.GND@7 (GND), PICO1.GND@8 (GND), PICO2.AGND, PICO2.GND@1 (GND), PICO2.GND@2 (GND), PICO2.GND@3 (GND), PICO2.GND@4 (GND), PICO2.GND@6 (GND), PICO2.GND@7 (GND), PICO2.GND@8 (GND), Q17.1 (E), Q18.1 (E), S1.1 (S), S1.2 (S1), S2.1 (S), S2.2 (S1); also elsewhere on the board
LAMPCTL1: PICO1.GP9; also elsewhere on the board
LAMPCTL2: PICO1.GP8; also elsewhere on the board
LAMPCTL3: PICO1.GP7; also elsewhere on the board
LAMPCTL4: PICO1.GP6; also elsewhere on the board
LAMPCTL5: PICO1.GP5; also elsewhere on the board
LAMPCTL6: PICO1.GP4; also elsewhere on the board
LAMPCTL7: PICO1.GP3; also elsewhere on the board
LAMPCTL8: PICO1.GP2; also elsewhere on the board
LAMPCTL9: PICO2.GP16; also elsewhere on the board
LAMPCTL10: PICO2.GP17; also elsewhere on the board
LAMPCTL11: PICO2.GP18; also elsewhere on the board
LAMPCTL12: PICO2.GP19; also elsewhere on the board
LAMPCTL13: PICO2.GP20; also elsewhere on the board
LAMPCTL14: PICO2.GP21; also elsewhere on the board
LAMPCTL15: PICO2.GP22; also elsewhere on the board
LAMPCTL16: PICO2.GP1; also elsewhere on the board
LAMPCTL17: PICO2.GP0; also elsewhere on the board
LAMPCTL18: PICO2.GP28_A2; also elsewhere on the board
LAMPCTL19: PICO2.GP15; also elsewhere on the board
LAMPCTL20: PICO2.GP14; also elsewhere on the board
LAMPCTL21: PICO2.GP13; also elsewhere on the board
LAMPCTL22: PICO2.GP12; also elsewhere on the board
LAMPCTL23: PICO2.GP11; also elsewhere on the board
LAMPCTL24: PICO2.GP10; also elsewhere on the board
LAMPCTL25: PICO2.GP9; also elsewhere on the board
LAMPCTL26: PICO2.GP8; also elsewhere on the board
LAMPCTL27: PICO2.GP7; also elsewhere on the board
LAMPCTL28: PICO2.GP6; also elsewhere on the board
LAMPCTL29: PICO2.GP2; also elsewhere on the board
LAMPCTL30: PICO2.GP3; also elsewhere on the board
LAMPCTL31: PICO2.GP4; also elsewhere on the board
LAMPCTL32: PICO2.GP5; also elsewhere on the board
unnamed: D1.1 (K), PICO2.VSYS
unnamed: D2.1 (K), PICO1.VSYS
unnamed: PICO2.3V3, R32.2
unnamed: Q17.2 (B), R33.2
unnamed: PICO2.RUN, Q17.3 (C), R32.1, S2.3, S2.4 (P1)
unnamed: PICO1.3V3, R18.2
unnamed: Q18.2 (B), R13.2
unnamed: PICO1.RUN, Q18.3 (C), R18.1, S1.3, S1.4 (P1)
OUTCTL13: PICO1.GP28_A2; also elsewhere on the board
OUTCTL14: PICO1.GP0; also elsewhere on the board
OUTCTL15: PICO1.GP1; also elsewhere on the board
OUTCTL16: PICO1.GP22; also elsewhere on the board
OUTCTL17: PICO1.GP21; also elsewhere on the board
OUTCTL18: PICO1.GP20; also elsewhere on the board
OUTCTL19: PICO1.GP19; also elsewhere on the board
OUTCTL20: PICO1.GP18; also elsewhere on the board
OUTCTL21: PICO1.GP17; also elsewhere on the board
OUTCTL22: PICO1.GP16; also elsewhere on the board
OUTCTL23: PICO1.GP15; also elsewhere on the board
OUTCTL24: PICO1.GP14; also elsewhere on the board
OUTCTL25: PICO1.GP13; also elsewhere on the board
OUTCTL26: PICO1.GP12; also elsewhere on the board
OUTCTL27: PICO1.GP11; also elsewhere on the board
OUTCTL28: PICO1.GP10; also elsewhere on the board
SCL: PICO1.GP27_A1, PICO2.GP27_A1; also elsewhere on the board
SDA: PICO1.GP26_A0, PICO2.GP26_A0; also elsewhere on the board
VBUS: D1.2 (A), D2.2 (A); also elsewhere on the board

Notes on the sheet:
Worker Pico 1
Worker Pico 2
Pico 2 Reset


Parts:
J3: 640445-6; SHDR6W183P0X396_1X6_2377X762X1
J8: PINHD-1X8/90; 1X08/90

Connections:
5V: J3.6; also elsewhere on the board
12V: J3.5; also elsewhere on the board
/PERIPHERAL_POWER_ENABLE: J8.7; also elsewhere on the board
GND: J3.1, J3.2, J3.3, J3.4, J8.2, J8.4, J8.6, J8.8; also elsewhere on the board
SCL: J8.3; also elsewhere on the board
SDA: J8.5; also elsewhere on the board
VBUS: J8.1; also elsewhere on the board

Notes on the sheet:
Secondary PSU Power Input
Cross-Board Signals


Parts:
C1, C3, C5, C7, C9, C11, C13, C15: 100nF; C025-024X044; PARTNO 21RZ310-RC
C2, C4, C6, C8, C10, C12, C14, C16: 4.7uF; C025-024X044; PARTNO 810-FG14X5R1H475KRT0
IC1, IC2, IC3, IC4, IC5, IC6, IC7, IC8: UCC27524P; DIP794W53P254L959H508Q8N
J1, J2: 640445-9; SHDR9W117P0X396_1X9_3566X762X1
Q1, Q2, Q3, Q4, Q5, Q6, Q7, Q8, Q9, Q10, Q11, Q12, Q13, Q14, Q15, Q16: STP19NF20; TO220BV; PARTNO FDPF085N10A
R1, R2, R3, R4, R5, R6, R7, R8, R9, R10, R11, R12, R14, R15, R16, R17: 200R; 0204/5; PARTNO 660-MFS1/4DCT52R47R0

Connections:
12V: C1.2, C2.2, C3.2, C4.2, C5.2, C6.2, C7.2, C8.2, C9.2, C10.2, C11.2, C12.2, C13.2, C14.2, C15.2, C16.2, IC1.1 (ENA), IC1.6 (VDD), IC1.8 (ENB), IC2.1 (ENA), IC2.6 (VDD), IC2.8 (ENB), IC3.1 (ENA), IC3.6 (VDD), IC3.8 (ENB), IC4.1 (ENA), IC4.6 (VDD), IC4.8 (ENB), IC5.1 (ENA), IC5.6 (VDD), IC5.8 (ENB), IC6.1 (ENA), IC6.6 (VDD), IC6.8 (ENB), IC7.1 (ENA), IC7.6 (VDD), IC7.8 (ENB), IC8.1 (ENA), IC8.6 (VDD), IC8.8 (ENB); also elsewhere on the board
GND: C1.1, C2.1, C3.1, C4.1, C5.1, C6.1, C7.1, C8.1, C9.1, C10.1, C11.1, C12.1, C13.1, C14.1, C15.1, C16.1, IC1.3 (GND), IC2.3 (GND), IC3.3 (GND), IC4.3 (GND), IC5.3 (GND), IC6.3 (GND), IC7.3 (GND), IC8.3 (GND), Q1.3 (S), Q2.3 (S), Q3.3 (S), Q4.3 (S), Q5.3 (S), Q6.3 (S), Q7.3 (S), Q8.3 (S), Q9.3 (S), Q10.3 (S), Q11.3 (S), Q12.3 (S), Q13.3 (S), Q14.3 (S), Q15.3 (S), Q16.3 (S); also elsewhere on the board
unnamed: IC1.7 (OUTA), R1.1
unnamed: IC1.5 (OUTB), R2.1
unnamed: Q1.1 (G), R1.2
unnamed: Q2.1 (G), R2.2
unnamed: IC2.7 (OUTA), R3.1
unnamed: IC2.5 (OUTB), R4.1
unnamed: Q3.1 (G), R3.2
unnamed: Q4.1 (G), R4.2
unnamed: IC3.7 (OUTA), R5.1
unnamed: IC3.5 (OUTB), R6.1
unnamed: Q5.1 (G), R5.2
unnamed: Q6.1 (G), R6.2
unnamed: IC4.7 (OUTA), R7.1
unnamed: IC4.5 (OUTB), R8.1
unnamed: Q7.1 (G), R7.2
unnamed: Q8.1 (G), R8.2
unnamed: IC5.7 (OUTA), R14.1
unnamed: IC5.5 (OUTB), R15.1
unnamed: IC7.7 (OUTA), R9.1
unnamed: IC7.5 (OUTB), R10.1
unnamed: Q13.1 (G), R9.2
unnamed: Q14.1 (G), R10.2
unnamed: Q9.1 (G), R14.2
unnamed: Q10.1 (G), R15.2
unnamed: IC6.7 (OUTA), R16.1
unnamed: IC6.5 (OUTB), R17.1
unnamed: Q11.1 (G), R16.2
unnamed: Q12.1 (G), R17.2
unnamed: IC8.7 (OUTA), R11.1
unnamed: IC8.5 (OUTB), R12.1
unnamed: Q15.1 (G), R11.2
unnamed: Q16.1 (G), R12.2
OUT13: J1.1, Q1.2 (D)
OUT14: J1.2, Q2.2 (D)
OUT15: J1.4, Q3.2 (D)
OUT16: J1.5, Q4.2 (D)
OUT17: J1.6, Q5.2 (D)
OUT18: J1.7, Q6.2 (D)
OUT19: J1.8, Q7.2 (D)
OUT20: J1.9, Q8.2 (D)
OUT21: J2.1, Q9.2 (D)
OUT22: J2.2, Q10.2 (D)
OUT23: J2.3, Q11.2 (D)
OUT24: J2.5, Q12.2 (D)
OUT25: J2.6, Q13.2 (D)
OUT26: J2.7, Q14.2 (D)
OUT27: J2.8, Q15.2 (D)
OUT28: J2.9, Q16.2 (D)
OUTCTL13: IC1.2 (INA); also elsewhere on the board
OUTCTL14: IC1.4 (INB); also elsewhere on the board
OUTCTL15: IC2.2 (INA); also elsewhere on the board
OUTCTL16: IC2.4 (INB); also elsewhere on the board
OUTCTL17: IC3.2 (INA); also elsewhere on the board
OUTCTL18: IC3.4 (INB); also elsewhere on the board
OUTCTL19: IC4.2 (INA); also elsewhere on the board
OUTCTL20: IC4.4 (INB); also elsewhere on the board
OUTCTL21: IC5.2 (INA); also elsewhere on the board
OUTCTL22: IC5.4 (INB); also elsewhere on the board
OUTCTL23: IC6.2 (INA); also elsewhere on the board
OUTCTL24: IC6.4 (INB); also elsewhere on the board
OUTCTL25: IC7.2 (INA); also elsewhere on the board
OUTCTL26: IC7.4 (INB); also elsewhere on the board
OUTCTL27: IC8.2 (INA); also elsewhere on the board
OUTCTL28: IC8.4 (INB); also elsewhere on the board
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

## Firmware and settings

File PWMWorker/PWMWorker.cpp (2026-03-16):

// Pinscape Pico - PWM Worker Program
// Copyright 2024, 2025 Michael J Roberts / BSD-3-Clause license / NO WARRANTY
//
// This Pico firmware is a helper for Pinscape Pico.  It turns a Pico
// into an I2C slave that acts as a PWM controller chip, along the lines
// of a TLC59116 or PCA9685.  The idea is that a Pico can be used as an
// alternative to one of those PWM chips.  A Pico equipped with this
// firmware can control 24 PWM channels, so it can replace 1-1/2 of the
// typical dedicated chips, which are mostly 16-channel devices.
//
// The reason you might want to use a Pico in place of a dedicated PWM
// chip is that all of the PWM chips currently in production are only
// available in fine-pitch SMD packages, which are difficult to solder
// by hand.  The Pico, in contrast, is easy to work with by hand, so
// using it in place of an SMD PWM chip makes it possible to design a
// DIY-friendly Pinscape Pico expansion board.
//
// A Pico running this firmware acts as an I2C slave device, so it can
// be placed on an I2C bus alongside other I2C devices.  The I2C slave
// address is programmable, allowing multiple PWM Worker Picos to share
// a single bus, so that you can add as many ports as you need.  (Not an
// unlimited number of ports, since an I2C bus can only handle about 20
// devices in practice, but there should be plenty of headroom for any
// pin cab application.)
//
// Pico GPIO pin assignments:
//
//   GP0   LED0 output
//   GP1   LED1 output
//   ..
//   GP22  LED22 output
//   GP28  LED23 output
//
//   GP26  SDA
//   GP27  SCL
//
//
// I2C register map
// (All addresses reference 8-bit bytes; 16-bit registers are arranged as two
// consecutive byte addresses, with the context in little-endian order)
//
// 0x00    LED0 level, 0-255                0 on reset
// 0x01    LED1 level, 0-255                0 on reset
// ..
// 0x17    LED23 level, 0-255               0 on reset
//
// 0x18    Control register 0               0 on reset
// 0x19    Control register 1               0 on reset
// 0x19    PWM frequency, low byte          } 20000
// 0x1A    PWM frequency, high byte         }  on reset
//
// 0x1E    Version                          read-only; returns firmware version
// 0x1F    WHO AM I                         read-only; returns identification code
//
// 0x20    LED0 configuration register      0 on reset
// 0x21    LED0 power level limit register  0xFF on reset
// 0x22    LED0 time limit, low byte        } 0 on
// 0x23    LED0 time limit, high byte       }  reset
//
// 0x24    LED0 configuration register      0 on reset
// 0x25    LED0 power level limit register  0xFF on reset
// 0x26    LED0 time limit, low byte        } 0 on
// 0x27    LED0 time limit, high byte       }  reset
//
// ...
//
// 0x7C    LED23 configuration register      0 on reset
// 0x7D    LED23 power level limit register  0xFF on reset
// 0x7E    LED23 time limit, low byte        } 0 on
// 0x7F    LED23 time limit, high byte       }  reset
// 
//
// Control register 0:  Global control bit map.  Initial value 0x00.
//   0x01  Enable outputs (outputs are in high-impedance state when disabled)
//
// Control register 1: Global control bit map.  Initial value 0x00.
// Reserved for future use.
//
// PWM frequency register: sets the PWM frequency in Hertz.  The setting
// is global to all outputs.
//
// Port registers: Each port has a group of four register bytes with
// configuration settings for the port.
//
// LEDnn configuration:  A bit map, 0x00 on reset:
//   0x01  Active Low (0=active high [default], 1=active low)
//   0x02  Gamma enabled (0=linear [default], 1=gamma correction enabled)
//
// LEDnn power level limit: 0xFF on reset; sets the reduced power level
// applied after the power level exceeds this limit for the timeout period.
//
// LEDnn time limit: two bytes, little-endian, 0x00 0x00 on reset.  Sets
// the timeout period in milliseconds before the power level limit is
// applied.  When a new level is set exceeding the limit level, the timer
// starts; when the time limit is reached, the port level is reduced to
// the limit level.
//
//
// Gamma correction: When the gamma bit is set, the 8-bit brightness
// level in the Output Level register for an LED is mapped to a 12-bit
// scale through a gamma function, to improve the perceptual linearity
// of the brightness setting.  Delegating the gamma mapping to the PWM
// Worker Pico is advantageous because it allows allows fine-grained
// 12-bit resolution on the physical output while sending only 8-bit
// levels on the I2C bus, conserving I2C bandwidth.  The main Pico gets
// its level settings from the host in 8-bit notation, so there's no
// benefit to expanding this to 12-bit notation in the I2C command, but
// there is a benefit to expanding it to 12 bits for the physical
// output, since that gives us smoother fades by making the steps
// between brightness levels less apparent.  It also allows for finer
// gradations at low brightness; with 8-bit PWM, the gamma curve is so
// flat that everything below about 30/255 maps to zero duty cycle after
// gamma correction, while 12-bit PWM has a non-zero duty cycle down to
// 11/255.
//
// Time limiter:  The output is only allowed to exceed the value in its
// corresponding power level limit register (0x40-0x57) for the time
// specified in its time limit register (0x60-0x8F).  The time limit
// registers are interpreted as unsigned 16-bit integers giving a time
// limit in milliseconds.  This allows the main Pinscape software to
// delegate the time-limiter feature to the PWM Worker, which is more
// robust against faults, such as software crashes on the main Pico or
// I2C bus interruptions.  Setting the power limit to 255 effetively
// disables the limiter, since the value can never go above the limit
// value and thus never trigger the timer.
//

// Define as non-zero if USB logging is desired.  This will initialize
// stdio on the USB connection, with the startup connection delay
// defined in CMakeLists.txt to ensure that a terminal is attached
// before we start generating any messages.
#define ENABLE_USB_LOGGING  0
#if ENABLE_USB_LOGGING
#define IF_USB_LOGGING(x) x
#else
#define IF_USB_LOGGING(x)
#endif


// standard library headers
#include <stdio.h>
#include <stdint.h>
#include <string.h>
#include <stdarg.h>
#include <malloc.h>
#include <ctype.h>
#include <math.h>
#include <list>

// Pico SDK headers
#include <pico/stdlib.h>
#include <pico/bootrom.h>
#include <pico/time.h>
#include <hardware/clocks.h>
#include <hardware/gpio.h>
#include <hardware/i2c.h>
#include <hardware/irq.h>
#include <hardware/pwm.h>
#include <hardware/resets.h>
#include <hardware/timer.h>
#include <hardware/watchdog.h>
#include <hardware/sync.h>

// local project headers
#include "i2c_slave.h"
#include "i2c_fifo.h"
#include "PicoLED.h"
#include "Util.h"
#include "Logger.h"
#include "PWMManager.h"
#include "PWMWorker.h"

// ----------------------------------------------------------------------------
//
// Miscellaneous definitions
//

// a Pico clock time that's so far in the future that it's effectively infinity
const uint64_t END_OF_TIME = ~0ULL;

// default PWM frequency (Hz)
static const uint16_t DEFAULT_PWM_FREQ = 20000;

// ----------------------------------------------------------------------------
//
// GPIO configuration
//

// I2C ports
static const int I2C_SDA = 26;
static const int I2C_SCL = 27;
#define I2C_UNIT i2c1    // must match unit associated with the SDA/SCL pins assigned above

// Mapping from nominal LED output number to GPIO port
static uint8_t gpioMap[24]{
    0, 1, 2, 3, 4, 5, 6, 7, 8, 9, 10, 11, 12, 13, 14, 15, 16, 17, 18, 19, 20, 21, 22, 28
};


// ----------------------------------------------------------------------------
//
// I2C slave
//
// The I2C handler does all of its work in the I2C interrupt callback.  The
// only work we do there is to transfer data in and out of the I2C register
// file, which is implemented as a byte array in RAM.  The main thread is
// where all of the real work is carried out: it runs in a continuous loop,
// monitoring the register file for changes, and updating the PWM output ports
// accordingly.  This division of labor allows the I2C handler to service
// requests in real time, which is a requirement of the I2C protocol, since
// the master drives the clock signal.
//

// I2C registers
static uint8_t i2cReg[255];

// register indices
const int REG_LED0 = 0x00;       // level register for LED0 (LED1-LED23 sequentially follow)
const int REG_CTRL0 = 0x18;      // control register 0
const int REG_CTRL1 = 0x19;      // control register 1
const int REG_FREQL = 0x1A;      // PWM frequency, low byte
const int REG_FREQH = 0x1B;      // PWM frequency, high byte
const int REG_VERSION = 0x1E;    // Version identification register (read-only)
const int REG_WHOAMI = 0x1F;     // WHO AM I device identification register (read-only)
const int REG_CONF0_BASE = 0x20; // start of configuration register group for LED0
const int REG_CONFBLK_SIZE = 4;  // size in bytes of LEDn configuration register group
const int REG_CONF_OFS = 0;      // offset of CONF register in LEDn configuration group
const int REG_LIMIT_OFS = 1;     // offset of LIMIT register in LEDn configuration group
const int REG_TIMELIMIT_OFS = 2; // offset of TIMELIMIT register in LEDn configuration group
const int REG_SWRESET = 0xDD;    // software reset

// Identification register values
const uint8_t WHOAMI_ID = 0x24;   // arbitrary value to sanity-check the device type
const uint8_t VERSION_ID = 0x01;  // software version; increment when making I2C interface changes

// Software Reset codes
const uint8_t SWRESET_START = 0x11;  // write to SWRESET register to start a reset sequence
const uint8_t SWRESET_RESET = 0x22;  // write within 1 second of SWRESET_START to execute a CPU reset
const uint8_t SWRESET_BOOTLOADER = 0x33; // write within 1 second of SWRESET_START to execute a Boot Loader mode reset

// Get the port register indices for a given port
static inline int REG_CONF(int port) { return REG_CONF0_BASE + (port * REG_CONFBLK_SIZE); }
static inline int REG_LIMIT(int port) { return REG_CONF(port) + REG_LIMIT_OFS; }
static inline int REG_TIMELIMIT(int port) { return REG_CONF(port) + REG_TIMELIMIT_OFS; }

// REG_CTRL0 - global configuration register bits
const uint8_t CTRL0_ENABLE_OUTPUTS = 0x01;   // enable outputs (ports are in high-impedance state when not enabled)
const uint8_t CTRL0_HWRESET = 0x40;          // hardware reset flag - set to '1' after a power cycle or hard CPU reset
const uint8_t CTRL0_RESET_REGS = 0x80;       // reset registers to default values

// REG_CONF0..CONF23 - port configuration register bits
const uint8_t CONF_ACTIVE_LOW = 0x01;        // active low
const uint8_t CONF_GAMMA_ENA  = 0x02;        // gamma correction enabled

// service callback context
struct ServiceContext
{
    // Read/write register address
    int addr = 0;

    // Write started
    bool writeStarted = false;

    // SWRESET state.  Writes to the SWRESET register are tracked in the
    // interrupt handler to ensure they're processed immediately, since
    // this register requires a multi-byte protocol sequence.
    struct SWReset
    {
        // Current state - this is the last SWRESET_xxx byte the host wrote
        uint8_t state = 0x00;

        // Timeout - system clock time when the state update becomes invalid
        uint64_t timeout = END_OF_TIME;
    };
    SWReset swReset;
};
static volatile ServiceContext serviceContext;
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
int main()
{
    // enable USB logging, if desired
    IF_USB_LOGGING(stdio_usb_init());
    
    // Enable the hardware watchdog, so that we reboot the CPU if we
    // ever stall.  Set a relatively long timeout during initialization.
    watchdog_enable(1000, true);
    watchdog_update();

    // Set up the PWM manager at the default frequency
    PWMManager pwmManager;
    uint16_t freq = DEFAULT_PWM_FREQ;
    pwmManager.SetFreq(freq);

    // start with outputs disabled - the host can enable them via the ENABLE
    // OUTPUTS bit in the CTRL0 register
    bool outputsEnabled = false;

    // Assign the PWM output ports
    for (int i = 0 ; i < _countof(gpioMap) ; ++i)
    {
        // disconnect the input buffer and pull-up/down, to reduce
        // leakage for active-low ports
        int gp = gpioMap[i];
        gpio_set_input_enabled(gp, false);
        gpio_set_pulls(gp, false, false);

        // Set fast slew rate.  Pico GPIOs can only drive small loads
        // directly, so in most cases, outputs will be used as trigger
        // inputs to amplifier circuits.  Many such circuits dissipate
        // the most power during switching transitions between ON and OFF
        // states, so faster transitions are usually better, so minimize
        // switching power losses, and to reduce the risk of damage from
        // overheating.  (The tradeoff is that fast slew can increase EMI
        // emissions when driving light loads, so if that becomes a
        // problem for anyone, we could make this configurable.  At the
        // moment, I don't think it'll be a significant problem given our
        // relatively low PWM frequencies, so I'd rather keep it simple
        // and just make this a fixed setting.)
        gpio_set_slew_rate(gp, GPIO_SLEW_RATE_FAST);

        // Set high drive strength.  This is also for the sake of faster
        // rise/all times on the PWM signal.  Most driver circuits have
        // some input capacitance, so the rise/fall time is limited by
        // the charging time for the input capacitance.  Higher drive
        // strength increases the current that the GPIO can source and
        // sink, which will speed up the charge/discharge cycle on the
        // driver input.
        gpio_set_drive_strength(gp, GPIO_DRIVE_STRENGTH_12MA);

        // initialize PWM on the port
        pwmManager.InitGPIO(gp);
    }

    // set initial I2C register values
    InitRegs();

    // Set the HWRESET bit in CTRL0.  By design, this bit is only set after
    // a hardware reset, not a software register clear command, so that the
    // host can determine if a hardware reset has occurred since it last
    // checked.  InitRegs() is the common handler for hardware resets and
    // software register clear commands, so it doesn't set the bit.  We thus
    // have to set the bit explicitly on this path, which is only traversed
    // during a hardware reset.
    i2cReg[REG_CTRL0] |= CTRL0_HWRESET;
    
    // Get our I2C slave address.  Use a default of 0x30, but allow this to be
    // overridden with data stored at the top of flash space.  We use the top
    // of flash as virtual EEPROM memory, since the Pico loader requires that
    // the user program entrypoint is at the bottom of flash memory, and the
    // Pico SDK linker always arranges the program storage in a contiguous
    // block.  This means that some varying amount of flash starting at the
    // lowest address will be occupied by the user program (PWMWorker), and
    // the rest of flash above that point will be left unchanged each time
    // a new program is installed.  That makes the TOP of flash the safest
    // place to put extra user data, since it's as far away as possible from
    // the unpredictably sized contiguous block that the user program will
    // occupy on each program update.  This program is pretty small, so in
    // practice we could use anything in the top half or even top two-thirds
    // of flash, but we really only need about 40 bytes for the address data,
    // so we'll just put it at the very top and be done with it.
    //
    // To ensure that an address has actually been programmed in the flash
    // data area, we'll look for a distinctive signature string.  If we find
    // the string, we'll take it to mean that an address has been programmed.
    // If not, we'll use the default address.
    static const uint8_t DEFAULT_I2C_ADDR = 0x30;
    uint8_t i2cAddr = DEFAULT_I2C_ADDR;
    const uint32_t TOP_OF_FLASH = 0x10000000 + 2*1024*1024;
    const uint32_t FLASH_SECTOR_SIZE = 4096;
    const char addrSignature[] = "PinscapePicoPWMWorker I2C Addr [";
    const char addrSignatureSuffix[] = "] \032";
    const size_t addrSignatureLen = sizeof(addrSignature) - 1;
    const size_t addrSignatureSuffixLen = sizeof(addrSignatureSuffix) - 1;
    const char *addrDataBlock = reinterpret_cast<const char*>(TOP_OF_FLASH - FLASH_SECTOR_SIZE);
    if (memcmp(addrDataBlock, addrSignature, addrSignatureLen) == 0
        && memcmp(addrDataBlock + addrSignatureLen + 2, addrSignatureSuffix, addrSignatureSuffixLen) == 0)
    {
        // looks good - read the two bytes after the signature prefix as a hex number
        char c1 = addrDataBlock[addrSignatureLen];
        char c2 = addrDataBlock[addrSignatureLen+1];
        static const auto HexToInt = [](char c) {
            return c >= '0' && c <= '9' ? c - '0' :
                c >= 'a' && c <= 'f' ? c - 'a' + 10 :
                c >= 'A' && c <= 'F' ? c - 'A' + 10 : 0;
        };
        i2cAddr = (HexToInt(c1) << 4) | HexToInt(c2);

        Log(LOG_INFO, "I2C slave address configuration found in flash, set to 0x%02X\n", i2cAddr);
    }
    else
    {
        Log(LOG_INFO, "No flash configuration data found; I2C slave address set to default (0x%02X)\n", i2cAddr);
    }

    // Set up I2C on GP26 and GP27
    gpio_init(I2C_SDA);
    gpio_set_function(I2C_SDA, GPIO_FUNC_I2C);

    gpio_init(I2C_SCL);
    gpio_set_function(I2C_SCL, GPIO_FUNC_I2C);

    i2c_init(I2C_UNIT, 400000);
    i2c_slave_init(I2C_UNIT, i2cAddr, &I2CService);

    // Current port settings
    struct Port
    {
        // last setting from I2C register
        uint8_t lastRegLevel = 0;

        // Computed output level, as a fractional duty cycle.  This is the
        // duty cycle after taking into account the power reduction timeout
        // and gamma correction.
        float computedLevel = 0.0f;

        // power level reduction time
        uint64_t tPowerTimeout = END_OF_TIME;

        // reset the port
        void Reset()
        {
            lastRegLevel = 0;
            computedLevel = 0.0f;
            tPowerTimeout = END_OF_TIME;
        }
    };
    Port ports[24];

    // initialization finished - reduce the watchdog timeout
    watchdog_update();
    watchdog_enable(100, true);

    // SWRESET register timer.  To execute a reset, a specific sequence
    // of bytes must be written to SWRESET within a timeout.  This is
    // to ensure that accidental or random writes don't trigger a reset.
    uint64_t swresetTimeout = END_OF_TIME;
    uint8_t swresetState = 0x00;

    // Main loop
    for (;;)
    {
        // let the watchdog know we're running
        watchdog_update();

        // set the blink pattern: "heartbeat" by default, "busy" if an I2C write is in progress
        picoLED.SetBlinkPattern(
            !outputsEnabled ? PicoLED::Pattern::Standby :
            serviceContext.writeStarted ? PicoLED::Pattern::Busy :
            PicoLED::Pattern::Heartbeat);

        // update the status LED
        picoLED.Task();

        // Check for SWRESET events.  If the SWRESET state is one of the reset
        // codes, and we've reached the timeout expiration, it means that the
        // host has completed the SWRESET protocol and it's time to execute
        // the requested reset.
        uint64_t now = time_us_64();
        if (auto &s = serviceContext.swReset; now > s.timeout)
        {
            // check which type of reset was requested
            switch (s.state)
            {
            case SWRESET_RESET:
                // CPU reset requested - reboot by setting the watchdog to a zero timeout
                watchdog_enable(0, false);
                while (true) { }

            case SWRESET_BOOTLOADER:
                // reset to Boot Loader mode requested - reboot through the ROM call,
                // setting the on-board LED as the activity pin
                reset_usb_boot(1 << PICO_DEFAULT_LED_PIN, 0);
                while (true) { }
            }
        }

        // check for a register reset
        if ((i2cReg[REG_CTRL0] & CTRL0_RESET_REGS) != 0)
        {
            // re-initialize registers
            InitRegs();
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

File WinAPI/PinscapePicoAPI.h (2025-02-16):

// Pinscape Pico Device interface
// Copyright 2024 Michael J Roberts / BSD-3-Clause license, 2025 / NO WARRANTY
//
// This module implements an API for interacting with the Pinscape
// Pico device via its USB control interfaces.  The API is designed
// for implementing programs like the Pinscape Pico Config Tool and
// other programs that automate Pinscape device configuration and
// control functions, and for programs (such as DOF) that access
// the Feedback Controller features.
//
// The Pinscape Pico device exposes several USB interfaces.  This
// API provides access to two of them:
//
// - A WinUsb vendor interface, which provides the Configuration
//   and Control functions.  This interface is designed for the
//   Pinscape Config Tool, and for any other applications that
//   need to configure the device.
// 
//   WinUsb is a native Windows device driver, so this interface
//   doesn't require the user to install any drivers; just plug
//   in the device and Windows will recognize this interface and
//   make it available to applications.  WinUsb by design only
//   allows one application to access the interface at a time,
//   which shouldn't be a hardship for Config Tool-like programs.
//   (WinUsb access doesn't lock out access to any of the OTHER
//   USB interfaces that the device exposes, so running the
//   Config Tool won't block DOF from accessing the device.)
// 
//   The vendor interface API also provides helpers for discovery
//   of Pico devices in their native "Boot Loader" mode, in which
//   the Pico emulates a USB thumb drive for the purpose of
//   installing new firmware into the Pico's flash memory.
//
//   See PinscapeVendorInterface.h for this interface.
// 
// - A Feedback Controller interface, which provides application
//   access to the feedback devices (lights, solenoids, etc)
//   attached to the Pinscape Pico's output ports.  This interface
//   is designed for use by DOF and other programs that generate
//   feedback effects.
// 
//   The Feedback Controller is a HID interface, which makes it
//   driverless and shareable (multiple applications can access
//   it concurrently).  That's why it's a separate interface
//   from the Configuration and Control interface.  The DOF-type
//   functions of the Feedback Controller interface are for use
//   by games and other UI-oriented programs, and the user is
//   likely to run more than one at a time, either because one
//   program launches another (e.g., PinballY launching VP),
//   or because the programs are taking turns in the foreground.
//   Allowing concurrent access to the DOF-type functions avoids
//   conflicts that can be difficult for users to troubleshoot.
// 
//   See FeedbackControllerInterface.h for this interface.
// 

#pragma once

#include <stdlib.h>
#include <string.h>
#include <tchar.h>
#include <memory>
#include <functional>
#include <list>
#include <string>
#include <Windows.h>
#include <winusb.h>
#include <usb.h>
#include "../USBProtocol/VendorIfcProtocol.h"
#include "../USBProtocol/FeedbackControllerProtocol.h"

// Short-hand names for the PinscapePico types
using PinscapeRequest = PinscapePico::VendorRequest;
using PinscapeResponse = PinscapePico::VendorResponse;
using FeedbackRequest = PinscapePico::FeedbackControllerRequest;
using FeedbackReport = PinscapePico::FeedbackControllerReport;
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

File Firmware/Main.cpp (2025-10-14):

// Pinscape Pico - Main program entrypoint and main loop
// Copyright 2024, 2025 Michael J Roberts / BSD-3-Clause license / NO WARRANTY
//

// standard library headers
#include <stdio.h>
#include <stdint.h>
#include <string.h>
#include <stdarg.h>
#include <malloc.h>
#include <ctype.h>
#include <math.h>
#include <list>

// Pico SDK headers
#include <pico/stdlib.h>
#include <pico/bootrom.h>
#include <pico/multicore.h>
#include <pico/time.h>
#include <pico/flash.h>
#include <pico/unique_id.h>
#include <hardware/gpio.h>
#include <hardware/irq.h>
#include <hardware/uart.h>
#include <hardware/timer.h>
#include <hardware/watchdog.h>
#include <device/usbd_pvt.h>
#include <hardware/structs/usb.h>
#include <hardware/structs/usb_dpram.h>

// local project headers
#include "Pinscape.h"
#include "PicoBoardType.h"
#include "Main.h"
#include "MultiCore.h"
#include "FaultHandler.h"
#include "Utils.h"
#include "Config.h"
#include "FlashStorage.h"
#include "USBIfc.h"
#include "VendorIfc.h"
#include "Version.h"
#include "Logger.h"
#include "CommandConsole.h"
#include "Buttons.h"
#include "Outputs.h"
#include "Nudge.h"
#include "Accel.h"
#include "NightMode.h"
#include "crc32.h"
#include "Watchdog.h"
#include "PicoLED.h"
#include "StatusRGB.h"
#include "VendorIfc.h"
#include "Reset.h"
#include "I2C.h"
#include "SPI.h"
#include "PIOHelper.h"
#include "PWMManager.h"
#include "ADCManager.h"
#include "TimeOfDay.h"
#include "TVON.h"
#include "ExpansionBoard.h"
#include "Plunger/Plunger.h"
#include "Plunger/ZBLaunch.h"
#include "IRRemote/IRTransmitter.h"
#include "IRRemote/IRReceiver.h"
#include "Devices/Accel/LIS3DH.h"
#include "Devices/Accel/LIS3DSH.h"
#include "Devices/Accel/MC3416.h"
#include "Devices/Accel/MMA8451Q.h"
#include "Devices/Accel/MXC6655XA.h"
#include "Devices/DistanceSensor/VL6180X.h"
#include "Devices/GPIOExt/PCA9555.h"
#include "Devices/LinearPhotoSensor/TCD1103.h"
#include "Devices/LinearPhotoSensor/TSL1410R.h"
#include "Devices/ProxSensor/VCNL4010.h"
#include "Devices/PWM/PWMWorker.h"
#include "Devices/PWM/TLC59116.h"
#include "Devices/PWM/PCA9685.h"
#include "Devices/PWM/TLC5940.h"
#include "Devices/PWM/TLC5947.h"
#include "Devices/Quadrature/AEDR8300.h"
#include "Devices/RTC/DS1307.h"
#include "Devices/RTC/DS3231M.h"
#include "Devices/RTC/RV3032C7.h"
#include "Devices/ShiftReg/74HC595.h"
#include "Devices/ShiftReg/74HC165.h"


// Unit identifiers singleton
UnitID unitID;

// Main loop statistics
CoreMainLoopStats mainLoopStats;
volatile CoreMainLoopStats secondCoreLoopStats;
volatile bool secondCoreLoopStatsResetRequested = false;

// startup boot mode
PicoReset::BootMode lastBootMode = PicoReset::BootMode::Unknown;

// Debug/test variables
DebugAndTestVars G_debugAndTestVars;

// Forwards
static void SecondCoreMain();
static void MainLoop();
static void Configure(PicoReset::BootMode bootMode);
static void Command_memory(const ConsoleCommandContext *c);
static void Command_loopstats(const ConsoleCommandContext *c);
static void Command_reset(const ConsoleCommandContext *ctx);
static void Command_version(const ConsoleCommandContext *ctx);
static void Command_whoami(const ConsoleCommandContext *ctx);
static void Command_devtest(const ConsoleCommandContext *ctx);
static void Command_crashlog(const ConsoleCommandContext *ctx);

// ---------------------------------------------------------------------------
// 
// Main program entrypoint.  This is where the primary core starts running
// after power-on or a soft reboot.
//
int main()
{
    // Initialize the fault handler
    faultHandler.Init();

    // Intialize the main logger
    logger.Init();

    // Add a startup banner at the top of the logger, with a couple of
    // blank lines for separation from previous material in the same window.
    // Turn off all of the decorations for this, so that it stands out.
    logger.SetDisplayModes(false, false, false);
    Log(LOG_INFO, "\n\n"
        "===========================================\n"
        "PinscapePico v%d.%d.%d, build %s\n"
        "\n",
        VERSION_MAJOR, VERSION_MINOR, VERSION_PATCH, buildTimestamp);

    // enable logger timestamps and type codes by default
    logger.SetDisplayModes(true, true, false);

    // restore the time-of-day information stashed before the reset, if possible
    timeOfDay.RestoreAfterReset();

    // perform additional target board initialization
    PicoBoardType::Init();

    // Check for a watchdog reboot.  This indicates that the software
    // crashed or froze, and the watchdog intervened by resetting the
    // Pico.  We use the watchdog scratch registers to store our status
    // at the time of the crash so that we can take corrective action.
    lastBootMode = picoReset.GetBootMode();
    bool unexpectedReset = false;
    if (watchdog_caused_reboot()
        && (lastBootMode == PicoReset::BootMode::SafeMode || lastBootMode == PicoReset::BootMode::FactoryMode))
    {
        unexpectedReset = true;
        Log(LOG_INFO, "*** %s Mode engaged (due to exception, watchdog timeout, or by user request) ***\n",
            lastBootMode == PicoReset::BootMode::SafeMode ? "Safe" : "Factory");
    }

    // Check for recorded crash data from before the reset.  If a
    // crash frame was recorded, this will log it and clear the frame
    // (so that we don't repeat it on the next reset, if no new crash
    // occurs).  If no crash was recorded, this does nothing.  Note
    // that we'll usually be in safe mode after a crash occurs, but
    // there's no harm in logging the crash data unconditionally, so
    // that we catch any unexpected cases where safe mode isn't
    // triggered.
    faultHandler.LogCrashData();

    // If we have crash data, or we're in safe mode, log the prior
    // session log tail
    if (unexpectedReset || faultHandler.IsCrashLogValid())
        logger.LogPriorSessionLog(LOG_INFO);

    // add our console commands
    CommandConsole::AddCommand(
        "loopstats", "show main loop timing statistics",
        "loopstats [options]\n"
        "options:\n"
        "  -l, --list     list statistics (default if no options specified)\n"
        "  -r, --reset    reset the statistics counters",
        Command_loopstats);

    CommandConsole::AddCommand(
        "mem", "show memory usage statistics", "mem  (no options)\n",
        Command_memory);

    CommandConsole::AddCommand(
        "reboot", "hardware-reset the Pico",
        "reboot [mode]\n"
        "  -r, --reset      reset the Pico and restart the Pinscape firmware program\n"
        "  -s, --safe-mode  reset the Pico and restart Pinscape in Safe Mode\n"
        "  -f, --factory    reset the Pico and restart with no config files loaded (factory settings)\n"
        "                   (note: doesn't delete anything; just skips loading settings after reset)\n"
        "  -b, --bootsel    launch the Pico ROM Boot Loader, for installing new firmware",
        Command_reset);
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

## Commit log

2025-01-05 bug fixes
    [Pinscape Pico - Pro (SMD) Expansion Board.brd, Pinscape Pico - Pro (SMD) Expansion Board.sch, Pinscape Pico-KL25Z Adapter.brd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]
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2025-01-11 fix TinyUSB 0.17.0 regression (vendord_reset error; broken USB connection on sleep/resume)
    [Main.cpp, PinscapeVendorInterface.h]
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2025-01-26 Finish JSON configuration for 74HC165, tweaks to 74HC165 layout
    [PinscapePico KL25Z Adapter - 74HC165 vsn.brd, PinscapePico KL25Z Adapter - 74HC165 vsn.sch]
2025-01-27 Update Pro expansion board to use 74HC165 for all button inputs
    [Pinscape Pico - Pro (SMD) Expansion Board.brd, Pinscape Pico - Pro (SMD) Expansion Board.sch]
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2025-01-30 Remove pull-up to primary Pico 3V3 on aux Pico reset
    [Pinscape Pico Expansion Board - DIY Friendly Main.brd, Pinscape Pico Expansion Board - DIY Friendly Main.sch]
2025-01-31 DIY board: individual reset buttons per Pico; swap cross-board connectors
    [Pinscape Pico Expansion Board - DIY Friendly Main.brd, Pinscape Pico Expansion Board - DIY Friendly Main.sch, Pinscape Pico Expansion Board - DIY Friendly Powe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]
2025-02-01 THT version of the board design
    - Changed Pico footprint to THT
    - Relocated components
    - Relayouted traces.
    [PinscapePico KL25Z Adapter - 74HC165 vsn.brd]
2025-02-01 fix lis3dh address in exp board config templates; CDC IN stall detection updates
    [Logger.cpp]
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2025-02-02 ads1115 channel parsing fix; add ads1115 analog-in wiring diagram examples to config doc
    [JSONConfigRef.txt]
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2025-02-06 Add connector board plan for Button Latency Tester II
    [ButtonLatencyTester2.brd, ButtonLatencyTester2.sch]
2025-02-07 add tlc59116 wiring diagram to json doc; change Pro board IRED to constant-current circuit
    [JSONConfigRef.txt, Pinscape Pico - Pro (SMD) Expansion Board.brd, Pinscape Pico - Pro (SMD) Expansion Board.sch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]
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2025-02-10 Update Pro and KL25Z adapter boards to make LIS3DH footprint compatible with LIS3DSH
    [Pinscape Pico - Pro (SMD) Expansion Board.brd, Pinscape Pico - Pro (SMD) Expansion Board.sch, PinscapePico KL25Z Adapter - 74HC165 vsn.brd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]
2025-02-11 add weekday and date ranges to time() output data source
    [JSONConfigRef.txt]
2025-02-11 fix 12-bit output device scaling error
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2025-02-13 fix crash when I2Cn is enabled with zero devices configured on bus
    [I2C.cpp]
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2025-02-13 Fix 'address' typo in kl25z board config template (#16)
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2025-02-18 Fix 74HC165 display layout in GUIConfigTool button tester
2025-02-19 74hc165 diagnostics (bitbang scan, DMA-once scan); fix wrong dreq trigger
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2025-02-25 PCB parts lists (BOMs); power distro board edits
    [Pinscape Pico - Pro (SMD) Expansion Board.sch, Pinscape Pico Expansion Board - DIY Friendly Main - BOM.csv, Pinscape Pico Expansion Board - DIY Friendly Main.b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]
2025-02-25 add parts list (BOM) for Button Latency Tester II board
    [ButtonLatencyTester2 - BOM.csv]
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2025-02-26 add flasher panel BOM, fix Red channel resistor value
    [FlasherPanel-BOM.csv]
2025-02-28 hard fault logging, preserve tail end of log across reset
    [CommandConsole.cpp, Logger.cpp, Main.cpp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]
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2025-03-05 bounds-check cross-reset time of date record before restoring
    [Main.cpp]
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2025-03-07 fix Open Pinball Device 'right flipper'/'left flipper 2' reversal
    [Buttons.cpp, PinscapeVersion.h]
2025-03-08 Open Pinball Device doc: add illustration for flipper switch layout
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2025-03-14 exp board: DIY-friendly main: BOM correction
    [Pinscape Pico Expansion Board - DIY Friendly Main - BOM.csv]
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2025-03-14 exp board: IR RX: BOM correction
    [Pinscape Pico IR-Receiver BOM.csv]
2025-03-14 exp board: DIY power: change battery holder to snap-in type
    [Pinscape Pico Expansion Board - DIY Friendly Power - BOM.csv, Pinscape Pico Expansion Board - DIY Friendly Power.brd, Pinscape Pico Expansion Board - DIY Frien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]
2025-03-14 exp board: pro: change battery holder to top clip type
    [Pinscape Pico - Pro (SMD) Expansion Board.brd, Pinscape Pico - Pro (SMD) Expansion Board.sch]
2025-03-17 exp board: diy power: include old and new battery holders in BOM
    [Pinscape Pico Expansion Board - DIY Friendly Power - BOM.csv]
2025-03-17 exp boards: power dist: add MicroFit+ crimp pins to BOM
    [Power Distribution Board - BOM.csv]
2025-03-19 exp board: flasher panel: correct BOM line item for IDC housing
    [FlasherPanel-BOM.csv]
2025-03-19 exp board: DIY main: correct BOM line item for 3P pin strip
    [Pinscape Pico Expansion Board - DIY Friendly Main - BOM.csv]
2025-03-22 Exp board: flasher panel: Correct 2R/2G reversal, R13-14-15 placement, add resistor values to silkscreen
2025-03-22 exp board: flasher panel: add Amazon ASINs for equivalent LEDs
    [FlasherPanel-BOM.csv]
2025-03-22 exp board: power distro: remove stray silkscreen text
    [Power Distribution Board.brd]
2025-03-22 exp board: power distro: BOM correction
    [Power Distribution Board - BOM.csv]
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2025-03-23 button latency tester 2: add pin-1 dot to pc817 footprint on silkscreen
    [ButtonLatencyTester2.brd, ButtonLatencyTester2.sch]
2025-03-25 fix i2cX command crash when bus is configured but not enabled
    [I2C.cpp]
2025-03-25 fix UART GP initialization
    [Logger.cpp]
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2025-03-25 config tool: fix keyboard status refresh in button tester window on app bg/fg switching
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2025-03-26 exp board: DIY main: move main Pico reset switch to a more accessible spot
    [Pinscape Pico Expansion Board - DIY Friendly Main.brd]
2025-03-26 exp board: power: change RTC power source to main Pico bus power
    [Pinscape Pico Expansion Board - DIY Friendly Power.brd, Pinscape Pico Expansion Board - DIY Friendly Power.sch]
2025-03-26 exp boards: flasher panel: add orientation markers to header to match DIY main board markings
    [FlasherPanel-BOM.csv]
2025-03-26 fix UART logger config message
    [Logger.cpp]
2025-03-26 exp board: DIY: add errata to readme; reorient main board Flasher header silkscreen markings to match KL25Z expansion boards
    [Pinscape Pico Expansion Board - DIY Friendly Main.brd, Pinscape Pico Expansion Board - DIY Friendly Main.sch]
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2025-03-26 exp board: DIY main: change recommended IR LED to new part in BOM
    [Pinscape Pico Expansion Board - DIY Friendly Main - BOM.csv]
2025-03-27 exp board: DIY power: add guard ring and isolated ground plane under DS1307 crystal per App Note 58
    [Pinscape Pico Expansion Board - DIY Friendly Main.brd, Pinscape Pico Expansion Board - DIY Friendly Main.sch, Pinscape Pico Expansion Board - DIY Friendly Powe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]
2025-03-27 fix error in config template for DIY board
2025-03-27 Fix error in pwm device command parsing
    [CommandConsole.cpp]
2025-03-27 fix CountPorts counting error in several devices
    [JSONConfigRef.txt]
2025-03-30 exp board: power distribution: 24-pin ATX connector, 48V interlock via MOSFET, Always On jumper options
    [Pinscape Pico Expansion Board - DIY Friendly Main.brd, Pinscape Pico Expansion Board - DIY Friendly Main.sch, Power Distribution Board - BOM.csv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]
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2025-04-03 button macros: add duration:'hold'; button key actions: add chords (Ctrl+Shift+X, internally converted to macro)
    [JSONConfigRef.txt]
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2025-04-07 add 'Pico Reboot' initial state for TV ON, remove button-style debouncing on inputs
    [Buttons.cpp]
2025-04-08 clean up a couple of missing documentation/file items for first-time builds on a new system
2025-04-08 improve log messages about missing I2C settings
    [I2C.cpp, I2C.h, PWMWorker.cpp]
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2025-04-09 fix I2C START/STOP condition sequencing in bus-clear operation (caused problems for LIS3DH)
    [I2C.cpp]
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2025-04-20 config tool: avoid listing a device that only connects long enough to enumerate (but not long enough to retrieve IDs)
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2025-04-23 exp board: power distro BOM correctin
    [Power Distribution Board - BOM.csv]
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2025-04-30 exp board: diy main: fix via clearance
    [Pinscape Pico Expansion Board - DIY Friendly Main.brd]
2025-05-02 exp board: DIY main: BOM correction
    [Pinscape Pico Expansion Board - DIY Friendly Main - BOM.csv]
2025-05-25 Exp board: DIY main: improve reference designator ordering, fix bypass cap proximities to shift register chips, silkscreen cleanup
    [Pinscape Pico Expansion Board - DIY Friendly Main - BOM.csv, Pinscape Pico Expansion Board - DIY Friendly Main.brd, Pinscape Pico Expansion Board - DIY Friendl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]
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2025-06-04 add short-press action for hold buttons
    [JSONConfigRef.txt]
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2025-06-21 exp boards: diy: add workaround photos for errata
    [JSONConfigRef.txt]
2025-06-21 exp board: DIY main: fix C7/C8 reversal
    [Pinscape Pico Expansion Board - DIY Friendly Main.brd]
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2025-06-26 share group bug fixes: single-member group not working, device not releasing port properly on end event (issue #32)
2025-07-01 shared output devices: multiple share groups per device and per DOF port, pulsed ports; MMA8451Q setup notes
    [JSONConfigRef.txt]
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2025-07-06 change config tool dev overview pin color coding to better match Pico SDK diagrams; add coding for ADC usage
    [JSONConfigRef.txt]
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2025-08-08 MMA8415Q: fix parsing for poll mode (no 'interrupt:' entry)
2025-08-09 LIS3DH JSON fix; doc edits
    [JSONConfigRef.txt]
2025-08-14 exp board: Pro: change ULN2803ADWR to -CDWR (-ADWR is EOL, replacement is -CDWR)
    [Pinscape Pico - Pro (SMD) Expansion Board.brd, Pinscape Pico - Pro (SMD) Expansion Board.sch]
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2025-08-17 fix JSON config ref typo
    [JSONConfigRef.txt]
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2025-08-29 mma8451q: add WHO_AM_I recognition for mma8452q (which seems to function correctly with existing driver)
2025-09-07 fix button shortPress.action configuration setup
    [Buttons.cpp]
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2025-09-11 fix command-line config tool IR TX (--ir-send); fix Pico crash sending IR command when IR TX not configured
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2025-09-17 fix shared port pulse timing bug (#69); more C-like int/float type promotions in algebraic output source expressions
    [JSONConfigRef.txt]
2025-09-23 fix initial state for toggle buttons when underlying soruce is active-low (discussion #71)
    [Buttons.cpp]
2025-10-11 Fix .pio assembly under UNIX
2025-10-11 Fix VL6180X.h include for case-sensitive OS
    [Main.cpp, Plunger.cpp]
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2025-10-14 button type:'reset' action: add Safe and Factory mode options
    [JSONConfigRef.txt]
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2025-10-19 Fix markdown link formatting
    Round brackets were used for square and vice versa in this incorrectly formatted link.
    P.S. Your work is *incredible*.
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2025-11-29 JSON config ref correction (#88)
    [JSONConfigRef.txt]
2025-12-07 exp board BOMs: change to original manufacturer part numbers for a few parts that were listed under Mouser part no's
    [Pinscape Pico Expansion Board - DIY Friendly Main - BOM.csv, Pinscape Pico Expansion Board - DIY Friendly Power - BOM.csv]
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2025-12-10 exp board BOM: fix quantities for MTA-xxx keying plugs to reflect 10-pack packaging
    [Pinscape Pico Expansion Board - DIY Friendly Main - BOM.csv]
2025-12-17 exp boards: DIY-friendly main: add button header pin labels; add button header pin label diagram to readme
    [Pinscape Pico Expansion Board - DIY Friendly Main.brd, Pinscape Pico Expansion Board - DIY Friendly Main.sch]
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2026-01-21 fix 'chain' error check in 74hc165 button setup
    [Buttons.cpp]
2026-01-30 fix error message string template in PWMWorker
    [PWMWorker.cpp]
2026-01-30 add grave/tilde key cap names (USB usage 0x35) to type=key button action list
    [JSONConfigRef.txt]
2026-01-31 KL25Z adapter board JSON corrections
    [PWMWorker.cpp]
2026-02-01 Power Distro board BOM: add missing 24V/48V SMPS connectors (J18, J19)
    [Pinscape Pico Expansion Board - DIY Friendly Main.brd, Power Distribution Board - BOM.csv]
2026-02-07 Exp Boards: KL25Z adapter: JSON config: set 74HC595 /ENA port to inverted logic (output is inverted in hardware on Pinscape KL25Z expansion board)
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2026-03-16 DIY expansion board config template: fix old comment about PCA9555 button inputs (issue #100)
2026-03-16 Fix output port description in DIYExpansionBoard.json (#99)
    The comments prior to the output section mention 8 Darlington lamp ports and 16 TLC59116F small LED ports. The latter does not exist and there are 32 of the former (nice!). The actual json content is correct.
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2026-04-29 Fix logging message in PWMWorker
    [PWMWorker.cpp]
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2026-04-29 Fix menu enabling status for a couple of extra device commands when device isn't present
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2026-04-30 Add optional MacOS-compatible usage for feedback controller HID, using vendor usage page space
    [JSONConfigRef.txt]
2026-05-01 fix build error (board type set wrong in uf2 generator)
2026-10-05 Add another (hopefully more permanent) workaround for the well-known Pico SDK bug with the pioasm tool build
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2026-11-02 Fix MMA8451Q crash when configuration disables interrupts
2026-11-09 Add MPU-6050 accelerometer support
    New driver for the InvenSense MPU-6050 (common GY-521 breakout boards),
    configured with an "mpu6050" section: i2c bus, addr 0x68/0x69 (default
    0x68), optional interrupt GPIO, gRange 2/4/8/16.
    - Accelerometer only (gyro unused), 1 kHz sample rate with the DLPF at
    184 Hz; the 16-bit samples need no rescaling for the nudge system
    - INT pin set up as active-low, open-drain and latched, cleared by
    reading INT_STATUS with each sample; polls the chip when INT isn't wired
    - Waits the full 100 ms after the device reset, then wakes the chip and
    reads PWR_MGMT_1 back to confirm (the reset bit clears early, and a
    wake-up write sent right away was lost, leaving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

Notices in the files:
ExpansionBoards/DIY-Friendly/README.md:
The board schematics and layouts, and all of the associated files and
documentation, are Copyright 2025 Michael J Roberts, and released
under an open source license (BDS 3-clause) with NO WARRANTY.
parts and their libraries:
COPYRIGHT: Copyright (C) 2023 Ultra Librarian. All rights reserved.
